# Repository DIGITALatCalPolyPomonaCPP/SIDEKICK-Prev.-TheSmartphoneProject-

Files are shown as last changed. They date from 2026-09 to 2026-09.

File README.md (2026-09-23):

# SIDEKICK — The Smartphone Project

**SIDEKICK, previously named TheSmartphoneProject, is DIGITAL @ Cal Poly Pomona's flagship systems-engineering project: a student-designed modular smartphone built around an FPGA-based computing platform.** It treats the phone as one integrated product spanning programmable logic, circuit design, embedded software, operating systems, sensing, user interaction, mechanical design, and thermal engineering.

<p align="center">
  <a href="https://photos.app.goo.gl/fKSVxjnxUvrLaF7E6">
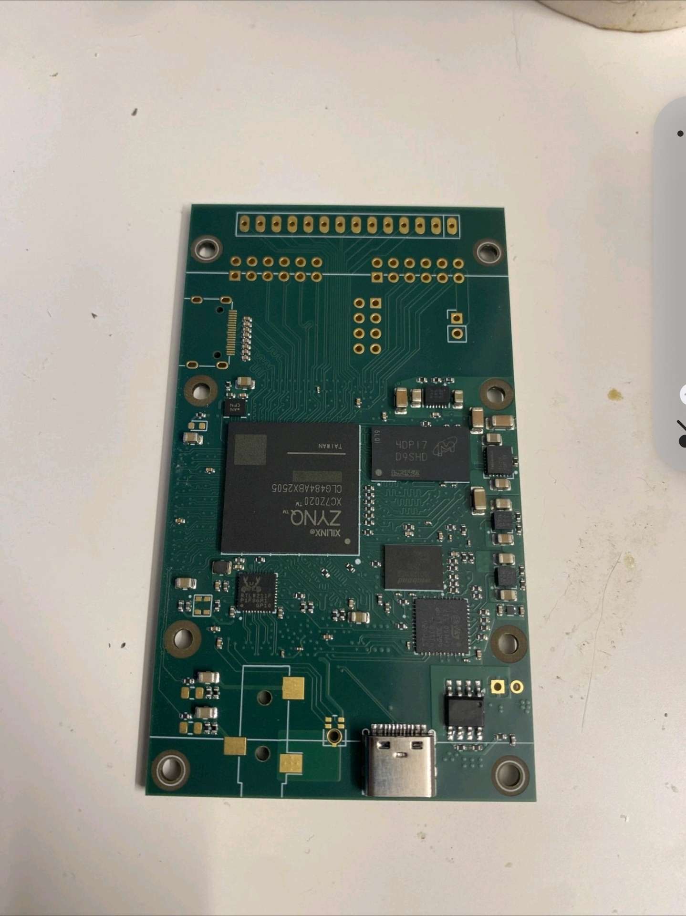
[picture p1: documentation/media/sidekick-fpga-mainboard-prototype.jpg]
SIDEKICK FPGA smartphone mainboard prototype
    
  </a>
</p>

<p align="center"><em>FPGA smartphone mainboard prototype. <a href="https://photos.app.goo.gl/fKSVxjnxUvrLaF7E6">View the project photo album.</a></em></p>

**Repository status:** This is an archival engineering snapshot. It consolidates original design files, subsystem iterations, planning documents, curricula, and project updates that were previously distributed across multiple repositories and contributor archives. It does not claim that every subsystem reached production readiness or that the files currently assemble into a finished phone.

## Executive summary

Technology has always evolved. What has changed is the pace at which innovation reshapes the world around us. Entire industries can now emerge, mature, and reinvent themselves within the span of a student's undergraduate education. Artificial intelligence is reshaping knowledge-based work, robotics is moving from laboratories into homes and industry, and manufacturing is becoming increasingly autonomous.

**The technologies that will define our students' careers have not all been invented yet.**

Industry has responded by becoming increasingly interdisciplinary. The products that define modern society are rarely conceived, developed, or delivered through engineering alone. They emerge from engineering, business, operations, manufacturing, research, and design working toward a common objective.

DIGITAL @ Cal Poly Pomona was created in response to this shift. It does not replace traditional engineering education or the student organizations that apply it through competitions, research, and hands-on work. DIGITAL bridges the space between them by organizing around the process through which ideas become projects. Members investigate unfamiliar problems, research existing solutions, define requirements, evaluate trade-offs, establish scope, build prototypes, test assumptions, document decisions, and communicate across disciplines.

Few products demonstrate the importance of this process more clearly than the smartphone. Its significance comes not simply from replacing the telephone, but from integrating computing, communications, embedded systems, software, industrial design, manufacturing, supply-chain logistics, product management, and business strategy at global scale. SIDEKICK turns that integration challenge into an educational platform: students can specialize in one subsystem while learning how their decisions affect the complete product.

The projects will change. The technologies will change. What remains constant is the framework through which students learn to transform ideas into reality. Ultimately, the true product of DIGITAL is not the prototype; it is the people who leave the organization prepared to help define what comes next.

## Project definition

The project aims to engineer a working, custom-built mobile-device prototype whose central processing and hardware-control functions are implemented with field-programmable logic. Inspired by modern mobile architecture and open-source hardware, the team uses tools including KiCad, SolidWorks, ANSYS, AMD Vivado, and OrCAD to expose parts of the system that are normally hidden inside closed silicon and proprietary product stacks.

The intended phone should be comfortable to hold, intuitive to navigate, responsive under real use, and efficient enough for sustained daily operation. Success is therefore broader than a booting circuit board: the project pairs user evaluation of ergonomics, navigation, and responsiveness with engineering measurements such as clock speed, bus bandwidth, screen-on time, battery discharge, component efficiency, data integrity, latency, and thermal behavior.

As an educational platform, the phone gives students a way to follow a complete system from physical circuits and programmable logic through hardware interfaces, drivers, the operating system, and the user experience. The objective is not only a device, but a reusable foundation for learning, experimentation, repairability, and later product iterations.

## Planned operational architecture

The system concept separates the FPGA motherboard from modular peripheral hardware. Custom logic moves device data through controller and buffering stages into an AXI-based system fabric, where software drivers expose it to the operating system and user interface.

```mermaid
flowchart LR
    A[Peripheral daughterboard<br/>sensors and actuators] --> B[Custom SPI and GPIO logic]
    B --> C[Hardware FIFO buffers]
    C --> D[AXI interconnect and<br/>memory-mapped registers]
    E[FPGA processing core<br/>and programmable logic] --> B
    E --> D
    D --> F[OS kernel and drivers]
    F --> G[Touch UI, telemetry,<br/>audio and haptic feedback]
```

Representative system flows include:

- **Boot and biometric unlock:** power-rail bring-up, FPGA bitstream loading, kernel and driver initialization, fingerprint transfer, authentication, haptic confirmation, and UI unlock.
- **Continuous sensor telemetry:** IMU, temperature, ambient-light, and microphone sampling; serial-to-parallel conversion; cross-clock FIFO buffering; AXI transfer; and UI updates.

The current systems plan treats a peripheral-to-memory latency below 15 ms, lossless sensor-packet handling at the target sampling load, and passive heat routing away from user touchpoints as design requirements. These are project targets documented in the planning workspace, not certifications of the archived hardware.

## Development approach

The project follows a systems-engineering cycle:

1. define the product, user experience, and measurable requirements;
2. decompose the phone into coordinated electrical, computing, software, mechanical, and thermal workstreams;
3. select components and tools, establish interfaces, and procure hardware;
4. design and prototype subsystems independently;
5. integrate through defined buses, connectors, drivers, and mechanical boundaries;
6. test electrical, performance, power, thermal, usability, and integration risks; and
7. evaluate readiness, document results, and carry lessons into the next iteration.

The public [TheSmartphoneProject workspace](https://successful-twill-84f.notion.site/TheSmartphoneProject-3e3169473d7780c18205ee25701566bf) contains the living planning record, including the product definition, requirements, work breakdown, use-case material, sequence diagrams, activity diagrams, team plans, and subsystem task tracking. Some linked workspace records may have separate access controls.

## System overview

| Subsystem | Scope | Contents |
| --- | --- | --- |
| [FPGA main board and peripheral board](subsystems/fpga-mainboard/) | Central Zynq/FPGA architecture, power, RF/transceiver, USB, connectors, display peripheral board | KiCad source, fabrication outputs, 3D renders, manufacturing notes |
| [Haptics](subsystems/haptics/) | Tactile-feedback motor-driver board | KiCad project archive |
| [Fingerprint sensor](subsystems/fingerprint-sensor/) | Fingerprint-sensor interface board | KiCad project archive |
| [Flashlight](subsystems/flashlight/) | LM3644-based flashlight/LED driver | KiCad revisions and symbol/footprint library |
| [Mechanical and thermal](subsystems/mechanical-thermal/) | Phone enclosure, frame, assembly, and thermal/mechanical exploration | STEP, STL, SolidWorks, PDF, and archived CAD models |
| [Ambient-light sensor](subsystems/ambient-light-sensor/) | VCNL4030X01-based sensing board and additional light-sensor iterations | KiCad project archives and STEP model |
| [IMU](subsystems/imu/) | ICM-20948 inertial-sensing board and supporting power/level shifting | Seven chronological KiCad project archives |
| [Real-time clock](subsystems/real-time-clock/) | RV-3028-C8-based RTC board | KiCad source, component library, renders, schematics, and prototype outputs |
| [STM32 controller](subsystems/stm32-controller/) | STM32G431-based control and support electronics | KiCad design, component models/libraries, and STM32CubeIDE firmware project |
| [Heat sensor](subsystems/heat-sensor/) | Temperature/heat-sensing circuit exploration | KiCad schematic project archive |

## Project documentation

The [`documentation/`](documentation/) directory preserves the project record alongside the subsystem engineering files. It includes Hatchery proposals and phase updates, DIGITAL curriculum and mini-project decks, the project budget and bill-of-materials workbook, and organizational records. These originals are grouped by purpose and accompanied by checksums and provenance notes.

## Repository organization

Each subsystem has:

- a short README explaining what is present;
- a `PROVENANCE.md` with the original repository, branch, imported commit, and contributors; and
- a `source/` directory containing an unchanged snapshot of the files tracked at that commit.

The snapshots intentionally retain original filenames, archive structure, and intermediate revisions. This avoids silently selecting a “final” design where the source repository did not designate one.

## Opening the design files

Most electronics work is stored as KiCad projects, either directly or inside ZIP archives. Mechanical work includes STEP, STL, SolidWorks (`.SLDPRT`), and PDF files. Some archives contain KiCad automatic backups in addition to the latest project files.

Treat all outputs as historical engineering artifacts. Review schematics, footprints, stackups, component availability, electrical rules, and manufacturing requirements before fabrication.

## Project history and attribution

The initial source material was maintained across seven repositories under individual contributors and the DIGITAL organization. Additional project archives supplied directly by the project maintainer are recorded separately, without inferring authorship or repository history. See [CONTRIBUTORS.md](CONTRIBUTORS.md) for the contributor index and each subsystem's `PROVENANCE.md` for source details.

No authorship is transferred by this consolidation. Original Git history remains available through the linked source repositories and the immutable commit identifiers recorded here.

## Licensing

Licensing is **per subsystem**, not repository-wide. The FPGA/main-board snapshot includes its original GNU GPL v3 license. No explicit license file was present in the other source repositories at the recorded commits. See [LICENSES.md](LICENSES.md) before reusing or redistributing any material.

## About DIGITAL @ Cal Poly Pomona

DIGITAL is intentionally broader than one device, competition, technology, or discipline. Each initiative follows a shared project lifecycle: assess purpose and feasibility; define scope, requirements, risks, roles, and resources; execute and integrate through clear interfaces; document decisions continuously; and conclude with reflection, knowledge transfer, and a deliberate decision about what follows.

Systems engineering is the organization's foundation. It connects the complete product architecture with the technical and operational teams needed to deliver it, while allowing members to develop depth in hardware, software, mechanical design, thermal engineering, product design, business, or operations. SIDEKICK is DIGITAL's flagship reference implementation—not its fixed endpoint—and provides a concrete system through which this model can be tested and improved.

DIGITAL measures success beyond commercial readiness. Clear design decisions, robust interfaces, useful documentation, transferable skills, and member growth are outcomes in their own right. Read the archived [DIGITAL project proposal for Maximizing Engineering Potential](documentation/organization/DIGITAL_CPP_Project_Proposal_MEP.docx) for the organization's mission, values, project lifecycle, and structure.

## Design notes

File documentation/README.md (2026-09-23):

# Project documentation

This directory preserves original planning, teaching, financial, and organizational records supplied by project maintainer Russell Chung. The files are stored unchanged; descriptions below are an index, not a revision of the source material.

| Collection | Contents |
| --- | --- |
| [Proposals](proposals/) | Phase I interview/application notes and the 13-page Learn Through Discovery Projects Hatchery proposal |
| [Project updates](project-updates/) | Phase II planning and budget presentation; Phase III hardware and thermals/enclosure updates |
| [Curriculum and mini-projects](curriculum/) | Operating-systems and SoC teaching decks; thermometer and fingerprint-sensor mini-projects |
| [Financials](financials/) | Budget planning, submitted/final proposals, purchase planning, and PCB/system BOM worksheets |
| [Organization](organization/) | DIGITAL project proposal for MEP and constitution/bylaws |
| [Media](media/) | Project photographs used in the repository overview and the external project album |

Each collection includes a `PROVENANCE.md` and `SHA256SUMS` file. The same Hatchery PDF supplied again on 2026-09-23 matched the existing archived copy byte-for-byte and was not duplicated. Two supplied MEP proposal files had identical document content and differed only in Office metadata; the canonical filename is retained once and both source filenames are recorded.

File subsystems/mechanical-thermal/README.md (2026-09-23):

# Mechanical and thermal design

This subsystem records enclosure, frame, assembly, and thermal/mechanical exploration. The snapshot includes:

- STEP phone assembly, front case, and back-cover models in the Izaiah Ortiz archive;
- a SolidWorks enclosure part and PDF design documentation attributed by filename to Logan;
- an STL phone-frame design attributed by filename to Russell; and
- the original repository README.

See [PROVENANCE.md](PROVENANCE.md) for repository-level contributors, origin, and licensing status.

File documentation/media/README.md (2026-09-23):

# Project media

## FPGA smartphone mainboard prototype

`sidekick-fpga-mainboard-prototype.jpg` shows the populated FPGA smartphone mainboard prototype, including the Xilinx Zynq device, memory, support components, mounting points, headers, and USB-C connector.

- Original filename: `Screenshot_20260318_143449_LinkedIn.jpg`
- Supplied by: Russell Chung
- Added to consolidation: 2026-09-23
- Stored unchanged from the supplied JPEG
- Explicit license statement: none supplied
- [Project photo album](https://photos.app.goo.gl/fKSVxjnxUvrLaF7E6)

The photo is used near the top of the repository README to connect the engineering archive to the physical prototype.

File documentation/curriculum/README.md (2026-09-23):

# Curriculum and mini-projects

This collection connects the Smartphone Project to DIGITAL's teaching program.

- **Operating Systems Curriculum** (147 slides): memory and virtualization, virtual machines, compiler construction, and operating-system services.
- **The SoC Curriculum — Meeting #1: Abstraction** (17 slides): abstraction, interfaces and implementations, Boolean logic/algebra, logic gates, HDL, and chips/modules.
- **Thermometer Mini-Project** (10 slides): requirements, interface choice, MCP9600 thermocouple interface, and daughterboard design. The title slide credits Russell Chung, Pyson, and Ethan Wong.
- **Fingerprint Sensor Mini-Project** (11 slides): sensor technology and component-selection matrices, FPC2532AP requirements, schematic/footprint work, and daughterboard integration. The title slide credits Anish, Russell, Logan, and Ethan.

The original PowerPoint files are preserved unchanged. See [PROVENANCE.md](PROVENANCE.md) and [SHA256SUMS](SHA256SUMS).

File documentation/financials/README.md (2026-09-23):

# Budget and financial records

`Budget and Financials .xlsx` is an eight-sheet working workbook that preserves:

- equipment and workshop purchase planning;
- submitted, final, and brainstorming Hatchery budgets;
- a PCB bill of materials;
- a combined project bill of materials;
- purchase tracking; and
- the main-board bill of materials.

The workbook includes formulas in its budget sheets and is retained unchanged as a historical planning record. It should not be treated as a current quote or purchasing authorization.

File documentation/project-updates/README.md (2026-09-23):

# Smartphone Project updates

These presentations document the transition from Phase II planning into Phase III subsystem development.

- **Phase II — SMART, Budget, Gantt and Plans for Phase III** (14 slides): goals, integrated schedule, three-milestone budget, team structure, and seven project milestones.
- **Phase III — Hardware Design Project Update 1** (14 slides): motherboard/System-on-Module, haptics, RTC, microphone, heat sensor, STM32 controller, fingerprint sensor, thermometer/barometer, and camera work.
- **Phase III — Thermals & Enclosure Project Update 1** (11 slides): thermal and enclosure constraints, copper-plate heat-spreading approach, three enclosure iterations, and future design plans.

The original PowerPoint files are preserved unchanged. See [PROVENANCE.md](PROVENANCE.md) and [SHA256SUMS](SHA256SUMS).

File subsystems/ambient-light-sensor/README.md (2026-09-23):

# Ambient-light sensor

The repository-derived source snapshot contains a KiCad design archive for a VCNL4030X01-based light-sensor board. The archive includes schematic and PCB files, a custom footprint, a STEP model, and chronological KiCad backups.

`source/additional-snapshots/` contains four separately supplied KiCad light-sensor snapshots dated in their filenames from January 22 through February 5, 2026. They are retained as distinct archives so no revision is overwritten or silently selected as final.

See [PROVENANCE.md](PROVENANCE.md) for origin and licensing status.

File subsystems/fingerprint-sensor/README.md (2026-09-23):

# Fingerprint sensor

The source snapshot contains a KiCad archive for the phone's fingerprint-sensor interface board, including schematic, PCB, project, and backup files.

See [PROVENANCE.md](PROVENANCE.md) for origin and licensing status.

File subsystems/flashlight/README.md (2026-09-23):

# Flashlight driver

The source snapshot contains two KiCad revisions of a flashlight/LED driver plus a KiCad symbol and footprint library for the LM3644 in the YFF package.

See [PROVENANCE.md](PROVENANCE.md) for origin and licensing status.

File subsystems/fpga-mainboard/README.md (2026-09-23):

# FPGA main board and peripheral board

This subsystem contains the central FPGA-based phone hardware from the original SIDEKICK repository.

- `source/hardware/` contains the Zynq/FPGA main-board KiCad design, including power management, processing-system and programmable-logic configuration, DDR, RF/transceiver, USB, and board-to-board connector sheets.
- `source/hardware/gerber/` contains fabrication outputs and manufacturing requirements.
- `source/Peripheral-Board-master/` contains the display/peripheral-board KiCad design, component models, libraries, and chronological backups.
- `source/repo_desc/` contains board renders, copper-layer images, and a schematic PDF.

The source snapshot retains its original [GNU GPL v3 license](source/LICENSE). See [PROVENANCE.md](PROVENANCE.md) for the exact origin.

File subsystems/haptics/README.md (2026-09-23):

# Haptics

The source snapshot contains a KiCad archive for a haptic motor-driver board. The archive includes schematic, PCB, project, and chronological backup files.

See [PROVENANCE.md](PROVENANCE.md) for origin and licensing status.

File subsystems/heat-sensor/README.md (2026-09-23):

# Heat sensor

This subsystem contains a supplied KiCad schematic-project archive for a heat-sensing circuit. The archive contains `.kicad_sch`, `.kicad_pro`, and `.kicad_prl` files; no PCB file is present in this snapshot.

The original archive filename is preserved exactly. Its numeric tokens are treated as source metadata and are not interpreted as validated dates or times.

See [PROVENANCE.md](PROVENANCE.md) for source and licensing status.

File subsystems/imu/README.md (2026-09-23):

# Inertial measurement unit (IMU)

The source snapshot contains seven chronological KiCad archives for an ICM-20948-based IMU board. Later revisions add dedicated power-supply and level-shifting schematic sheets alongside the main schematic and PCB.

All seven revisions are retained because the source repository presents them as design history and does not explicitly label a production-ready release.

See [PROVENANCE.md](PROVENANCE.md) for origin and licensing status.

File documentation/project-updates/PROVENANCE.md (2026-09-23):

# Project-update provenance

- Supplied by: Russell Chung
- Added to consolidation: 2026-09-23
- Original repository or publication URLs: not supplied
- Explicit license statements: none found

All three PowerPoint files are stored unchanged. Their slide packages were inspected and every slide rendered successfully for visual verification: 14 slides in the Phase II deck, 14 slides in the Phase III hardware deck, and 11 slides in the Phase III thermals/enclosure deck.

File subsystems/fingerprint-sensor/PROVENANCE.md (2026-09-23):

# Provenance

- Original repository: <https://github.com/anishc-AC/Fingerprint-Sensor-Digital-CPP>
- Branch: `main`
- Imported commit: [`4a961568353dbc8fffba0a523c04a494d1507fb6`](https://github.com/anishc-AC/Fingerprint-Sensor-Digital-CPP/commit/4a961568353dbc8fffba0a523c04a494d1507fb6)
- Snapshot date: 2026-09-23
- Commit contributor through this revision: [Anish Chinnakonda / anishc-AC](https://github.com/anishc-AC)
- License found in source: none

Files under `source/` are an unchanged snapshot of the files tracked at the commit above.

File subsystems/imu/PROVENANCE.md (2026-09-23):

# Provenance

- Original repository: <https://github.com/DIGITALatCalPolyPomonaCPP/IMU>
- Branch: `main`
- Imported commit: [`13fa9f7d65ca35fa4ca0e97b7501c86d454a1184`](https://github.com/DIGITALatCalPolyPomonaCPP/IMU/commit/13fa9f7d65ca35fa4ca0e97b7501c86d454a1184)
- Snapshot date: 2026-09-23
- Commit contributors through this revision: [masontran44](https://github.com/masontran44) and [DIGITAL at Cal Poly Pomona](https://github.com/DIGITALatCalPolyPomonaCPP)
- License found in source: none

Files under `source/` are an unchanged snapshot of the files tracked at the commit above.

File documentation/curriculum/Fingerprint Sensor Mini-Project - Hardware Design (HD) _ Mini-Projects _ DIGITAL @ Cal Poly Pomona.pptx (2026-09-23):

## Fingerprint Sensor Mini-Project

By Anish, Russell, Logan, Ethan

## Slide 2

FINGERPRINT SENSOR

Defining Requirements, Interface, Implementation, Board Design

## Project Definition & Project Motivation

Project Definition
- Consumer Need: Fast, secure, and user-friendly authentication → convenience and privacy
- Feature: Allow users to unlock the device and verify their identity with a single touch
- Purpose: Personal, Modern, and Secure

Project Motivation
- Project Purpose: Learn how to implement SPI and I²C communication protocols on a daughterboard
- Projected Takeaways: Learn Research Process, Project Definition, Project Requirements, Decision Matrix, Part Selection, Reading Datasheet, PCB Schematic Design, PCB Editor Design, and Documentation

## What Type of Fingerprint Sensor Should We Use?

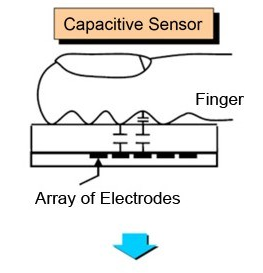
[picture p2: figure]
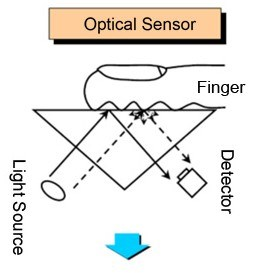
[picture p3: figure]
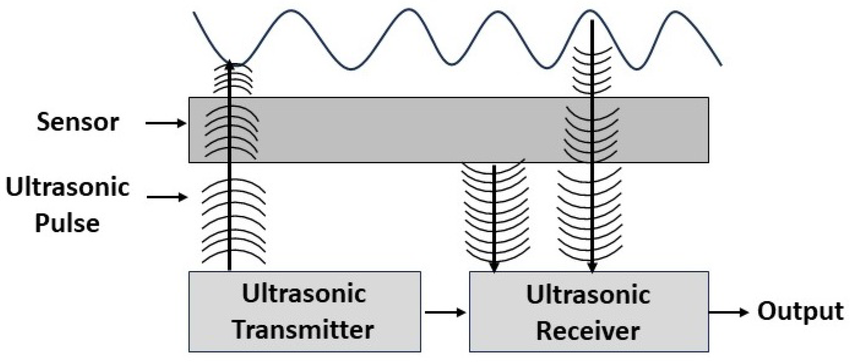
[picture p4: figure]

Capacitive

- Array of tiny capacitors
- Detects the valleys and ridges of the fingerprint
  - Measurement of difference in electrical charge.
- 2D data map of the fingerprint

Optical

- Camera system or photodiode array
- Captures an image of fingerprint
- Requires a light source
- Most physical space of the three

Ultrasonic

- Emits ultrasonic sound waves
- Penetrates the outer layer of fingerprint and bounces back
- Time component
  - Detailed 3D map of the fingerprint

## What Type of Fingerprint Sensor Should We Use?

Type | Capacitive | Optical | Ultrasonic
Pros | High Accuracy Quick Smallest form factor Cost effective Low Power Consumption | Simple and easy to implement Relatively Cost Effective | Secure due to 3D detail Resistance to dirt and liquids Suitable for under screen use
Cons | Finger must be clean and dry Not suitable for under screen use | Bulky Susceptible to spoofing/Low security High power consumption | Expensive Medium power consumption Challenging integration

Our Choice:

In the end we decided to use a capacitive fingerprint sensor because of their cost effectiveness, good accuracy, small form factor, and easy implementation relative to the other types.

## Fingerprint Sensor Type Selection Process

Type | Price (2) [1.3x] | Complexity (1) [1.5x] | Size (5) [1.0x] | Accuracy (3) [1.2x] | Effectiveness (4) [1.1x] | Power (6) [0.9x] | Total
Capacitive | 8 | 9 | 10 | 7 | 3 | 8 | 52.8
Optical | 5 | 7 | 3 | 4 | 5 | 6 | 35.7
Ultrasonic | 4 | 2 | 7 | 9 | 8 | 3 | 37.5

## Fingerprint Sensor Selection Process

Sensor | Protocol | Complexity | Accuracy | Power Consumption | Pixel Size | Sensor Area | Special Features | Total Score
FPC1030 | LVDS | 3 | 6 | 9 | 6 | 9 | Swipe, Ultra-low power, >15kV ESD | 42
FPC2532AP | I2C, SPI, UART, USB | 7 | 8 | 7 | 7 | 7 | IP67 water/dust, deep sleep/wake, onboard encryption | 51
FPC1020 | SPI | 8 | 9 | 8 | 9 | 6 | 508 dpi, durable coating, IP-rating, fast touch sensing | 49
FPC1020 CMOS | UART | 6 | 7 | 7 | 8 | 6 | Simple serial interface, good for embedded security use | 41

## Sensor Selection Process (FPC2532AP)

- Common Sensor Specifications
  - 3.0 - 3.6V operating voltage
  - 17 - 21 mA operating current
  - 100x96 pixels, 508 dpi
  - Ø 11 mm × 0.83 mm thickness
- FPC2530 Specifications
  - $25.30 (Digikey)
  - SPI up to 10 MHz
  - I²C up to 400kbit/s
  - Fast response: 150ms boot, 0.5 ms wake-from-sleep, 130ms capture time
  - 22µA sleep-mode current
  - IP67 dust and water resistant

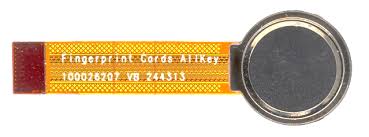
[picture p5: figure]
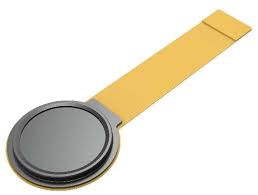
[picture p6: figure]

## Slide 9

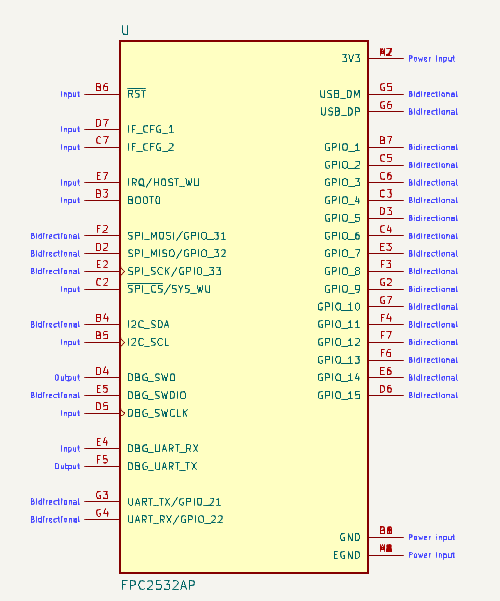
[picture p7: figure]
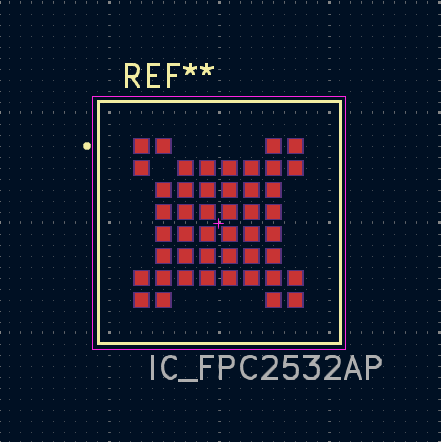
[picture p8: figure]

## Our Requirements

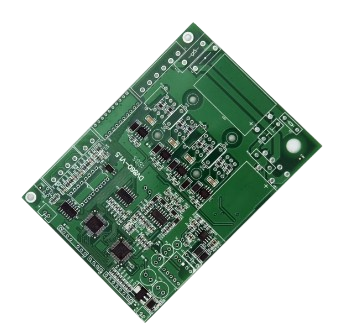
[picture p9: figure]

- Pressure Range
  - 1009.1438226666767 hPa - 1022.6893773333434 hPa (inside)
  - 300–1100 hPa to handle all GPS- and altitude-related application (outside)
- Accuracy: ± 1.0 hPa and ± 0.5°C
- Interface of Choice: I²C
  - Analog
    - Transmits continuous voltage signals that directly represent a physical quantity, such as temperature or light intensity. Analog sensors output a voltage proportional to the measured value, which the receiving system interprets through an analog-to-digital converter (ADC). This method uses one wire per sensor signal and requires careful calibration due to noise and voltage scaling.
  - SPI
    - Transfers data between a single master and one or more slave devices using four wires: serial clock (SCLK), master-out-slave-in (MOSI), master-in-slave-out (MISO), and chip select (CS). SPI is a high-speed, full-duplex protocol ideal for fast communication with peripherals like sensors, displays, or memory chips. Each slave device needs its own CS line.
  - I²C
    - Transfer data between a master (or multiple masters) and a single slave (or multiple slaves) device. It is a bidirectional two-wire serial bus that uses serial clock (SCL) and serial data (SDA) wires to send and manage data bit by bit between devices connected to the bus.
  - UART
    - Transfers data between two devices over two wires (TX for transmit, RX for receive) without needing a clock signal. UART uses start and stop bits to frame each data byte and requires both devices to agree on a communication speed (baud rate). It supports full-duplex communication but is limited to point-to-point connections (one-to-one).
- Power Supply: 3.3V
- Form Factor: Compact, aligns with daughterboard header

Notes: ✅ Why We Chose I²C for the Thermometer Module
1. 🧩 Multiple Sensors on One Bus
Your system includes more than one sensor (e.g., thermometer + barometer).

I²C supports multiple devices on the same two wires—each with a unique address.

This simplifies wiring and PCB routing, especially on a stacked daughterboard.

2. 🧠 Digital Accuracy and Stability
I²C transmits digital data, which means:

Higher precision and accuracy than analog voltage

No need for ADCs (analog-to-digital converters)

Less prone to signal noise or voltage drift

3. ⚡ Low Pin Count
Uses only 2 signal lines: SDA (data) and SCL (clock)

Saves pins on your MCU/FPGA and keeps the design compact

4. 🔌 Wide Sensor Ecosystem
Industry-standard for sensors like:

MCP9600 (thermocouple interface)

BMP581 (barometer)

TMP102, MCP9808, etc.

Readily supported in firmware libraries (Arduino, Python, Zephyr, Verilog wrappers)

5. 💻 Easier Firmware and Expansion
Works well with FPGA softcores or embedded MCUs

Easy to poll, scan, and expand with future sensors (e.g., accelerometer, humidity)

🚫 Why We Didn’t Use the Others:
Interface Reason Rejected
Analog Needs ADC, less accurate, more noise-sensitive
SPI More wires (4+), overkill for thermometer’s data rate
UART Point-to-point only, not scalable for multi-sensor bus

✅ TL;DR:
I²C was chosen because it’s simple, scalable, accurate, and already supported by the MCP9600. It also allows us to easily integrate other sensors (like the BMP581 barometer) on the same bus with minimal wiring and code complexity.

## Sources

Notion:
https://www.notion.so/Thermometer-21e169473d778007bf46e3cce8d5c230?source=copy_link
Datasheet:
https://s3.amazonaws.com/snapeda/datasheet/MCP9600-E/MX_Microchip.pdf
https://www.notion.so/Recorded-Meetings-23a169473d7780039354ecdf9b171754?source=copy_link

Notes: Absolutely! Here's a full explanation of each MCP9600 pin, written as speaker notes for use in your presentation—so you can explain them confidently without overwhelming the slide content.

🔌 3.1 Ground Pin (GND)
Speaker Notes:
These pins are the electrical ground reference for the entire chip. Pins 1, 3, 5, 13, and 17 are internally connected and sit at the same potential—any of them can be used as GND. However, pins 6, 7, 9, 10, and 18 must also be tied to ground externally for the MCP9600 to operate correctly. Think of this as ensuring stable and balanced grounding across the chip’s internal analog and digital subsystems.

🌡 3.2 Thermocouple Inputs (VIN+, VIN–)
Speaker Notes:
This is where the actual thermocouple wires connect. The positive wire goes to VIN+ and the negative to VIN–. The thermocouple generates a tiny voltage based on the temperature difference between its sensing end and the chip itself. The MCP9600 amplifies this signal, applies cold junction compensation (based on its own internal temperature sensor), and converts the result to °C digitally. This is the chip’s core sensing input.

⚡ 3.3 Power Pin (VDD)
Speaker Notes:
This is the main power supply pin for the chip. It typically operates at 3.3V (or up to 5V depending on your design). Make sure to supply clean, regulated voltage here—this powers everything, from the internal temperature compensation engine to the I²C communication interface. If this pin isn’t stable, you’ll likely get incorrect readings or communication failures.

🚨 3.4 Alert Outputs (Alert 1–4)
Speaker Notes:
These are optional programmable outputs that act like alarm pins. You can configure them via I²C to trigger if the temperature exceeds a certain threshold—or drops below it. They're “push-pull” style digital outputs, meaning they can drive high and low levels directly. You could connect them to an LED, a fan controller, or use them as interrupts to your MCU to take real-time action when overheating is detected.

🧠 3.5 I²C Address Pin (ADDR)
Speaker Notes:
This pin sets the chip’s I²C address so the host MCU or FPGA can uniquely identify and talk to it on the bus. You can tie it directly to GND, VDD, or connect it through a resistor divider to generate up to 8 distinct address levels. This is important when you’re using multiple MCP9600s on the same I²C bus—you’ll need each one to have a unique address.

⏱ 3.6 Serial Clock Line (SCL)
Speaker Notes:
This is the clock line used for I²C communication. It’s driven by the host controller (like an MCU or FPGA). All timing for sending and receiving data is based on this clock signal. The MCP9600 is an I²C slave—it listens to the host and responds only when it's addressed.

🔁 3.7 Serial Data Line (SDA)
Speaker Notes:
This is the bidirectional data line for I²C. Data is sent and received bit by bit along this line. The SDA and SCL lines must both have pull-up resistors (typically 4.7kΩ) for the I²C bus to function. The MCP9600 responds on SDA only when it’s addressed by the host and only during read/write cycles.

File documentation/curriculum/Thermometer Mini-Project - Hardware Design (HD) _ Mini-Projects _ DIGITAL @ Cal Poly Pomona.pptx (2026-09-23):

## Thermometer Mini-Project

By Russell Chung, Pyson, and Ethan Wong

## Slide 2

THERMOMETER

Defining Requirements, Interface, Implementation, Board Design

## Defining Our Requirements

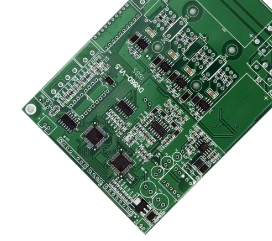
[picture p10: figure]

1. Assignment
  a. Designing a Thermometer Daughterboard That Can Be Implemented in the Phone
2. Defined Objective
  a. Designing a Thermometer Daughterboard to:
    i. Detect fevers
    ii. Sense outdoor ambient temperature
    iii. Measure steak surface temperature (idea is we could estimate the Internal Temperature)
3. System Context
  a. Part of a modular sensor daughterboard integrated with our FPGA-based SoC smartphone prototype
  b. Work within the same system as a Barometer

## Our Requirements


- Temperature Range: –25°C to 250°C
- Accuracy: ±0.2°C (for medical-grade Fever detection)
- Interface of Choice: I²C
  - Analog
    - Transmits continuous voltage signals that directly represent a physical quantity, such as temperature or light intensity. Analog sensors output a voltage proportional to the measured value, which the receiving system interprets through an analog-to-digital converter (ADC). This method uses one wire per sensor signal and requires careful calibration due to noise and voltage scaling.
  - SPI
    - Transfers data between a single master and one or more slave devices using four wires: serial clock (SCLK), master-out-slave-in (MOSI), master-in-slave-out (MISO), and chip select (CS). SPI is a high-speed, full-duplex protocol ideal for fast communication with peripherals like sensors, displays, or memory chips. Each slave device needs its own CS line.
  - I²C
    - Transfer data between a master (or multiple masters) and a single slave (or multiple slaves) device. It is a bidirectional two-wire serial bus that uses serial clock (SCL) and serial data (SDA) wires to send and manage data bit by bit between devices connected to the bus.
  - UART
    - Transfers data between two devices over two wires (TX for transmit, RX for receive) without needing a clock signal. UART uses start and stop bits to frame each data byte and requires both devices to agree on a communication speed (baud rate). It supports full-duplex communication but is limited to point-to-point connections (one-to-one).
- Power Supply: 3.3V
- Form Factor: Compact, aligns with daughterboard header

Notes: ✅ Why We Chose I²C for the Thermometer Module
1. 🧩 Multiple Sensors on One Bus
Your system includes more than one sensor (e.g., thermometer + barometer).

I²C supports multiple devices on the same two wires—each with a unique address.

This simplifies wiring and PCB routing, especially on a stacked daughterboard.

2. 🧠 Digital Accuracy and Stability
I²C transmits digital data, which means:

Higher precision and accuracy than analog voltage

No need for ADCs (analog-to-digital converters)

Less prone to signal noise or voltage drift

3. ⚡ Low Pin Count
Uses only 2 signal lines: SDA (data) and SCL (clock)

Saves pins on your MCU/FPGA and keeps the design compact

4. 🔌 Wide Sensor Ecosystem
Industry-standard for sensors like:

MCP9600 (thermocouple interface)

BMP581 (barometer)

TMP102, MCP9808, etc.

Readily supported in firmware libraries (Arduino, Python, Zephyr, Verilog wrappers)

5. 💻 Easier Firmware and Expansion
Works well with FPGA softcores or embedded MCUs

Easy to poll, scan, and expand with future sensors (e.g., accelerometer, humidity)

🚫 Why We Didn’t Use the Others:
Interface Reason Rejected
Analog Needs ADC, less accurate, more noise-sensitive
SPI More wires (4+), overkill for thermometer’s data rate
UART Point-to-point only, not scalable for multi-sensor bus

✅ TL;DR:
I²C was chosen because it’s simple, scalable, accurate, and already supported by the MCP9600. It also allows us to easily integrate other sensors (like the BMP581 barometer) on the same bus with minimal wiring and code complexity.

## Sensor Selection Process

- Understanding the Limitations of the Interface We Chose (I²C)
  - I²C has addresses, so when there are multiple sensors from the same manufacturer, a lot of times there is an overlap causing conflicting data because data from both sensors gets sent on the same bus to SoC at the same time
    - Our Solution For This was to Use a Thermocouple
- We probably should have made a decision matrix which is a big no-no (don;t do what we did)
  - However, the IC chip that we decided to use was the MCP9600T-E/MX
- What is an IC chip?
  - The MCP9600 is an interface IC that lets a microcontroller read temperature from a thermocouple by converting its tiny voltage into precise, digital temperature data—communicated via I²C.
    - Reads a Thermocouple
    - Does Math Conversion/Logic
    - Communicates with Microcontroller or FPGA

## Thermocouple IC Pinout

- MCP9600T-E/MX
  - Ground Pin (GND) - System Ground; required for operation
  - Voltage at the Drain (VDD) - VDD is the power pin. The operating voltage range, as specified in the DC Characteristics table, is applied on this pin.
  - Thermocouple Input (Vin + and Vin -) - Connect thermocouple; measures voltage
  - Alert Outputs (Alert 1–4): Temperature-triggered digital alerts
  - I²C Address Pin (ADDR) - Sets I²C address level
  - Serial Clock Line (SCL) - I²C Clock input from master
  - Serial Data Line (SDA) - I²C bidirectional data line

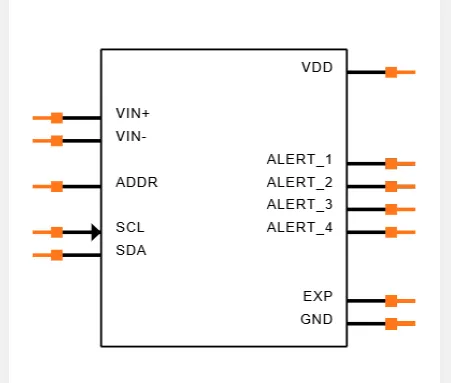
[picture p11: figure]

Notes: Absolutely! Here's a full explanation of each MCP9600 pin, written as speaker notes for use in your presentation—so you can explain them confidently without overwhelming the slide content.

🔌 3.1 Ground Pin (GND)
Speaker Notes:
These pins are the electrical ground reference for the entire chip. Pins 1, 3, 5, 13, and 17 are internally connected and sit at the same potential—any of them can be used as GND. However, pins 6, 7, 9, 10, and 18 must also be tied to ground externally for the MCP9600 to operate correctly. Think of this as ensuring stable and balanced grounding across the chip’s internal analog and digital subsystems.

🌡 3.2 Thermocouple Inputs (VIN+, VIN–)
Speaker Notes:
This is where the actual thermocouple wires connect. The positive wire goes to VIN+ and the negative to VIN–. The thermocouple generates a tiny voltage based on the temperature difference between its sensing end and the chip itself. The MCP9600 amplifies this signal, applies cold junction compensation (based on its own internal temperature sensor), and converts the result to °C digitally. This is the chip’s core sensing input.

⚡ 3.3 Power Pin (VDD)
Speaker Notes:
This is the main power supply pin for the chip. It typically operates at 3.3V (or up to 5V depending on your design). Make sure to supply clean, regulated voltage here—this powers everything, from the internal temperature compensation engine to the I²C communication interface. If this pin isn’t stable, you’ll likely get incorrect readings or communication failures.

🚨 3.4 Alert Outputs (Alert 1–4)
Speaker Notes:
These are optional programmable outputs that act like alarm pins. You can configure them via I²C to trigger if the temperature exceeds a certain threshold—or drops below it. They're “push-pull” style digital outputs, meaning they can drive high and low levels directly. You could connect them to an LED, a fan controller, or use them as interrupts to your MCU to take real-time action when overheating is detected.

🧠 3.5 I²C Address Pin (ADDR)
Speaker Notes:
This pin sets the chip’s I²C address so the host MCU or FPGA can uniquely identify and talk to it on the bus. You can tie it directly to GND, VDD, or connect it through a resistor divider to generate up to 8 distinct address levels. This is important when you’re using multiple MCP9600s on the same I²C bus—you’ll need each one to have a unique address.

⏱ 3.6 Serial Clock Line (SCL)
Speaker Notes:
This is the clock line used for I²C communication. It’s driven by the host controller (like an MCU or FPGA). All timing for sending and receiving data is based on this clock signal. The MCP9600 is an I²C slave—it listens to the host and responds only when it's addressed.

🔁 3.7 Serial Data Line (SDA)
Speaker Notes:
This is the bidirectional data line for I²C. Data is sent and received bit by bit along this line. The SDA and SCL lines must both have pull-up resistors (typically 4.7kΩ) for the I²C bus to function. The MCP9600 responds on SDA only when it’s addressed by the host and only during read/write cycles.

## Our Daughter Board Design

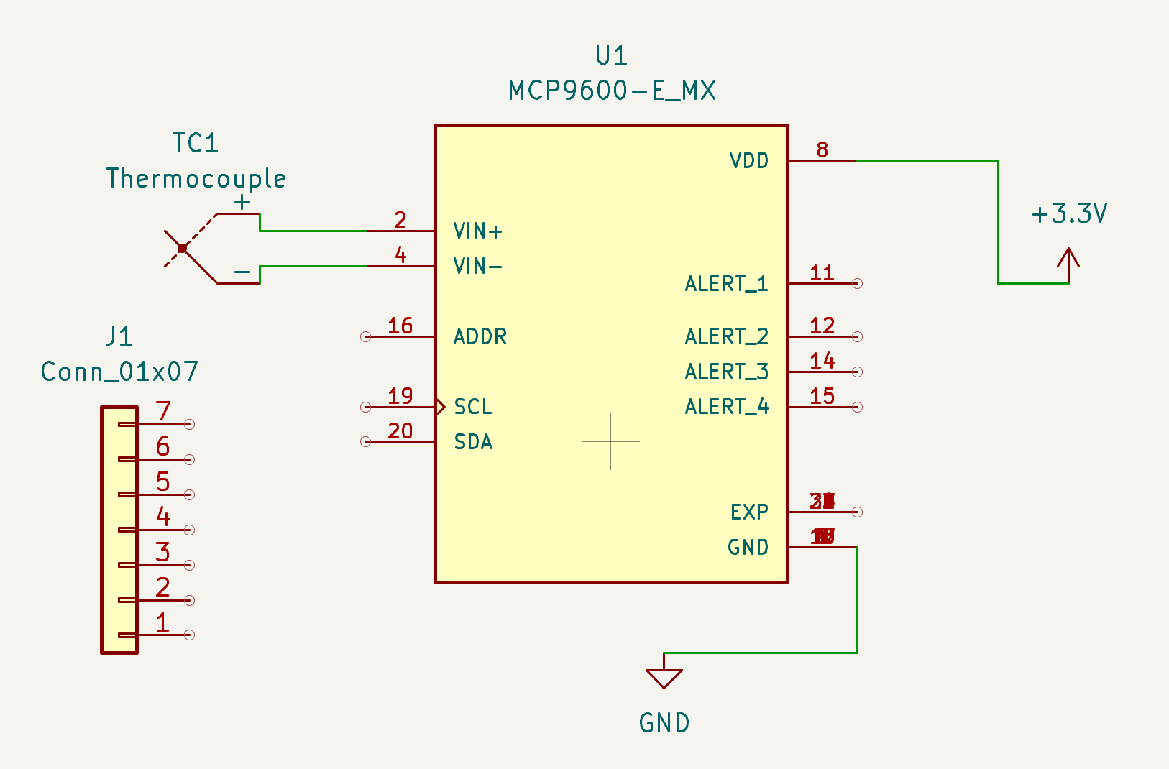
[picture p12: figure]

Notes: Absolutely! Here's a full explanation of each MCP9600 pin, written as speaker notes for use in your presentation—so you can explain them confidently without overwhelming the slide content.

🔌 3.1 Ground Pin (GND)
Speaker Notes:
These pins are the electrical ground reference for the entire chip. Pins 1, 3, 5, 13, and 17 are internally connected and sit at the same potential—any of them can be used as GND. However, pins 6, 7, 9, 10, and 18 must also be tied to ground externally for the MCP9600 to operate correctly. Think of this as ensuring stable and balanced grounding across the chip’s internal analog and digital subsystems.

🌡 3.2 Thermocouple Inputs (VIN+, VIN–)
Speaker Notes:
This is where the actual thermocouple wires connect. The positive wire goes to VIN+ and the negative to VIN–. The thermocouple generates a tiny voltage based on the temperature difference between its sensing end and the chip itself. The MCP9600 amplifies this signal, applies cold junction compensation (based on its own internal temperature sensor), and converts the result to °C digitally. This is the chip’s core sensing input.

⚡ 3.3 Power Pin (VDD)
Speaker Notes:
This is the main power supply pin for the chip. It typically operates at 3.3V (or up to 5V depending on your design). Make sure to supply clean, regulated voltage here—this powers everything, from the internal temperature compensation engine to the I²C communication interface. If this pin isn’t stable, you’ll likely get incorrect readings or communication failures.

🚨 3.4 Alert Outputs (Alert 1–4)
Speaker Notes:
These are optional programmable outputs that act like alarm pins. You can configure them via I²C to trigger if the temperature exceeds a certain threshold—or drops below it. They're “push-pull” style digital outputs, meaning they can drive high and low levels directly. You could connect them to an LED, a fan controller, or use them as interrupts to your MCU to take real-time action when overheating is detected.

🧠 3.5 I²C Address Pin (ADDR)
Speaker Notes:
This pin sets the chip’s I²C address so the host MCU or FPGA can uniquely identify and talk to it on the bus. You can tie it directly to GND, VDD, or connect it through a resistor divider to generate up to 8 distinct address levels. This is important when you’re using multiple MCP9600s on the same I²C bus—you’ll need each one to have a unique address.

⏱ 3.6 Serial Clock Line (SCL)
Speaker Notes:
This is the clock line used for I²C communication. It’s driven by the host controller (like an MCU or FPGA). All timing for sending and receiving data is based on this clock signal. The MCP9600 is an I²C slave—it listens to the host and responds only when it's addressed.

🔁 3.7 Serial Data Line (SDA)
Speaker Notes:
This is the bidirectional data line for I²C. Data is sent and received bit by bit along this line. The SDA and SCL lines must both have pull-up resistors (typically 4.7kΩ) for the I²C bus to function. The MCP9600 responds on SDA only when it’s addressed by the host and only during read/write cycles.

## How Our Thermometer Works

- Vin and Vout
  - Voltage In and Out in this IC circuit is not bidirectional, so what we can do here is take the difference in voltage
- V = IR and Rf = R₀(1 + αΔT)
  - Resistance is Directly Proportional to Voltage, so a Voltage Difference Can Be Used to Calculate Resistance
  - Temperature is Directly Proportional to Resistance, so a Resistance Difference Can Be Used to Calculate Temperature
- IC Chip Does The Calculations

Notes: Absolutely! Here's a full explanation of each MCP9600 pin, written as speaker notes for use in your presentation—so you can explain them confidently without overwhelming the slide content.

🔌 3.1 Ground Pin (GND)
Speaker Notes:
These pins are the electrical ground reference for the entire chip. Pins 1, 3, 5, 13, and 17 are internally connected and sit at the same potential—any of them can be used as GND. However, pins 6, 7, 9, 10, and 18 must also be tied to ground externally for the MCP9600 to operate correctly. Think of this as ensuring stable and balanced grounding across the chip’s internal analog and digital subsystems.

🌡 3.2 Thermocouple Inputs (VIN+, VIN–)
Speaker Notes:
This is where the actual thermocouple wires connect. The positive wire goes to VIN+ and the negative to VIN–. The thermocouple generates a tiny voltage based on the temperature difference between its sensing end and the chip itself. The MCP9600 amplifies this signal, applies cold junction compensation (based on its own internal temperature sensor), and converts the result to °C digitally. This is the chip’s core sensing input.

⚡ 3.3 Power Pin (VDD)
Speaker Notes:
This is the main power supply pin for the chip. It typically operates at 3.3V (or up to 5V depending on your design). Make sure to supply clean, regulated voltage here—this powers everything, from the internal temperature compensation engine to the I²C communication interface. If this pin isn’t stable, you’ll likely get incorrect readings or communication failures.

🚨 3.4 Alert Outputs (Alert 1–4)
Speaker Notes:
These are optional programmable outputs that act like alarm pins. You can configure them via I²C to trigger if the temperature exceeds a certain threshold—or drops below it. They're “push-pull” style digital outputs, meaning they can drive high and low levels directly. You could connect them to an LED, a fan controller, or use them as interrupts to your MCU to take real-time action when overheating is detected.

🧠 3.5 I²C Address Pin (ADDR)
Speaker Notes:
This pin sets the chip’s I²C address so the host MCU or FPGA can uniquely identify and talk to it on the bus. You can tie it directly to GND, VDD, or connect it through a resistor divider to generate up to 8 distinct address levels. This is important when you’re using multiple MCP9600s on the same I²C bus—you’ll need each one to have a unique address.

⏱ 3.6 Serial Clock Line (SCL)
Speaker Notes:
This is the clock line used for I²C communication. It’s driven by the host controller (like an MCU or FPGA). All timing for sending and receiving data is based on this clock signal. The MCP9600 is an I²C slave—it listens to the host and responds only when it's addressed.

🔁 3.7 Serial Data Line (SDA)
Speaker Notes:
This is the bidirectional data line for I²C. Data is sent and received bit by bit along this line. The SDA and SCL lines must both have pull-up resistors (typically 4.7kΩ) for the I²C bus to function. The MCP9600 responds on SDA only when it’s addressed by the host and only during read/write cycles.

## Our Daughter Board Design

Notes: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

## Sources

Notion:
https://www.notion.so/Thermometer-21e169473d778007bf46e3cce8d5c230?source=copy_link
Datasheet:
https://s3.amazonaws.com/snapeda/datasheet/MCP9600-E/MX_Microchip.pdf
https://www.notion.so/Recorded-Meetings-23a169473d7780039354ecdf9b171754?source=copy_link

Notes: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

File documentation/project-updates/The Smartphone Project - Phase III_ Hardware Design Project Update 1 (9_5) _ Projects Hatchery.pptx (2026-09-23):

## The Smartphone Project

Building a Smartphone From Scratch

## Short and Concise SMART Goals

- Build a fully functional smartphone
- Prove that learning to build a smartphone from scratch doesn’t have to be a mystery

M

A

R

T

S

## Disclaimer …Hardware Design Team

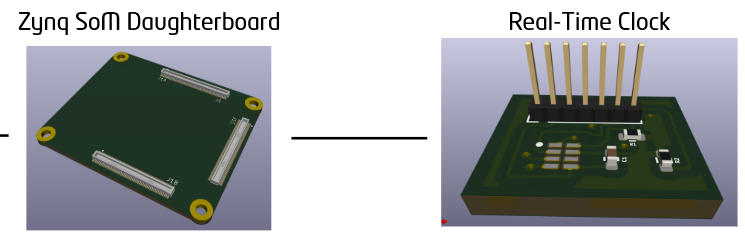
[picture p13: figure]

- We have multiple teams working on different aspects of the phone
  - For the sake of simplicity, we will keep this presentation for the…

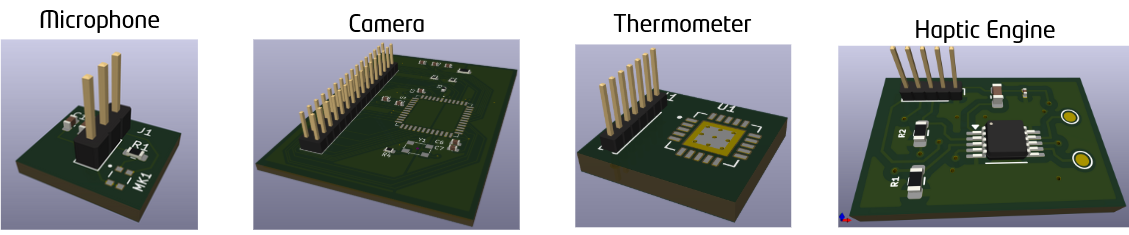
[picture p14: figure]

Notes: Programmable Hardware enables
Ability for the AVERAGE PERSON to easily repair of various elements in a PRODUCT WE OWN
Ability to easily assemble/disassemble ALLOWS you to upgrade your perfectly good phone by replacing only the components on the phone that YOU want improved on your phone
Ability to make a modular phone, which would allow
YOU to make your phone distinctly YOURS (not an identical slab to everyone else)
YOU to decide what are important features to you and

## Quick Look at the Hardware Projects

Haptic Motor Driver [PCB Layout]

Haptic Motor Driver

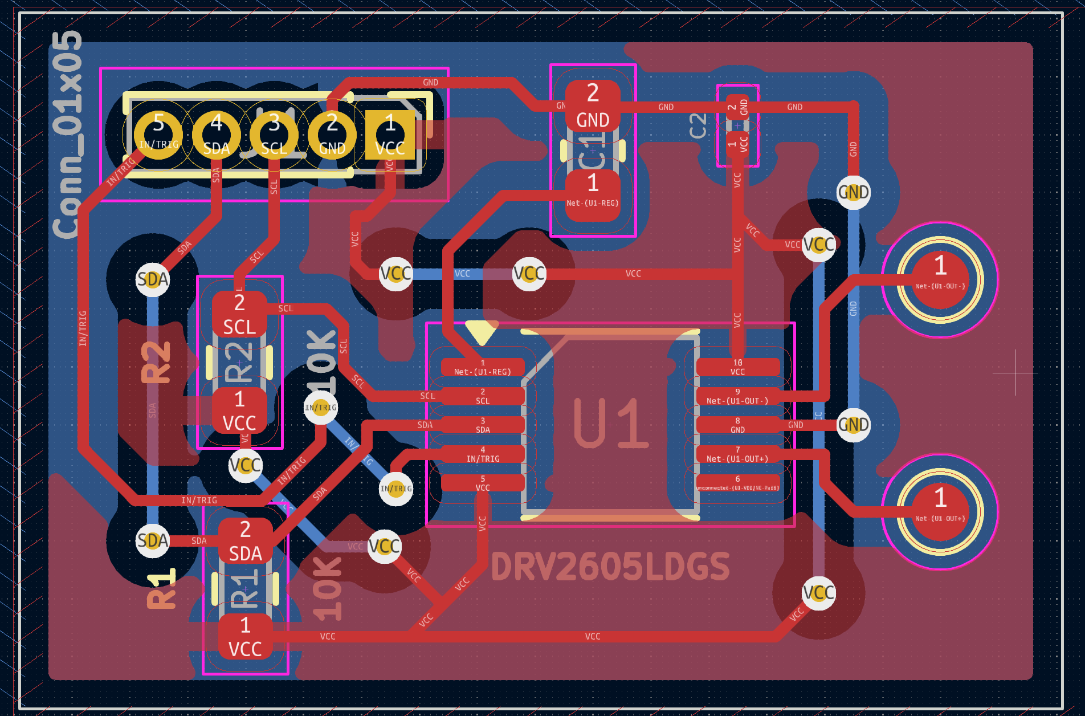
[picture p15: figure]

Haptic Motor Pads

Creates Controlled Vibrations

Real-Time Clock [3D Model]

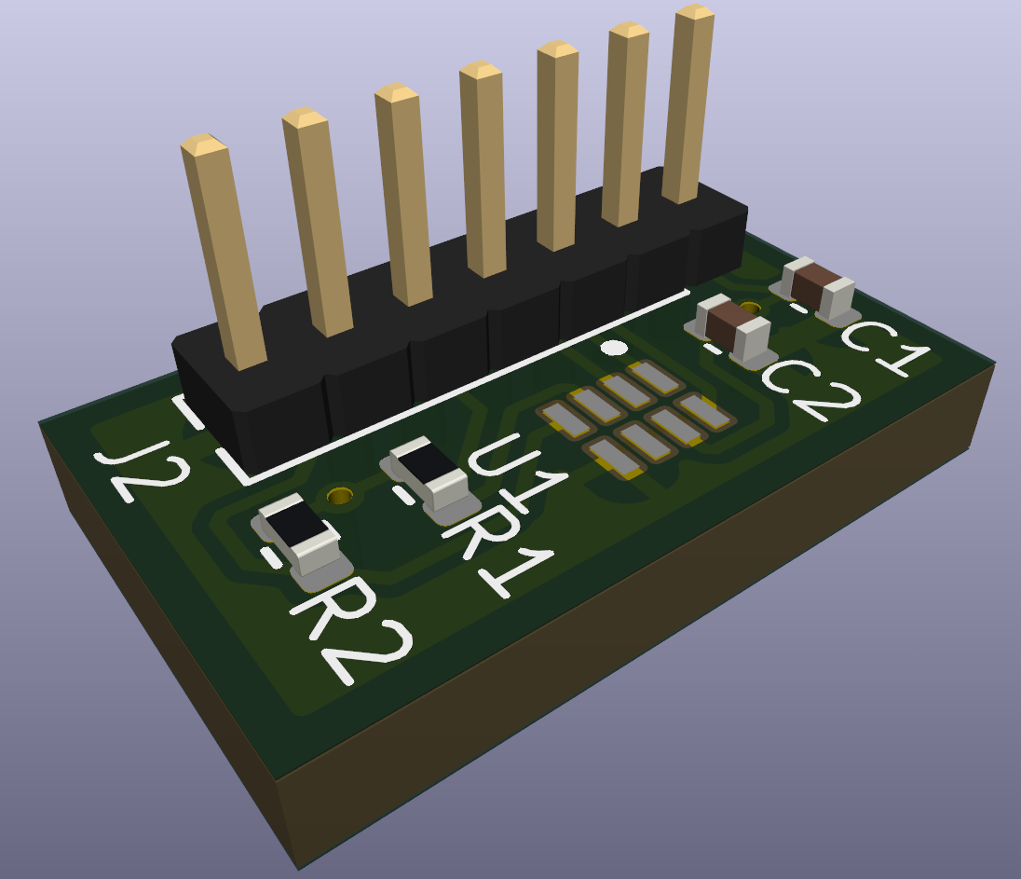
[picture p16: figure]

Real-Time Clock Pads

Keeps Track of Time

Microphone [3D Model]

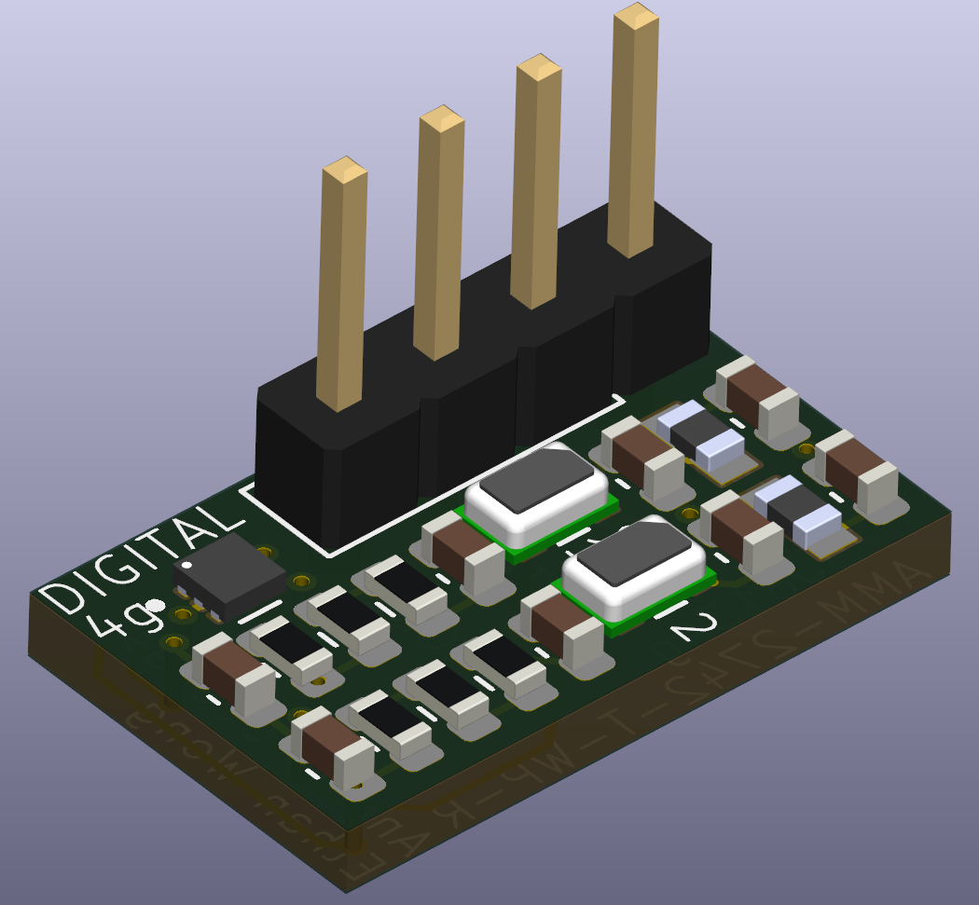
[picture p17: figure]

x2 Microphones

Captures Audio Input

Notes: Haptic Motor Driver
Haptic Motor Driver is necessary to control haptic motor vibration patterns
Haptic Motor works by converting electrical energy into mechanical vibrations
Communicates through I²C peripherals
Real-Time Clock
Real-Time Clock counts time by counting the pulses of a stable quartz crystal oscillator
Uses a battery backup to maintain power independently of main power system in case of power off
Communicates through I²C peripherals
Microphone
Microphone captures sound waves (analog) and converts them into electrical signals
Multiple microphones are used to overall reduce noise caused by individual noise
Communicates through I²C peripherals

## Quick Look at the Hardware Projects

Heat Sensor [3D Model]

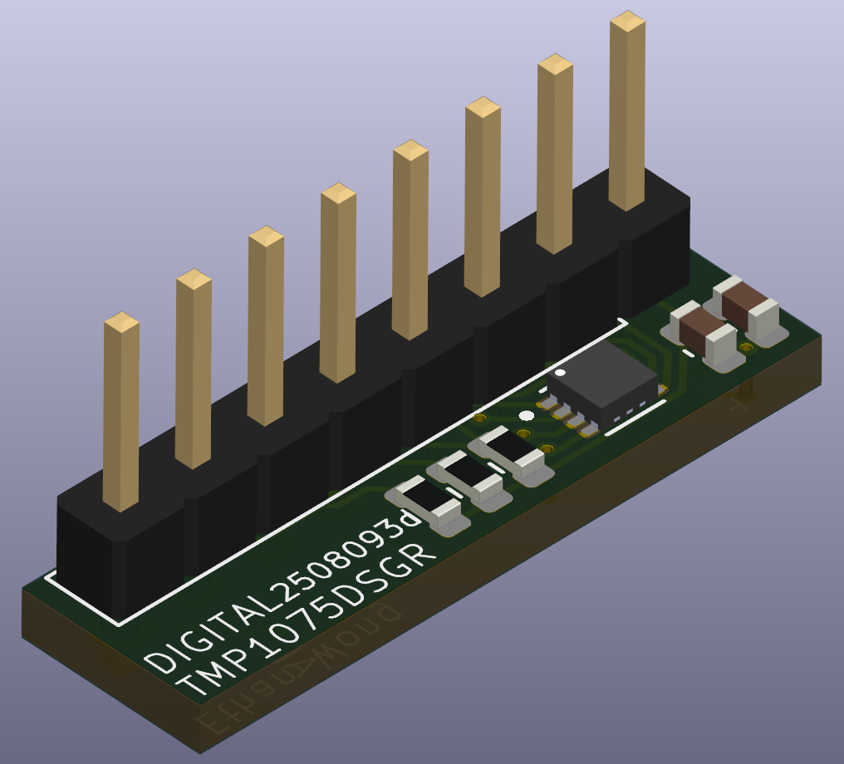
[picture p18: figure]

Heat Sensor

Monitors Internal Heat

System Controller [PCB Layout]

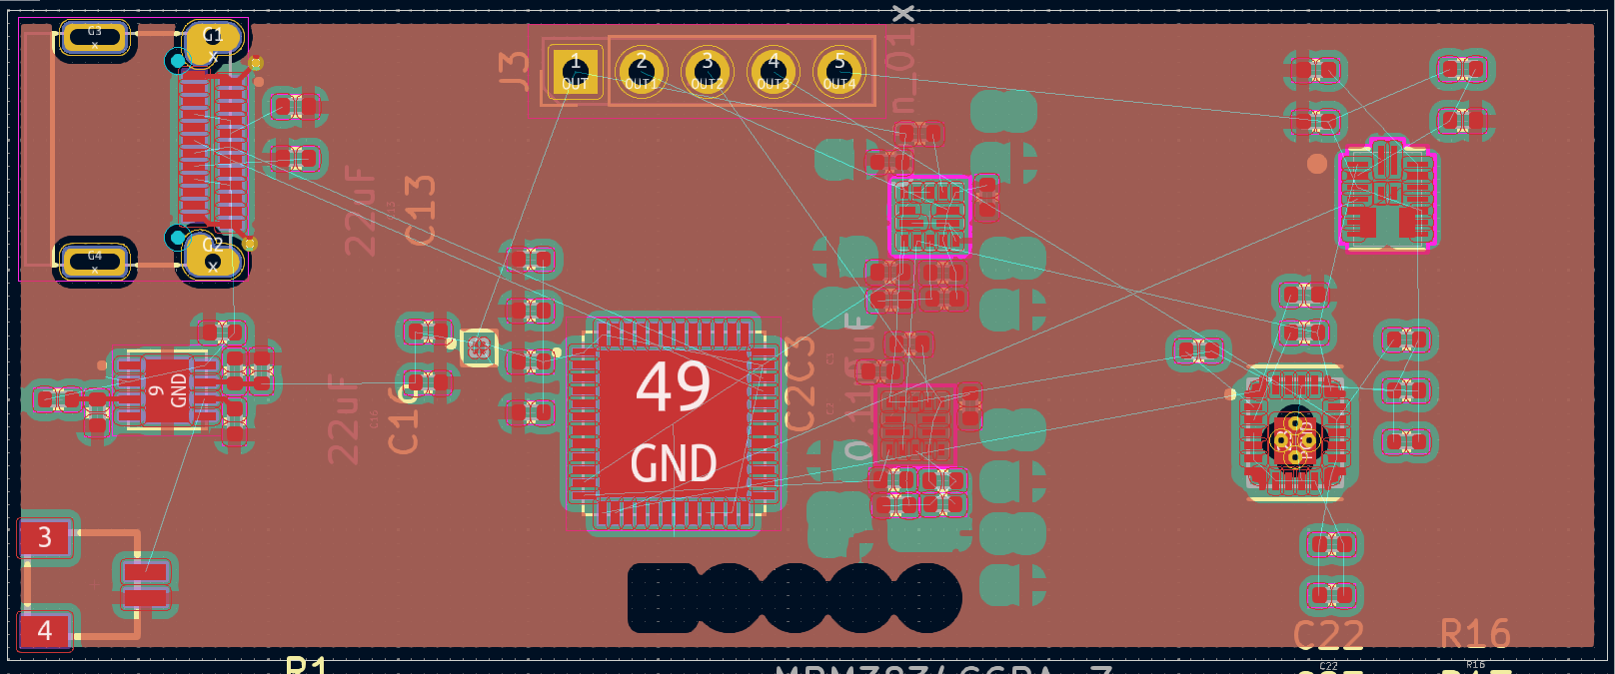
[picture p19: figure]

Controls Power Rails’ Functions

USB-C Receptacle

STM32 Microcontroller

x4 Voltage Regulator

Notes: Heat Sensor
Heat Sensor changes resistance (or another property) based on temperature
Communicates through I²C peripherals
System Controller
Utilizes microcontroller (STM32G431CBU6) to control enable pins of voltage regulators
FPGA requires its voltage regulators to turn on in a specific sequence (one cannot be turned on until the other is stable)
USB-C receptacle is used to program and communicate to the STM32 MCU

## Quick Look at the Hardware Projects

Fingerprint Sensor [Schematic]

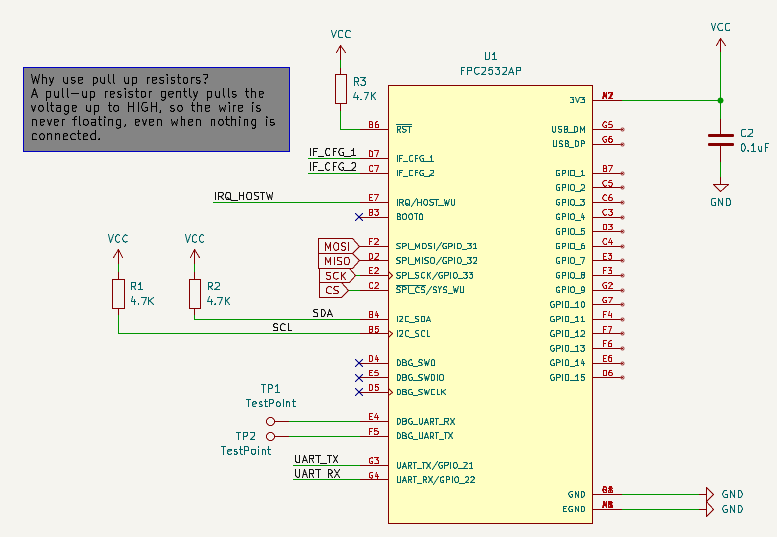
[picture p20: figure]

Quick and Secure Way For User To Protect Phone

System on Module [3D Model]

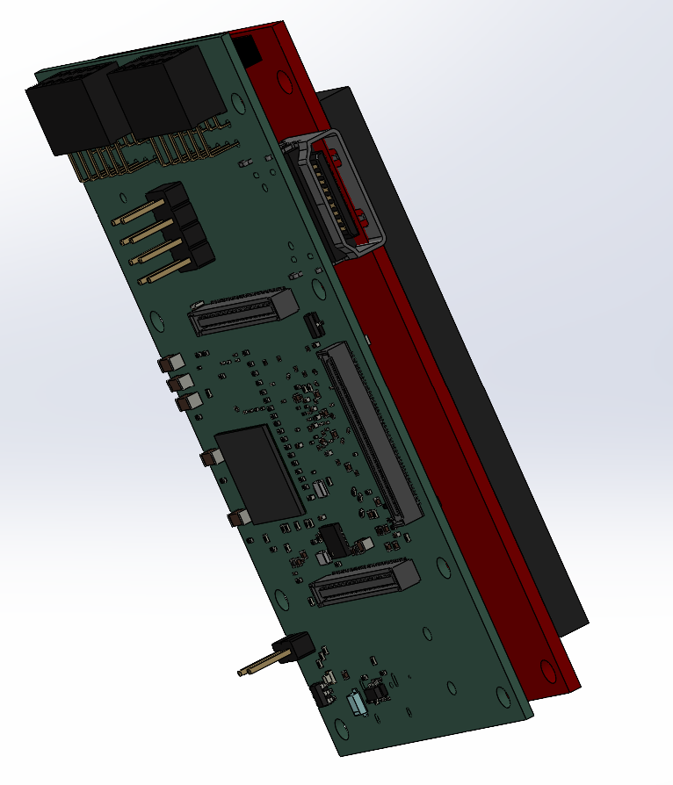
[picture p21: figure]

Motherboard

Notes: Programmable Hardware enables
Ability for the AVERAGE PERSON to easily repair of various elements in a PRODUCT WE OWN
Ability to easily assemble/disassemble ALLOWS you to upgrade your perfectly good phone by replacing only the components on the phone that YOU want improved on your phone
Ability to make a modular phone, which would allow
YOU to make your phone distinctly YOURS (not an identical slab to everyone else)
YOU to decide what are important features to you and

## Hardware Design: Motherboard (System on Module)

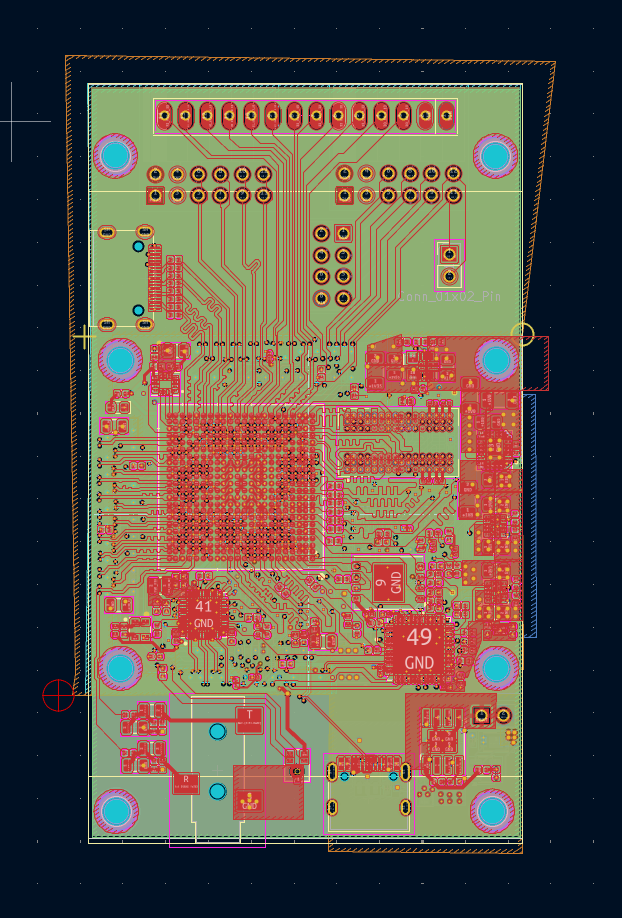
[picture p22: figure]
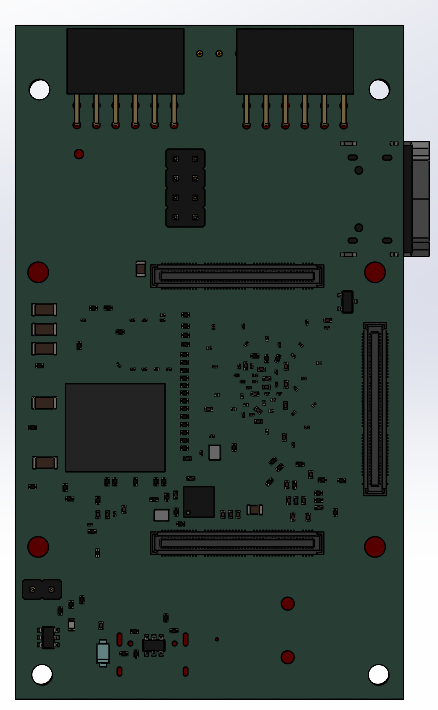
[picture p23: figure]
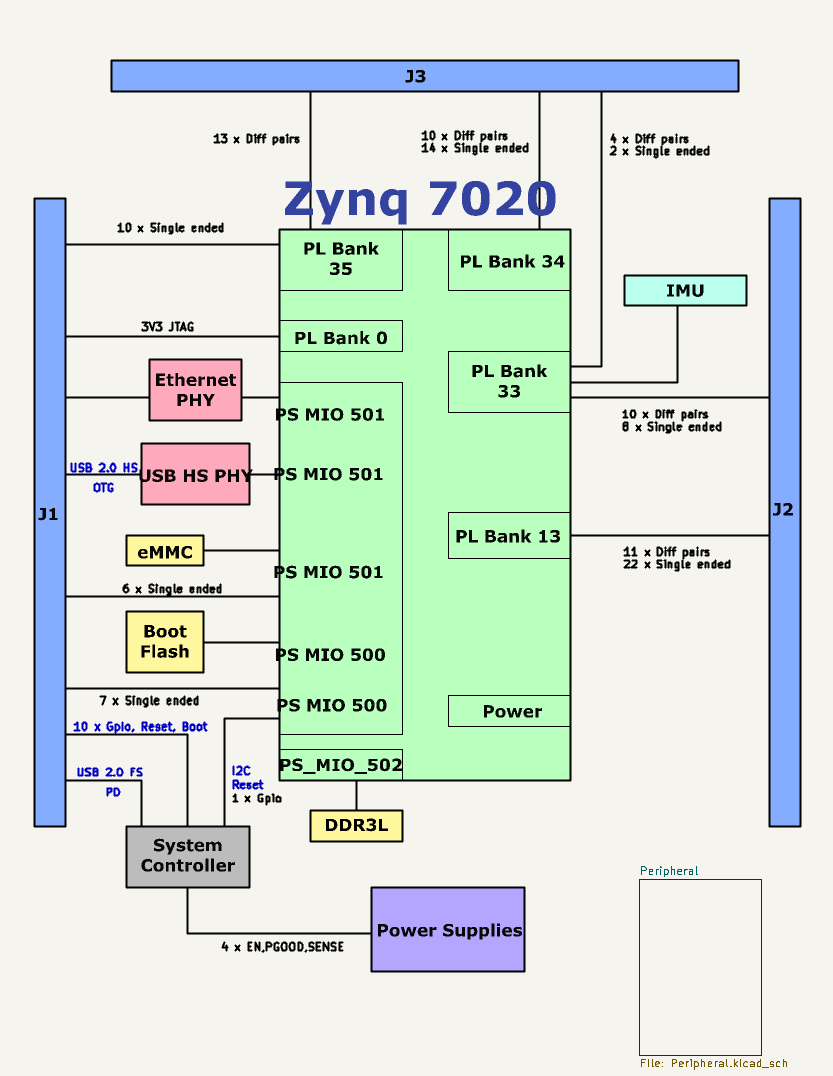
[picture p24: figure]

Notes: Haptic Motor Driver
Haptic Motor Driver is necessary to control haptic motor vibration patterns
Haptic Motor works by converting electrical energy into mechanical vibrations
Communicates through I²C peripherals
Real-Time Clock
Real-Time Clock counts time by counting the pulses of a stable quartz crystal oscillator
Uses a battery backup to maintain power independently of main power system in case of power off
Communicates through I²C peripherals
Microphone
Microphone captures sound waves (analog) and converts them into electrical signals
Multiple microphones are used to overall reduce noise caused by individual noise
Communicates through I²C peripherals

## Hardware Design: Thermometer and Barometer

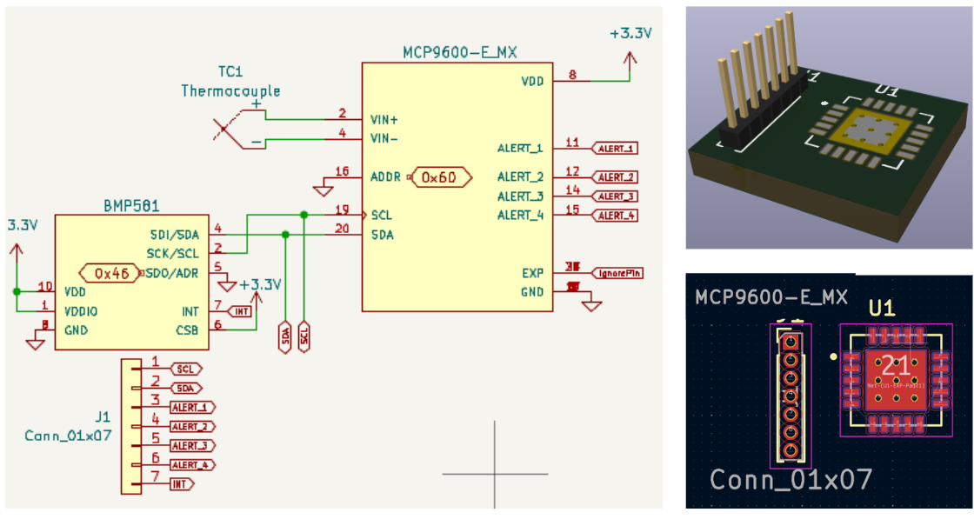
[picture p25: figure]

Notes: Project Definition
Consumer Need: Fast, secure, and user-friendly authentication → convenience and privacy
Feature: Allow users to unlock the device and verify their identity with a single touch
Purpose: Personal, Modern, and Secure
Determined the type of Fingerprint Sensor
Determined how the phone will communicate with these sensors
We then found the sensor, implemented the schematic, then converted that schematic to a 3D modeled version

## Hardware Design: Fingerprint Sensor


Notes: Project Definition
Consumer Need: Fast, secure, and user-friendly authentication → convenience and privacy
Feature: Allow users to unlock the device and verify their identity with a single touch
Purpose: Personal, Modern, and Secure
Determined the type of Fingerprint Sensor
Determined how the phone will communicate with these sensors
We then found the sensor, implemented the schematic, then converted that schematic to a 3D modeled version

## Hardware Design: STM32 Microcontroller

USB-C Receptacle

STM32 Microcontroller

x4 Voltage Regulator

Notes: Project Definition
Consumer Need: Fast, secure, and user-friendly authentication → convenience and privacy
Feature: Allow users to unlock the device and verify their identity with a single touch
Purpose: Personal, Modern, and Secure
Determined the type of Fingerprint Sensor
Determined how the phone will communicate with these sensors
We then found the sensor, implemented the schematic, then converted that schematic to a 3D modeled version

## Hardware Design: Camera


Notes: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

## Thank you

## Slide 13


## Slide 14


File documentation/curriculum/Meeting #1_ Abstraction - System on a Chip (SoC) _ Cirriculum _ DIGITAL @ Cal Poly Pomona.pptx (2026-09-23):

## The SoC Curriculum

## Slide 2

The Basics

Quick Recap: Abstraction, Implementation, Integration, Binary, Boolean Logic, Boolean Algebra, Logic Gates

## Abstraction The Levels At Which Engineering Principles Can Be Performed

App Software

Operating System

Architecture

Micro-Architecture

Logic

Digital Circuits

Analog Circuits

Devices

Physics

Programs

How The User Interactions With Predefined Operations

Device Drivers

How and When Predefined Operations Start To Execute More Complicated Operations

Instructions, Registers

How Operations Are Performed Via Hardware

Datapaths, Controllers

Adders, Memories

How Hardware Executes Commands On Instructions

How We Store Instructions For Programs To Execute By Itself

AND, NOT Gates

How We Program Components To Execute Commands When We Ask It To

Amplifiers, Filters

How We Connect Components Manipulate to Manipulate Devices to Be More Effective

Transistors, Diodes

How We Use Components to Manipulate Physics

Electrons

How It Works

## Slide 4

Interface & Implementation

Quick Recap: Digital Circuits, Binary, Boolean Logic, Boolean Algebra, Logic Gates, Hardware Design Language, and Chips

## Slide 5

_Interface and Implementation_

Interface


Implementation


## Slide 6

Interface

Binary


Want to simplify conditions into as few states as possible?

  - Yes/No
  - True/False

  - On/Off
  - 1/0

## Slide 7

What Happens When You Need Multiple Devices To Be IN a Certain State For Something To Occur?

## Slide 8

How do we create a system to compliment this simplicity and add some functionality back in to a stripped system like this?

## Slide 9

Implementation

Boolean Logic


A system of rules used to make “decisions” given multiple inputs
[How do you get an output?]

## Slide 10

Interface

Boolean Algebra


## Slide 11

Implementation

Logic Gates


LOGIC GATES ARE THE PHYSICAL OR SYMBOLIC REALIZATIONS OF THOSE RULES!!!


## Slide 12

INterface

Hardware Description Language (HDL)

- A description of the relationships (COnnections/Relative Positions) of Logic Gates
- Maps ot how logic operations are put tοgether to carry out "code” that describes the function of a circuit
- “Schematic", "Floor Plans", electrical equivalent to CAD
- Essentially, instead of doing Logic by hand and human brain, we tell a computer but that requires the computer to have an understanding of the layout we are looking for

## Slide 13

InterFace

Hardware Description Language (HDL)

- Ex: think of a simple physical circuit
  - 2 light bulbs
  - Battery
  - 2 Switches
- We want to layout the circuit so that battery the switches actually turn off it's L2 switch respective respective lightbulb-this requires a proper setup of logic"/ components" So we get our desired outcomes

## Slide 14

Implementation

Chips / Modules

- Ex: think of a simple physical circuit
  - 2 light bulbs
  - Battery
  - 2 Switches
- We want to layout the circuit so that battery the switches actually turn off it's L2 switch respective respective lightbulb-this requires a proper setup of logic"/ components" So we get our desired outcomes

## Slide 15

Implementation


Hardware Description Language (HDL)

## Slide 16

Implementation


Hardware Description Language (HDL)

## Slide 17


Implementation

Hardware Description Language (HDL)

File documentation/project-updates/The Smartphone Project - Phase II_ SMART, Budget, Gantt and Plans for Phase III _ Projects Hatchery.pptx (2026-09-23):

## The Smartphone Project

Building a Smartphone From Scratch

## Short and Concise SMART Goals

- Build a fully functional smartphone by the middle of August
- Prove that learning to build a smartphone from scratch doesn’t have to be a mystery

M

A

R

T

S

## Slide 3

Specific

- Comfortable to Hold
- Intuitive to Use
- Strong Performance
- Efficient for All-Day Use
- Snappy and Responsive
- Customizable, Repairable, and Upgradable

S

Attainable

- Capable of Doing It
- Hatchery Advisors
- CPP Staff
- Mentors
- Textbooks

M

A

Relevant

- Demystify Technical Knowledge for Smartphones
- Build Phone from Scratch
- Prove Students Can Do It

Measureable

- User-Defined in a Poll
- Performance Testing
- Real World Testing

- Define FPGA architecture
- Integrate custom FPGA board
- Complete hardware/PCB design
- Demonstrate FPGA reconfigurability
- Develop software environment

R

T

Time-Bound

- Optimize system performance [May-June]
- Test real-world use cases [May-June]
- Document process and challenges
- Disseminate results (publications, open-source)[]

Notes: User Defined in a Poll: “Comfortability to Hold”, “Intuitive to Use”, and “Speedy Enough to Feel Snappy and Responsive~~”~~
“Powerful enough to maintain strong performance” - Clock Speed, Voltage Regulation Test, Bandwidth, Power-Efficiency (Performance Per Watt),
“Efficient enough to endure a whole day of extensive use” - “Screen On Time”, “Real World Testing”, “Battery Capacity (mAh)”, “Battery Discharge Rate (mA)”, “Energy Efficiency Ratio (EER)”, “Component Power Draw”

## Integrated Master Schedule

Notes: Programmable Hardware enables
Ability for the AVERAGE PERSON to easily repair of various elements in a PRODUCT WE OWN
Ability to easily assemble/disassemble ALLOWS you to upgrade your perfectly good phone by replacing only the components on the phone that YOU want improved on your phone
Ability to make a modular phone, which would allow
YOU to make your phone distinctly YOURS (not an identical slab to everyone else)
YOU to decide what are important features to you and

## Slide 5


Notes: Programmable Hardware enables
Ability for the AVERAGE PERSON to easily repair of various elements in a PRODUCT WE OWN
Ability to easily assemble/disassemble ALLOWS you to upgrade your perfectly good phone by replacing only the components on the phone that YOU want improved on your phone
Ability to make a modular phone, which would allow
YOU to make your phone distinctly YOURS (not an identical slab to everyone else)
YOU to decide what are important features to you and

## Budget

Milestone 1
Type | | | Description | | | Qty | | | | | | | Budgeted
Supplies & Equipment | | | Liquid Crystal Display (LCD) Display Module | | | 2 | $30.00 | | | $36.00 | | | $51.00
Supplies & Equipment | | | Near Field Communication (NFC) Controller | | | 2 | $60.00 | | | $72.00 | | | $102.00
Supplies & Equipment | | | System on Chips (SoC) | | | 2 | $240.00 | | | $288.00 | | | $288.00
Supplies & Equipment | | | Memory Chip | | | 2 | $28.00 | | | $33.60 | | | $47.60
Supplies & Equipment | | | Radio Frequency (RF) Chip | | | 2 | $7.00 | | | $8.40 | | | $11.90
Supplies & Equipment | | | FPGA Development Board | | | 4 | $520.00 | | | $572.00 | | | $572.00
Supplies & Equipment | | | Battery | | | 2 | $30.00 | | | $36.00 | | | $51.00
Supplies & Equipment | | | Connectors (Audio Jacks, USB-C, Micro SD, HDMI) | | | 4 | $20.00 | | | $28.00 | | | $38.00
Supplies & Equipment | | | Microphone | | | 2 | $10.00 | | | $12.00 | | | $22.00
Supplies & Equipment | | | PCB Manufacturer | | | 1 | $700.00 | | | $800.00 | | | $800.00
Supplies & Equipment | | | Copper Heat Pipes and Spreader | | | 1 | $60.00 | | | $67.00 | | | $67.00
Supplies & Equipment | | | Thermal Pads and Paste | | | 1 | $40.00 | | | $44.00 | | | $50.00
Supplies & Equipment | | | Camera Module | | | 4 | $30.00 | | | $42.00 | | | $42.00
Supplies & Equipment | | | Miscellaneous Components (Capacitors, Resistors, etc.) | | | 1 | $200.00 | | | $240.00 | | | $210.00
Supplies & Equipment | | | ESP-32 Modules | | | 10 | $55.00 | | | $65.00 | | | $80.00
| | | | | | Total | | | | | | | $2,432.50

## Budget

Milestone 2
Type | | | Description | | | Qty | | | | | | | Budgeted
Stipends | | | PCB Manufacturer | | | 1 | $700.00 | | | $800.00 | | | $800.00
Supplies & Equipment | | | Heat Gun | | | 1 | $150.00 | | | $165.00 | | | $165.00
Suplies & Equipment | | | USB/Cable Tester (https://www.amazon.com/gp/product/B08JKN4PL5/ref=ox_sc_saved_title_4?smid=ANGHDKZZ80XV6&th=1) | | | 1 | $79.99 | | | $90.00 | | | $120.00
Suplies & Equipment | | | Multimeter and Clamp Meter Kit (https://www.amazon.com/gp/product/B00DTSLWRA/ref=ox_sc_saved_title_3?smid=ATVPDKIKX0DER&psc=1) | | | 1 | $384.93 | | | $400.00 | | | $420.00
Suplies & Equipment | | | Hot Plate | | | 1 | $60.00 | | | $70.00 | | | $90.00
Suplies & Equipment | | | Addiotonal Equipment/Components (Budget Room) | | | 1 | | | | | | | $750.00
Supplies & Equipment | | | Aluminum Phone Frame (Raw Aluminum, Finishing) | | | 1 | $475.00 | | | $522.50 | | | $600.00
| | | | | | Total | | | | | | | $2,945.00

## Budget

Milestone 3
Type | | | Description | | | Qty | Material Cost | | | Tax + Shipping | | | Budgeted
Stipends | | | Project Manager Stipend | | | | | | | | | | $1,872.50
Stipends | | | Team Members Stipend (Tentative) [Extra Room in Budget]
| | | | | | Total | | | | $3,345.50 | | | $1,872.50
TOTALS
How many student team members do you have? | | | | | | 10 | | | | | | | Milestone 1
Allotted Budget | | | | | | $8,000.00 | | | | | | | Total | | $2,432.50
| | | | | | | | | | | | | Milestone 2
| | | | | | | | | | | | | Total | | $2,945.00
| | | | | | | | | | | | | Milestone 3
| | | | | | | | | | | | | Total | | $1,872.50
| | | | | | | | | | | | | Entire Project

## Team Breakdown Structure

Project Manager
Sunny Nguyen

Business

Business Coordinator
Russell Chung

Hardware

System

System Egr Leads
Hoanh Lam

Software

Back-end Developer
Danny Tran

SoC Engineer
Andy Zhang

Hardware Egr
Max Gross

RF Comm
Angelo Duenas

Enclosure Engineer
Viren Kumar

System Egr
Nathan Alquicira

Front-end Developer
Izaiah Ortiz

## Meet The Teams: The Hardware Teams

Hardware

Hardware Design

- Designs PCBs.
- Designs Power Management Systems.
- Designs Schematics

Enclosure & Thermals

- Manages smartphone heat dissipation.
- Designs casing for cooling efficiency.
- Uses CAD and thermal analysis.

System on A Chip

- Designs CPU, GPU, and peripherals.
- Uses SystemVerilog for implementation.
- Tests and verifies live circuits.

RF Communications

- Defines RF subsystem architecture.
- Works on antennas and transceivers.
- Develops RF filters and drivers.
- Integrates RF with custom SoC.

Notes: Programmable Hardware enables
Ability for the AVERAGE PERSON to easily repair of various elements in a PRODUCT WE OWN
Ability to easily assemble/disassemble ALLOWS you to upgrade your perfectly good phone by replacing only the components on the phone that YOU want improved on your phone
Ability to make a modular phone, which would allow
YOU to make your phone distinctly YOURS (not an identical slab to everyone else)
YOU to decide what are important features to you and

## Meet The Teams: The Software, Systems, and Business Teams

Software

Operating System

- Develops a custom operating system.
- Builds and maintains smartphone apps.
- Optimizes performance, efficiency, security.

User Interface and Experience

- Designs intuitive smartphone interface.
- Ensures smooth and responsive experience.

Systems Engineering

- Aligns hardware and software teams.
- Ensures seamless system integration.
- Defines architecture, requirements, and constraints.

Business

- Manages Finances
- Works with Systems Engineering To Determine Whether Design Choices Fit in Budget

## Project Milestones

1. Define the complete FPGA-based smartphone architecture and its component specifications (FPGA, memory, peripherals).
2. Develop and integrate the custom FPGA board with core components (processing core, memory, I/O).
3. Complete hardware integration and PCB design. Demonstrate FPGA reconfigurability with basic applications.
4. Develop and integrate the software environment for user programming and hardware reconfiguration.

01

02

03

04

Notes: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

## Project Milestones

1. Optimize system performance (energy, speed, user interaction). Test real-world use cases
2. Document the entire process, challenges, solutions, and final performance evaluations.
3. Disseminate results through publications, open-source releases, and outreach activities.

05

06

07

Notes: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

## Thank you

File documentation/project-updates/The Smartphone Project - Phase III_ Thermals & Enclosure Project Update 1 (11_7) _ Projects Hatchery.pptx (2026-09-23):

## The Smartphone Project

Building a Smartphone From Scratch

## Short and Concise SMART Goals

- Build a fully functional smartphone
- Prove that learning to build a smartphone from scratch doesn’t have to be a mystery

M

A

R

T

S

## Disclaimer Thermals & Enclosure Teams


- We have multiple teams working on different aspects of the phone
  - For the sake of simplicity, we will keep this presentation for the…


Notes: Programmable Hardware enables
Ability for the AVERAGE PERSON to easily repair of various elements in a PRODUCT WE OWN
Ability to easily assemble/disassemble ALLOWS you to upgrade your perfectly good phone by replacing only the components on the phone that YOU want improved on your phone
Ability to make a modular phone, which would allow
YOU to make your phone distinctly YOURS (not an identical slab to everyone else)
YOU to decide what are important features to you and

## Design Constraints


Thermal Consideration

- Enough Heat Needs To Be Dissipated To Prevent Thermal Throttling
- Not Enough Space For Active Cooling
- Air Gaps Impede Heat Dissipation
- Not Burning Users Hands (40 - 45°C)

Enclosure Considerations

- Ergonomics & Gripability
- Must Protect Internal Electronics (& Battery(s))
- Phone Exterior Size Constraints
- Aspect Ratio of the Screen
- Internal Components Size Constraints
- Weight Distribution
- Protection from the Elements (Water & Dust)

## Approach To Addressing Design Constraints

Thermal Consideration

- Enough Heat Needs To Be Dissipated To Prevent Thermal Throttling
- Not Enough Space For Active Cooling
- Air Gaps Impede Heat Dissipation
- Not Burning Users Hands (40 - 45°C)

Thermal Approach

- Minimize Still Air, Maximize Thermal Conductivity
  - → Flatten PCB Topography
  - → Sandwich PCB Between Copper Plates
- Route the Heat To Top Of Phone Away From Hands


## Quick Look Through The Versions


Version 2


Version 3


Version 1

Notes: Haptic Motor Driver
Haptic Motor Driver is necessary to control haptic motor vibration patterns
Haptic Motor works by converting electrical energy into mechanical vibrations
Communicates through I²C peripherals
Real-Time Clock
Real-Time Clock counts time by counting the pulses of a stable quartz crystal oscillator
Uses a battery backup to maintain power independently of main power system in case of power off
Communicates through I²C peripherals
Microphone
Microphone captures sound waves (analog) and converts them into electrical signals
Multiple microphones are used to overall reduce noise caused by individual noise
Communicates through I²C peripherals

## Version 1


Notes: Programmable Hardware enables
Ability for the AVERAGE PERSON to easily repair of various elements in a PRODUCT WE OWN
Ability to easily assemble/disassemble ALLOWS you to upgrade your perfectly good phone by replacing only the components on the phone that YOU want improved on your phone
Ability to make a modular phone, which would allow
YOU to make your phone distinctly YOURS (not an identical slab to everyone else)
YOU to decide what are important features to you and

## Version 2


## Version 3



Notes: Project Definition
Consumer Need: Fast, secure, and user-friendly authentication → convenience and privacy
Feature: Allow users to unlock the device and verify their identity with a single touch
Purpose: Personal, Modern, and Secure
Determined the type of Fingerprint Sensor
Determined how the phone will communicate with these sensors
We then found the sensor, implemented the schematic, then converted that schematic to a 3D modeled version

## Future Design Plans

Thermal Consideration

- Enough Heat Needs To Be Dissipated To Prevent Thermal Throttling
- Not Enough Space For Active Cooling
- Air Gaps Impede Heat Dissipation
- Not Burning Users Hands (40 - 45°C)

Enclosure Considerations

- Ergonomics & Gripability
  - → Exploring A Sliding Mechanism Design
- Must Protect Internal Electronics (& Battery(s))
  - → Exploring An Infill With Trusses on Edges
  - → Drawing Fractures AWAY From Corner Critical Points

## Thank You

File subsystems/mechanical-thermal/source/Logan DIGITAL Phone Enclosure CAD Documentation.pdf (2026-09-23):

Phone Enclosure Design 1


Outside Dimensions:
164.09mmx75.68mmx24mm

I modeled the dimensions and aspect ratio of the phone to be loosely related to the S25 Ultra while also having enough room to fit our internal components and screen. I started from the width of the 4inch screen and added 10mm bezels on either side. The length was calculated from the width to have a ratio of about 19.5:9.

Bezels:
Meant to match align with the 4-inch screen plus large bezels for more components.

Fingerprint sensor and buttons:


I believe our fingerprint sensor is not the most compact and since it is capacitive it would struggle to work through the display so I decided a side fingerprint sensor could be a good idea. The volume and power buttons are based on the S25 layout but with bigger buttons and more clearance.

Temperature Sensor:


I made a small cutout at the top of the phone for a temperature sensor that would make it easy to take the temperature of a person or object. Could be moved to the back of the phone.

Ports and Speakers


Although our main board has HDMI and other connectors, for now I decided that a headphone jack and usb C would be good as a concept. I also included a microphone hole to the right and dual speakers although our prototype would probably only have one set of speaker holes.

Camera Bump


I based the camera bump around the size of the camera sensor in Notion which had a lens diameter of about 14mm. I also made rough holes for the flashlight and possibly another sensor like a time of flight sensor.

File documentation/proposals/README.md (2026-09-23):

# Project proposals

- [Smartphone Education: Building a Modular Student-Designed Smartphone](Smartphone%20Education_%20Building%20a%20Modular%20Student-Designed%20Smartphone%20-%20The%20Smartphone%20Project%20_%20CPP%20Projects%20Hatchery.pdf) is a 13-page Learn Through Discovery Projects Hatchery proposal covering the project's educational rationale, FPGA-centered modular platform, development phases, team, SMART goals, and $7,250 milestone budget.
- [Projects Hatchery Phase I Application](Projects%20Hatchery%20Phase%20I%20Application.docx) preserves interview preparation and application material about reducing barriers to hands-on electronics and smartphone engineering.

The PDF title page credits Sunny Nguyen, Russell Chung, Viren Kumar, Boi Hoanh Lam, Andy Zhang, Izaiah Ortiz, Nathan Alquicira, Angelo Duenas, and Chris Zambrana. It names Dr. Mohamed El Hadedy as faculty mentor.

See [PROVENANCE.md](PROVENANCE.md) and [SHA256SUMS](SHA256SUMS) for source and integrity records.

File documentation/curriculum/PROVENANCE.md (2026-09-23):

# Curriculum provenance

- Supplied by: Russell Chung
- Added to consolidation: 2026-09-23
- Original repository or publication URLs: not supplied
- Explicit license statements: none found

All four PowerPoint files are stored unchanged. Their slide packages were inspected and every slide rendered successfully for visual verification. Embedded presentation text was treated as source content, not as instructions for the consolidation.

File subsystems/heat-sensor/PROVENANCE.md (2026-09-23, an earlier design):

# Provenance

- Supplied archive: `Heat Sensor - 2025-08-15 197809.zip`
- Added to consolidation: 2026-09-23
- SHA-256: `30DDAB1F345217A2CEF256DC7377C1FA49B5B605D11B1B87316C5A627CE6C446`
- Original repository/commit: not supplied
- Contributor identity: not supplied; no authorship inferred from internal filenames
- Explicit license file found in archive: none

The archive is preserved unchanged under `source/`.

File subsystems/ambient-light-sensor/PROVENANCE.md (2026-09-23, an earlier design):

# Provenance

- Original repository: <https://github.com/llknip/DIGITAL-LLK-Light-Sensor>
- Branch: `main`
- Imported commit: [`5b3eab19ff16d49af1ef259c525b7fe299c8173c`](https://github.com/llknip/DIGITAL-LLK-Light-Sensor/commit/5b3eab19ff16d49af1ef259c525b7fe299c8173c)
- Snapshot date: 2026-09-23
- Commit contributor through this revision: [Logan Knip / llknip](https://github.com/llknip)
- License found in source: none

Files under `source/` are an unchanged snapshot of the files tracked at the commit above.

## Additional supplied snapshots

Four additional archives were supplied directly by the project maintainer on 2026-09-23. No original repository URL, commit history, contributor identity, or explicit license accompanied them, so none is inferred. Their original filenames are preserved under `source/additional-snapshots/`, and their SHA-256 hashes are recorded in `SHA256SUMS`.

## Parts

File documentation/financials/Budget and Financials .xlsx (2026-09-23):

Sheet: Sheet7
Part Name | Description | Discord Name | Link | Price (USD) | W Tax+Shipping | Comments/Reasoning | Column 1
Screw Extractor | Nuovoware Damaged Screw Extractor Set, 22 PCS Easy Out Stripped Screw Extractor Kit, All-purpose HSS Broken Screw Remover Set with Magnetic Extension Bit Holder & Socket Adapter | ravagedseaurchin | https://www.amazon.com/Nuovoware-Extractor-Stripped-All-purpose-Extension/dp/B08XXP1SD9 | $14.24 |  | Screws stripped/stuck need to remove this helps
Helping Hands | Kaisiking Helping Hands Soldering Station with Magnifying Glass, PCB Holder 4 Flexible Arms Magnifier and Third Hand Soldering Tool for Electronic Repair Soldering Jewelry Crafts | ravagedseaurchin | https://www.amazon.com/Kaisiking-Soldering-Magnifying-Magnifier-Electronic/dp/B0D8W2BSXJ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 | $19.99 |  | Instead of microscope more of these should do the job (cheaper)
Acetone | Supernail Pure Acetone Polish Remover, 8 oz (Pack of 6) | ravagedseaurchin | https://www.amazon.com/Super-Nail-Acetone-Polish-Remover/dp/B004CCUCAA?sp_csd=d2lkZ2V0TmFtZT1zcF9hdGY | $19.38 |  | REALLY GOOD DEAL ON BULK ACETONE
Thermal Pads | PTM7950 Thermal Pad Phase Change Heatsink 80x80x0.25mm 8.5W/mK Conductive for Heatsink PS5 Steam Deck CPU GPU SSD Silicone Grease Thermal Pad | ravagedseaurchin | https://www.amazon.com/PTM7950-Heatsink-80x80x0-2mm-Conductive-Silicone/dp/B0BX42N9SZ | $25.99 |  | Thermal Pads on the pricer side but worth it in applicability and ease of use (we can get better value for bulk if we can purchase outside amazon)
Glue | Upgrade T-7000 Black Adhesive Glue for Phone, Cridoz 110ml Waterproof Jewelry Glue Precision Craft Adhesive for Cell Phone Screen Repair Glass Wood Crafts Metal and Stones | ravagedseaurchin | https://www.amazon.com/Upgrade-Adhesive-Waterproof-Jewelry-Precision/dp/B09YRT2YJ4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 | $7.99 |  | Glue to put the devices back together after removing old glue to open it up
Brushes | The Army Painter Gamemaster Character Brush Set - Precise Detail Brush Set Include 1 Small Detail Brush, 1 Monstrous Brush, 1 Drybrush Fine Detail Paint Brush, Small Paint Brush for Miniature Painting | ravagedseaurchin | https://www.amazon.com/gp/product/B0BRL3DJ8Z/ref=ox_sc_act_title_22?smid=A12KX68C9776T9&psc=1 | $15.30 |  | We probably have brushes to apply grease/lube, if not this is the amazon link to some good ones (won't break down from the compounds)
Threadlocker | ESKONKE Thread Locker Blue 243 - Removable Threadlocker Metal Glue for Nuts, Bolts, Fasteners Medium Strength Screw Compound to Prevent Loosening & Corrosion 1.69 Oz/50 ml | ravagedseaurchin | https://www.amazon.com/gp/product/B0CHM5QS3N/ref=ox_sc_act_title_14?smid=AKFL6YKYZULXS&th=1 | $9.99 |  | Keeps bolts/parts from seizing (also kinda important)
Antisieze | Permatex 80078 Anti-Seize Lubricant With Brush Top Bottle Prevents Galling, Corrosion, Seizing, Refined Blend Aluminum, Copper, And Graphite Lubricants For Spark Plugs 8 oz | ravagedseaurchin | https://www.amazon.com/gp/product/B000FW7VGE/ref=ox_sc_act_title_21?smid=ATVPDKIKX0DER&th=1 | $8.99
Cleaning Rags (150) | SIMPLI-MAGIC Cotton Shop Towels 14"x12" (150 Pack) – Reusable Cleaning Shop Rags for Automobiles, Industries, Garage and Homes (White) | ravagedseaurchin | https://www.amazon.com/Simpli-Magic-79142-Shop-Towels-White/dp/B07J3BLQPM
Microsope 3rd person |  | ravagedseaurchin |  |  |  | Great Education/Training Tool, better than no microscope when needed (Convinced by Dr.Velden)
Solder Paste | Wonderway Sn42/Bi58 T4 Lead Free Solder Paste No Clean, 138℃ Melting Point (30gx4packs) | ravagedseaurchin | https://www.amazon.com/Wonderway-Solder-Paste-Melting-30gx4packs/dp/B0D14KSQ48?sp_csd=d2lkZ2V0TmFtZT1zcF9hdGY | $22.99 |  | We HAD A HOT PLATE THIS WHOLE TIME AND NOT THE TOOLS TO USE IT GHJASKLFSHLKFHAS:L
 |  |  |  | $144.86 | $0.00

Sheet: Submitted Budget
Milestone 1
Type | Description | Qty |  |  | Budgeted |  | Key
Supplies & Equipment | Liquid Crystal Display (LCD) Display Module | 2 | $30.00 | $36.00 | $51.00 |  | Type | What is the money being used for?
Supplies & Equipment | Near Field Communication (NFC) Controller | 2 | $60.00 | $72.00 | $102.00 |  |  | 4 categories:
Supplies & Equipment | System on Chips (SoC) | 2 | $240.00 | $288.00 | $288.00 |  |  | Stipend
Supplies & Equipment | Memory Chip | 2 | $28.00 | $33.60 | $47.60 |  |  | Supplies & Equipment
Supplies & Equipment | Radio Frequency (RF) Chip | 2 | $7.00 | $8.40 | $11.90 |  |  | Travel
Supplies & Equipment | FPGA Development Board | 1 | $195.00 | $225.00 | $225.00 |  |  | Other
Supplies & Equipment | Battery | 2 | $30.00 | $36.00 | $51.00 |  | Description | Who is receiving the stipend? What is the equipment you are purchasing? What is the travel expenditure?
Supplies & Equipment | Connectors (Audio Jacks, USB-C, Micro SD, HDMI) | 4 | $20.00 | $28.00 | $38.00
Supplies & Equipment | Microphone | 2 | $10.00 | $12.00 | $22.00
Supplies & Equipment | PCB Manufacturer | 1 | $700.00 | $800.00 | $800.00
Supplies & Equipment | Copper Heat Pipes and Spreader | 1 | $60.00 | $67.00 | $67.00
Supplies & Equipment | Thermal Pads and Paste | 1 | $40.00 | $44.00 | $50.00
Supplies & Equipment | Camera Module | 4 | $30.00 | $42.00 | $42.00 |  | Qty | Quantity
Supplies & Equipment | ESP-32 Modules | 10 | $55.00 | $65.00 | $80.00
 |  | Total |  |  | $1875.50
Milestone 2
Type | Description | Qty |  |  | Budgeted
Stipends | PCB Manufacturer | 1 | $700.00 | $800.00 | $800.00
Supplies & Equipment | Heat Gun | 1 | $150.00 | $165.00 | $165.00
Suplies & Equipment | USB/Cable Tester (https://www.amazon.com/gp/product/B08JKN4PL5/ref=ox_sc_saved_title_4?smid=ANGHDKZZ80XV6&th=1) | 1 | $79.99 | $90.00 | $120.00
Suplies & Equipment | Multimeter and Clamp Meter Kit (https://www.amazon.com/gp/product/B00DTSLWRA/ref=ox_sc_saved_title_3?smid=ATVPDKIKX0DER&psc=1) | 1 | $384.93 | $400.00 | $420.00
Suplies & Equipment | Hot Plate | 1 | $60.00 | $70.00 | $90.00
Supplies & Equipment | Miscellaneous Components (Capacitors, Resistors, etc.) | 1 | $200.00 | $240.00 | $210.00
 |  | Total |  |  | $1805.00
Milestone 3
Type | Description | Qty | Material Cost | Tax + Shipping | Budgeted
Supplies & Equipment | Aluminum Phone Frame (Raw Aluminum, Finishing) | 1 | $475.00 | $522.50 | $600.00
Suplies & Equipment | Addiotonal Equipment/Components (Budget Room) | 1 |  |  | $750.00
 |  | Total |  | $3345.50 | $1350.00
TOTALS
How many student team members do you have? |  | 10 |  |  | Milestone 1
Allotted Budget |  | $5000.00 |  |  | Total | $1875.50
 |  |  |  |  | Milestone 2
 |  |  |  |  | Total | $1805.00
 |  |  |  |  | Milestone 3
 |  |  |  |  | Total | $1350.00
 |  |  |  |  | Entire Project
 |  |  |  |  | Total | $5030.50

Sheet: Final Budget Proposal Hatchery
Milestone 1 |  |  |  |  |  |  |  |  | 328
Type | Description | Product Links |  | Qty | Item Price | Shipped + Tax | Budgeted |  |  | Key
Supplies & Equipment | Liquid Crystal Display (LCD) Display Module | Liquid Crystal Display (LCD) Display Module |  | 2 | $30.00 | $36.00 | $51.00 |  |  | Type | What is the money being used for?
Supplies & Equipment | Near Field Communication (NFC) Controller | Near Field Communication (NFC) Controller |  | 2 | $60.00 | $72.00 | $102.00 |  | Big Daughterboard: 110 |  | 4 categories:
Supplies & Equipment | System on Chips (SoC) | System on Chips (SoC) |  | 2 | $240.00 | $288.00 | $288.00 |  | Smaller Daughterboard: 50 |  | Stipend
Supplies & Equipment | Memory Chip | Memory Chip |  | 2 | $28.00 | $33.60 | $47.60 |  |  |  | Supplies & Equipment
Supplies & Equipment | Radio Frequency (RF) Chip | Radio Frequency (RF) Chip |  | 2 | $7.00 | $8.40 | $11.90 |  |  |  | Travel
 |  |  |  |  |  |  |  |  |  |  | Other
Supplies & Equipment | 3.7V 10000mAh Rechargeable Lithium Ion Polymer Battery | https://a.co/d/iwljzqt |  | 2 | $59.98 | $61.43 |  |  |  | Description | Who is receiving the stipend? What is the equipment you are purchasing? What is the travel expenditure?
Supplies & Equipment | HDMI | ?
Supplies & Equipment | MicroSD Slot | ?
Supplies & Equipment | Audio Jack | https://www.digikey.com/en/products/detail/same-sky-formerly-cui-devices/SJ-3523-SMT-TR/281297 |  | 2 | $1.84 | $2.21 | $2.50
Supplies & Equipment | Microphone | https://www.digikey.com/en/products/detail/pui-audio-inc/AMM-2742-T-WP-R/14289961 |  | 2 | $5.78 | $14.47
Supplies & Equipment | PCB Manufacturer | https://jlcpcb.com/ |  | 1 | $700.00 | $800.00 | $800.00
Supplies & Equipment | Round Copper Heat Pipes | https://www.aliexpress.us/item/3256805846099656.html?src=google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 |  | 1 | $4.05 | $10.46
Supplies & Equipment | Flat Copper Heat Pipes | https://www.aliexpress.us/item/3256807168791192.html?scm_id=1007.40196.439370.0&scm-url=1007.40196.439370.0 |  | 1 | $0.99 | $1.11
Supplies & Equipment | Copper Heat Spreader | ? |  | 1
Supplies & Equipment | Silicone Thermal Pads | https://www.amazon.com/Silicone-Including-Thickness-Conductive-Heatsink/dp/B0CN9GH7HG |  | 1 | $9.99 | $11.11
Supplies & Equipment | Thermal Paste | https://www.amazon.com/ARCTIC-MX-4-2019-Performance-Durability/dp/B07L9BDY3T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 |  | 1 | $5.48 | $5.86
Supplies & Equipment | Camera Module | https://www.digikey.com/en/products/detail/image-quality-labs-inc/IQL-OV5675-FF/22022863 |  | 1 | $63.00 | $70.00 |  |  |  | Qty | Quantity
Supplies & Equipment | Raspberry Pico Pi Development Board (2-Pack) | https://a.co/d/bnC5xsX |  | 1 | $9.99
Supplies & Equipment | STM32 Development Board (4-Pack) | https://www.amazon.com/dp/B0FDG3MKVK?csmig=1 |  | 1 | $55.00 | $65.00
 |  |  |  | Total |  |  | $1303.00
Milestone 2 |  |  |  |  |  |  |  |  | 795
Type | Description | Product Links |  | Qty |  |  | Budgeted |  | Updated Mother Board
Stipends | PCB Manufacturer | PCB Manufacturer |  | 1 | $700.00 | $800.00 | $800.00
Supplies & Equipment | Heat Gun | Heat Gun |  | 1 | $150.00 | $165.00 | $165.00
Suplies & Equipment | USB/Cable Tester (https://www.amazon.com/gp/product/B08JKN4PL5/ref=ox_sc_saved_title_4?smid=ANGHDKZZ80XV6&th=1) | USB/Cable Tester (https://www.amazon.com/gp/product/B08JKN4PL5/ref=ox_sc_saved_title_4?smid=ANGHDKZZ80XV6&th=1) |  | 1 | $79.99 | $90.00 | $120.00
 | Bulk Breakout Board | Bulk Breakout Boards
Supplies & Equipment | Multimeter and Clamp Meter Kit (https://www.amazon.com/gp/product/B00DTSLWRA/ref=ox_sc_saved_title_3?smid=ATVPDKIKX0DER&psc=1) | Multimeter and Clamp Meter Kit (https://www.amazon.com/gp/product/B00DTSLWRA/ref=ox_sc_saved_title_3?smid=ATVPDKIKX0DER&psc=1) |  | 1 | $384.93 | $400.00 | $420.00
Supplies & Equipment | Hot Plate | Hot Plate |  | 1 | $60.00 | $70.00 | $90.00
Supplies & Equipment | Electrically Inducting Tape | https://www.amazon.com/ELEGOO-Polyimide-Temperature-Resistant-Multi-Sized/dp/B072Z92QZ2 |  | 1 | $9.99 | $11.11
Supplies & Equipment | Sandpaper | https://www.amazon.com/Sandpaper-Waterproof-Furniture-Finishing-Automotive/dp/B07KV3VX97 |  | 1 | $6.99 | $7.67
Supplies & Equipment | Lapping Kits | https://www.amazon.com/3M-TM-Microfinishing-Sharpening-Aluminum/dp/B07TDMS1H8 |  | 1 | $16.48 | $17.68
Supplies & Equipment | Miscellaneous Components (Capacitors, Resistors, etc.) | Miscellaneous Components (Capacitors, Resistors, etc.) |  | 1 | $200.00 | $240.00 | $210.00
 |  |  |  | Total |  |  | $1805.00
Milestone 3
Type | Description | Product Links |  | Qty | Material Cost | Tax + Shipping | Budgeted |  | Side Note | Izaiah's Quote
Supplies & Equipment | Aluminum Phone Frame (Raw Aluminum, Finishing) | Aluminum Phone Frame (Raw Aluminum, Finishing) |  | 1 | $475.00 | $522.50 | $600.00 |  | $50-$80
Supplies & Equipment | Test Display (2.8'') | https://www.amazon.com/JESSINIE-Display-ILI9341-Monitor-240x320/dp/B0B7MJK826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 |  | 1 | $14.95 | $16.41
Supplies & Equipment | Display | ? |  | 1
Supplies & Equipment | Additional Equipment/Components (Budget Room) | Additional Equipment/Components (Budget Room) |  | 1 |  | $750.00
 |  |  |  | Total |  | $4068.38 | $600.00
TOTALS
How many student team members do you have? |  |  |  | 10 |  |  | Milestone 1 |  | Higher Grit Sandpaper
Allotted Budget |  |  |  | $5000.00 |  |  | Total | $1303.00
 |  |  |  |  |  |  | Milestone 2
 |  |  |  |  |  |  | Total | $1805.00
 |  |  | 328 |  |  |  | Milestone 3
 |  |  |  |  |  |  | Total | $600.00
 |  |  |  |  |  |  | Entire Project
 |  |  |  |  |  |  | Total | $3708.00

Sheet: BOM for PCB
Comment | JLCPCB Part # | Quantity | Price (ea) ($) | Total Quantity | Total Component Price
W25Q128JVS | C401662 |  | $1.7115 | 611 | 420.29
2.4K | C11889 |  | $0.0008
100k | C60491 |  | $0.0005 | Shipping | States Sales $ Use Tax
NMOS | C700968 |  | $0.2156 | 40.85 | 37.98
USB_C_Receptacle_USB2.0 | C165948 | 2 | $0.1697
600@100MHz | C337875 | 2 | $0.0046 | Import Tax
DF40C-100DS-0.4V_51 | C597931 | 6 | $0.8850 | 222.92
330 | C25104 | 2 | $0.0006
DW01x | C181096 | 2 | $0.0291 | Grand Total
44k2 | C25895 | 2 | $0.0005 | 707.04
10k | C25744 |  | $0.0005
BMI323 | C5368700 | 2 | $1.4655
100u | C15008 | 22 | $0.0615
100K | C25741 | 2 | $0.0005
DMP2104LP | C260933 | 2 | $0.2753
5k1 | C25905 | 6 | $0.0005
8k06 | C25923 | 2 | $0.0005
STM32G431CBUx | C529356 | 2 | $2.2305
470n | C85926 | 92 | $0.0025
47u | C16780 | 26 | $0.0278
LED_RED | C157741 | 2 | $0.0136
10K | C364373 | 4 | $0.0025
4k7 | C25900 | 24 | $0.0005
TPSM82864 | C5219321 | 2 | $4.4760
XC7Z020-CLG484 | C89055 | 2 | $19.0260
RTL8211F | C187932 | 2 | $1.1400
1k5 | C25867 | 6 | $0.0006
3u3 | C7184 | 2 | $0.0846
220 | C25092 | 66 | $0.0005
MPM3834 | C6675417 | 4 | $4.4190
160k | C25757 | 2 | $0.0005
1M | C26083 | 2 | $0.0006
DSK34 | C7502709 | 2 | $0.0320
MT41K256M16TW-107_P | C253882 | 2 | $2.1660
22u | C45783 | 6 | $0.0237
470 | C25117 | 2 | $0.0005
240R | C25094 | 2 | $0.0005
47n | C85925 | 68 | $0.0059
200k | C137903 | 6 | $0.0005
IS21ES08G | C499918 | 2 | $7.3530
2k49 | C25884 | 2 | $0.0005
12k | C845672 | 2 | $0.0035
1K | C11702 | 4 | $0.0005
USB3318 | C622618 | 2 | $2.5815
22nF | C1523 | 54 | $0.0011
TPS7A20 | C42901993 | 2 | $1.6575
100n | C1525 | 34 | $0.0011
SRV05-4 | C7420376 | 2 | $0.0809
120R | C275478 | 14 | $0.0126
MPM3822 | C2977812 | 2 | $5.7360
10u | C15525 | 4 | $0.0059
100R | C77623 | 6 | $0.0008
28k7 | C26972 | 2 | $0.0005
TP4056 | C725790 | 2 | $0.0645
PCB Assembly |  | 2 | $74.0800
PCB Board |  | 5 | $346.2100

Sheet: BOM of EVERYTHING
Milestone 1
Type |  | Team | Description | Product Links | Qty |  |  | Budgeted
Supplies & Equipment |  |  | FPGA Development Board | FPGA Development Board | 1 | $195.00 | $225.00 | $225.00
Supplies & Equipment | System on Module (SoM) [Motherboard] | Hardware Design | System on Module (SoM) [Motherboard]
Supplies & Equipment | System on Module (SoM) [Motherboard] | Hardware Design | 1 kΩ Resistor [JLCPCB Part C11702 (Basic)] |  | 4
Supplies & Equipment | System on Module (SoM) [Motherboard] | Hardware Design | 220 Ω Resistor [JLCPCB Part C25092 (Basic)]
Supplies & Equipment | System on Module (SoM) [Motherboard] | Hardware Design | 330 Ω Resistor [JLCPCB Part C25104 (Basic)]
Supplies & Equipment | System on Module (SoM) [Motherboard] | Hardware Design | 470 Ω Resistor [JLCPCB Part C25117 (Basic)]
Supplies & Equipment | System on Module (SoM) [Motherboard] | Hardware Design | 1.5 kΩ Resistor [JLCPCB Part C25867 (Basic)]
Supplies & Equipment | System on Module (SoM) [Motherboard] | Hardware Design | 4.7 kΩ Resistor [JLCPCB Part C25900 (Basic)]
Supplies & Equipment | System on Module (SoM) [Motherboard] | Hardware Design | 5.1 kΩ Resistor [JLCPCB Part C25905 (Basic)]
Supplies & Equipment | System on Module (SoM) [Motherboard] | Hardware Design | 10 kΩ Resistor [JLCPCB Part C25744 (Basic)] |  | 50
Supplies & Equipment | System on Module (SoM) [Motherboard] | Hardware Design | 1 MΩ Resistor [JLCPCB Part C26083 (Basic)]
Supplies & Equipment | System on Module (SoM) [Motherboard] | Hardware Design | 100 kΩ Resistor [JLCPCB Part C25741 (Basic)]
Supplies & Equipment | System on Module (SoM) [Motherboard] | Hardware Design | 10 kΩ Resistor [JLCPCB Part C364373 (Extended)]
Supplies & Equipment | System on Module (SoM) [Motherboard] | Hardware Design | 100 Ω Resistor [JLCPCB Part C77623 (Extended)]
Supplies & Equipment | System on Module (SoM) [Motherboard] | Hardware Design | 100 kΩ Resistor [JLCPCB Part C60491 (Extended)] |  | 34
Supplies & Equipment | System on Module (SoM) [Motherboard] | Hardware Design | 160 kΩ Resistor [JLCPCB Part C25867 (Extended)]
Supplies & Equipment | System on Module (SoM) [Motherboard] | Hardware Design | 200 kΩ Resistor [JLCPCB Part C137903 (Extended)]
Supplies & Equipment | System on Module (SoM) [Motherboard] | Hardware Design | 240 Ω Resistor [JLCPCB Part C25094 (Extended)]
Supplies & Equipment | System on Module (SoM) [Motherboard] | Hardware Design | 160 kΩ Resistor [JLCPCB Part C25757 (Extended)]
Supplies & Equipment | System on Module (SoM) [Motherboard] | Hardware Design | 2.49 kΩ Resistor [JLCPCB Part C25884 (Extended)]
Supplies & Equipment | System on Module (SoM) [Motherboard] | Hardware Design | 44.2 kΩ Resistor [JLCPCB Part C25895 (Extended)]
Supplies & Equipment | System on Module (SoM) [Motherboard] | Hardware Design | 8.06 kΩ Resistor [JLCPCB Part C25923 (Extended)]
Supplies & Equipment | System on Module (SoM) [Motherboard] | Hardware Design | 12 kΩ Resistor [JLCPCB Part C845672 (Extended)]
Supplies & Equipment | System on Module (SoM) [Motherboard] | Hardware Design | 28.7 kΩ Resistor [JLCPCB Part C26972 (Extended)]
Supplies & Equipment | System on Module (SoM) [Motherboard] | Hardware Design | 2.4 kΩ Resistor [JLCPCB Part C11889 (Extended)] |  | 2
Supplies & Equipment | System on Module (SoM) [Motherboard] | Hardware Design | 120Ω@100MHz Ferrite Bead [JLCPCB Part C275478 (Extended)]
Supplies & Equipment | System on Module (SoM) [Motherboard] | Hardware Design | 600Ω@100MHz Ferrite Bead [JLCPCB Part C337875 (Extended)]
Supplies & Equipment | System on Module (SoM) [Motherboard] | Hardware Design | 100μF Capacitors [JLCPCB Part C15008 (Basic)]
Supplies & Equipment | System on Module (SoM) [Motherboard] | Hardware Design | 47 μF Capacitors [JLCPCB Part C16780 (Basic)]
Supplies & Equipment | System on Module (SoM) [Motherboard] | Hardware Design | 10 μF Capacitors [JLCPCB Part C15525 (Basic)]
Supplies & Equipment | System on Module (SoM) [Motherboard] | Hardware Design | 22 μF Capacitors [JLCPCB Part C45783 (Basic)]
Supplies & Equipment | System on Module (SoM) [Motherboard] | Hardware Design | 22 nF Capacitors [JLCPCB Part C1523 (Extended)]
Supplies & Equipment | System on Module (SoM) [Motherboard] | Hardware Design | 100 nF Capacitors [JLCPCB Part C1525 (Extended)]
Supplies & Equipment | System on Module (SoM) [Motherboard] | Hardware Design | 47 nF Capacitors [JLCPCB Part C85925 (Extended)]
Supplies & Equipment | System on Module (SoM) [Motherboard] | Hardware Design | 470 nF Capacitors [JLCPCB Part C85926 (Extended)]
Supplies & Equipment | System on Module (SoM) [Motherboard] | Hardware Design | 3.3 μF Capacitors [JLCPCB Part C7184 (Extended)]
Supplies & Equipment | System on Module (SoM) [Motherboard] | Hardware Design | 5A Female Type-C [JLCPCB Part C165948 (Extended)]
Supplies & Equipment | System on Module (SoM) [Motherboard] | Hardware Design | Battery Protection IC [JLCPCB Part C181096 (Extended)]
Supplies & Equipment | System on Module (SoM) [Motherboard] | Hardware Design | Ethernet Transceivers [JLCPCB Part C187932 (Extended)]
Supplies & Equipment | System on Module (SoM) [Motherboard] | Hardware Design | DDR SDRAM [JLCPCB Part C253882 (Extended)]
Supplies & Equipment | System on Module (SoM) [Motherboard] | Hardware Design | 1.5A P-Channel MOSFET [JLCPCB Part C260933 (Extended)]
Supplies & Equipment | System on Module (SoM) [Motherboard] | Hardware Design | 128Mbit SPI Flash Memory [JLCPCB Part C401662 (Extended)] |  | 2
Supplies & Equipment | System on Module (SoM) [Motherboard] | Hardware Design | CPU (STM32G431CBU6) [JLCPCB Part C529356 (Extended)]
Supplies & Equipment | System on Module (SoM) [Motherboard] | Hardware Design | Red LED Indicator [JLCPCB Part C157741 (Extended)]
Supplies & Equipment | System on Module (SoM) [Motherboard] | Hardware Design | DC-DC Buck Converter Module [JLCPCB Part C2977812 (Extended)]
Supplies & Equipment | System on Module (SoM) [Motherboard] | Hardware Design | Accelerometer Gyroscope [JLCPCB Part C5368700 (Extended)]
Supplies & Equipment | System on Module (SoM) [Motherboard] | Hardware Design | 8 GB eMMC chip [Non-Removable SD] [JLCPCB Part C499918 (Extended)]
Supplies & Equipment | System on Module (SoM) [Motherboard] | Hardware Design | Voltage Regulators [JLCPCB Part C42901993 (Extended)]
Supplies & Equipment | System on Module (SoM) [Motherboard] | Hardware Design | DC-DC Step-Down Converter [JLCPCB Part C5219321 (Extended)]
Supplies & Equipment | System on Module (SoM) [Motherboard] | Hardware Design | Female 100-Pin Board-to-Board Connector [JLCPCB Part C597931 (Extended)]
Supplies & Equipment | System on Module (SoM) [Motherboard] | Hardware Design | USB PHY (Physical Layer Transceiver) [JLCPCB Part C622618 (Extended)]
Supplies & Equipment | System on Module (SoM) [Motherboard] | Hardware Design | DC-DC Step-Down Power Supply Module [JLCPCB Part C6675417 (Extended)]
Supplies & Equipment | System on Module (SoM) [Motherboard] | Hardware Design | Dual N-Channel Power MOSFET [JLCPCB Part C700968 (Extended)] |  | 4
Supplies & Equipment | System on Module (SoM) [Motherboard] | Hardware Design | Li-ion Battery Charger IC [JLCPCB Part C725790 (Extended)]
Supplies & Equipment | System on Module (SoM) [Motherboard] | Hardware Design | ESD Surge Protection Chip [JLCPCB Part C7420376 (Extended)]
Supplies & Equipment | System on Module (SoM) [Motherboard] | Hardware Design | 3 A, 40 V Schottky Diode [JLCPCB Part C7502709 (Extended)]
Supplies & Equipment | System on Module (SoM) [Motherboard] | Hardware Design | XILINX Zynq-7000 System-on-Chip (SoC) [JLCPCB Part C89055 (Extended)]

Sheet: Brainstorming for Actual Budget
Milestone 1
Type | Description | Qty |  |  | Budgeted |  | Key
Supplies & Equipment | Liquid Crystal Display (LCD) Display Module | 2 | $30.00 | $36.00 | $51.00 |  | Type | What is the money being used for?
Supplies & Equipment | Near Field Communication (NFC) Controller | 2 | $60.00 | $72.00 | $102.00 |  |  | 4 categories:
Supplies & Equipment | System on Chips (SoC) | 2 | $240.00 | $288.00 | $288.00 |  |  | Stipend
Supplies & Equipment | Memory Chip | 2 | $28.00 | $33.60 | $47.60 |  |  | Supplies & Equipment
Supplies & Equipment | Radio Frequency (RF) Chip | 2 | $7.00 | $8.40 | $11.90 |  |  | Travel
Supplies & Equipment | FPGA Development Board | 4 | $520.00 | $572.00 | $572.00 |  |  | Other
Supplies & Equipment | Battery | 2 | $30.00 | $36.00 | $51.00 |  | Description | Who is receiving the stipend? What is the equipment you are purchasing? What is the travel expenditure?
Supplies & Equipment | Connectors (Audio Jacks, USB-C, Micro SD, HDMI) | 4 | $20.00 | $28.00 | $38.00
Supplies & Equipment | Microphone | 2 | $10.00 | $12.00 | $22.00
Supplies & Equipment | PCB Manufacturer | 1 | $700.00 | $800.00 | $800.00
Supplies & Equipment | Copper Heat Pipes and Spreader | 1 | $60.00 | $67.00 | $67.00
Supplies & Equipment | Thermal Pads and Paste | 1 | $40.00 | $44.00 | $50.00
Supplies & Equipment | Camera Module | 4 | $30.00 | $42.00 | $42.00 |  | Qty | Quantity
Supplies & Equipment | Miscellaneous Components (Capacitors, Resistors, etc.) | 1 | $200.00 | $240.00 | $210.00 |  | Budgeted | Amount you are budgeting for
Supplies & Equipment | ESP-32 Modules | 10 | $55.00 | $65.00 | $80.00
 |  | Total |  |  | $2432.50 |  | IF YOU DON"T PUT LINKS I WILL MURK YOU
Milestone 2
Type | Description | Qty |  |  | Budgeted
Stipends | PCB Manufacturer | 1 | $700.00 | $800.00 | $800.00
Supplies & Equipment | Heat Gun | 1 | $150.00 | $165.00 | $165.00
Suplies & Equipment | USB/Cable Tester (https://www.amazon.com/gp/product/B08JKN4PL5/ref=ox_sc_saved_title_4?smid=ANGHDKZZ80XV6&th=1) | 1 | $79.99 | $90.00 | $120.00
Suplies & Equipment | Multimeter and Clamp Meter Kit (https://www.amazon.com/gp/product/B00DTSLWRA/ref=ox_sc_saved_title_3?smid=ATVPDKIKX0DER&psc=1) | 1 | $384.93 | $400.00 | $420.00
Suplies & Equipment | Hot Plate | 1 | $60.00 | $70.00 | $90.00
Suplies & Equipment | Addiotonal Equipment/Components (Budget Room) | 1 |  |  | $750.00
Supplies & Equipment | Aluminum Phone Frame (Raw Aluminum, Finishing) | 1 | $475.00 | $522.50 | $600.00
 |  | Total |  |  | $2945.00
Milestone 3
Type | Description | Qty | Material Cost | Tax + Shipping | Budgeted
Stipends | Project Manager Stipend |  |  |  | $1872.50
Stipends | Team Members Stipend (Tentative) [Extra Room in Budget]
 |  |  |  |  |  |  |  | $750.00
 |  | Total |  | $3345.50 | $1872.50
TOTALS
How many student team members do you have? |  | 10 |  |  | Milestone 1
Allotted Budget |  | $8000.00 |  |  | Total | $2432.50
 |  |  |  |  | Milestone 2
 |  |  |  |  | Total | $2945.00
 |  |  |  |  | Milestone 3
 |  |  |  |  | Total | $1872.50
 |  |  |  |  | Entire Project
 |  |  |  |  | Total | $7250.00
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

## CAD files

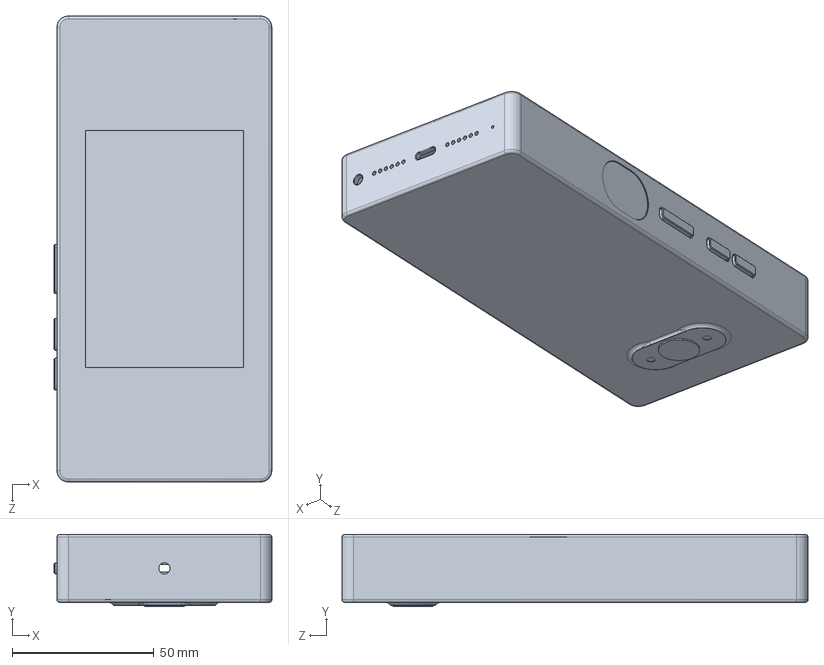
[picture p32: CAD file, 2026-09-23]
subsystems/mechanical-thermal/source/Logan Smartphone Enclosure Design 1.SLDPRT
76.7 x 25.5 x 164.1 mm

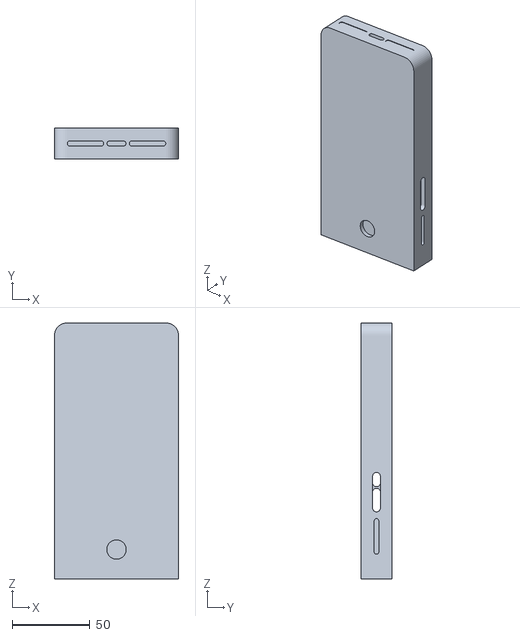
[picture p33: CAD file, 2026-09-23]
subsystems/mechanical-thermal/source/Russell's Phone Frame Design 1.STL
80.0 x 20.0 x 165.1

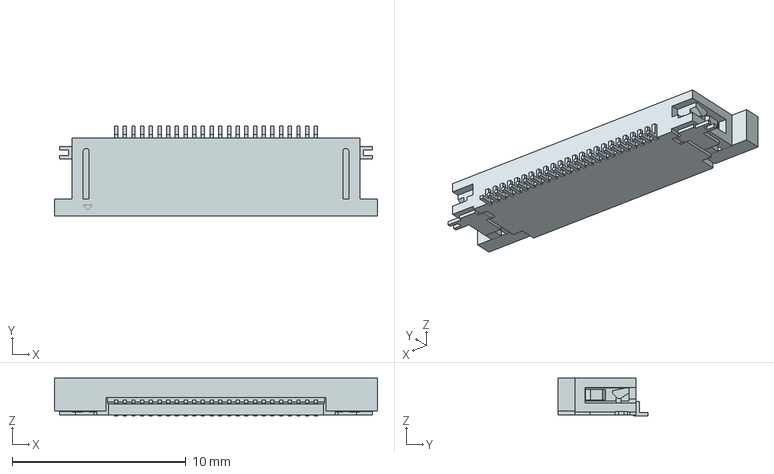
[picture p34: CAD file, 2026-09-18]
subsystems/fpga-mainboard/source/Peripheral-Board-master/Imports/524372472/524372472.stp
18.6 x 5.20 x 2.16 mm

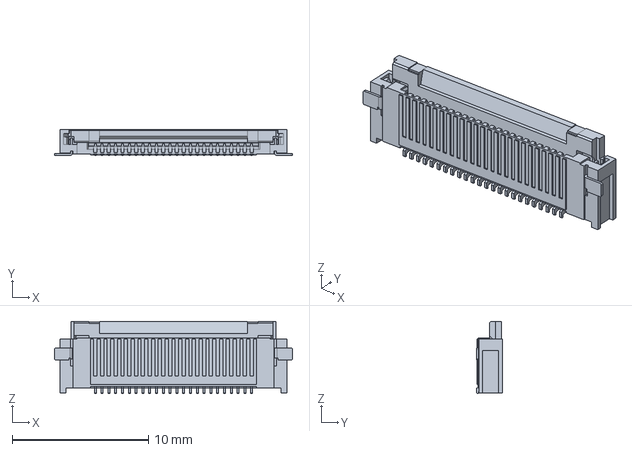
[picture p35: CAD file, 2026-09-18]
subsystems/fpga-mainboard/source/Peripheral-Board-master/STP/5051102491.stp
17.5 x 1.90 x 5.30 mm

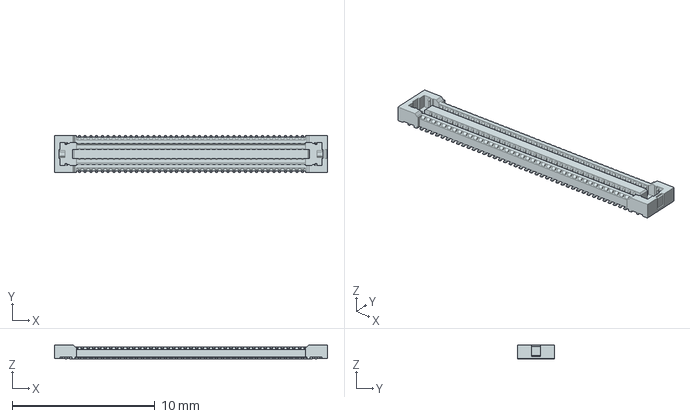
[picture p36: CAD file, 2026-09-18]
subsystems/fpga-mainboard/source/Peripheral-Board-master/STP/5024268012.stp
19.1 x 2.60 x 1.00 mm

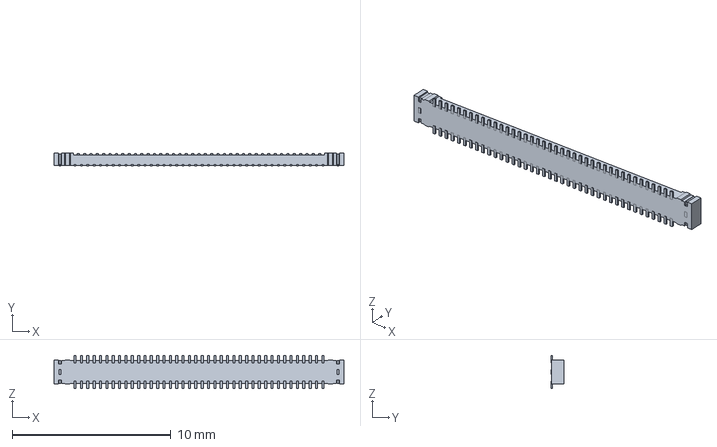
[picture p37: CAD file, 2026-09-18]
subsystems/fpga-mainboard/source/Peripheral-Board-master/STP/5024308012.stp
18.3 x 0.8 x 2.08 mm

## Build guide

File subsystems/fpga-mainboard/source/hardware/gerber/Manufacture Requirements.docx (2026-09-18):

# PCB工艺要求

层数：6

制作数量(拼板后)：20 pcs

最小线距 4mil；最小线宽 4mil

最小钻孔 0.2mm/0.4mm

钻孔类型：通孔

钻空孔处理方式：树脂塞孔表面镀平

孔壁铜厚：满足IPC 2级标准(min 18um; typ 20um)

表面处理：沉金

阻焊颜色：黑色亚光

丝印颜色：默认(白色)

阻焊桥处理：厂家根据实际加工能力可以不做小于工艺能力的阻焊桥，需要在工程确认时对光绘文件改动进行确认。

PCB尺寸（拼板后）：75.3mm×94.2mm

测试

四线过孔测试，飞针测试，通断测试等常规测试

提供出货报告

公差

板厚公差：±10%

板外形公差：±0.1mm

翘曲度（整版，以对角线参考）：≤1%

设计文件格式：Gerber文件

Gerber文件板层顺序和层压结构：

Gerber文件名 | 层功能描述/板材 | 厚度
xxx_Edge_Cuts.gbr | 工艺层:PCB外框
xxx_F_Silkscreen.gbr | 工艺层:顶层丝印 | | 3，4
xxx_F_Mask.gbr | 工艺层:顶层阻焊层掩膜 | 约1mil
xxx_F_Cu.gbr | 顶层铜层 | 1Oz | 完成铜厚>35um
Prepreg | 介质层/FR4 | 0.1mm | 1, 2
xxx_In1_Cu.gbr | 内部铜层 | 1Oz
Core | 介质层/FR4 | 0.2mm | 1, 2
xxx_In2_Cu.gbr | 内部铜层 | 1Oz
Prepreg | 介质层/FR4 | 0.127 | 1, 2
xxx_In3_Cu.gbr | 内部铜层 | 1Oz
Core | 介质层/FR4 | 0.2mm | 1, 2
xxx_In4_Cu.gbr | 内部铜层 | 1Oz
Prepreg | 介质层/FR4 | 0.1mm | 1, 2
xxx_B_Cu.gbr | 底层铜层 | 1Oz | 完成铜厚>35um
xxx_B_Mask.gbr | 工艺层:底层阻焊层掩膜 | 约1mil
xxx_B_Silkscreen.gbr | 工艺层:底层丝印 | | 3，4
总厚度 | | 1mm

1. 实际层压可以根据工艺微调，并在工程确认中反馈
2. 需要在工程确认中确认实际使用板材种类
3. 请勿在丝印层上添加厂家丝印，客编等源Gerber中没有的图形
4. 如果有丝印层和阻焊层开窗冲突的，去除冲突部分丝印层图案

钻孔文件：

xxx_NPTH.drl – NPTH钻孔

xxx_PTH.drl – PTH钻孔

xxx_NPTH_map.ps – NPTH钻孔描述

xxx_PTH_map.ps – PTH钻孔描述

钢网使用无边框钢片，将拼板后正反面（B_Paste层，F_Paste层）拼在同一张钢网上

钢网文件：

xxx_B_Paste - 底层钢网

xxx_F_Paste - 顶层钢网

拼板：

Gerber文件需要按板框标识层进行拼板，每4个单元板构成一个拼板。

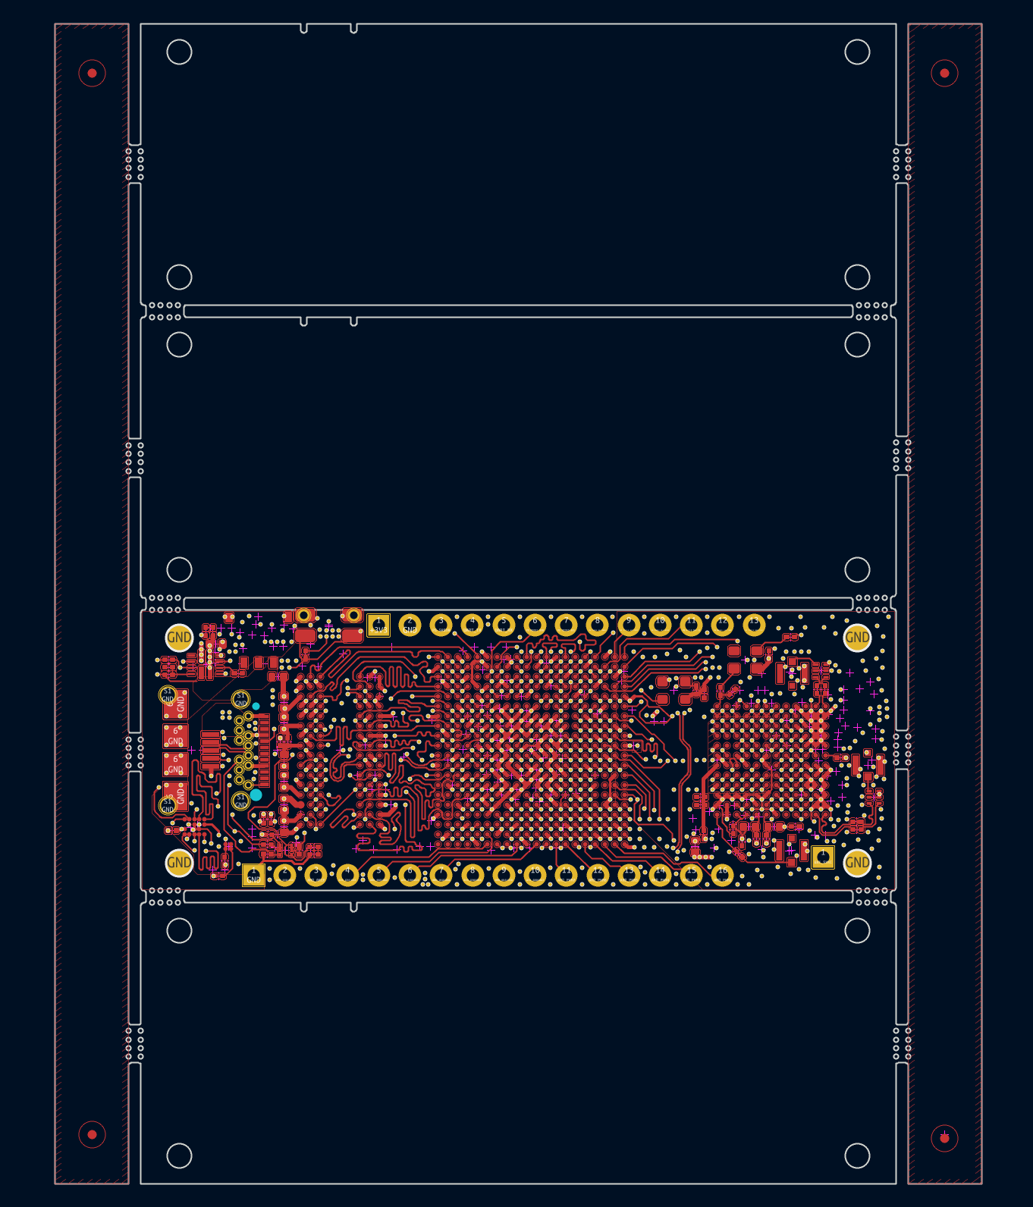
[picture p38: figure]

备注：

接受拼板打叉板，但需要按子板单元总数满足数量要求

需要工程/光绘确认完毕后再开料生产

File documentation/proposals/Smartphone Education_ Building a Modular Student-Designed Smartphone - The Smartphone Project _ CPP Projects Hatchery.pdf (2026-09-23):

# Smartphone Education: Building a Modular Student-Designed Smartphone

Sunny Nguyen, Russell Chung, Viren Kumar, Boi Hoanh Lam, Andy Zhang, Izaiah Ortiz, Nathan Alquicira, Angelo Duenas, and Chris Zambrana

A Project Proposal for the Learn Through Discovery Projects Hatchery at California State Polytechnic University Pomona

Faculty Mentor: Dr. Mohamed El Hadedy, Department of Electrical & Computer Engineering

### Project Summary

The Smartphone Project reimagines mobile technology by addressing key issues in user control, sustainability, and accessibility. In a world dominated by proprietary systems and closed ecosystems, our initiative introduces a fully modular, repairable smartphone platform designed from scratch by students. Our target audience includes students, open-source advocates, and tech enthusiasts who seek greater ownership over their devices and want to challenge the norms of mainstream design.

At its core, this project is an educational tool — a means of lowering the barrier to entry for students interested in hardware-software integration, systems design, and mobile technology. Using field-programmable gate arrays (FPGAs), open-source tools like KiCad, and modular component architecture (e.g., RAM, SD, RF modules), students will engage directly in the engineering of a fully functioning smartphone. From processor development and thermal management to PCB layout and Linux-based OS integration, this hands-on experience provides exposure to real-world engineering challenges that are often inaccessible in traditional classroom settings.

The Smartphone Project fills a significant gap in current engineering education. While automotive programs like FSAE provide pipelines for student-led development in the automotive industry, no comparable structure exists for the computer sector — despite its prevalence in everyday life and industry. Our project aims to build that pipeline, offering students a unique opportunity to gain interdisciplinary experience in one of the world’s most influential technologies.

Unlike existing open-source phone initiatives that often compromise on usability or accessibility, our focus is on creating a product that is both functional and open — a balance that allows us to educate and inspire a broader, more diverse student community. This approach promotes sustainability through upgradability and repairability, reduces e-waste, and fosters a culture of ethical, transparent design.

Ultimately, this project is more than a device. It’s a platform for student-driven innovation — one that empowers students to rethink what technology can be and who gets to build it.

### Project Background and Solution

Despite the smartphone’s ubiquity in daily life and its central role in today’s tech industry, hands-on smartphone development is virtually absent in engineering education nationwide. While many universities offer project-based programs in automotive, aerospace, and robotics engineering — such as Formula SAE and CubeSat teams — few, if any, student-led groups or academic programs tackle embedded mobile systems at the hardware level. This is a striking absence, considering how essential smartphones have become in global markets, innovation, and daily life.

Organizations like IEEE provide value through networking and smaller technical workshops, but their focus often leans toward communications and signal processing, rather than immersive, system-level design challenges like smartphone architecture or PCB integration (IEEE, 2024). Their projects also tend to be beginner-friendly and less interdisciplinary, lacking the depth required to meaningfully prepare students for real-world systems engineering.

This gap is part of a broader issue in engineering education: the lack of large-scale, real-world interdisciplinary learning opportunities. As Kang and Liang (2024) note in their analysis of electrical and electronic engineering instruction, “There is a pressing need to incorporate real-world industry cases and hands-on project experience to help students better apply knowledge” (p. 1). Without such frameworks, students rarely have the opportunity to engage in multi-subsystem design, collaborative development, or systems integration — the skills that drive innovation in today’s most advanced technologies.

Even at Cal Poly Pomona, a campus known for its "learn by doing" philosophy, the gap is visible. While clubs like BroncoSpace, UMBRA, and Liquid Rocket Lab offer exceptional experiences in aerospace and mechanical engineering, students in Computer Engineering (CE), Electronic Systems Engineering Technology (ESET), Electromechanical Systems Engineering Technology (EMSET), and Electrical Engineering (EE) have few avenues for applied electronics and hardware-software co-design. Together, these majors account for over one-third of the entire engineering student population (CPP Institutional Research, 2023).

The Smartphone Project directly addresses this gap by offering a replicable model for interdisciplinary learning, centered on one of the most influential consumer technologies of the 21st century. Through this Hatchery-supported initiative, students build an FPGA-based smartphone from scratch — including its SoC logic, power systems, thermal management, RF communication, and Linux-based OS integration. More than just an engineering challenge, the project serves as an educational platform where students across subfields collaborate, experiment, and learn from failure.

Beyond education, the project responds to a broader critique of modern smartphone design — namely, that closed ecosystems, soldered components, and anti-repair policies have made devices less transparent, less upgradable, and harder to understand. For instance, iFixit’s analysis of the iPhone 15 Pro Max highlights how even small repairability gains are undercut by restrictive part-pairing software, earning the device a provisional score of 4/10 for repairability (iFixit, 2023). This philosophy encourages waste and prevents users — and students — from learning how these systems actually work.

Our project stands in contrast not only because it will be designed as a response to industry shortcomings, but also as a proof-of-concept for a new kind of engineering education. Unlike the proprietary chipsets produced by Apple, Qualcomm, or Samsung, FPGAs offer a blank, reprogrammable canvas — capable of acting as a processor, accelerator, or custom logic unit, depending on how it is configured. This reconfigurability opens the door to truly modular hardware, where components can be upgraded, replaced, or redefined in software without scrapping the entire device.

By tackling both the educational gap and the design limitations of modern smartphones, the Smartphone Project aims to offer a replicable, scalable model for interdisciplinary engineering and offer a blueprint for other campuses. One that is inclusive, forward-thinking, and capable of reshaping how students engage with one of the most important technologies of the 21st century.

### Objectives, Timeline, and Goals

The primary goal of the Smartphone Project is to design and prototype a fully modular, reconfigurable smartphone built by students, using field-programmable gate arrays (FPGAs), open-source tools, and custom-built subsystems. This initiative serves as both an educational platform and a demonstration of engineering capability. Through interdisciplinary collaboration, our goal is not only to develop a functioning device, but to create a sustainable foundation for future students to continue work on advanced mobile systems.

Our progress will be structured around six core technical phases, with defined deliverables at each step. These are aligned with funding milestones to ensure accountability and progress visibility:

Project Phases

Phase 1: Initial Planning and Documentation

In this phase, all teams define the specifications of their subsystems. The SoC team outlines the logic for CPU, GPU, and memory hierarchy. Hardware develops component selections and PCB interface definitions. RF outlines DSP and wireless system goals. The Enclosure team begins early CAD layouts. The Systems team ensures that documentation (use cases, requirements, and diagrams) align across subsystems.

Deliverables: Consolidated technical specification documents and architecture diagrams.

Phase 2: Subsystem Design and Simulation

Each team produces detailed subsystem designs. The SoC team models their logic blocks using Verilog and runs testbenches. Hardware simulates PCB behavior for signal integrity and power management. RF simulates frequency behavior and DSP logic. Enclosure finalizes thermals and spatial constraints.

Deliverables: Simulated subsystem models, refined schematics, and updated documentation.

Phase 3: Collaboration and Prototyping

This is our first major funding milestone and includes early prototyping and cross-team integration. SoC logic is implemented on FPGA dev boards. Hardware fabricates test PCBs. Enclosure produces 3D-printed prototypes. RF integrates antennas with FPGA logic. Teams validate interconnects and begin integration testing.

Deliverables: First-generation hardware prototypes, component alignment confirmation, and integration planning document.

Phase 4: Driver and Software Development

With hardware prototypes in hand, this phase begins full firmware and software development. SoC teams write drivers for memory and GPU modules. RF and Enclosure teams work on runtime monitoring (signal and thermal). The Systems team builds interface logic and startup sequences.

Deliverables: Driver suite and diagnostic tools capable of validating each subsystem independently.

Phase 5: System Integration and Final Testing

This is our second funding milestone, where we combine all systems into a working prototype. SoC and Hardware teams validate end-to-end processing. RF tests full communications functionality. Enclosure is tested under thermal load. The Systems team runs full-stack performance, thermal, and RF tests.

Deliverables: Fully integrated prototype that performs at least one real-world task, such as basic imaging or ML inference.

Phase 6: Final Review, Documentation, and Handof

This is our final funding milestone. All teams will finalize documentation, generate onboarding material, and ensure reproducibility of the work. The SoC team wraps HDL, Hardware finalizes PCBs, RF documents DSP, and the Systems team assembles technical reports and test logs.

Deliverables: A full documentation package, final presentation, and knowledge transfer materials for new members.

Throughout this project, we will use our general meetings, demos, and Git-based repositories to showcase progress and disseminate our work to the broader tech community. Our goal is to release open-source documentation and design files via GitHub, along with blog-style updates through our website and social media.

A project timeline in the form of a Gantt chart is attached below and outlines all major milestones, and overall timeline up through the project’s final review in August while trying not to clutter with too much information because each team has up to 30 subtasks each.

### SMART Goals

Specific

Our team wants to build a smartphone from scratch that is comfortable to hold, intuitive to use, powerful enough to maintain strong performance, efficient enough to endure a whole day of extensive use, speedy enough to feel snappy and responsive, and versatile enough to serve as a foundation for future innovations while maintaining a clear focus on delivering exceptional core functionality in our first release.

Measurements for Success

User Defined in a Poll: “Comfortability to Hold”, “Intuitive to Use”, and “Speedy Enough to Feel Snappy and Responsive”

“Powerful enough to maintain strong performance” - Clock Speed, Voltage Regulation Test, Bandwidth, Power-Efficiency (Performance Per Watt)

“Efficient enough to endure a whole day of extensive use” - “Screen On Time”, “Real World Testing”, “Battery Capacity (mAh)”, “Battery Discharge Rate (mA)”, “Energy Efficiency Ratio (EER)”, “Component Power Draw”

Attainability

We have the fundamental knowledge necessary to build a smartphone from scratch with the qualities we listed in our goals. With that said, we may run into more sophisticated and technical road bumps in our project. In such cases, we have multiple avenues to address the situation including using Hatchery advisors/mentors and CPP Faculty, Textbooks, and Github.

Relevant

Yes. The overarching goals of our organization is to make learning the process of building a smartphone more frictionless. That starts with us being able to build a smartphone from scratch and proving that we can do it ourselves.

Time-Bound

Concept & Planning (Nov - Jan): Define project scope, secure funding, and conduct requirements analysis for all subteams.

Design & Procurement (Jan - March): Perform trade studies, finalize material selection, and develop initial design concepts. Begin purchasing components.

Development & Prototyping (March - May): Each subteam develops and integrates their respective systems, followed by system-wide testing.

Testing & Refinement (May - June): Perform electrical, RF, software, and thermal testing. Address risks and finalize design.

Finalization & Review (June - July): Conduct product readiness review and final design verification (CDR).

### Personnel / Team Members

Sunny Nguyen
Role: Chief Technical Officer (CTO)

Responsibilities: Oversees the entire project, ensuring milestones and deadlines are met. Coordinates teams, manages resources, and communicates with stakeholders. Offers technical support and leads meetings, progress tracking, and quality assurance.

Qualifications: Designed the Celesti-Call Phone. Led engineering teams in rocket projects and CubeSats. Experienced in KiCad PCB design.

Chris Zambrana
Role: Project Manager

Responsibilities: Oversees the entire project, ensuring milestones and deadlines are met. Coordinates teams, manages resources, and communicates with stakeholders. Offers technical support and leads meetings, progress tracking, and quality assurance.

Qualifications: Designed a SoC on a FPGA with a Memory Mapped Input-Output Subsystem and Video subsystem. Knowledge in Computer Architecture and Operating Systems and Experienced in Digital Design Using HDL

Russell Chung
Role: Business Coordinator and Engineering Manager

Responsibilities: Leads proposal writing, funding applications, and sponsorship outreach. Manages project planning, including Gantt chart creation, timeline tracking, and deliverable coordination. Oversees budgeting, resource allocation, and milestone progress. Supervises engineering activities across subteams (Hardware, SoC, RF, Enclosure, etc.) and works with Systems Engineers to ensure cross-team interface compatibility. Organizes and leads weekly lead meetings while maintaining alignment across disciplines. Supports all teams by developing and running curriculum programs to boost team knowledge and repackage technical material for practical use. Manages external communication, student onboarding, and internal accountability to keep the team focused and on track.

Qualifications: Lead Successful Project Teams (Robotics, Outreach Organization Activities, Baseball). Experienced in technical writing, budget management, team management, and scalable curriculum development for hardware-software systems.

Max Gross
Role: Hardware Designer

Responsibilities: Designs and develops physical components, schematics, component selection, and PCB layout. Ensures integration with other subsystems and meets performance specs.

Qualifications: Designed radiation-testing PCB used at Lawrence Berkeley National Lab. Developed microcontroller ethernet at Astranis Space Corp. Led SUAS obstacle avoidance system.

Hoanh Lam
Role: System Engineer Lead

Responsibilities: Oversees hardware/software integration. Coordinates architecture definition, system testing, and optimization across subsystems.

Qualifications: Led CubeSat team in BLADE program. Northrop Grumman system engineering collaborator.

Nathan Alquicira
Role: System Engineer

Responsibilities: Supports integration and architecture. Shadows team members and assists in debugging and cross-functional collaboration.

Qualifications: Mentored robotics team. Experience with Metrolink PTC hardware/software issue management.

Viren Kumar
Role: Enclosure Engineer

Responsibilities: Designs the phone casing for structure and thermal performance. Collaborates with hardware team for spatial integration.

Qualifications: Experience in CAD and thermal considerations.

Danny Tran
Role: Back-end Developer

Responsibilities: Develops server-side software, APIs, and backend infrastructure. Supports embedded integration and system-level software optimization.

Qualifications: Developed Gemini API chatbot. IT technician with hardware/software debugging experience.

Izaiah Ortiz
Role: Front-end Developer

Responsibilities: Designs UI/UX for the OS and applications. Ensures responsiveness, aesthetics, and functionality across devices.

Qualifications: Experience in user interface development and cross-team collaboration.

Andy Zhang
Role: System-on-a-Chip Lead

Responsibilities: Leads SoC team. Develops FPGA-based drivers and HDL IPs. Coordinates with RF and hardware teams for integration and testing.

Qualifications: 8 years programming. Experience in HDL, drivers, reverse engineering, TCP/IP, and digital logic

### Budget and Justification

Milestone 1: Design & Component Acquisition — Total: $2,432.50
- This milestone funds the foundational components required to initiate design and early prototyping across all subsystems. This includes the procurement of FPGA development boards (for SoC logic testing), SoC and memory chips, early RF modules, camera modules, and power system components. Passive components and connectors are essential to create functional subsystems, while tools like microphones and LCDs are necessary for developing the phone’s interactive features.

A portion of this milestone also supports our first round of PCB manufacturing, which enables the Hardware and SoC teams to move beyond simulation and validate physical designs. Thermal materials (pads, spreaders) are included to prepare for future integration and allow for realistic testing conditions even in early stages. These purchases ensure that all teams can begin work concurrently and avoid bottlenecks from shared hardware.
- Liquid Crystal Display (LCD) Display Module (Qty: 2) — $51.00

→ Explanation: Used to prototype and test the graphical interface, allowing for development and debugging of the user interface system.

- Near Field Communication (NFC) Controller (Qty: 2) — $102.00

→ Explanation: Enables wireless communication capabilities such as tap-to-pay and data transfer, showing our modular extensibility.

- System-on-Chips (SoC) (Qty: 2) — $288.00

→ Explanation: Core processing element for running basic logic, including CPU and GPU operations — critical to SoC development and integration.

- Memory Chips (Qty: 2) — $47.60

→ Explanation: Provides volatile and non-volatile memory support for software execution and application data storage.

- Radio Frequency (RF) Chip (Qty: 2) — $11.90

→ Explanation: Supports wireless communication simulation and prototyping, essential for long-range data transmission.

- FPGA Development Board (Qty: 4) — $572.00

→ Explanation: Serves as the backbone for logic development, including SoC prototyping and GPU compute core design.

- Battery (Qty: 2) — $51.00

→ Explanation: Provides power delivery testing for the phone during prototyping, enabling full-device integration validation.

- Connectors (Audio Jacks, USB-C, Micro SD, HDMI) (Qty: 4) — $38.00

→ Explanation: Interfaces external peripherals with internal logic, testing expandability and port access.

- Microphone (Qty: 2) — $22.00

→ Explanation: Enables sound input testing and interface for voice and multimedia applications.

- PCB Manufacturer (Qty: 1) — $800.00

→ Explanation: Used for creating custom printed circuit boards, necessary to verify real-world circuit integration and connections.

- Copper Heat Pipes and Spreader (Qty: 1) — $67.00

→ Explanation: Enables thermal dissipation validation for critical power-intensive components, ensuring system stability.

- Thermal Pads and Paste (Qty: 1) — $50.00

→ Explanation: Facilitates heat transfer between components and cooling systems for realistic stress tests.

- Camera Module (Qty: 4) — $42.00

→ Explanation: Tests multimedia functionality and interface with image signal processing on the SoC.

- Miscellaneous Components (Qty: 1) — $210.00

→ Explanation: Includes resistors, capacitors, and supporting elements necessary for various hardware subsystems.

- ESP-32 Modules (Qty: 10) — $80.00

→ Explanation: Used for auxiliary processing, wireless comms, and prototyping of control interfaces.

Milestone 2: Tooling and Frame Construction — Total: $2,945.00
- This milestone supports system-wide development by funding essential fabrication and diagnostic equipment, enabling us to assemble, modify, and test components as designs evolve. Tools like heat guns, hot plates, cable testers, and clamp meters are critical to soldering and verifying high-density interconnects in our boards.

This phase also includes materials for the phone’s first physical enclosure, machined from aluminum, which allows us to test thermals, fit, and user ergonomics. A second PCB manufacturing stipend is allocated for revised boards based on feedback from

Milestone 1. Additionally, we’ve included a buffer for unexpected equipment or component needs to prevent timeline disruptions during rapid prototyping and testing.
- PCB Manufacturer (Stipend) — $800.00
- Heat Gun (Qty: 1) — $165.00

→ Explanation: Essential for safely reworking and assembling surface-mount components during board fabrication.

- USB/Cable Tester (Qty: 1) — $120.00

→ Explanation: Tests integrity and throughput of USB and data ports, validating connectivity across modules.

- Multimeter and Clamp Meter Kit (Qty: 1) — $420.00

→ Explanation: Provides voltage, resistance, and current measurement across subsystems for power and signal diagnostics.

- Hot Plate (Qty: 1) — $90.00

→ Explanation: Used for thermal soldering tasks and batch surface-mount work, critical during rapid iteration.

- Additional Equipment/Components — $750.00

→ Explanation: Buffer for unplanned purchases, revisions, or expansion modules across all teams.

- Aluminum Phone Frame (Raw Aluminum + Finishing) (Qty: 1) — $600.00

→ Explanation: Physical housing to test form factor, thermal behavior, and user ergonomics for prototype deployment.

Milestone 3: Final Integration + Team Compensation — Total: $1,872.50
- The final phase supports the full system integration and team coordination needed to deliver a working prototype. A stipend is allocated for the Project Manager who has led project coordination, risk mitigation, documentation, and cross-team synchronization throughout the project. An additional flexible stipend is budgeted for key contributors who go above and beyond during integration, validation, and final handoff.
- Project Manager Stipend — $1,872.50

→ Explanation: Funds the coordination and integration
responsibilities of the PM, who ensures progress across all deliverables.

- Team Member Stipend (Tentative) — TBD

→ Explanation: Reserved for contributors going beyond baseline effort, especially in critical integration phases.

- Total Project Budget: $7,250.00

### References

CPP Institutional Research. (2023). Fall 2023 Enrollment Data via Tableau. California State Polytechnic University, Pomona. Retrieved from https://www.cpp.edu/data/dashboards/fall-term-characteristics.shtml

iFixit. (2023). iPhone 15 Pro Max Teardown and Repairability Score. Retrieved from https://www.ifixit.com/News/82867/iphone-15-teardown-reveals-software-lockdown

IEEE. (2024). IEEE Membership Benefits and Opportunities. Retrieved from https://www.ieee.org/membership/benefits/index.html

Kang, Y., & Liang, M. (2024). The Challenges in Electrical and Electronic Technology Courses in Vocational Colleges. Journal of Contemporary Educational Research, 8(5), 1–9. https://doi.org/10.26689/jcer.v8i5.7005

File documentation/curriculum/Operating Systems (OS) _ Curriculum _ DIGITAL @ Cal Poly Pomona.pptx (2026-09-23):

## The Operating Systems Curriculum

[Loading...]

20xx

</

} /> [

/>

By DIGITAL

## Commentary

Dear Future OS Members,
Most, if not all, of the code shown in this curriculum is pseudocode or Jack language meant to simplify the explanation of how operating systems work. Your operating systems are more complex and require the relevant libraries, function calls, subroutines, and recognized commands in their respective language. Conduct research on the intricacies of your chosen language when writing your code.
Sincerely,
- The OS Team

## Directory

Concept of Memory | Slide 3
Segmentation
Memory Virtualization
Optimization
Virtual Machine | Slide 30
Quick Compiler Intro
Stack Machine
VM Emulator
Branching Commands
Function Commands
Compiler | Slide 60
Writing a Compiler
Syntax Analyzer
Lexical Analysis
Grammars

Parsing
Code Generator
Procedural Code
Handling Objects
Handling Arrays
Standard Virtual Machine Mapping
Operating System | Slide 103
Efficiency
Memory Access
Heap Management
Graphics
Textual Output
Input
String Processing
Array Representation
The Sys Class

## Concept 01

Pitch Deck

20xx

</>

} /> [

## Concept of Memory

Pitch Deck

20xx

Stored Data

</

} /> [

/>

## What is Memory?

The part of a computer that provides temporary storage for data and instructions that the CPU needs to access quickly.
Memory is necessary for computers to load the operating system, perform all functions, and run computer processes.

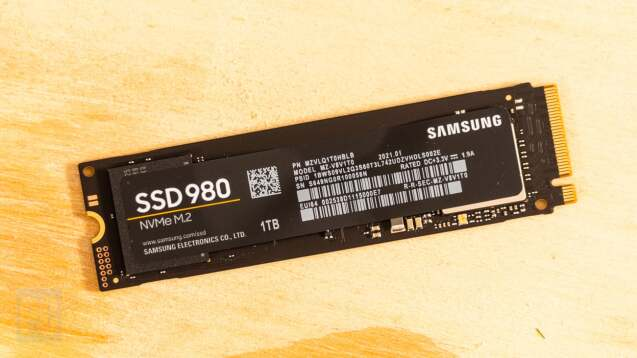
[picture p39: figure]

## How is Memory Stored?

Bit Registers
Small, very fast storage location inside a CPU. It is made of flip-flops, each of which can hold 1 bit of information (a 0 or a 1)
Clock inputs determine the state of the register, such as when it is time to store data or send/release data.
Multi-Bit Registers
Combined, these registers can store binary code, which allows devices to send more intricate signals during communication.

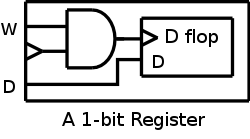
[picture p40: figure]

## Types of Memory Storage

Primary - faster memory recall, but much lower in capacity
- Random Access Memory (RAM)
  - Temporarily holds data and instructions that the CPU is currently using
  - Volatile memory (loses data when power is off)
- Read-Only Memory (ROM)
  - Stores permanent instructions needed to start the computer
  - Non-volatile memory (does not lose data when power is off)
Secondary - slower than primary, but much larger in capacity
- Hard Drive (HDD)
- Solid-State Drive (SSD)
- Universal Serial Bus (USB) Flash Drive
- Compact Disc (CD)
Two other types of memory we will cover: Cache & Virtual

## Segmentation

Pitch Deck

20xx

Memory Management Schemes

</

} /> [

/>

## What is Segmentation?

A memory management scheme where a process’s memory is divided into variable-sized segments.
Each segment is defined by a base address (beginning of segment) and a size (limit of segment).
Virtual Address = A segment number (id of segment you want to access) + offset (where in the segment we want to access)

## Types of Segmentation

Code - Executable instructions of a program
Data - Global and static variables
Heap - Used for dynamically allocated memory (grows upward)
Stack - Used for function call management such as local variables, return addresses, and function parameters (grows downward)

## How Does Segmentation Work?

Segments are separated in a segment table. The segment table maps virtual segment to their corresponding physical segment.
Steps:
1. MMU uses segment table to look up base address and size of physical segment desired
2. MMU checks whether offset is within the segment’s limit
If Valid:
Physical Address = Base Address + Offset
If Not Valid:
Segmentation Fault Occurs
MMU* - Memory Management Unit
- Links virtual VM addresses to physical RAM addresses
- More to be said later on!

Segment Table

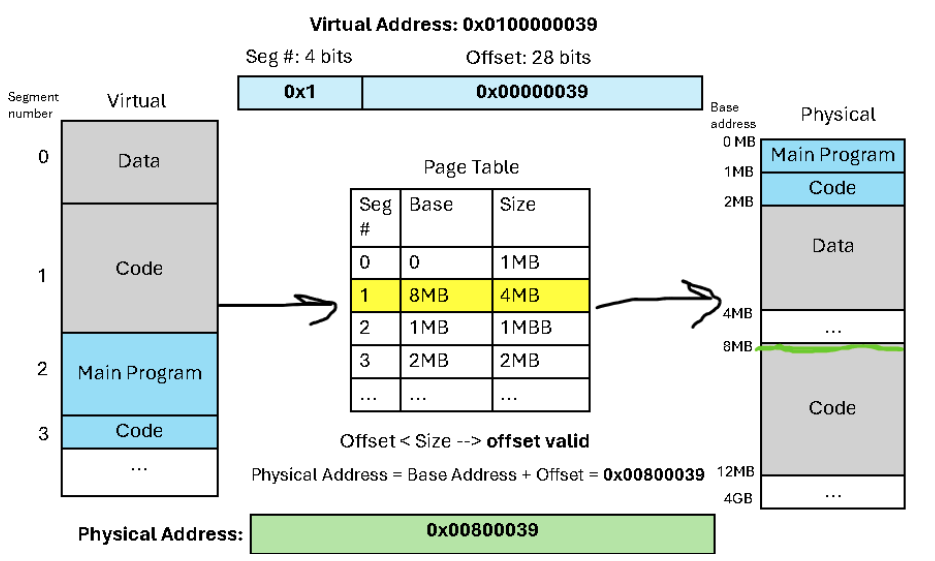
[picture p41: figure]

## Problems with Segmentation

External Fragmentation
When free memory space is broken into small, non-contiguous blocks, there is not enough space for a large, contiguous block.
Complex Allocation
More complex logic is required because the OS has to search for contiguous blocks that are large enough to allocate in RAM, or the OS may even have to reorganize the entire RAM in order to create contiguous blocks of free space.
Limited Growth Flexibility
Even though segments can grow through the stack or heap, it won’t even matter if there isn’t enough space for the segment to expand.
Disk Limitations
Less suitable for utilizing disk storage since this too would be organized in segments and would end up having the same issues as the RAM.

## Memory Problem #1

Insufficient RAM Space
- Users always want more processes + Processes demand more resources from RAM = Never enough RAM

## Memory Problem #2

Memory Fragmentation
- Internal Fragmentation: Allocated memory exceed needed memory; unused space
- External Fragmentation: Free memory is not continuous, but scattered across different bits; Large allocations cannot fit in small space or divide among scattered bits

## Memory Problem #3

Process Security
- Different processes access the same address register, corrupting one another’s data

## Solution

Virtual Memory
- A system that allows processes to behave as if they have a large, continuous block of memory, even if the actual physical memory is small or fragmented.
Memory Protection
- Protection against corrupting and overwriting data
- Efficient Resource Sharing
- Removal of scattered bits and optimizing of space
All of these techniques are handled by the Memory Management Unit (MMU). The operating system (OS) relies on the MMU to perform these actions so that the OS can translate virtual addresses into physical addresses for the computer’s hardware.

## Memory Virtualization

Pitch Deck

20xx

The Concept

</

} /> [

/>

## What is a Memory Management Unit (MMU)?

A crucial component of the CPU that automatically translates virtual memory addresses into physical memory addresses used in the RAM.
- The bridge between software memory and hardware memory
Also controls:
Cache - small, fast memory that stores copies of frequently accessed data
Translation Lookaside Buffer (TLB) - a collection of memory caches that stores the recent translations of virtual memory addresses to physical memory addresses
Page Faults - exceptions which occur when a program tries to access a memory page not present in the RAM

## What is an Operating System (OS)?

A software system that manages computer hardware and software resources.
Main Task:
Allocate Resources
- Memory
- CPU Usage
- Input/Output Devices
- File Storage
- User Accounts

## What does MMU and OS do together?

1. Process Isolation
An OS feature that protects processes from interfering with each other by providing each with its own dedicated memory and execution environment
1. Efficient Memory Use
Minimize wasted computer memory (RAM) to improve overall system performance, resource utilization, and stability
1. Allows Programs to Run Even Without Enough Physical RAM
By using virtual memory, data can be saved on pages and swapped in and out the RAM depending on how often the page is used.

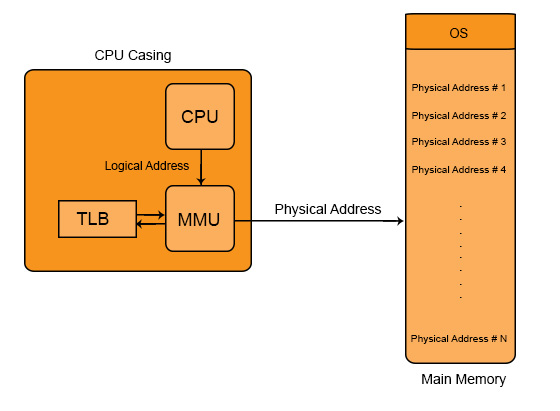
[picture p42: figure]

## Solution

Paging - a memory management scheme that eliminates the need for contiguous memory allocation required with segmentation
Divides both physical and virtual memory into fixed-sized blocks called pages
Effect:
1. Virtual and physical pages are the same size
2. Pages occupy a whole process, multiple processes, or parts of a process depending on size of process

## Page Table

A data structure that holds all the pages and marks each page as their own page table entry (PTE).
The page table is stored physically. The MMU breaks down virtual addresses and uses the page table for address translation.
Flags prevent overwriting data.
Flag Types:
Valid - entry is usable
Dirty - page has been written into

## Combined Implementation of Segmentation & Paging

The virtual address contains these two elements:
Virtual Page Number (VPN) - the page in virtual memory we want to access
Different from the more commonly-known VPN (Virtual Private Network)
Offset - the specific byte we want to access
The physical address contains two elements:
Physical Page Number - indicates page in physical memory we want to access
Offset - the specific byte we want to access (offset remains the same because virtual and physical page size is the same
Process:
1. The MMU gets the PPN by using the VPN to index into the page table, which stores virtual-to-physical page mappings
2. The offset is directly copied from the virtual address to the physical address.

## Optimization

Pitch Deck

20xx

Multi-Level Madness

</

} /> [

/>

## The Drawbacks of Single-Level Paging

1. Extremely large size, which requires a significant amount of physical memory
2. Internal Fragmentation
3. Slower than accessing RAM

## What Does Cache Do?

Problem:
Accessing the page table from RAM after every memory access is both time-consuming and costly.
Solution:
Systems use cache to store recent table page lookups for faster translation

## How Does Multi-Level Paging Help?

1. Allocation Speed
Systems only need to allocate page tables that are actually needed rather than the entire page table
1. Memory Footprint
Systems can move page tables out of the RAM and into the disk to save space if the page table is not actively used

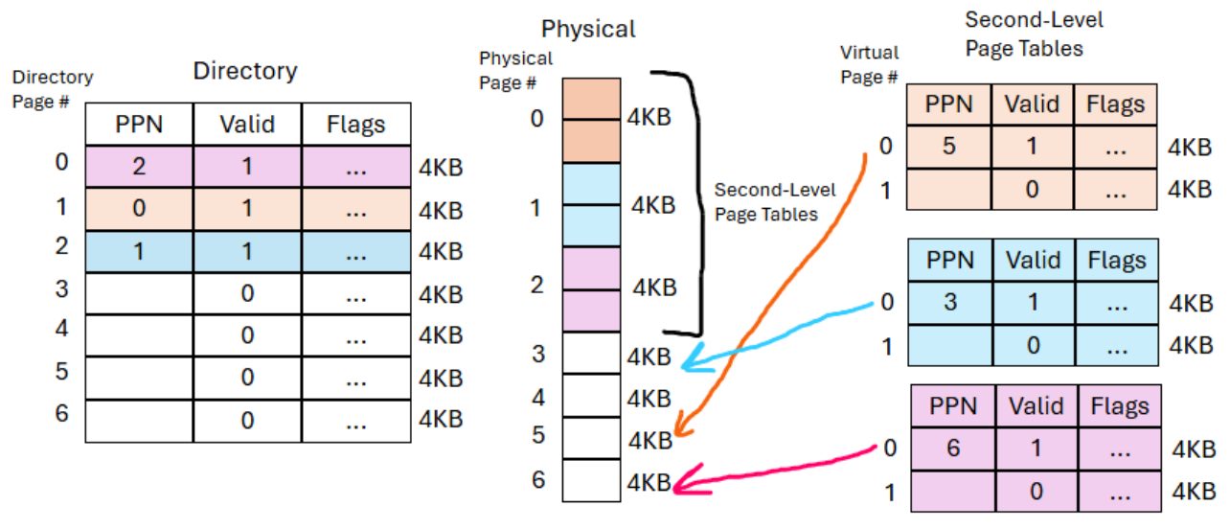
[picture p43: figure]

## End of Meeting #1

[Loading...]

20xx

} /> [

</

Do you have any questions?

/>

Thanks for attending!
- OS Team

## The Operating Systems Curriculum

[Loading...]

20xx

</

} /> [

/>

Pt. 2 | Virtual Machines

## Visualization

Operating System → Compiler → Virtual Machine

## Quick Compiler Intro

Pitch Deck

20xx

Communication Between Human and Computer

</

} /> [

/>

## Compilers

Compilers high-level programming to low-level code
High-Level Programming: Designed specifically to be user-friendly for humans to interpret and understand what is going on
Low-Level Code: Programming languages that are closer to the computer's hardware and provide direct control over its resources

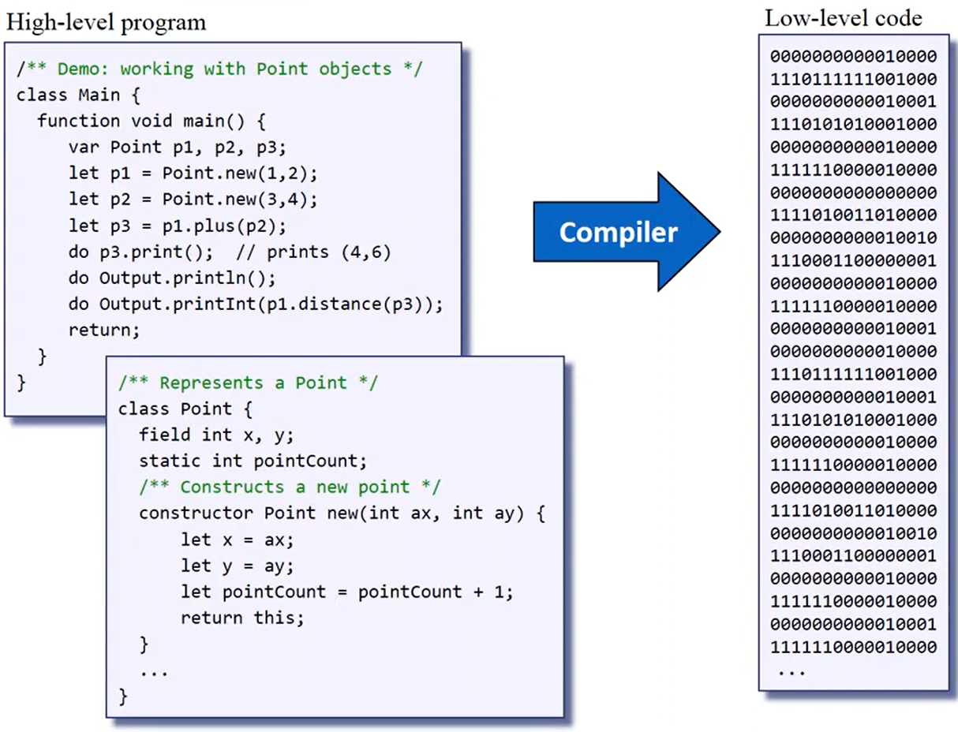
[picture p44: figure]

## Two Implementations

1. Cache
Small, fast memory that stores copies of frequently accessed data to speed up future access
1. Multi-Level Paging
A memory management technique that replaces a single, large page table with a hierarchy of smaller page tables

## Problems with Compilers

Many devices use different processes and machine languages
You are forced to write MULTIPLE compilers for each processor
You are forced to translate your program across many platforms and maintain multiple version of your code

## Solution: Two-Tier Compilation

Do not compile program down to machine language
Instead, program is translated into VM Code through
Two-Tier Compilation
Allows you to Write ONCE, Run ANYWHERE
Tier I: Virtual Machine
VM Code is a set of instructions for the VM that is understood by any VMI (universal)
Tier II: Virtual Machine Implementation
Equips target device with a translation to convert VM code into machine language for a specific device

## Virtual Machines

Pitch Deck

20xx

The Bridge to Universal Language

</

} /> [

/>

## What is a Virtual Machine?

A Virtual Machine is software that emulates a real computer system. It uses virtual representations of the host’s physical resources, managed by the hypervisor, rather than accessing the physical hardware directly.
Consists of:
Host: a physical computer
Guest: the operating system running in the VM
Hypervisor: the software that manages VM by mapping virtual resources to real resources

## What is a Virtual Machine Equipped With?

VM Code
Think of it as “intermediate” code.
This code acts as a middle-ground the source code and the assembly code.
VM Translator
Receives a stream of VM commands to convert VM code into assembly code that contains assembly commands
Translates VM code into machine language
Each VM command generate several assembly commands

## Stack Machines

Pitch Deck

20xx

Optimizing VM Translation

</

} /> [

/>

## Problem

VM Code Objectives:
Simplify VM Compiler: VM Code needs to be closer to high-level so resources needed for translation to get from high-level program to VM code is minimized
Simplify VM Implementation: VM Code needs to be closer to low-level so resources needed for translation to get from VM code to low-level program is minimized
These two objectives contrast one another. How can we get around this?

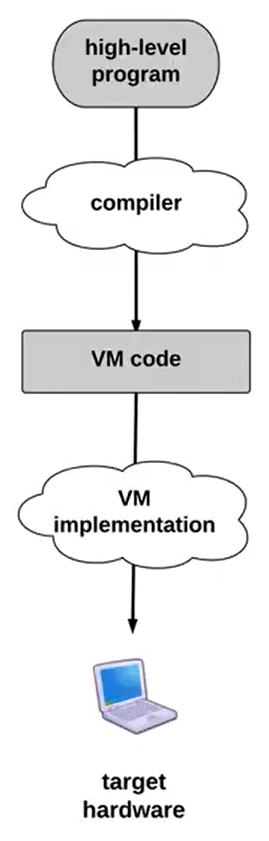
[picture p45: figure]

## Solution

Stack Machine – a computer architecture that balances the two objectives very well
Two Fundamental Operations:
- Push: add a layer to the top of the stack
- Pop: remove the top stack layer and store in memory
You can ONLY access the stack’s data from the top layer
Why does this help?
- Makes VM code compact and easy to interpret
- No need to fetch operands from memory or registers
- Helps prevent memory corruption

## Reading a Stack

Stack Pointer
- Points in the register on the top of the stack, usually at an empty register unless the stack is full
(SP)
Base Addresses
- Ids that identify which number of the stack corresponds to which layer of data
(0, 1, 2, …)
Integer Data
- Data stored within the stack
(7, -91, 3, …)

SP

## Stack Arithmetic

With just Push & Pop, you can do many logical/arithmetic commands, such as
Using just these commands, we can express ANY arithmetic or logical expression.

## Problem

How do you differentiate between different variable types, such as argument, local, and static?
Push & Pop will treat these variables as the same type, so how do we solve this?

## Solution: Memory Segments

Use segments that differentiate the variables.
s1 → static 0
y → argument 1
c → local 2

## Implementing Memory Segment Pointers

Using the same stack, segment pointers can use the integer data in its pointed stack as an address register, which points to another register’s data point.
Typical Segments Include:

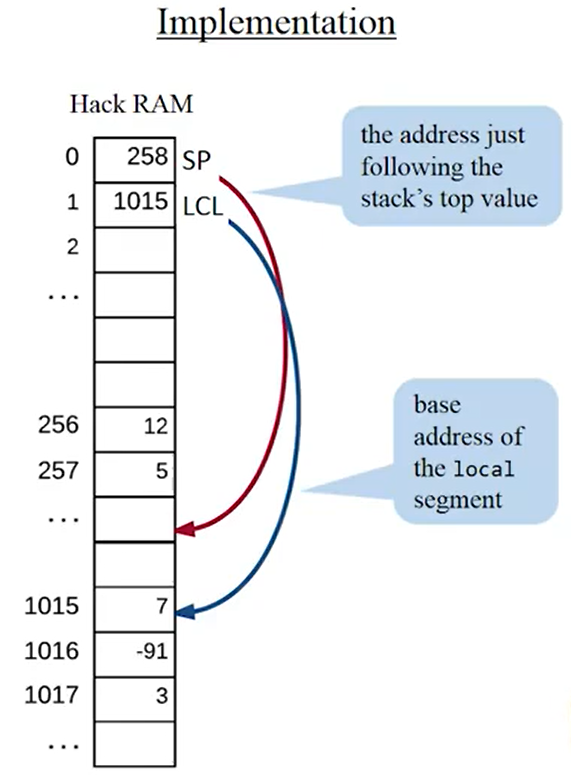
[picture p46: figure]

## Problem: How Should We Handle Static Variables?

Static Variables (aka Global Variables):
Static Variables are unique in the sense that they exist/are used by all methods in a program.
(why can’t we store static variables the same way we do other variables?)

## Solution: Static Space

Static space is a universal assignment to each program a certain amount of addresses allocated specifically to static variables to ensure that all programs have space for static variables.

## VM Emulator

Pitch Deck

20xx

Shortcut to Testing VM Code

</

} /> [

/>

## Two Ways to Use VM Code

Original Route:
High-Level Program → Compiler → VM Code → VM Translator → Machine Language
Shortcut:
High-Level Program → Compiler → VM Code → VM Emulator
- Allows you to run VM Code as-is (compiled)
- Mainly used as an environment to test programs

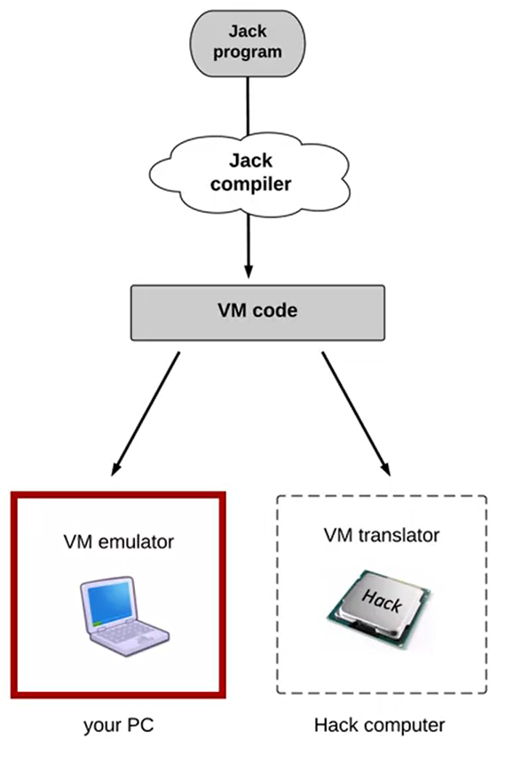
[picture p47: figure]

## Branching Commands

Pitch Deck

20xx

Placeholder

</

} /> [

/>

## Problem: Linear Programming

Commands are executed after one another.
Takes up more space if commands need to repeat (which modern programs must to do run continuously)

## Solution: Non-Linear Program (Branching)

Commands are given conditions that allow them to skip ahead or go backwards, accessing commands quicker or reusing commands. Also allows looping
Conditional Branching (if)
- Must meet a certain condition
Unconditional Branching (goto)
- A command executed upon being read

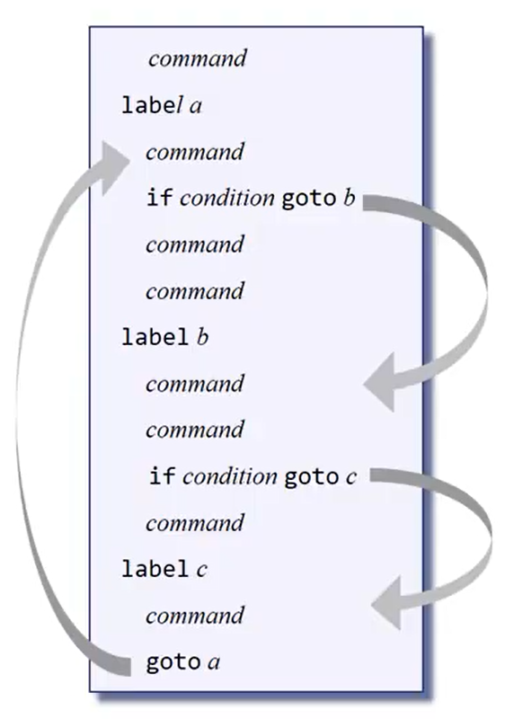
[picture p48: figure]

## Function Commands

Pitch Deck

20xx

Placeholder

</

} /> [

/>

## Function Commands

A way of grouping a series of commands into a single, executable unit.
Three Basic Function Commands:
function functionName nVars
call functionName nArgs
return

## Problem

The calling chain is not always between just two functions.
One function can call another function, which can call another function, which can call another function,
which can call another function, which can call another function, which can call another function, which can call another function, which can call another function, which can call another function, which can call another function…
How do we maintain the state of all of these functions in the calling chain?

## Solution: LIFO

Calling Pattern: Last In, First Out
The only function that can return is the function which is currently running (end of calling chain).
Last Function Returns → 2nd to Last Function Returns —> … → First Function Returns
Hey wait, doesn’t that sound similar to a stack?

## STACKING

Function’s arguments are replaced by the function’s value

## End of Meeting #2

[Loading...]

20xx

} /> [

</

Do you have any questions?

/>

Thanks for attending!
- OS Team

## Compilers 03

Pitch Deck

20xx

</>

} /> [

## Writing a Compiler

Pitch Deck

20xx

High-Level Programming to VM Code

</

} /> [

/>

## What Will We Learn

Syntax Analysis
Lexical Analysis
Grammars
Parse Trees
Parse Logic

High-level program

Compiler

Testing

## Syntax Analyzer

Pitch Deck

20xx

Placeholder

</

} /> [

/>

## Syntax Analyzer

A component of a compiler that checks if the input code (a sequence of tokens) follows the grammatical rules of the programming language
Consists of
Tokenizer – Utilizes Lexical Analysis
Parser – Utilizes Syntax Analysis

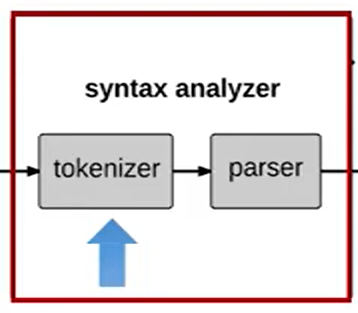
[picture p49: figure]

## Lexical Analysis

Pitch Deck

20xx

Writing the Tokenizer

</

} /> [

/>

## What is This For?

The process of converting a sequence of characters into a sequence of tokens.
Writing the Tokenizer

## Tokenizer

Turns a stream of characters (compiler’s input) into tokens with an executable role or value
Token: a string of characters that has a meaning
Programming languages will include a list of allowed tokens

## Tokens

Tokens are separated into types of tokens so that the repeat of a token type contains meaning (e.g. integer 1 followed by integer 0 results in integer 10).
Keywords (‘class’, ‘function’, ‘field’, ‘static’, ‘var’, ‘int’, ‘true’, ‘false’, ‘if’, ‘else’, ‘while’, ‘return’, etc.)
Symbols (‘ { ‘, ‘ } ’, ‘ / ’, ‘ ! ’, ‘ \ ’, ‘ : ’, ‘ ; ’, ‘ = ’, etc.)
Integers (‘0’, ‘1’, ‘2’, ‘3’, ‘4’, ‘5’, etc.)
Strings (“potato”, “RGB”, “Sunny”, “Fire”, “skull”, “emoji”, etc)
Identifiers (calculate_area, x, firstName, hello_there, Digital123)
- A sequence of letters, digits, and underscore not starting with a digit

## Grammars

Pitch Deck

20xx

What Gives Sequence of Tokens Meaning

</

} /> [

/>

## Grammar?

A set of rules that describes how token patterns should create valid logical instructions.
Rules consist of a template name (left-hand side) and a template composition (right-hand side).
Ex:
Input: let x = 100;
let → letStatement
x → term (varName)
= → operation symbol
100 → constant
; → expression

## Parsing

Pitch Deck

20xx

What Gives Sequence of Tokens Meaning

</

} /> [

/>

## Parsing

Determining if a given input conforms to a grammar
In the process, constructs the grammatical structure of the given input.

## Parse Trees

A graphical layout detailing how a compiler’s input is systematically organized and broken down according to grammar rules.

## Parse Logic

Following the parsing, the output will look something like this.
This resembles what the syntax analyzer will output to the code generator.

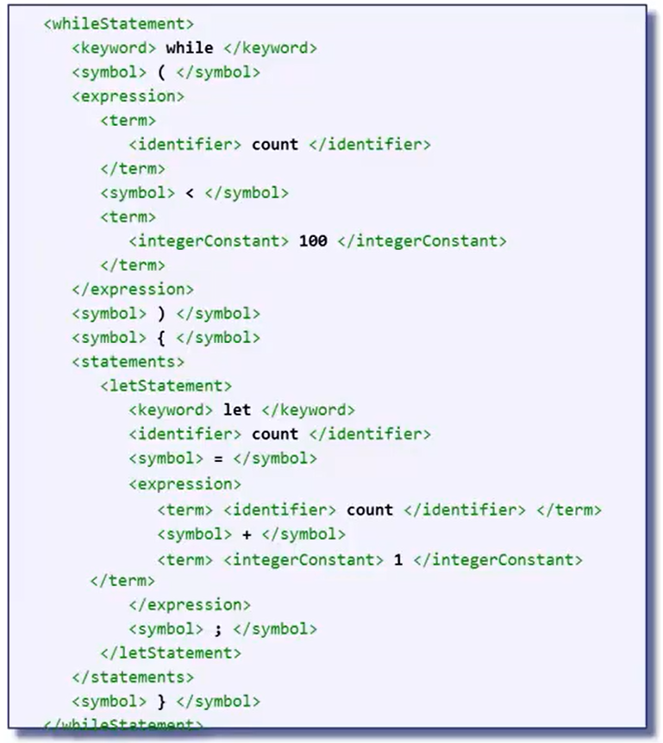
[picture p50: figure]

## Code Generator

Pitch Deck

20xx

Where the Magic Happens

</

} /> [

/>

## What is a Code Generator?

Code generators translate parsed code into VM code.

High-Level Program

## Class Separation

More complicated compilers can compile programs with multi-class code. In this compiler, the class is broken down into separate subroutines and compiled one at a time.
Subroutines:
- A block of reusable code designed to perform a specific, common task, also known as a procedure, function, or method

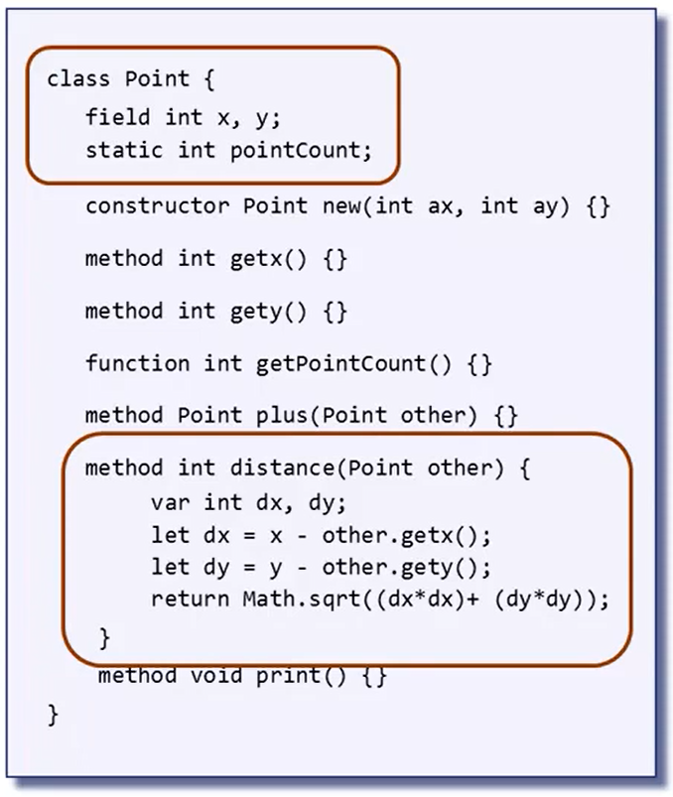
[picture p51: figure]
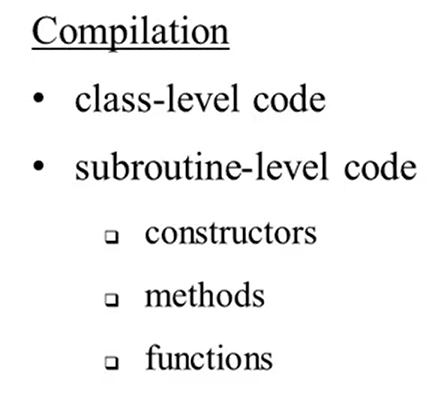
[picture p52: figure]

## Compiling Subroutines

You are handling
Procedural Code
- Variables
- Expressions
- Flow of Control
Objects
Arrays
which are to be expressed in VM code

## Procedural Code

Pitch Deck

20xx

Placeholder

</

} /> [

/>

## Handling Variables

VM Language does not have symbolic variables. In order to turn high-level language into VM code, you need to map the symbolic variables into the virtual memory segments.
sum, x, rate
Which segments do each of these belong to?
Challenges
1. Differentiate variables (are they field, static, local, or argument?)
2. Differentiate whether a variable is the first, second, third, … of its kind

## Variable Properties

To classify each variable, break each of them down by their properties.
- Name
- Type (int, char, boolean, etc.)
- Kind (field, static, local, argument, etc.)
- Scope (class level, subroutine level)
Variable properties can be maintained using a symbol table.

Class-Level Symbol Table

Can reset after compiling a new class

Subroutine-Level Symbol Table

Can reset after compiling a new subroutine

## Handling Expressions

How can we systematically translate these expressions into VM code?
Notations:
Prefix
- Operand goes before variables
- Functional
Infix
- Operand is in the middle of variables
- Human-Oriented
Postfix
- Operand goes after variables
- Stack-Oriented

Parse Trees

## Parse Tree to VM Code

Algorithm: Depth-First Tree Traversal
- A two-stage approach
Starts at root (+) and pushes variables from left to right.
Problem: Parse Trees can be gigantic, making this algorithm quite slow for large expressions

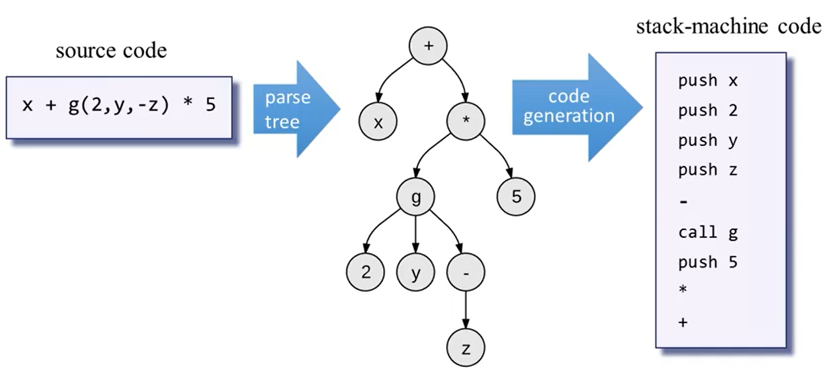
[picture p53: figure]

## Generating VM Code For Expressions (Faster)

Generates VM code without needing to create the entire parse tree in the process
Algorithm: Code Write
- A one-stage approach
A series of conditions that directly convert the expressions into VM code

## Problem: Flow of Control

Problem: How do you translate high-level language like this into VM code using just...?
- goto
- if-goto
- label

## Compiling If Statements

Using this sequence, it becomes possible that, given any if statement, the compiler will output exactly the same if statement.

## Compiling While Statements

While statements are compiled as such.

## Minor Complication

Problem: Complicated high-level programs will contain multiple if and while statements. How do we account for this?
Solution: Ensure that the compiler generates unique labels.
Problem: If and while statements are often nested
Solution: Compiler must use a highly recursive (repetitive) compilation strategy

## Problem

High-Level object-oriented programs create and manipulate objects and arrays
Mid-Level VM program operate on virtual memory segments
Low-level machine programs operate directly on the RAM
How do you make compilers that write the necessary mid and low level automatically?

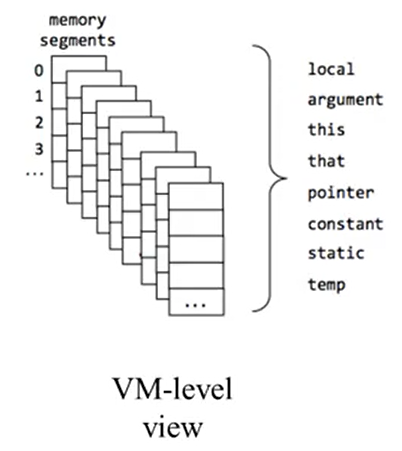
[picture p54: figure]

## Handling Objects

Pitch Deck

20xx

Placeholder

</

} /> [

/>

## Low-Level Aspects

There is a reserved space in the RAM called the “heap”. The heap exclusively stores the data of objects and arrays.
The base addresses “this” and “that” represent object and array data respectively.
Before we use the segments, we have to anchor them using pointers.
pointer 0 (this)
pointer 1 (that)

## Object Construction

Compilers need to have end code that handles object construction. There are two classes needed to complete this: client and point.
Client: seeks to create a point object (caller)
Point: services the client’s request to create a point object (callee)
- Includes a subroutine known as “constructor”
The compiler sees these two as separate compilation units.

## Constructor Call

Variables of the high-level code are stored in the stack. A pointer is assigned to that stack, which contains a base address of where the objects are stored in the heap.
1. Upon variable declaration, the compiler updates the subroutine symbol table. (no code is generated)
2. Push arguments and call Point.new
3. Pop the base address of object being constructed
Compile-Time: Compiler maps p1 on local 0, p2 on local 1, and d on local 2.
Run-Time: Constructor’s code creates objects and allocates them to the heap.
The client assumes that the RAM will have space.

## Compiling Constructors (Callee)

To complete the tasks previously mentioned, the constructor will need to have access to the constructor’s fields.
Fields are accessed in the “this” segment. To access the this segment, we have to anchor the segment with the right address in the RAM using the pointer segment.
Code needs to be created here
1. Constructor Declaration (creates subroutine symbol table)
2. Compiler uses the operating system to create space in the RAM reserved for calling an argument called Memory.alloc
3. Runs push and pop operations to use the new space in the RAM

## Handling Arrays

Pitch Deck

20xx

Placeholder

</

} /> [

/>

## Array Construction

Arrays exist as a subroutine class. The compiler will allocate additional space that represents the array in the heap.
The base address of the stack is stored in local 0.
Like how the “this” pointer is used for objects, the “that” pointer is used for arrays. Arrays also use pointer 1 instead of pointer 0.
Both “this” and “that” are “portable” virtual memory segments, meaning they can be aligned with different RAM addresses in the heap.

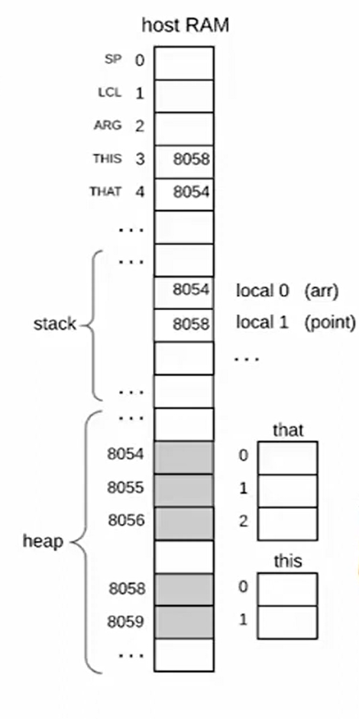
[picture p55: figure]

## Array Access

Problem: A solution like this will overwrite the address written in pointer 1.

Incorrect

## Array Access

Solution: This method correctly assigns pointers and avoid overwriting segments.

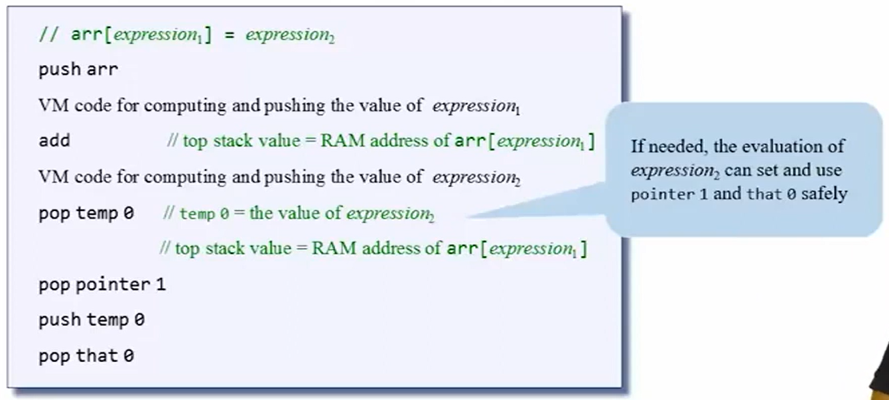
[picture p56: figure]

General Solution to Generate Code to Access Array

## Standard Virtual Machine Mapping

Pitch Deck

20xx

Placeholder

</

} /> [

/>

## Special OS Mapping

These are OS functions.
Multiplication: Math.multiply()
Division: Math.divide()
String Constants: String.new(length)
String Assignments: String.appendChar(c)
Object Construction: Memory.alloc(size)
Object Recycling: Memory.dealloc(object)

## End of Meeting #3

[Loading...]

20xx

} /> [

</

Do you have any questions?

/>

Thanks for attending!
- OS Team

## Operating Systems 04

Pitch Deck

20xx

</>

} /> [

## What is an Operating System?

WIP

## OS Services

This high-level program has calls to methods highlighted in blue which exist in classes that belong to standard libraries that accompanies a programming language.

## OS Typical Services

Operating systems typically benefit high-level programmers. They can expect access to:
- Mathematical Calculations
- Data Structures
- Input Device Interaction
- Write on the Screen
Low-level services include:
- Manage and Host Memory
- File Storage Management
- Device Drivers Mitigation
- User-Computer Communication
- Multiple Processes
- Communication Software
- Security

## Efficiency

Pitch Deck

20xx

Math Done Quicker

</

} /> [

/>

## Multiplication

Run-Time: How long an algorithm takes to perform its task
N represents the largest number that way be asked to multiply with
Multiplication: Run-time is proportional to N
Multiply with w-bit number (w being the number of bits required to represent N)
w = log2N

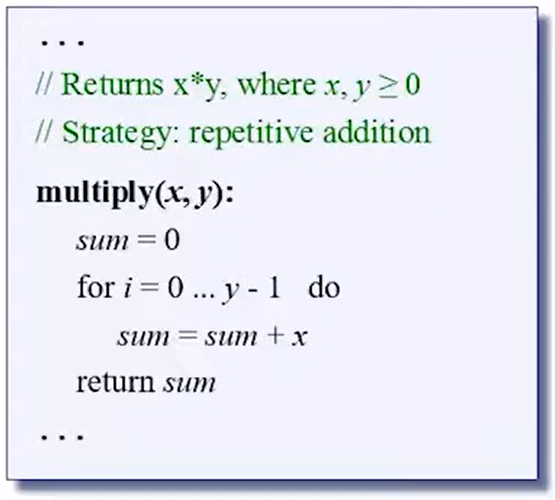
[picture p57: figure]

Inefficient

Efficient
Note: Only uses addition

## Division

Division by Repetitive Subtraction: Run-time depends on input’s size
Another algorithm is based on long division
- Run-time depends on number of digits
A better algorithm’s run-time is proportional to log2N
- N represents the largest number that way be asked to multiply with

Inefficient

Efficient
- Long Division

Even More Efficient
- Involves only addition operations

## Square Root

1. Its inverse function (x²) is easily computable
2. It is a monotonically increasing function
Use a method called “binary search”
The run-time of binary search is logarithmic

Highly-Efficient

## Memory Access

Pitch Deck

20xx

Placeholder

</

} /> [

/>

## The Memory Class

Classical Operations:
- Peek
  - function int peek(int address)
- Poke
  - function void pook(int address, int value)
- Alloc
  - function array alloc(int size)
- Dealloc
  - function void deAlloc(Array o)

## The Need

Application Programs
Programs can’t access RAM on their own. OS allows the programs to:
- Access the RAM via abstractions: variables, objects, arrays, …
- Access I/O Devices via abstractions: readInt(), printInt(x), …
Implementation:
OS provides low-level services that facilitate direct RAM access
Based on these low-level services, the OS features higher-level memory and I/O management services

## Heap Management

Pitch Deck

20xx

Placeholder

</

} /> [

/>

## The Challenge

During run-time, programs typically create many objects and arrays. Objects/arrays are implemented using reference variables and pointers to data blocks in the heap.
Problem:
How do you…
1. Allocate memory for new objects/arrays
2. Recycle memory of disposed objects/arrays

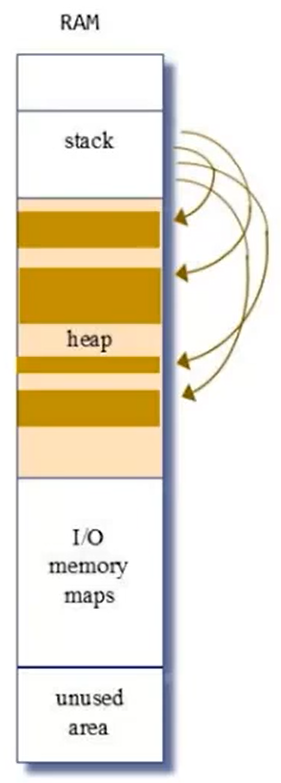
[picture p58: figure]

## Object Construction

Operation:
1. High-level program creates an object variable
2. High-level program calls the constructor to build an object and associate point with p variable
Whenever a new object is needed, the constructor sends a request to the operating system to allocate space for the new object.

## Object Destruction

When an object is no longer necessary, the disposer will recycle the memory block associated to the unnecessary object. This will free the space of data.
(In languages like Java and C#, they have a garbage collector, meaning deallocation of objects is handled automatically.)

## Linked List (freeList)

Helps keep track of available heap segments
- Keeps two overhead words that includes the size and a pointer to the next segment in the freeList
Allocation:
1. Search through the freeList until you find a block with enough size, then remove the segment from the freeList and hand its pointer to the caller
Deallocation:
1. Add the object segment to the end of the freeList

## Graphics

Pitch Deck

20xx

Placeholder

</

} /> [

/>

## The Screen Class

Handles all graphical operations of our programs
Library includes:
- clearScreen()
- setColor(boolean b)
- drawPixel(int x, int y)
- drawLine(int x1, int y2, int x2, int y2)
- drawRectangle(int x1, int y2, int x2, int y2)
- drawCircle(int x, int y, int r)

## Techniques

Two Common Techniques are the “Vector Graphics” and the “Bitmap Graphics”

## Bitmap Graphics

Records information about the image
Separate the graphics files by row. In each row, for every white pixel, output a 0. For every black pixel, output a 1.

## Vector Graphics

Records instructions on how to produce image using coordinates.
Look at image in terms of row and column. Draw lines and rectangles using the least amount of instructions.
Basic Instructions:
drawLine(int x1, int y2, int x2, int y2)
drawRectangle(int x1, int y2, int x2, int y2)
drawCircle(int x, int y, int r)

## Differences in Scaling

Vector graphics allow for perfect scaling when enlarging images. Because vectors use instructions, all that is needed is to proportionally increase its instructions.
Bitmap graphics look dull when scaled because no new information is added to the image. Retaining a fixed resolution means to scale the image, software needs to use algorithm like interpolation or average-color summing, which leads to a less detailed appearance.

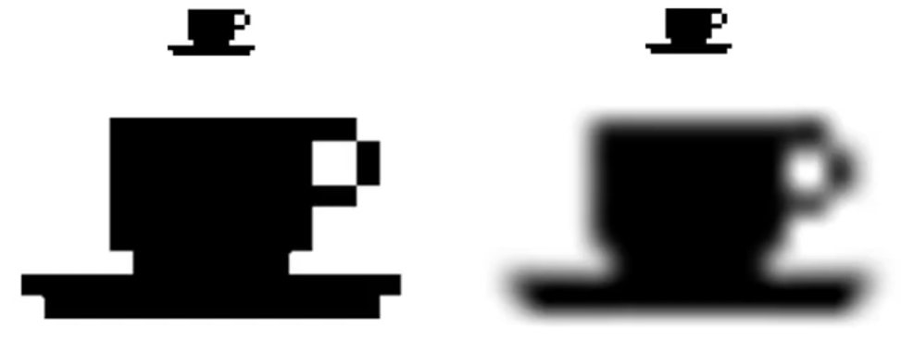
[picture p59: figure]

## Differences in Storing

Vector graphics contain relatively little information because they are instructions rather than information on each pixel. That also makes vector graphics easier to transmit.
Vector graphics can also be turned into bitmap graphics.

## Textual Outputs

Pitch Deck

20xx

Placeholder

</

} /> [

/>

## Character Set

Managed by the OS Class Output
Printable Characters
Contains a bitmap image representing characters that is displayed to the user
Non-Printable Characters
Contains information/instructions but no visual display
Displayed on a 256 by 512 pixels grid

## Font

Words are displayed on a bitmap, specifically a 11 by 8 pixel grid
Each frame has 2 columns and 1 row of empty pixels for spacing.

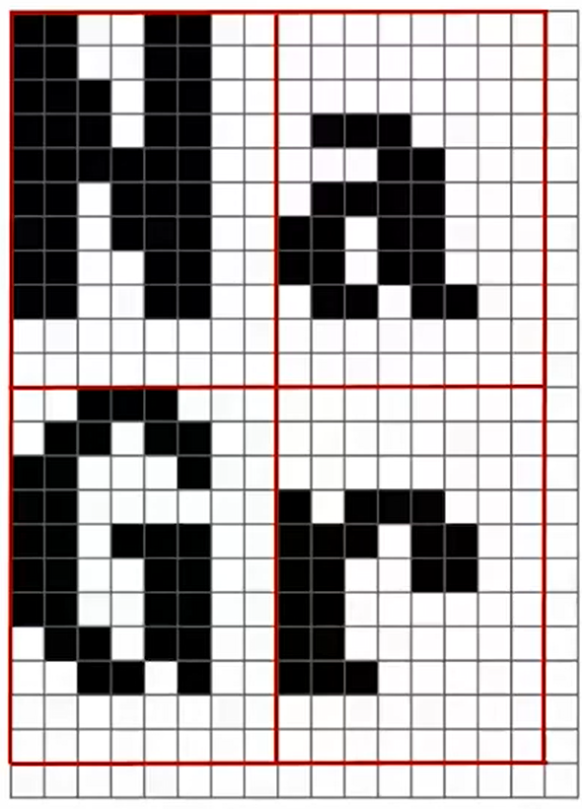
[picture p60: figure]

## Input

Pitch Deck

20xx

Placeholder

</

} /> [

/>

## Keyboard Inputs

Part of the Keyboard class
The RAM includes a single 16-bit register for the keyboard map
Unique inputs are stored as separate base addresses in the RAM
Hardware Interaction:
When a key is pressed, the keyboard register outputs the scan code
When no key is pressed, the keyboard register resets the scan code to 0

## String Processing

Pitch Deck

20xx

Placeholder

</

} /> [

/>

## String API - Calls

Runs in the String class
Utilizes…
1. The constructor to create new strings with a defined max length
2. The disposer to deallocate the string and free memory space
3. An accessor that returns the length of the current string
API*: Application Programmable Interface
- Used as IDs to pass along information

## String API - Method Call

Methods
charAt: returns the character in a given string index
SetCharAt: ets a desired character of a string to a different character
appendChar: takes a character and appends it to end of string
eraseLastChar: erases last character from string
intValue: returns integer value of string (assuming it is an integer)
setInt: sets string to representation of given integer

## String API - Function Call

Functions:
Function
newLine
backSpace
doubleQuote
These functions return the ASCII values of the new line

## Integer to String Algorithms

While integers are more easily converted to strings, strings can only be converted to integers if the string consists of a numerical value.

## Array Representation

Pitch Deck

20xx

Placeholder

</

} /> [

/>

## The Array Class

Consists of 2 subroutines
new(int size): creates a new array of a given size
dispose(): disposes the selected array
“Array Processing” is handled by the compiler, not the operating system. The operating system is in charge of creating and disposing of arrays.

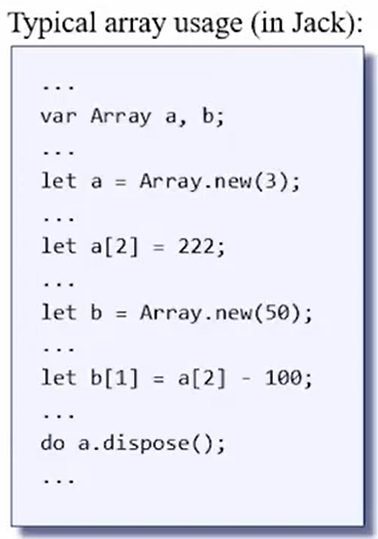
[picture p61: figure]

## The Sys Class

Pitch Deck

20xx

Placeholder

</

} /> [

/>

## The Sys Class

Consists of four methods (one is something users don’t get to see)
halt(): Halts execution
- Not for users, but for the OS
error(int errorCode): Prints given error and halts
wait(int duration): Waits approximately duration in milliseconds and returns
init(): used strictly for OS services; performs all initializations required by the OS

## Bootstrapping/Booting

The process of loading the basic software into the memory of a computer after power-on/reset. The operating system is included in the software loaded, which is then tasked with loading the other software as needed.

## End of Meeting #4

[Loading...]

20xx

} /> [

</

Do you have any questions?

/>

Thanks for attending!
- OS Team

## The Operating Systems Curriculum Pt. 2: Linux

[Loading...]

20xx

</

} /> [

/>

By DIGITAL

## What is Linux?

Linux is an open-source operating system built around the Linux kernel, a core component that manages hardware and system resources.
Advantages:
- Open Source Software
  - Being able to see how a software works allows you to research the source code and make improvements much easier
- Command-Line Interface
  - Allows the user to run all administrative tasks from the CLI, enabling easier automation, deployment, provisioning, and local/remote system administration
- Modular Operating System
  - System components can be upgraded and updated when needed

## Linux Terminology

Linux Kernel:
Linux Distribution: an installable operating system that is constructed from a Linux kernel and that supports user programs and libraries

## Linux Terminology

Linux Kernel:
Linux Distribution: an installable operating system that is constructed from a Linux kernel and that supports user programs and libraries

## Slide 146

The adjustments are of higher concern, but optionally, these slides can also be improved by standardizing the structured “formats”. Standardization between similar types of info, or different topics of info, might enhance the slides, once all the important info is down

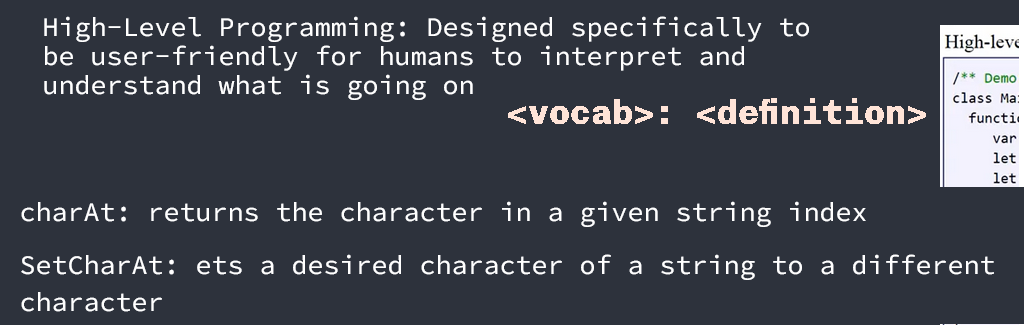
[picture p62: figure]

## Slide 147

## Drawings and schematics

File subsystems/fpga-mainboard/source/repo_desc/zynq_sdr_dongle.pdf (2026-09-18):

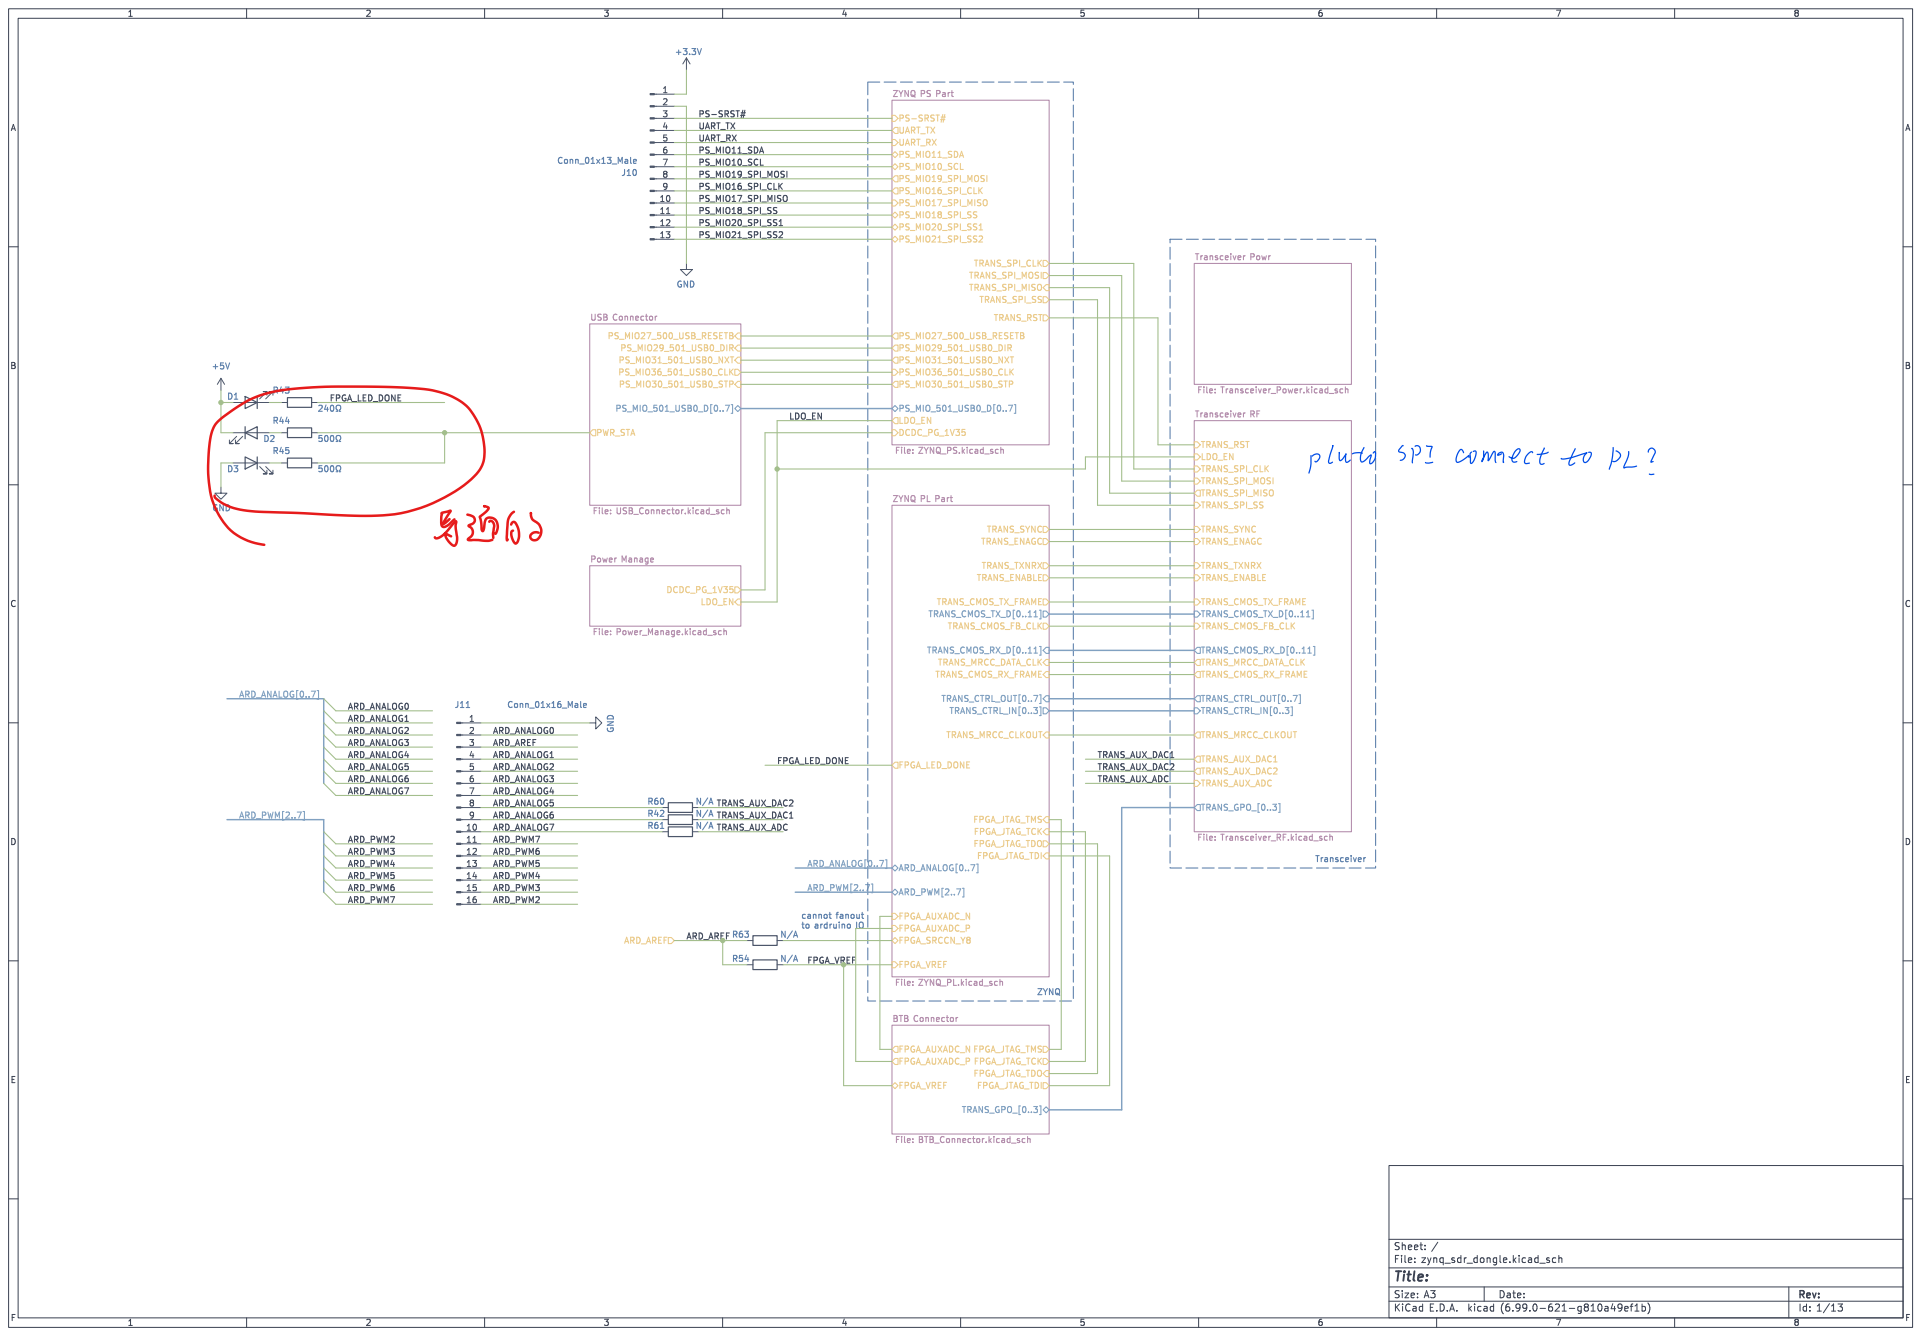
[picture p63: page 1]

PS_MIO27_500_USB_RESETB
ZYNQ PL Part File: ZYNQ_PL.kicad_sch FPGA_VREF

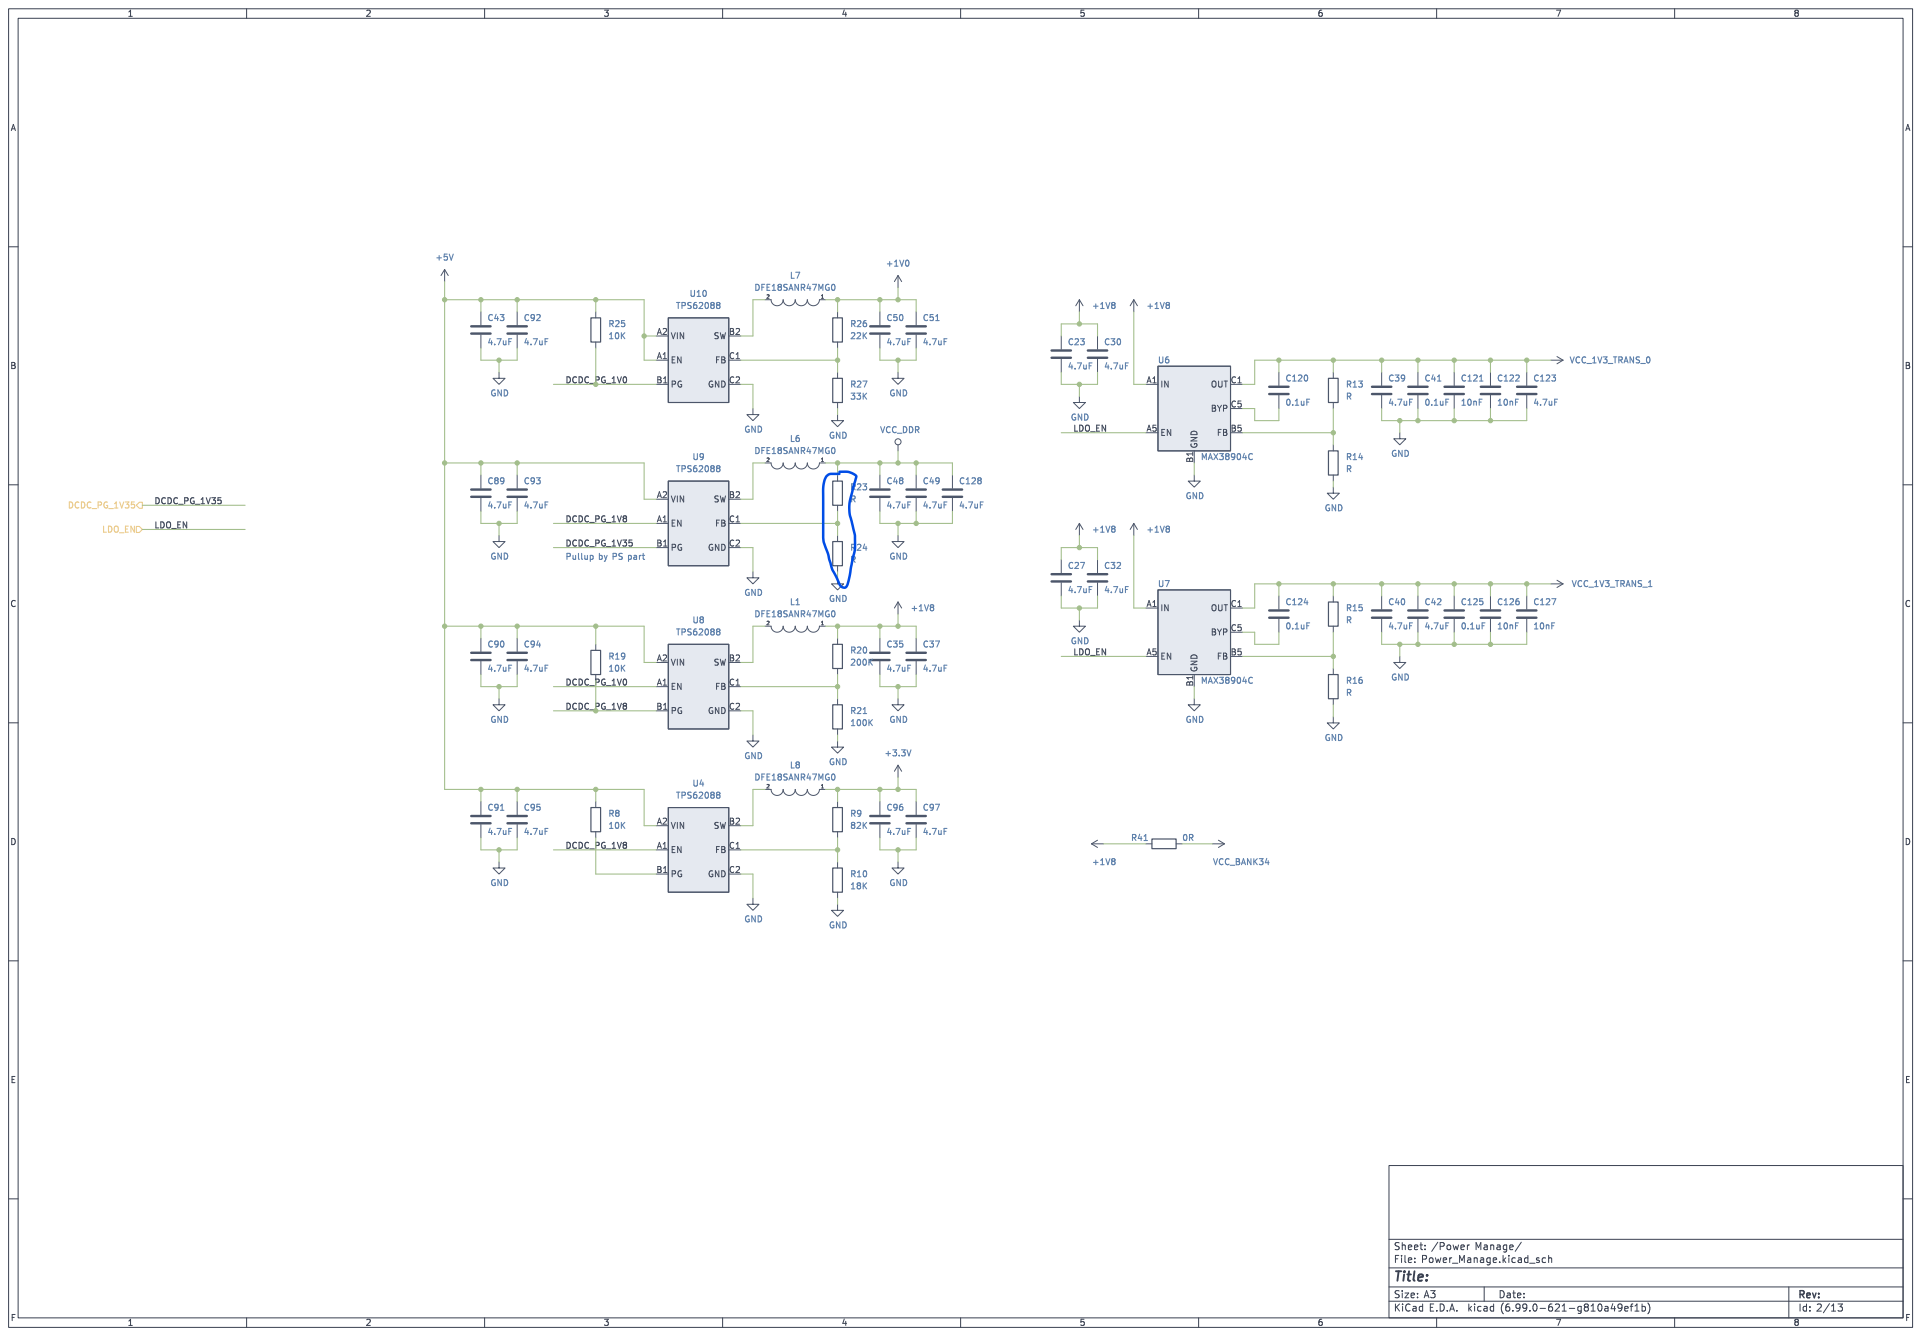
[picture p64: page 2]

Pullup by PS part

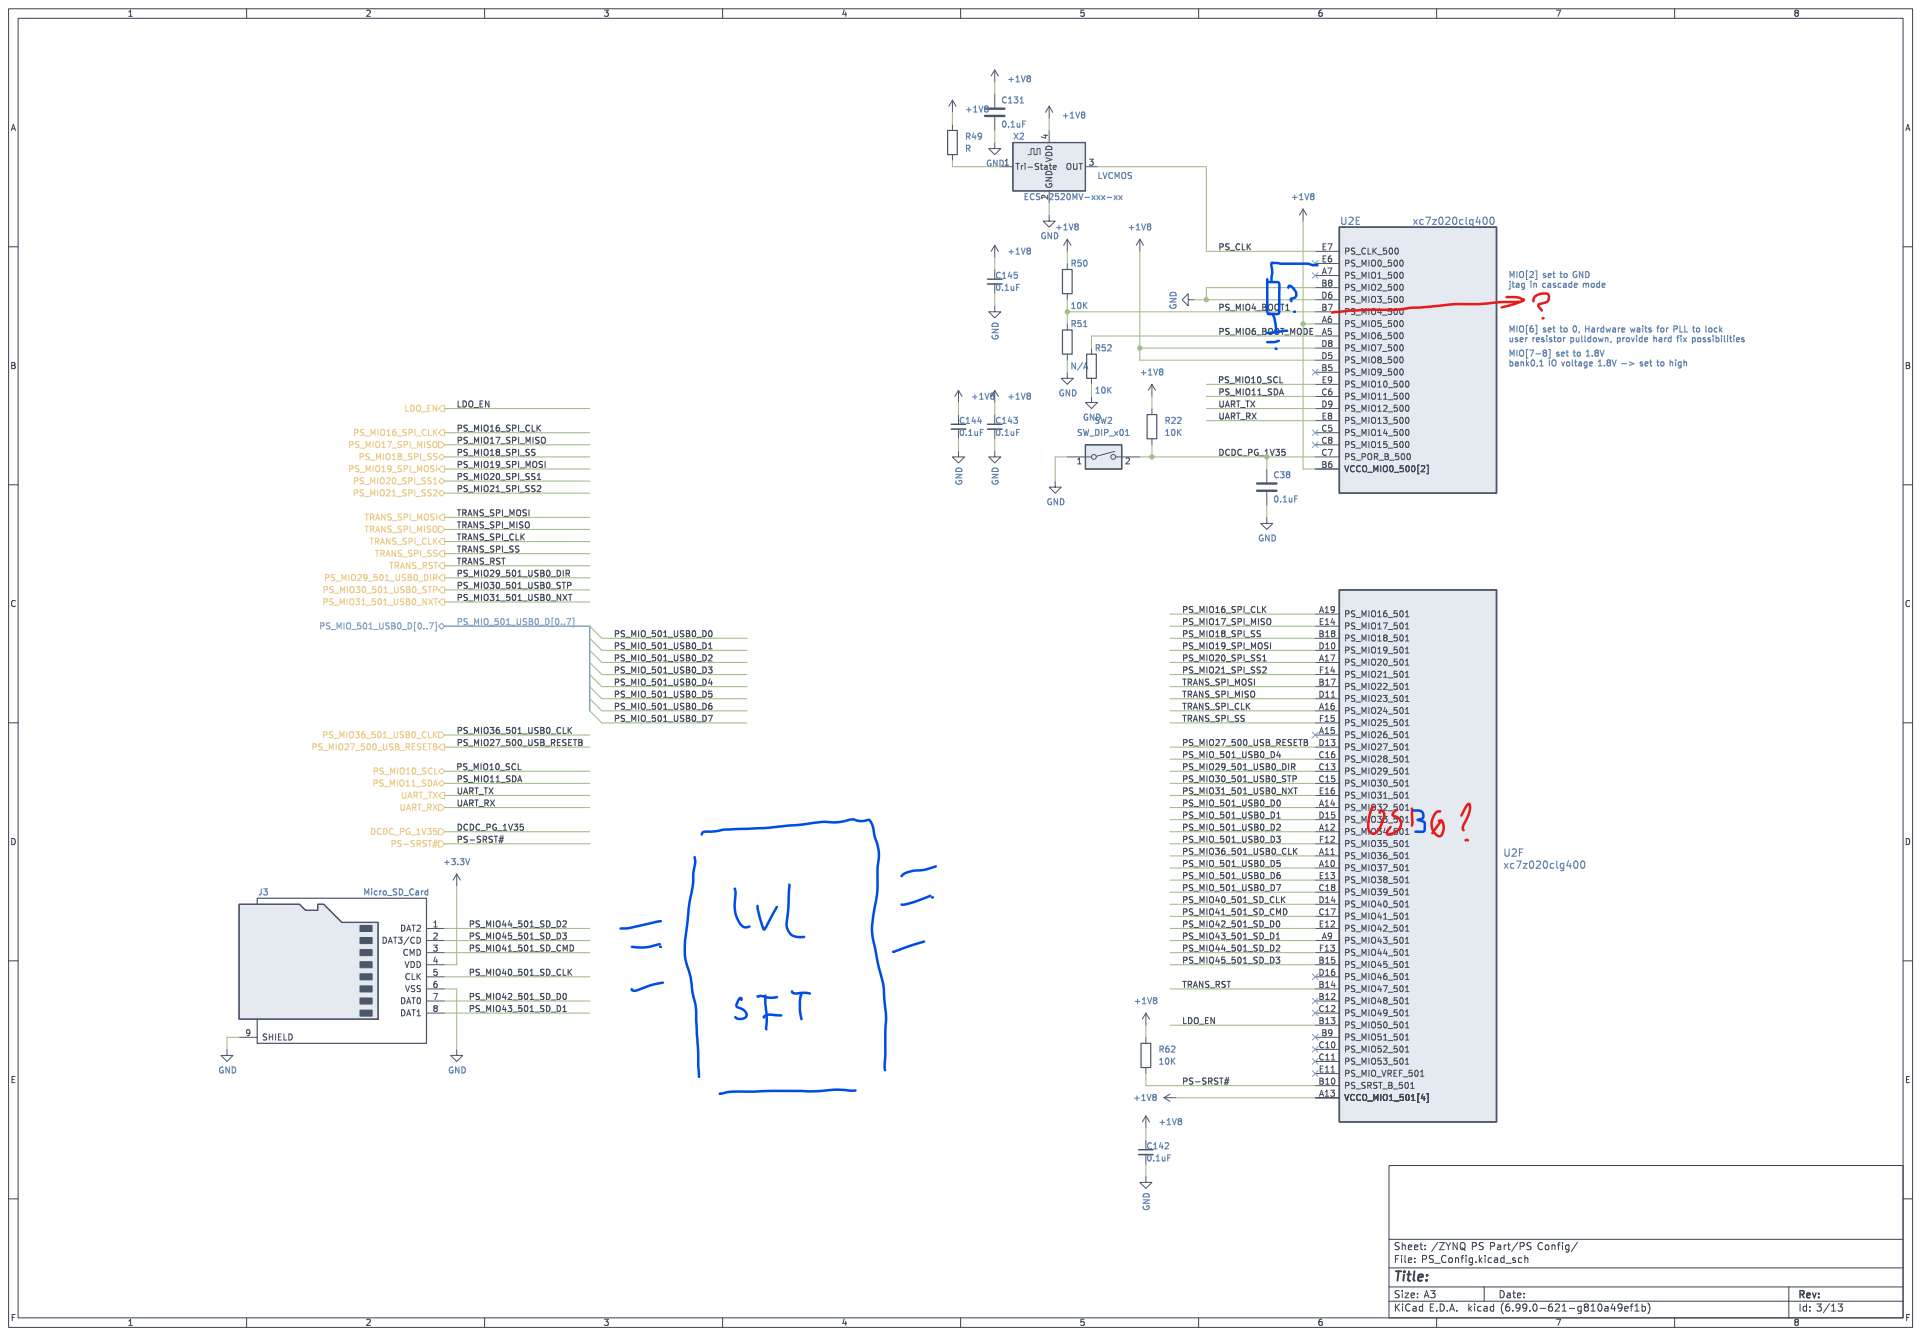
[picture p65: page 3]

MIO[2] set to GND
jtag in cascade mode

user resistor pulldown, provide hard fix possibilities
MIO[7-8] set to 1.8V
bank0,1 IO voltage 1.8V -> set to high

Sheet: /ZYNQ PS Part/PS Config/
File: PS_Config.kicad_sch
Id: 3/13 Title:

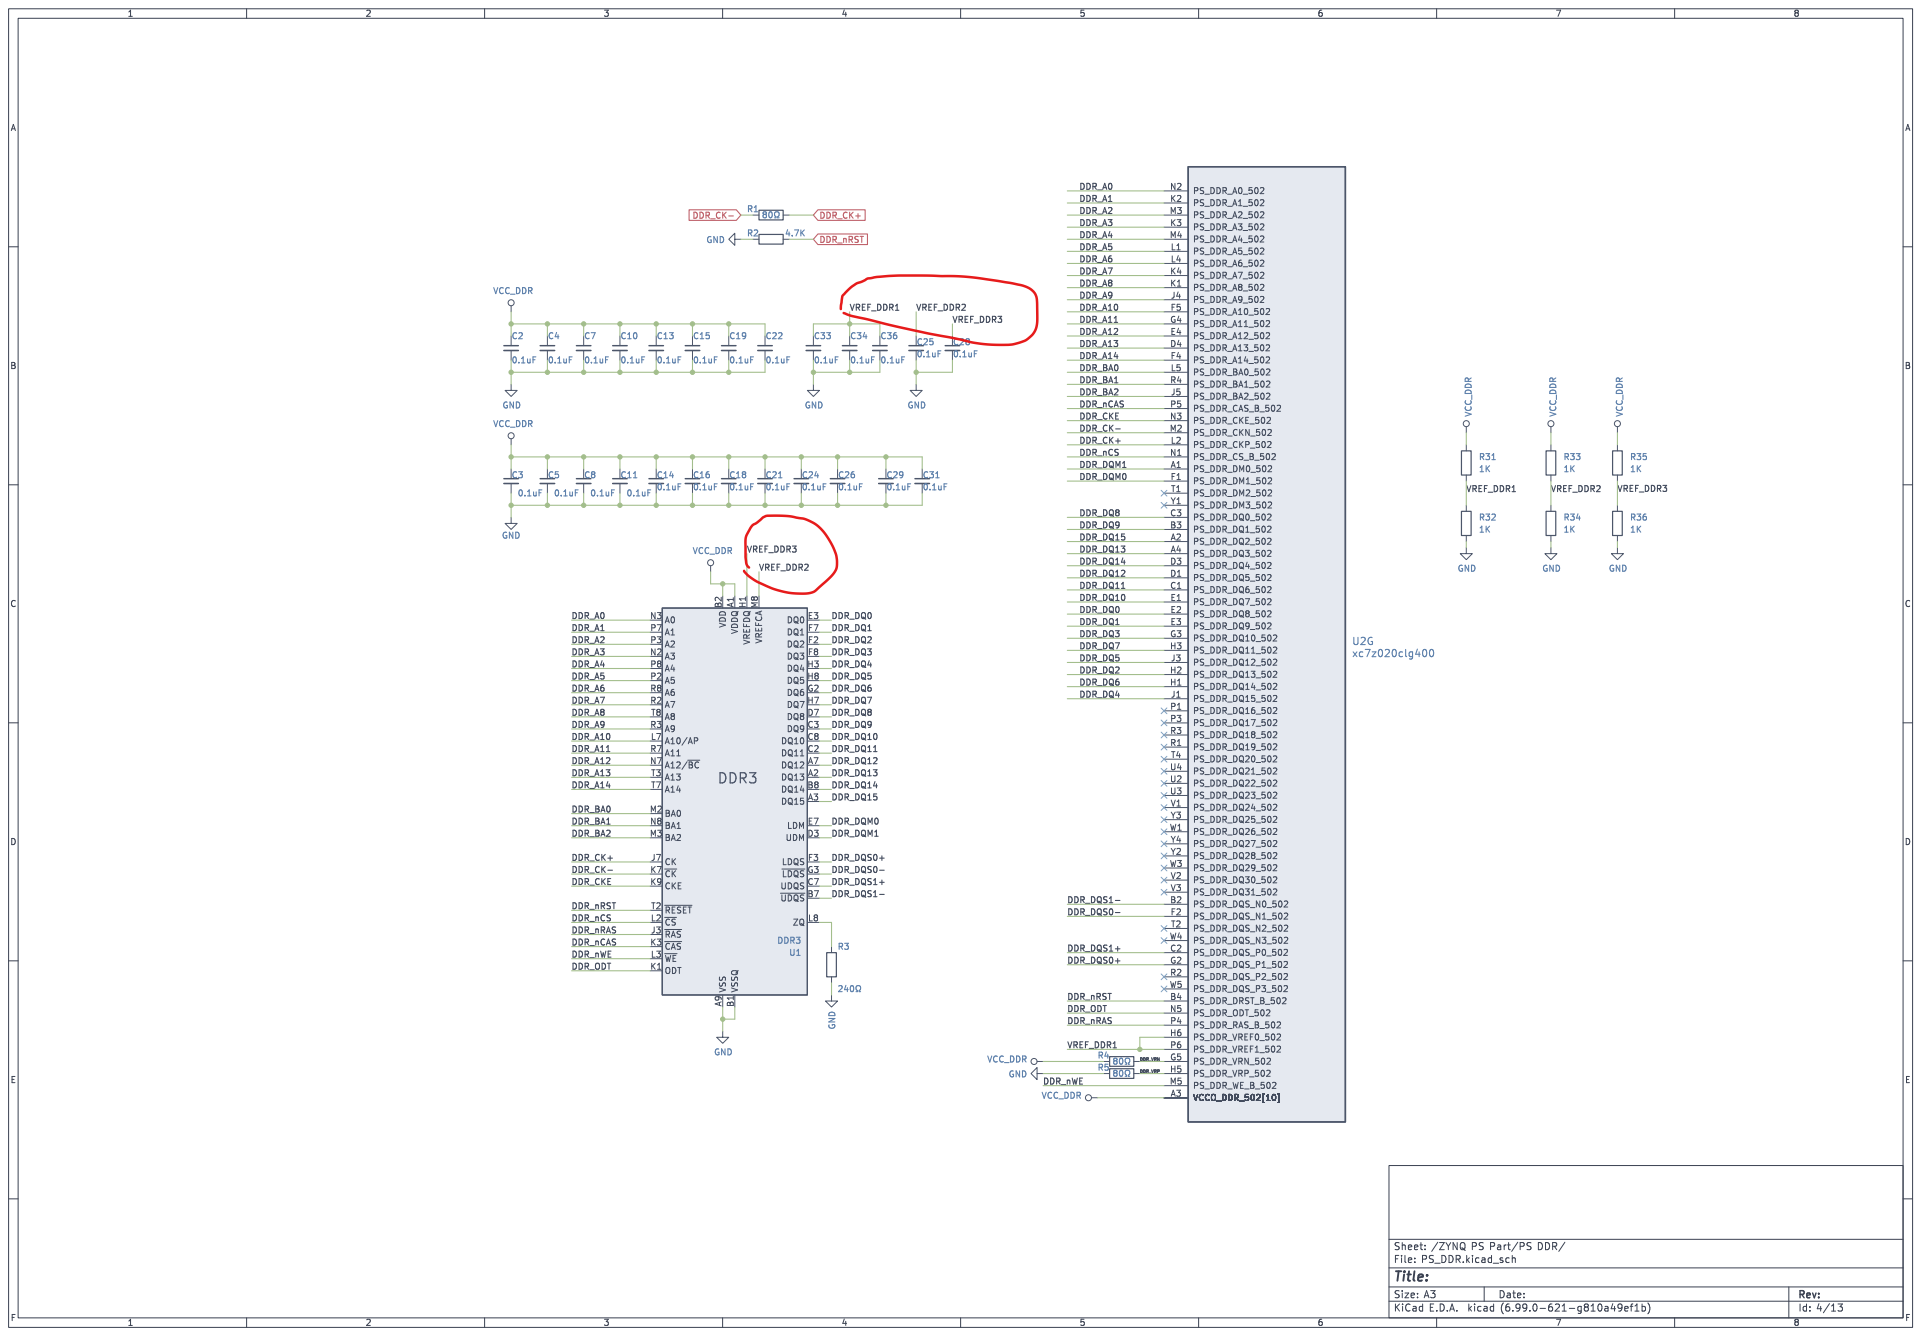
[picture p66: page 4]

Sheet: /ZYNQ PS Part/PS DDR/
File: PS_DDR.kicad_sch
Id: 4/13 Title:

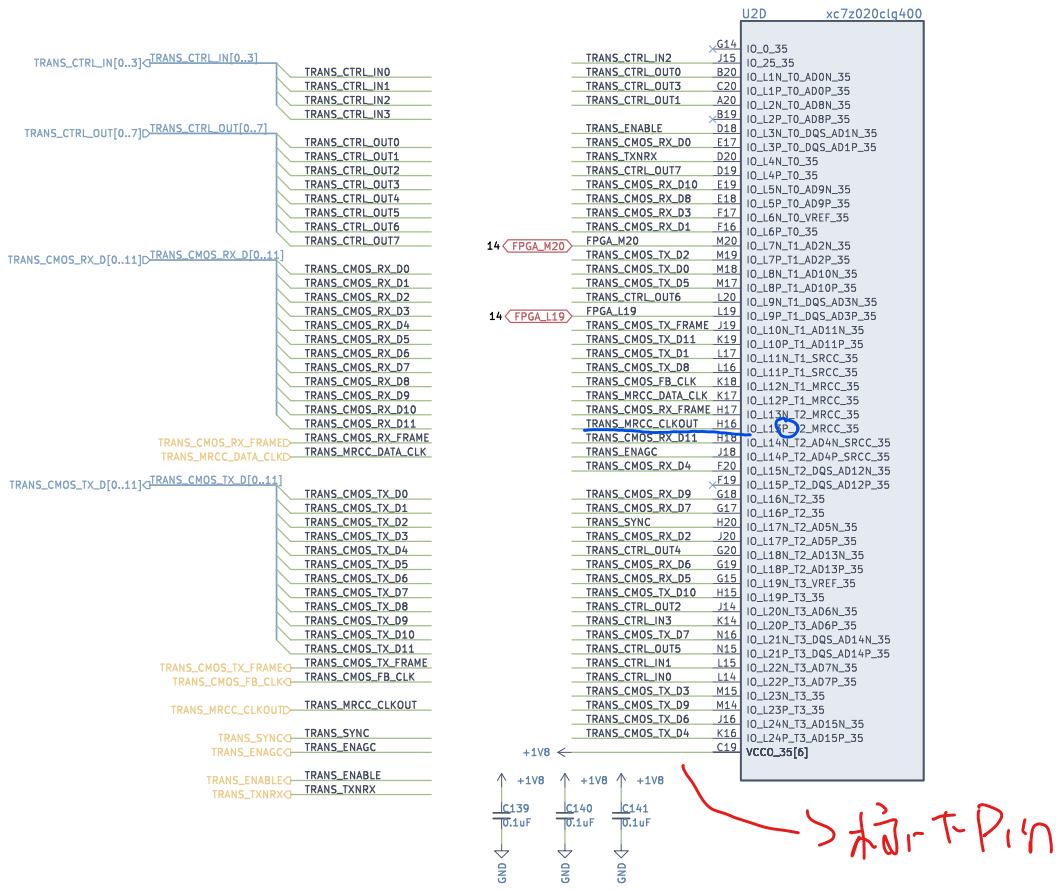
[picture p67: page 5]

Sheet: /ZYNQ PL Part/PL Transceiver/ GND

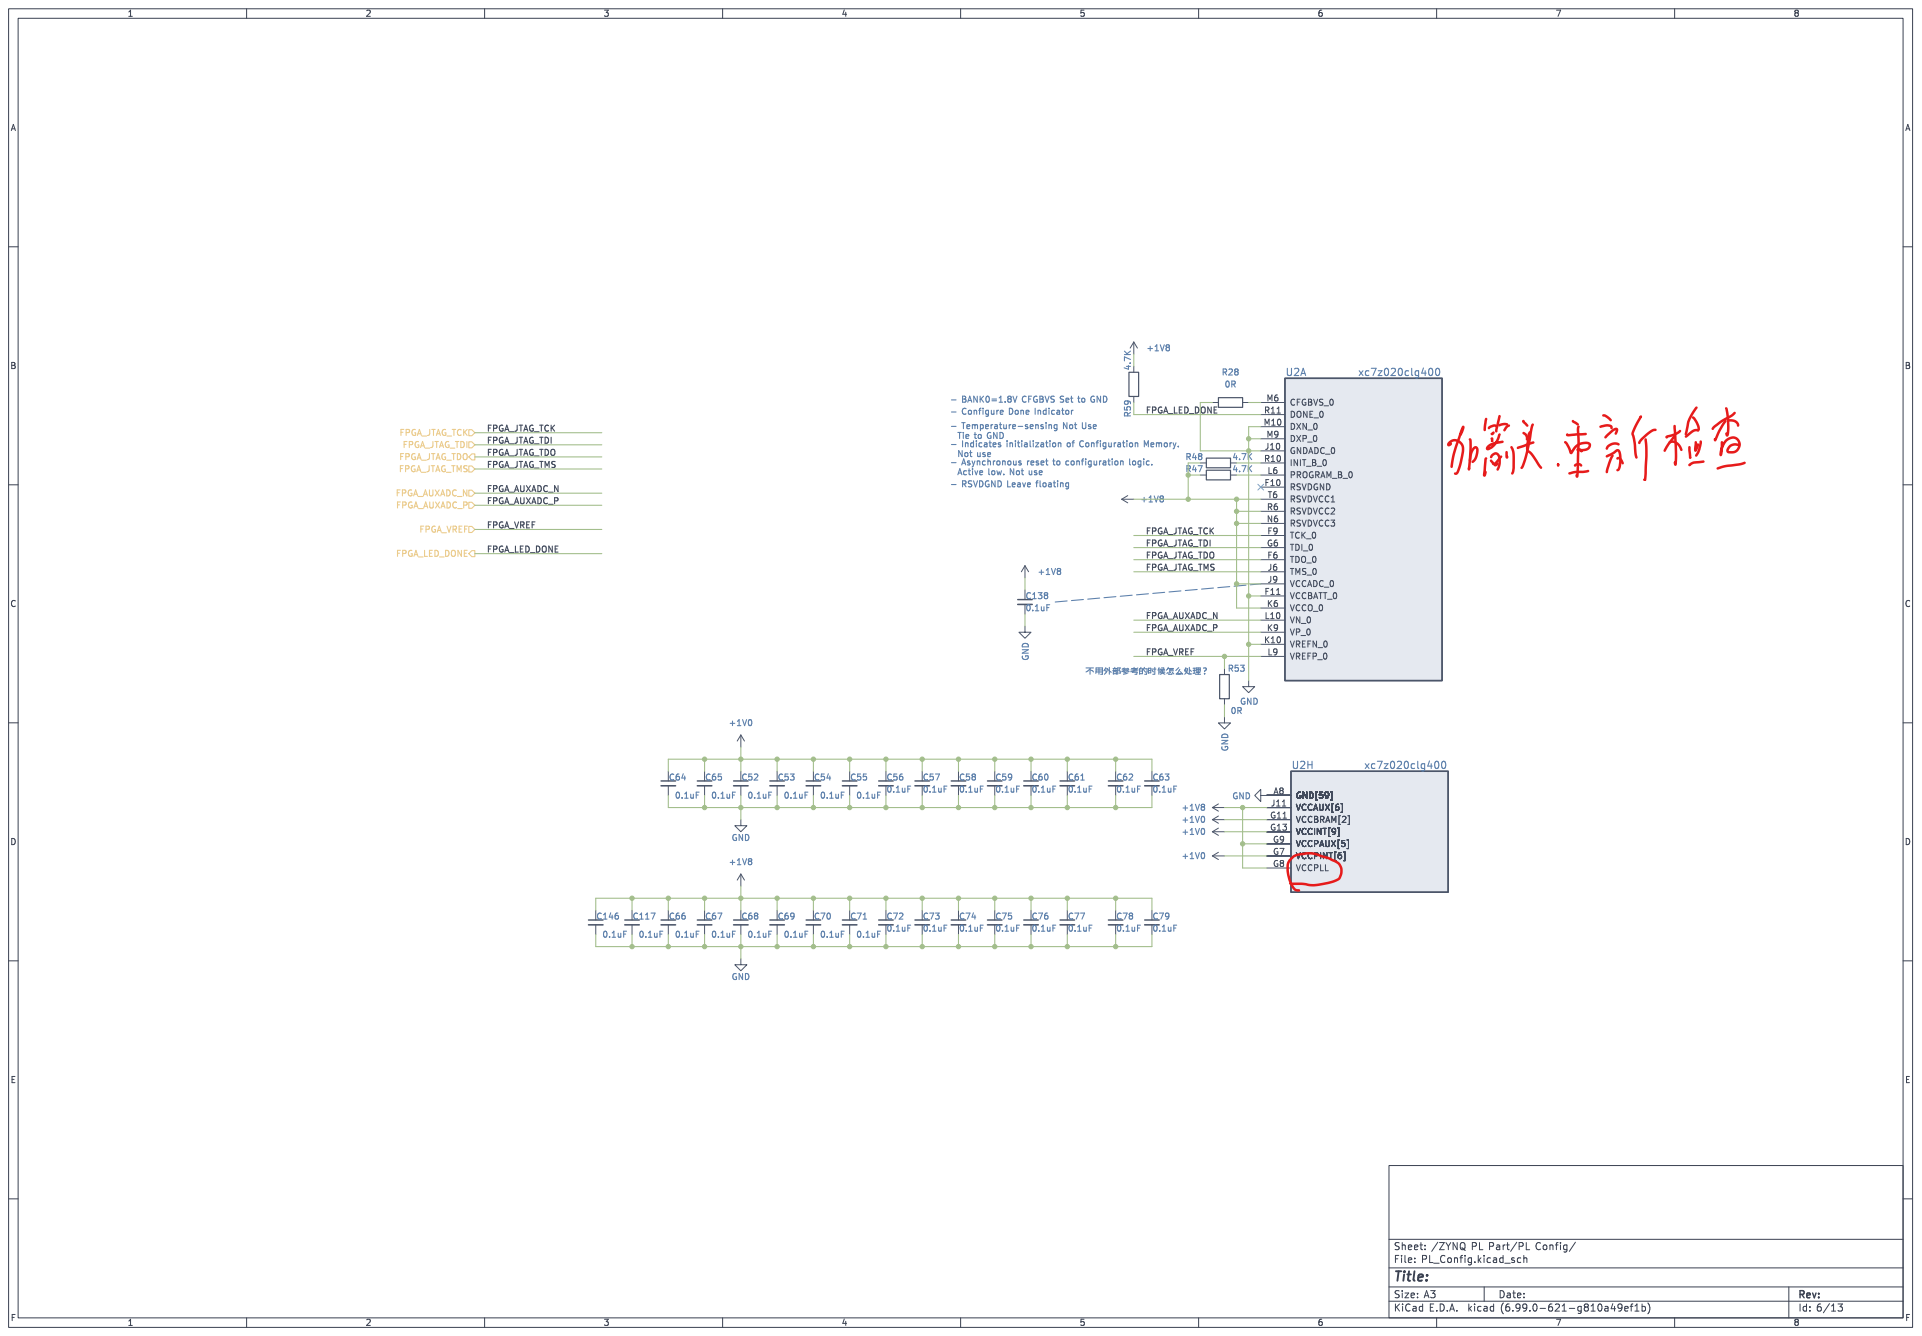
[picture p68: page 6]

- BANK0=1.8V CFGBVS Set to GND
- Configure Done Indicator
- Temperature-sensing Not Use
Tie to GND
- Indicates initialization of Configuration Memory.
Not use
- Asynchronous reset to configuration logic.
Active low. Not use
- RSVDGND Leave floating

Sheet: /ZYNQ PL Part/PL Config/
File: PL_Config.kicad_sch
Id: 6/13 Title:

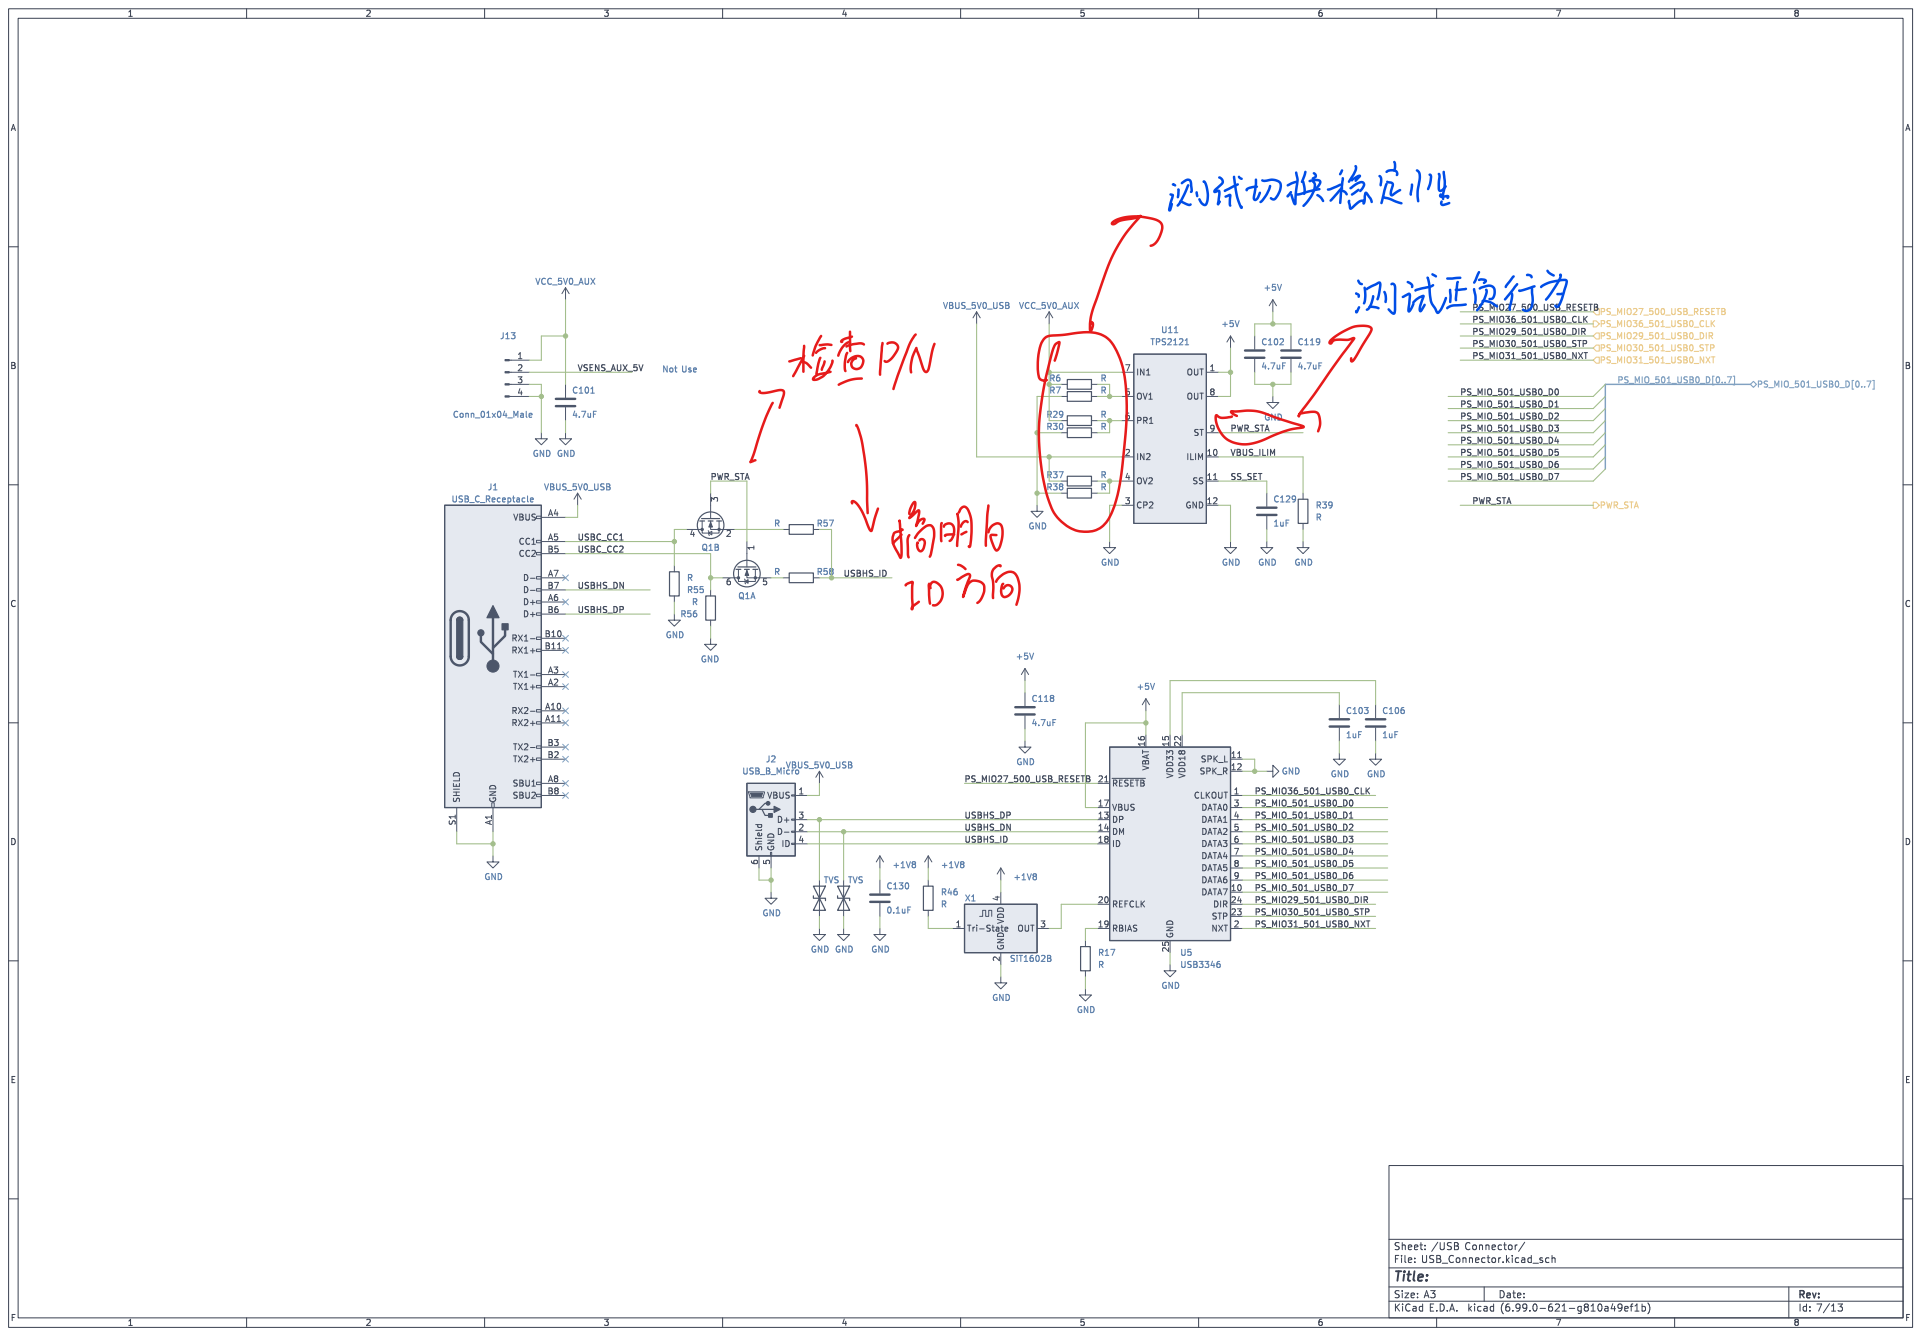
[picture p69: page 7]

2 OUT VDD 3 X1 4 SiT1602B GND GND GND GND

File: USB_Connector.kicad_sch Sheet: /USB Connector/

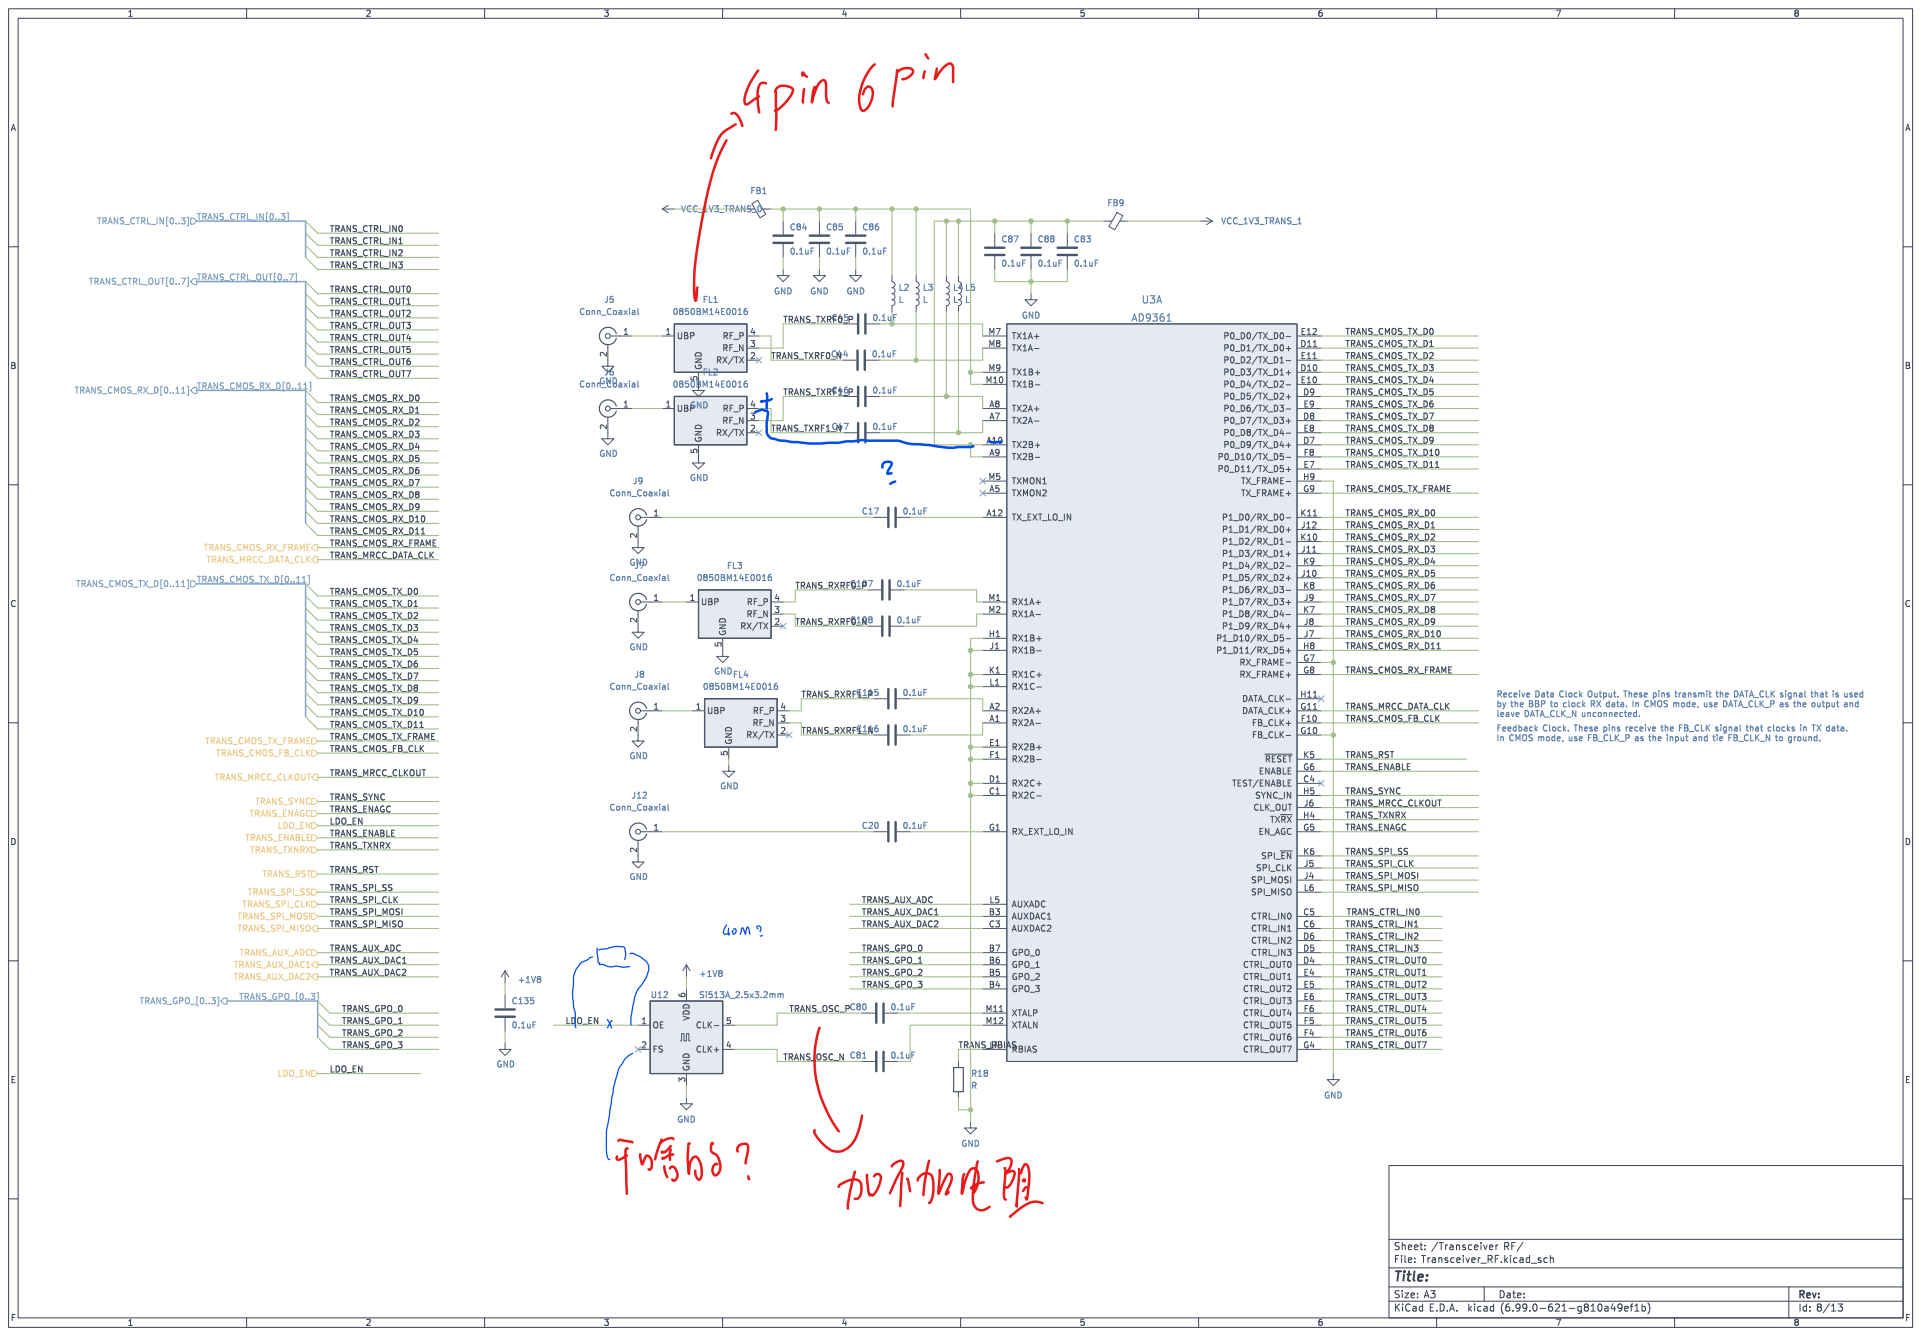
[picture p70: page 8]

2 J7 Conn_Coaxial UBP 1 RX/TX 2 RF_N 3 RF_P 4 GND

Receive Data Clock Output. These pins transmit the DATA_CLK signal that is used
by the BBP to clock RX data. In CMOS mode, use DATA_CLK_P as the output and
leave DATA_CLK_N unconnected.
TRANS_CTRL_OUT1 TRANS_SYNC
TRANS_MRCC_CLKOUT
TRANS_TXNRX
TRANS_SPI_MOSI TRANS_ENAGC

In CMOS mode, use FB_CLK_P as the input and tie FB_CLK_N to ground.

File: Transceiver_RF.kicad_sch Sheet: /Transceiver RF/

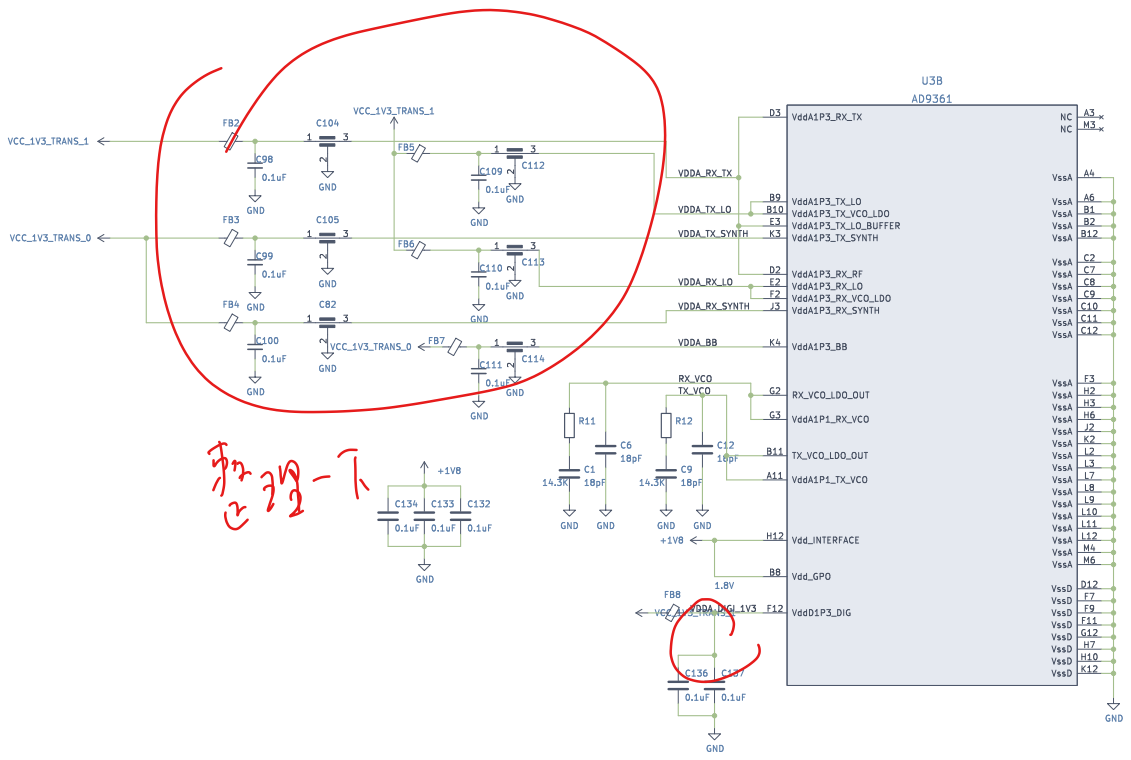
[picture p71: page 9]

File: Transceiver_Power.kicad_sch Sheet: /Transceiver Powr/

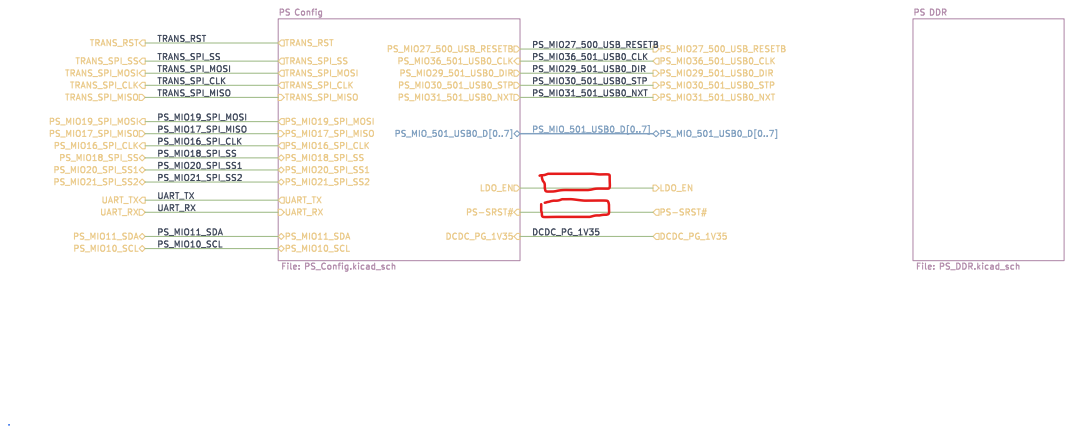
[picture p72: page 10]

Sheet: /ZYNQ PS Part/
File: ZYNQ_PS.kicad_sch
Id: 11/13 Title:

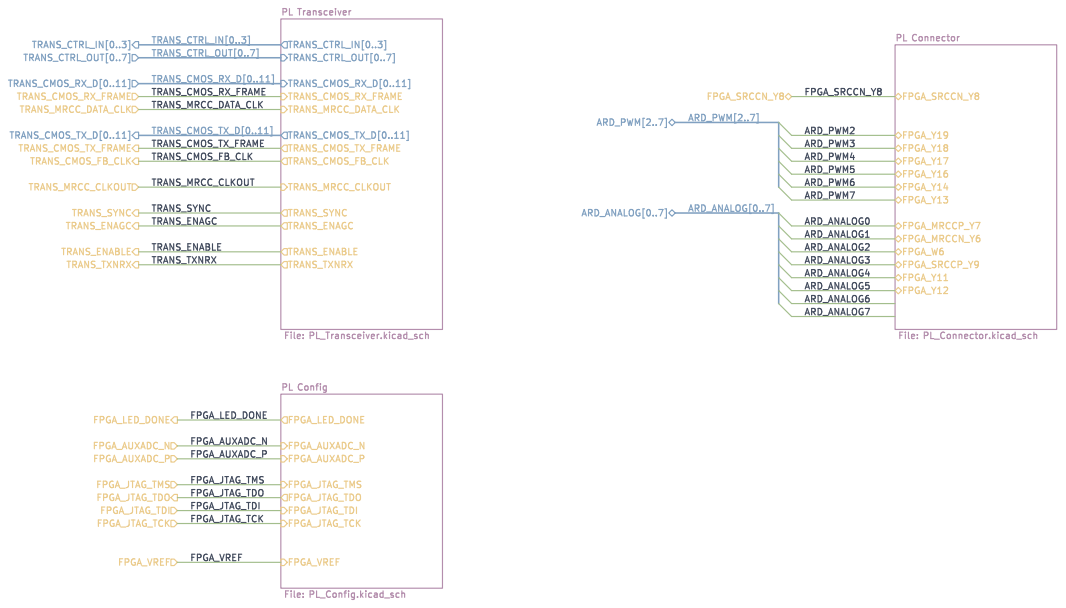
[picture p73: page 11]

Sheet: /ZYNQ PL Part/
File: ZYNQ_PL.kicad_sch
Id: 12/13 Title:

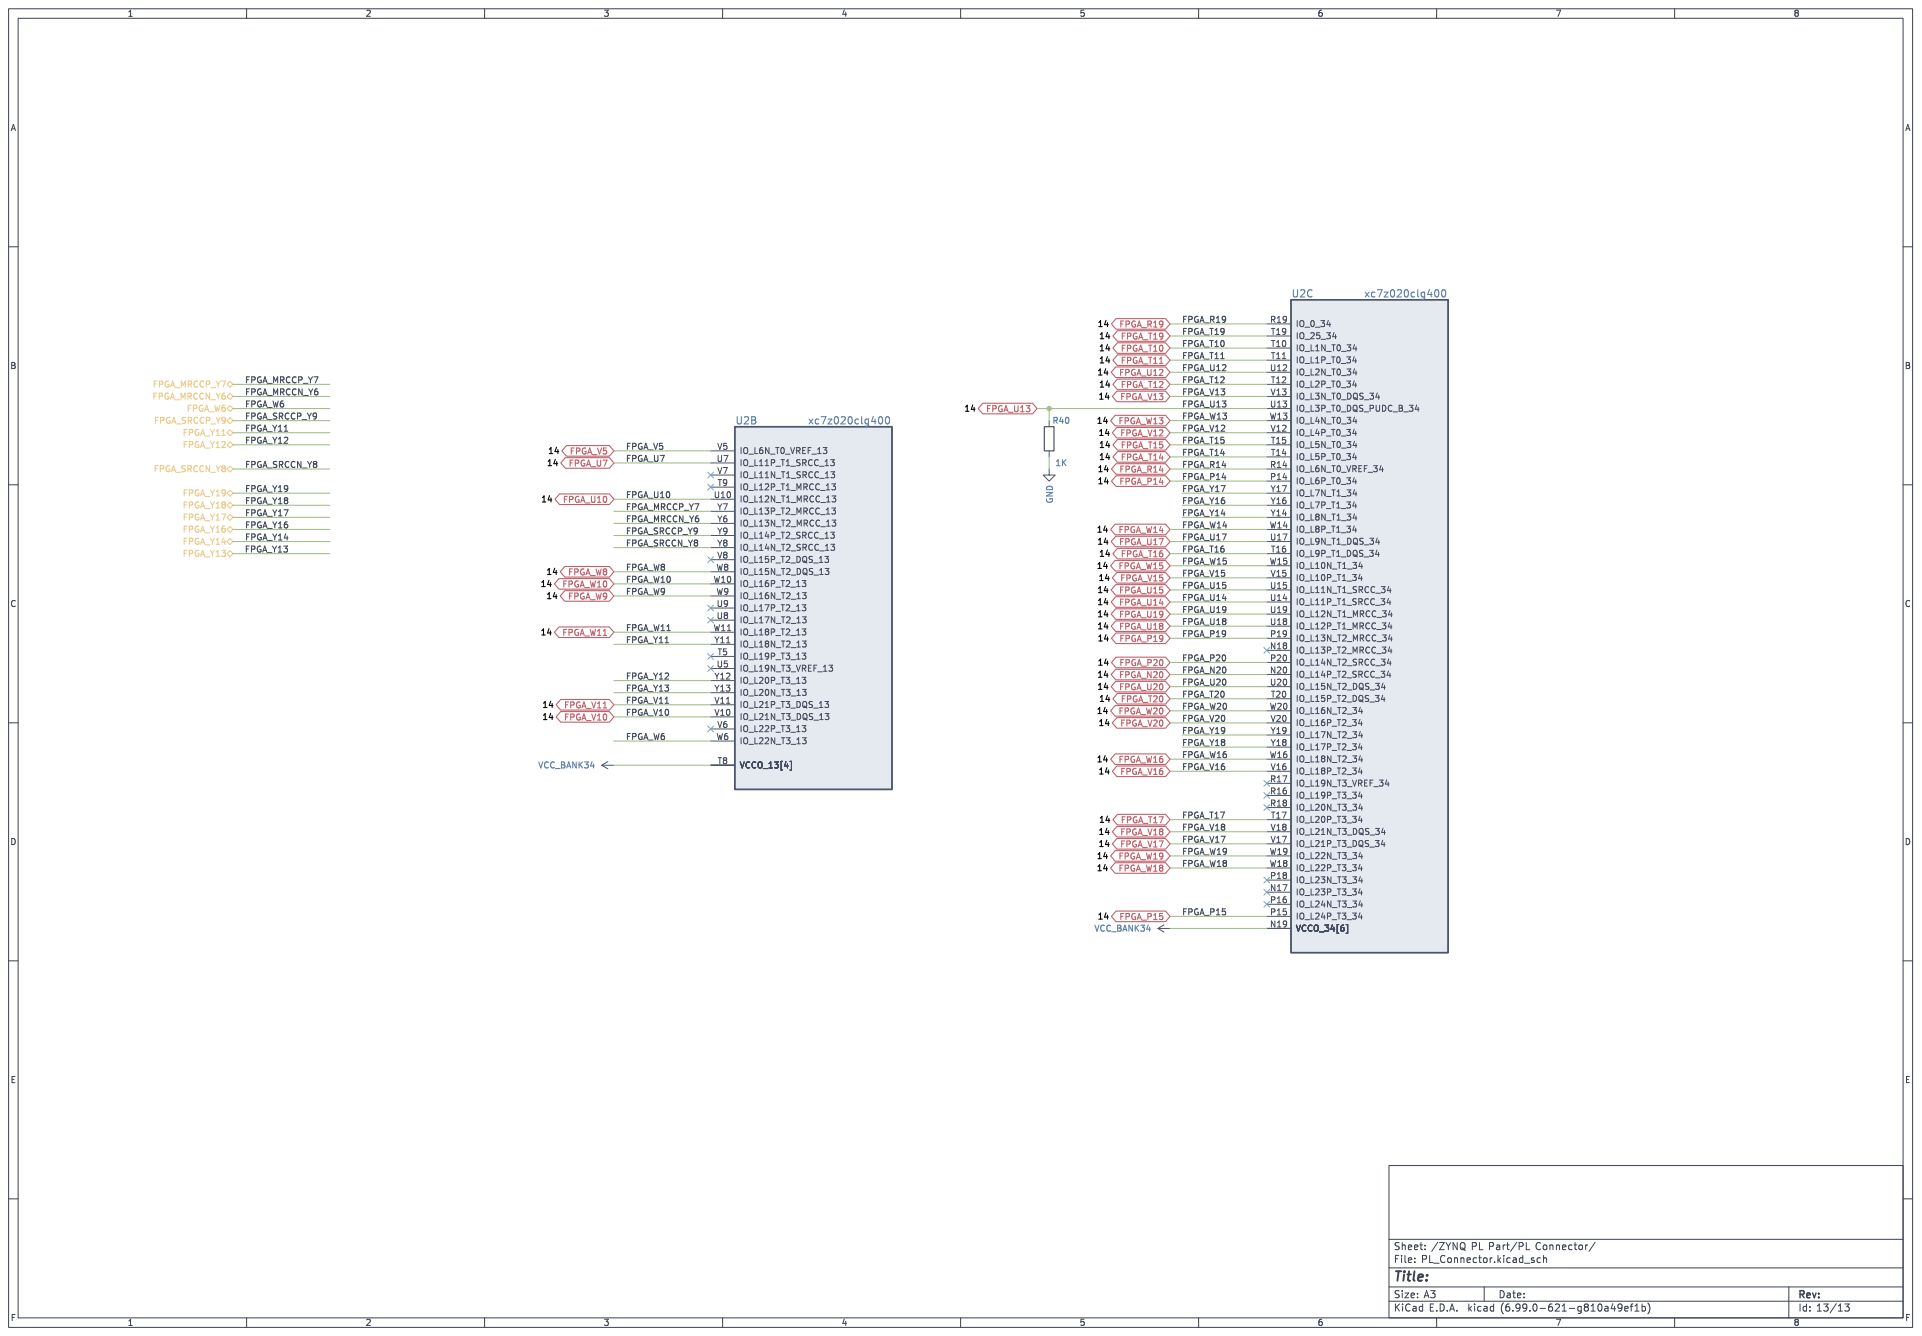
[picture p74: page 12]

Sheet: /ZYNQ PL Part/PL Connector/
File: PL_Connector.kicad_sch
Id: 13/13 Title:


File: BTB_Connector.kicad_sch Sheet: /BTB Connector/ GND

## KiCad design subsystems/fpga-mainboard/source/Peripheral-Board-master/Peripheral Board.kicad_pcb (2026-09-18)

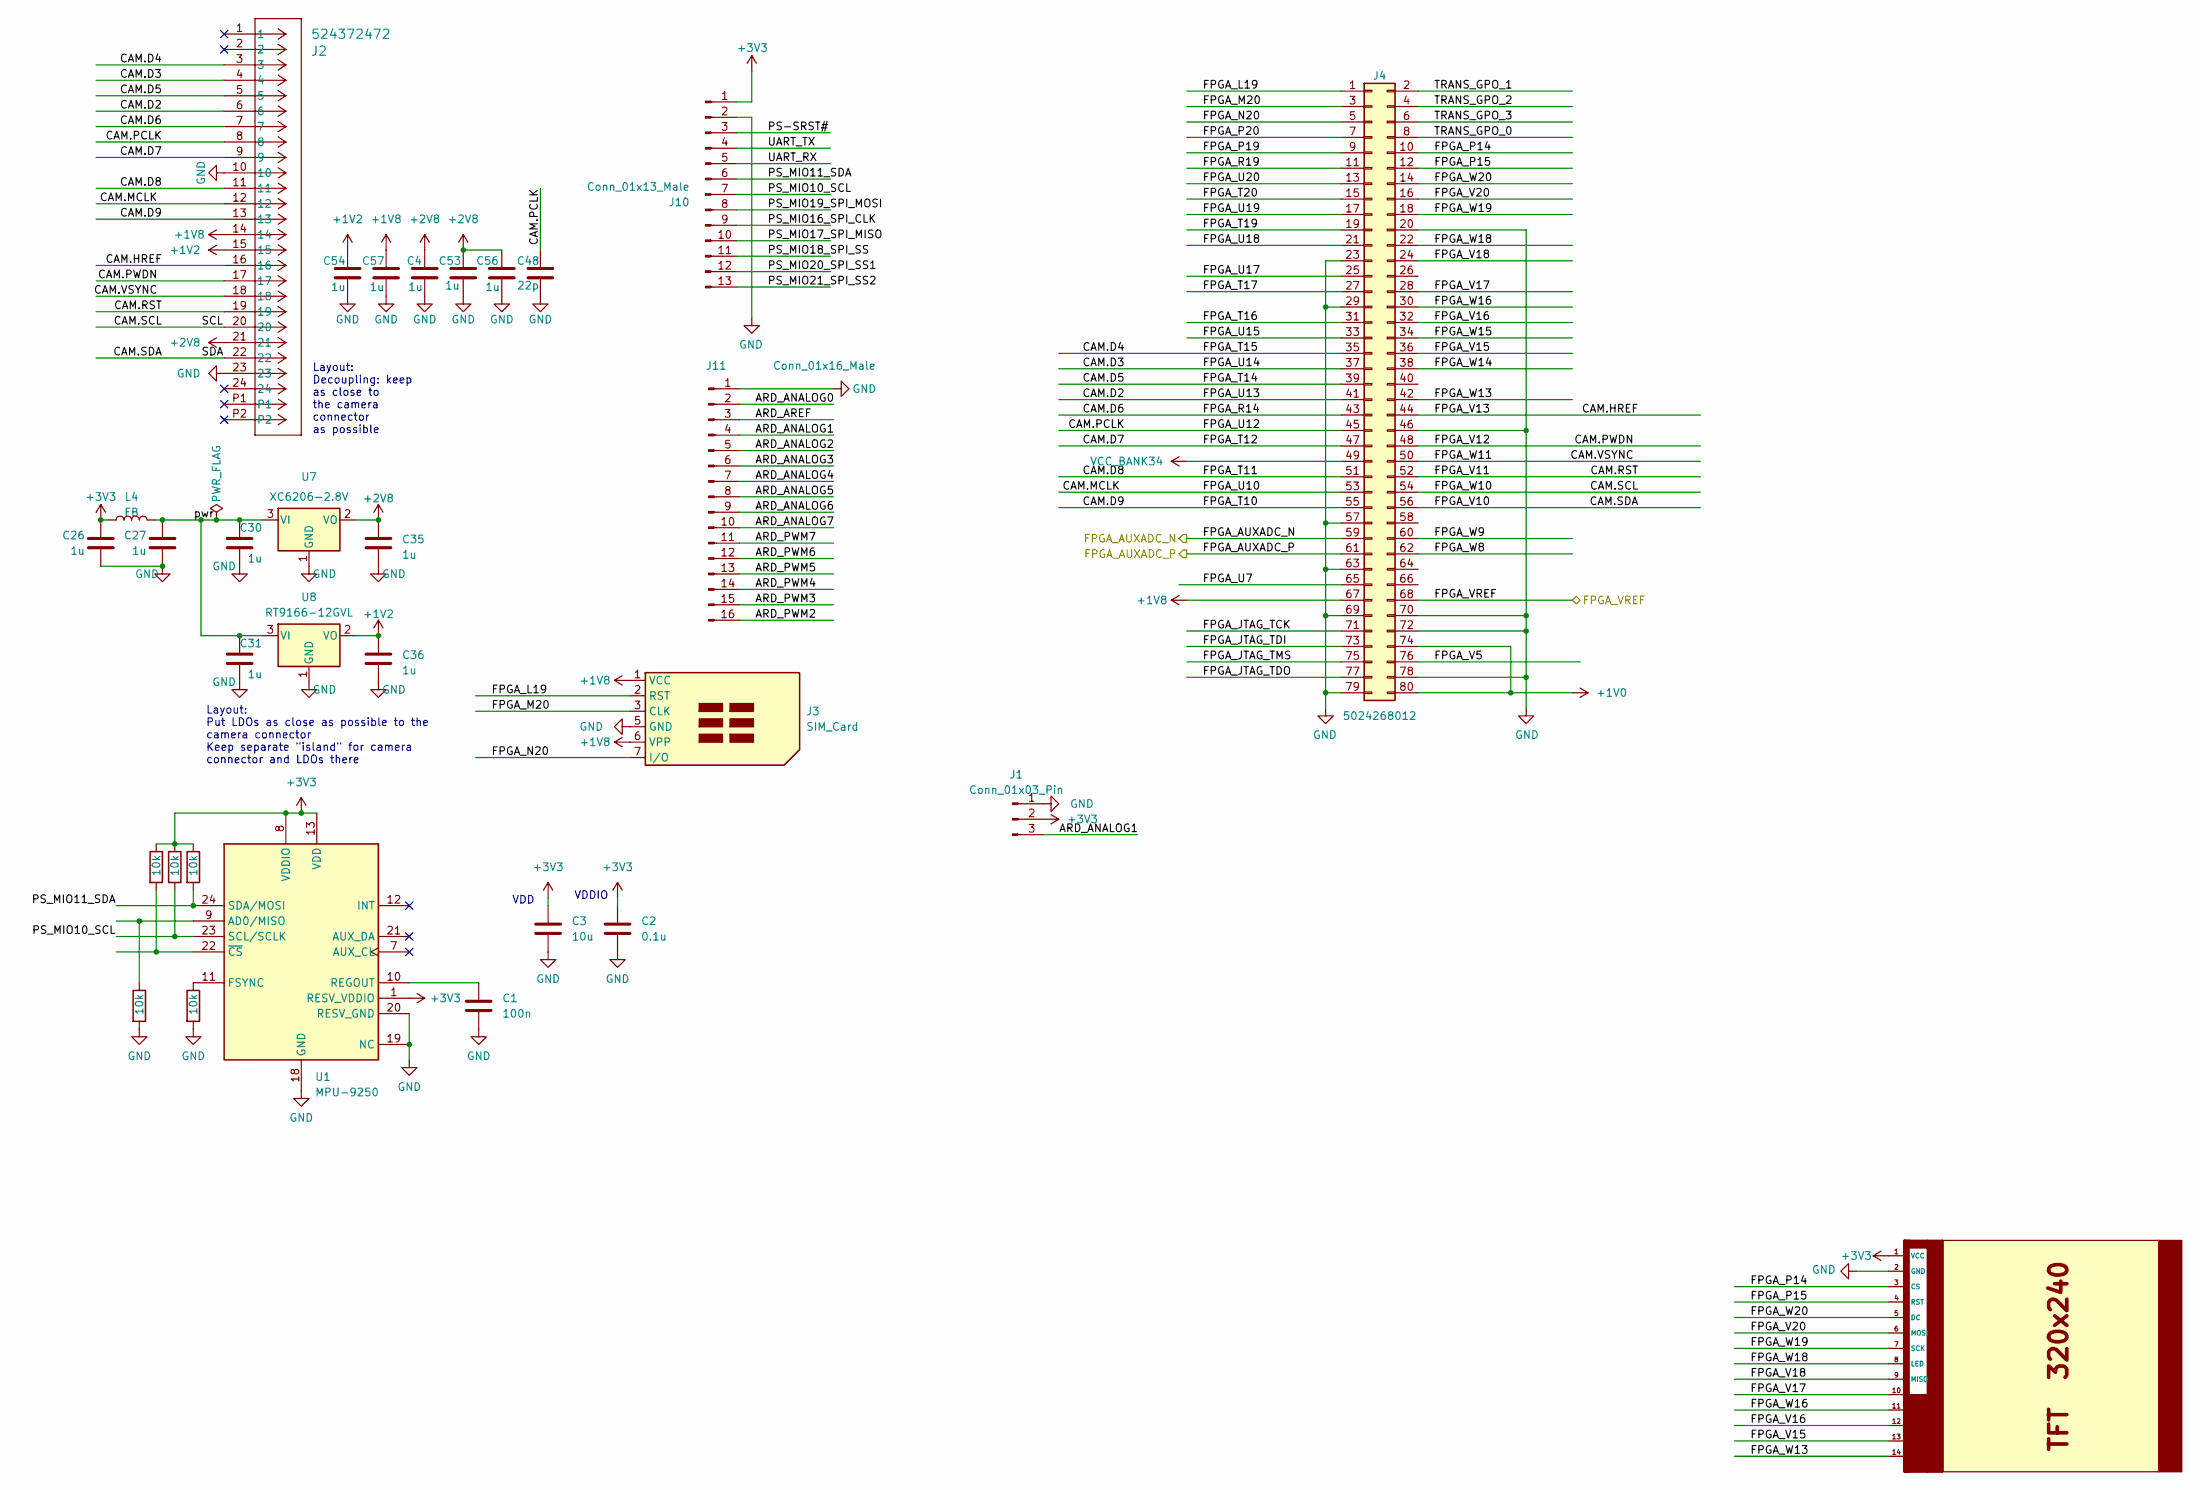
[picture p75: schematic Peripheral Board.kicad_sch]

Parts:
C1: 100n; C_0402_1005Metric_Pad0.74x0.62mm_HandSolder; LCSC C77020
C2, C3, C26, C27, C30, C31, C35, C36, C53: 10u_0402_CL05A105KA5NQNC; C_0402_1005Metric; Rating 25V; Tolerance 10%; MPN CL05A105KA5NQNC
C4, C54, C56, C57: 10u_0402_CL05A105KA5NQNC; C_0402_1005Metric; Tolerance 10%; Rating 25V; MPN CL05A105KA5NQNC
C48: 22p_0402_0402CG220J500NT; C_0402_1005Metric; Rating 50V; Tolerance 5%; MPN 0402CG220J500NT
J1: Conn_01x03_Pin; PinHeader_1x03_P2.54mm_Vertical
J2: 524372472; CON_524372472_MOL
J3: SIM_Card; nanoSIM_GCT_SIM8060-6-0-14-00
J4: 5024268012; Molex_SlimStack_502430-8010_2x40_P0.40mm_Vertical
J10: Conn_01x13_Male; PinHeader_1x13_P2.54mm_Vertical
J11: Conn_01x16_Male; PinHeader_1x16_P2.54mm_Vertical
L4: FB_2A_0805_220R@100MHz_BLM21PG221SN1D; L_0805_2012Metric_Pad1.15x1.40mm_HandSolder; Rating 2A; MPN BLM21PG221SN1D
R10, R11, R15, R16, R17: 10k; R_0402_1005Metric; LCSC C25543
U1: MPU-9250; InvenSense_QFN-24_3x3mm_P0.4mm
U5: TFT_320x240; TFT-320x240
U7: XC6206-2.8V; SOT-23; MPN XC6206-2.8V
U8: RT9166-12GVL; SOT-23; MPN RT9166-12GVL

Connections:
+1V0: J4.74, J4.80
+1V2: C36.1, C54.2, J2.15, U8.2 (VO)
+1V8: C57.2, J2.14, J3.1 (VCC), J3.6 (VPP), J4.67
+2V8: C4.2, C35.1, C53.1, C56.2, J2.21, U7.2 (VO)
+3V3: C2.1, C3.1, C26.1, J1.2, J10.1, L4.1, R10.1, R11.1, R15.1, U1.1 (RESV_VDDIO), U1.8 (VDDIO), U1.13 (VDD), U5.1 (VCC)
/ARD_ANALOG0: J11.2
/ARD_ANALOG1: J1.3, J11.4
/ARD_ANALOG2: J11.5
/ARD_ANALOG3: J11.6
/ARD_ANALOG4: J11.7
/ARD_ANALOG5: J11.8
/ARD_ANALOG6: J11.9
/ARD_ANALOG7: J11.10
/ARD_AREF: J11.3
/ARD_PWM2: J11.16
/ARD_PWM3: J11.15
/ARD_PWM4: J11.14
/ARD_PWM5: J11.13
/ARD_PWM6: J11.12
/ARD_PWM7: J11.11
/CAM.D2: J2.6, J4.41
/CAM.D3: J2.4, J4.37
/CAM.D4: J2.3, J4.35
/CAM.D5: J2.5, J4.39
/CAM.D6: J2.7, J4.43
/CAM.D7: J2.9, J4.47
/CAM.D8: J2.11, J4.51
/CAM.D9: J2.13, J4.55
/CAM.HREF: J2.16, J4.44
/CAM.MCLK: J2.12, J4.53
/CAM.PCLK: C48.1, J2.8, J4.45
/CAM.PWDN: J2.17, J4.48
/CAM.RST: J2.19, J4.52
/CAM.SCL: J2.20, J4.54
/CAM.SDA: J2.22, J4.56
/CAM.VSYNC: J2.18, J4.50
/FPGA_AUXADC_N: J4.59
/FPGA_AUXADC_P: J4.61
/FPGA_JTAG_TCK: J4.71
/FPGA_JTAG_TDI: J4.73
/FPGA_JTAG_TDO: J4.77
/FPGA_JTAG_TMS: J4.75
/FPGA_L19: J3.2 (RST), J4.1
/FPGA_M20: J3.3 (CLK), J4.3
/FPGA_N20: J3.7 (I/O), J4.5
/FPGA_P14: J4.10, U5.3 (CS)
/FPGA_P15: J4.12, U5.4 (RST)
/FPGA_P19: J4.9
/FPGA_P20: J4.7
/FPGA_R19: J4.11
/FPGA_T16: J4.31
/FPGA_T17: J4.27
/FPGA_T19: J4.19
/FPGA_T20: J4.15
/FPGA_U7: J4.65
/FPGA_U15: J4.33
/FPGA_U17: J4.25
/FPGA_U18: J4.21
/FPGA_U19: J4.17
/FPGA_U20: J4.13
/FPGA_V5: J4.76
/FPGA_V15: J4.36, U5.13
/FPGA_V16: J4.32, U5.12
/FPGA_V17: J4.28, U5.10
/FPGA_V18: J4.24, U5.9 (MISO)
/FPGA_V20: J4.16, U5.6 (MOSI)
/FPGA_VREF: J4.68
/FPGA_W8: J4.62
/FPGA_W9: J4.60
/FPGA_W13: J4.42, U5.14
/FPGA_W14: J4.38
/FPGA_W15: J4.34
/FPGA_W16: J4.30, U5.11
/FPGA_W18: J4.22, U5.8 (LED)
/FPGA_W19: J4.18, U5.7 (SCK)
/FPGA_W20: J4.14, U5.5 (DC)
/PS-SRST#: J10.3
/PS_MIO10_SCL: J10.7, R11.2, U1.23 (SCL/SCLK)
/PS_MIO11_SDA: J10.6, R10.2, U1.24 (SDA/MOSI)
/PS_MIO16_SPI_CLK: J10.9
/PS_MIO17_SPI_MISO: J10.10
/PS_MIO18_SPI_SS: J10.11
/PS_MIO19_SPI_MOSI: J10.8
/PS_MIO20_SPI_SS1: J10.12
/PS_MIO21_SPI_SS2: J10.13
/TRANS_GPO_0: J4.8
/TRANS_GPO_1: J4.2
/TRANS_GPO_2: J4.4
/TRANS_GPO_3: J4.6
/UART_RX: J10.5
/UART_TX: J10.4
/pwr: C27.1, C30.1, C31.1, L4.2, U7.3 (VI), U8.3 (VI)
GND: C1.2, C2.2, C3.2, C4.1, C26.2, C27.2, C30.2, C31.2, C35.2, C36.2, C48.2, C53.2, C54.1, C56.1, C57.1, J1.1, J2.10, J2.23, J3.5 (GND), J4.20, J4.23, J4.29, J4.46, J4.57, J4.63, J4.69, J4.70, J4.72, J4.78, J4.79, J10.2, J11.1, R16.2, R17.2, U1.18 (GND), U1.19 (NC), U1.20 (RESV_GND), U5.2 (GND), U7.1 (GND), U8.1 (GND)
unnamed: R17.1, U1.9 (AD0/MISO)
unnamed: R16.1, U1.11 (FSYNC)
unnamed: C1.1, U1.10 (REGOUT)
unnamed: R15.2, U1.22 (~CS)
VCC_BANK34: J4.49

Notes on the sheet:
VDD
Layout: Decoupling: keep as close to the camera connector as possible
Layout: Put LDOs as close as possible to the camera connector Keep separate "island" for camera connector and LDOs there
VDDIO

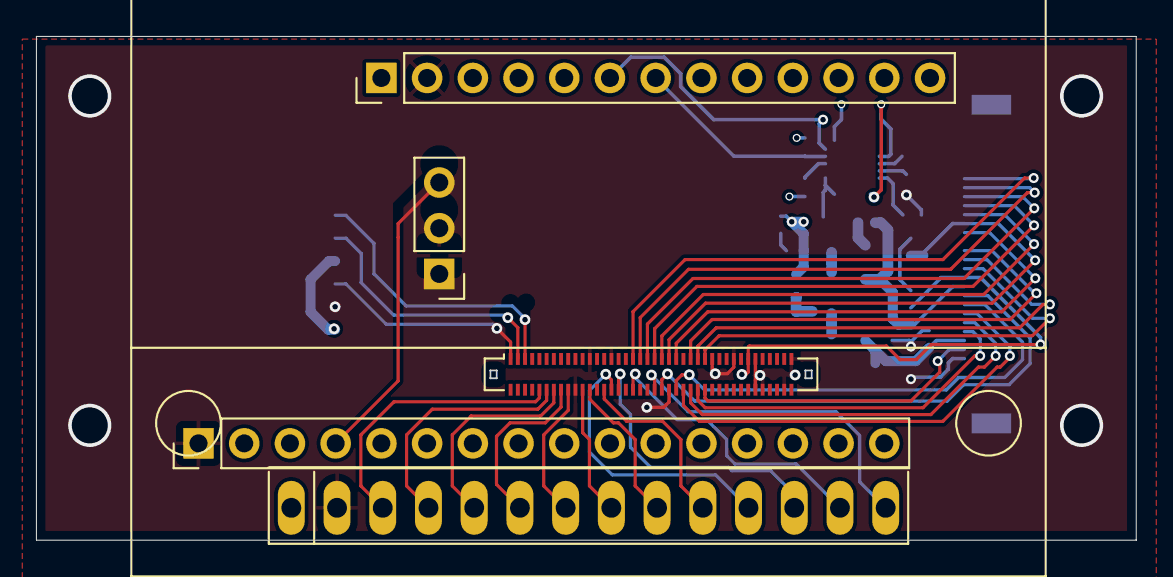
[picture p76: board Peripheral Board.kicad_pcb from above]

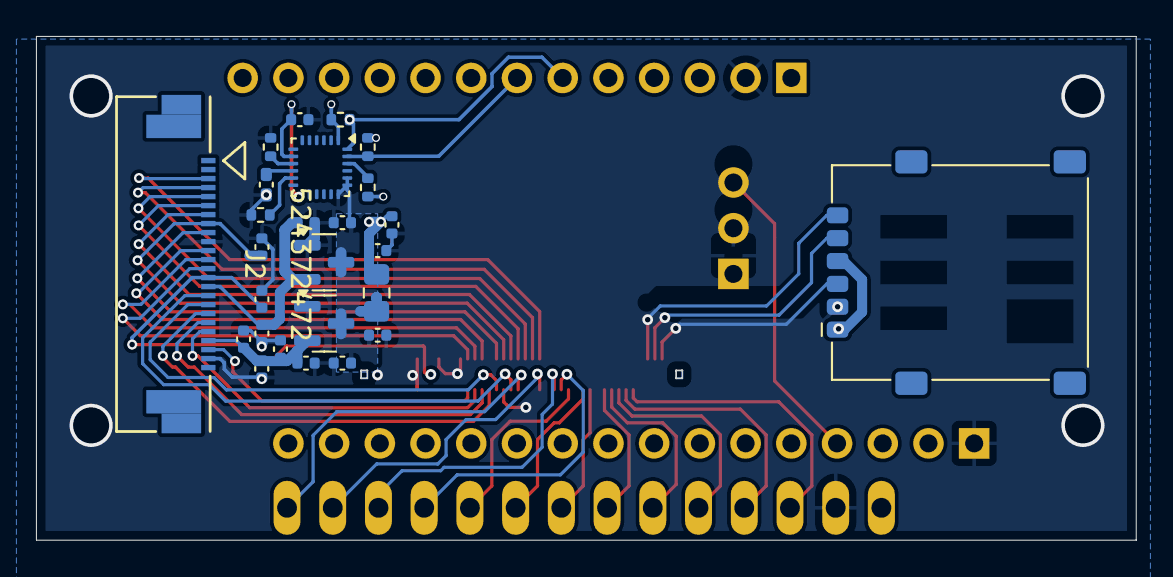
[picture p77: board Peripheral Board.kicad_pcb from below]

Board: 4 copper layers, 61.1 x 28.0 mm, 31 parts (26 on the bottom side), 45 nets.

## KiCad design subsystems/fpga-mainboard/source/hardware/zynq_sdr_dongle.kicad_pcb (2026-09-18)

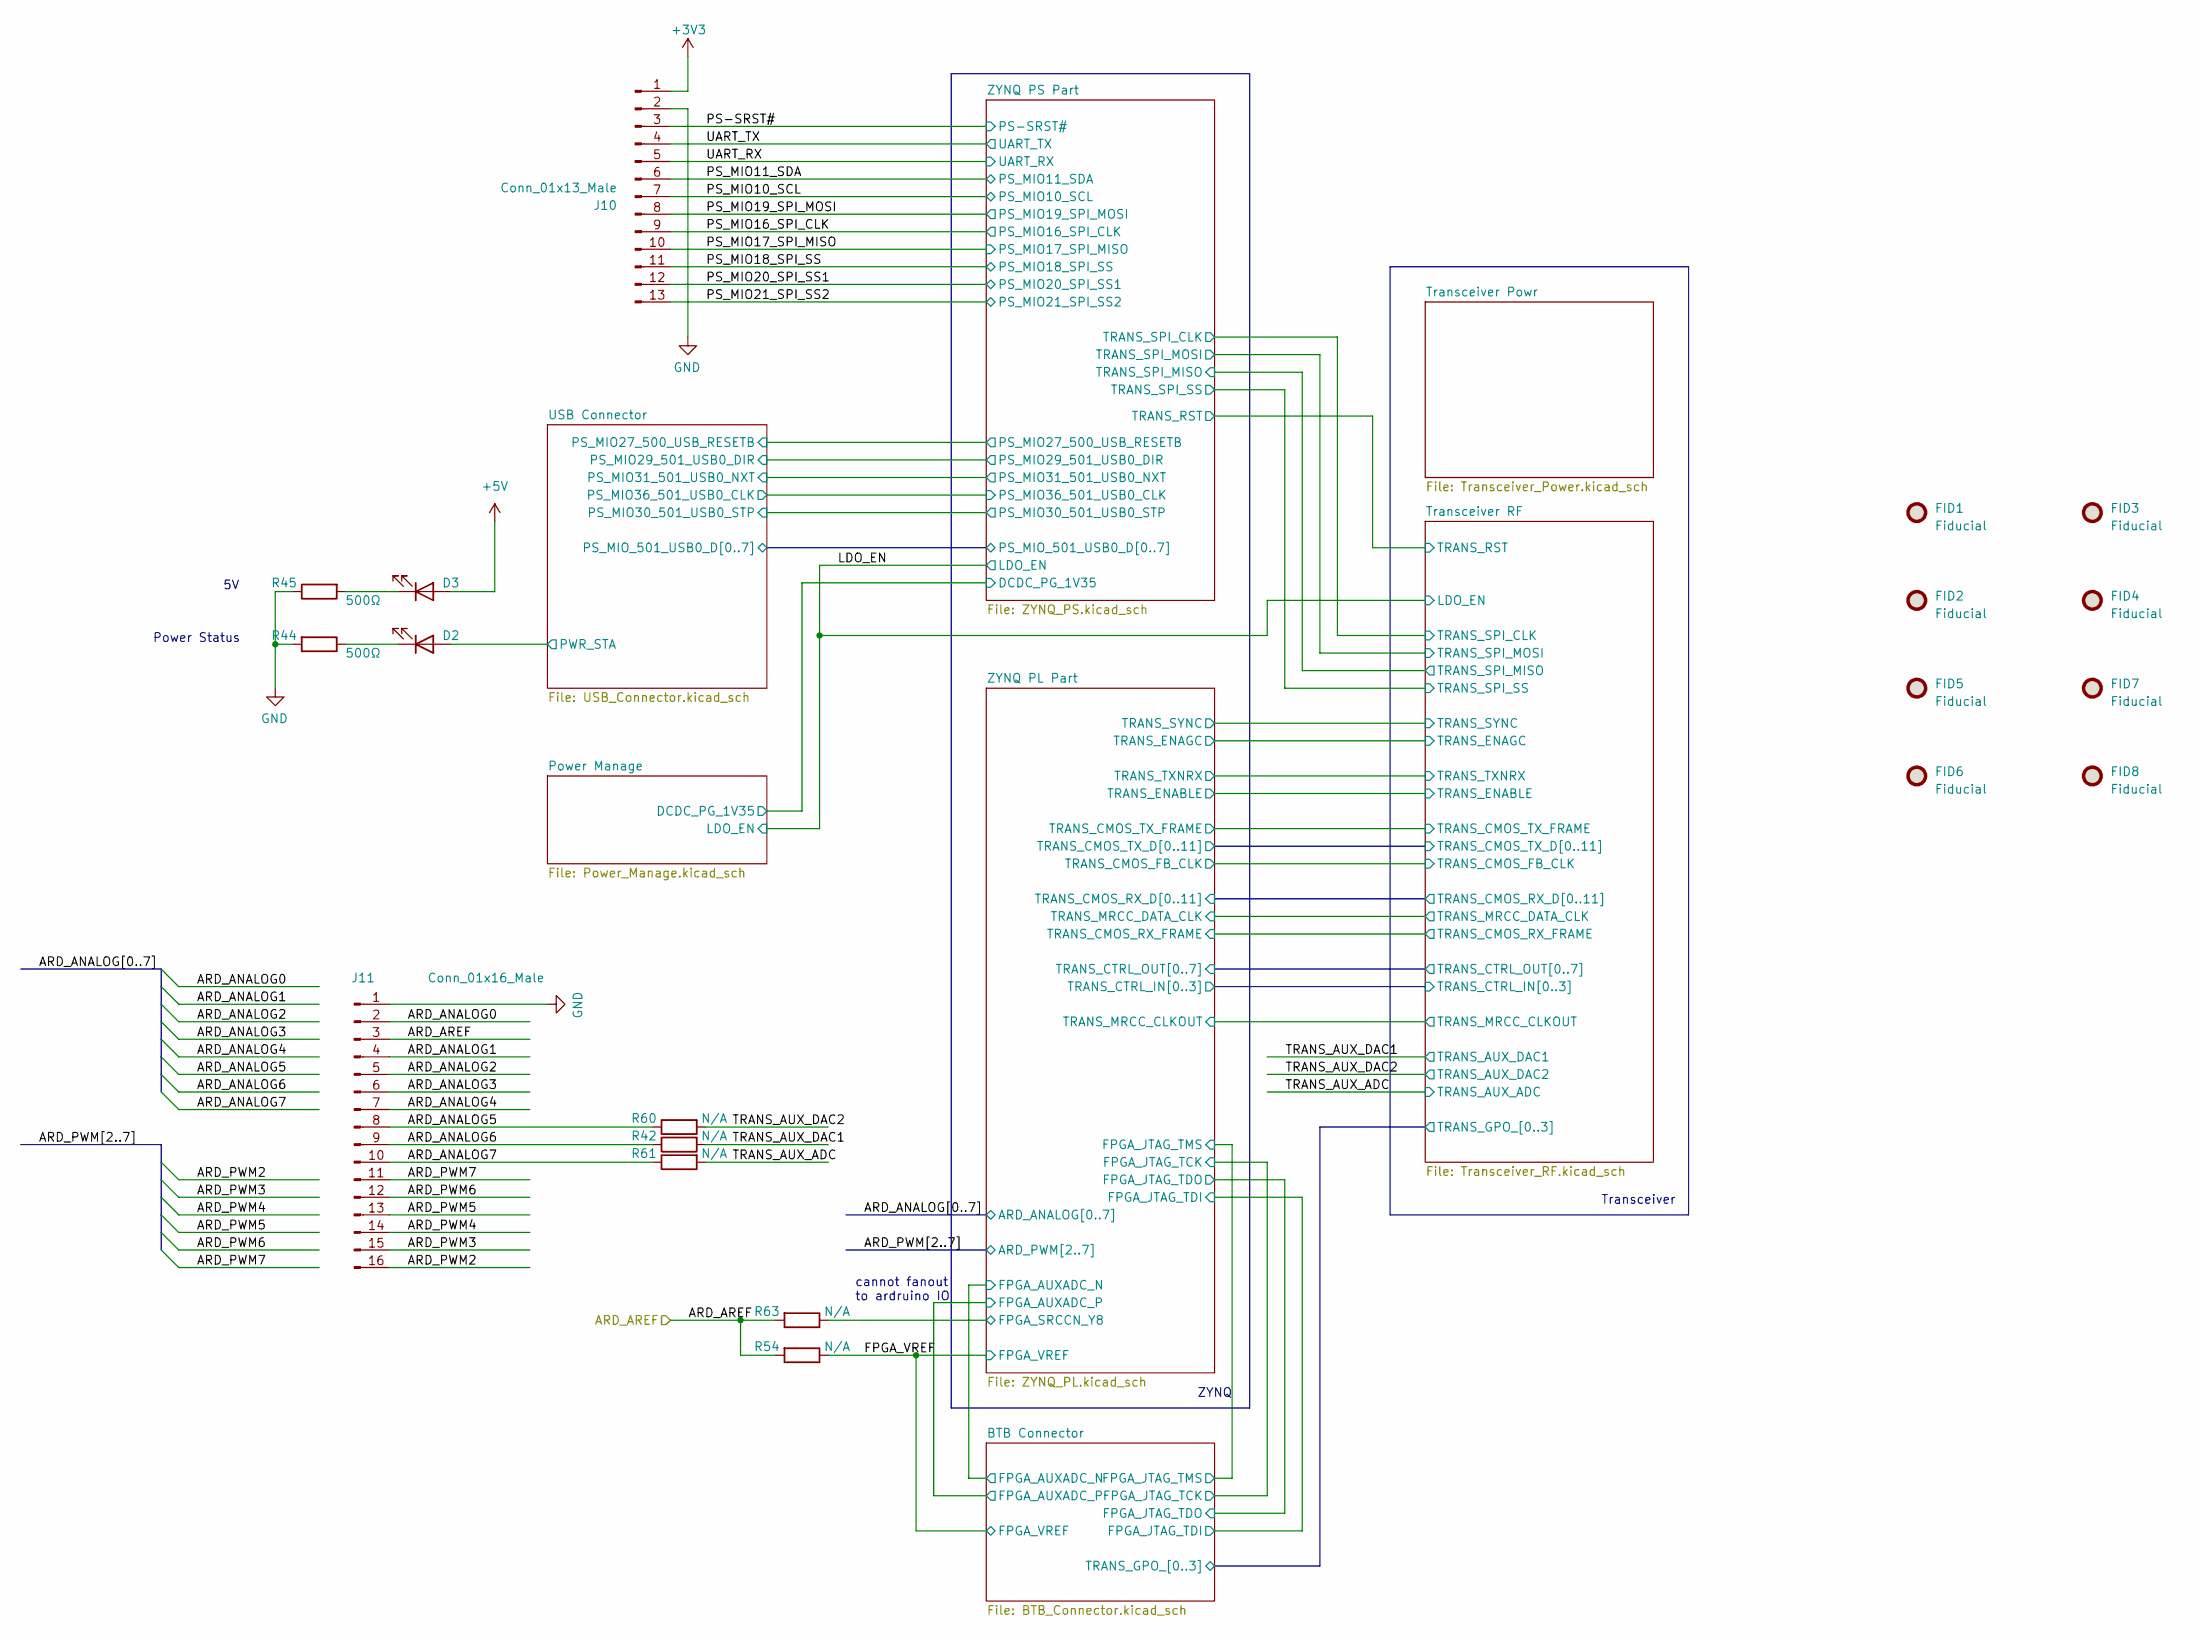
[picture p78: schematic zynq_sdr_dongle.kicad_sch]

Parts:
D2, D3: LED; LED_0201_0603Metric
FID1, FID2, FID3, FID4, FID5, FID6, FID7, FID8: Fiducial; Fiducial_0.75mm_Mask2.25mm
J10: Conn_01x13_Male; PinHeader_1x13_P2.54mm_Vertical
J11: Conn_01x16_Male; PinHeader_1x16_P2.54mm_Vertical
R42, R54, R60, R61, R63: N/A; R_0201_0603Metric
R44, R45: 500Ω; R_0201_0603Metric

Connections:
+3V3: J10.1; also elsewhere on the board
+5V: D3.2 (A); also elsewhere on the board
/ARD_ANALOG0: J11.2; also elsewhere on the board
/ARD_ANALOG1: J11.4; also elsewhere on the board
/ARD_ANALOG2: J11.5; also elsewhere on the board
/ARD_ANALOG3: J11.6; also elsewhere on the board
/ARD_ANALOG4: J11.7; also elsewhere on the board
/ARD_ANALOG5: J11.8, R60.1; also elsewhere on the board
/ARD_ANALOG6: J11.9, R42.1
/ARD_ANALOG7: J11.10, R61.1
/ARD_AREF: J11.3, R54.2, R63.2
/ARD_PWM2: J11.16; also elsewhere on the board
/ARD_PWM3: J11.15; also elsewhere on the board
/ARD_PWM4: J11.14; also elsewhere on the board
/ARD_PWM5: J11.13; also elsewhere on the board
/ARD_PWM6: J11.12; also elsewhere on the board
/ARD_PWM7: J11.11; also elsewhere on the board
/FPGA_VREF: R54.1; also elsewhere on the board
/PS-SRST#: J10.3; also elsewhere on the board
/PS_MIO10_SCL: J10.7; also elsewhere on the board
/PS_MIO11_SDA: J10.6; also elsewhere on the board
/PS_MIO16_SPI_CLK: J10.9; also elsewhere on the board
/PS_MIO17_SPI_MISO: J10.10; also elsewhere on the board
/PS_MIO18_SPI_SS: J10.11; also elsewhere on the board
/PS_MIO19_SPI_MOSI: J10.8; also elsewhere on the board
/PS_MIO20_SPI_SS1: J10.12; also elsewhere on the board
/PS_MIO21_SPI_SS2: J10.13; also elsewhere on the board
/TRANS_AUX_ADC: R61.2; also elsewhere on the board
/TRANS_AUX_DAC1: R42.2; also elsewhere on the board
/TRANS_AUX_DAC2: R60.2; also elsewhere on the board
/UART_RX: J10.5; also elsewhere on the board
/UART_TX: J10.4; also elsewhere on the board
/USB Connector/PWR_STA: D2.2 (A); also elsewhere on the board
/ZYNQ PL Part/FPGA_SRCCN_Y8: R63.1; also elsewhere on the board
GND: J10.2, J11.1, R44.2, R45.1; also elsewhere on the board
unnamed: D2.1 (K), R44.1
unnamed: D3.1 (K), R45.2

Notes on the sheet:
Transceiver
ZYNQ
cannot fanout to ardruino IO
Power Status

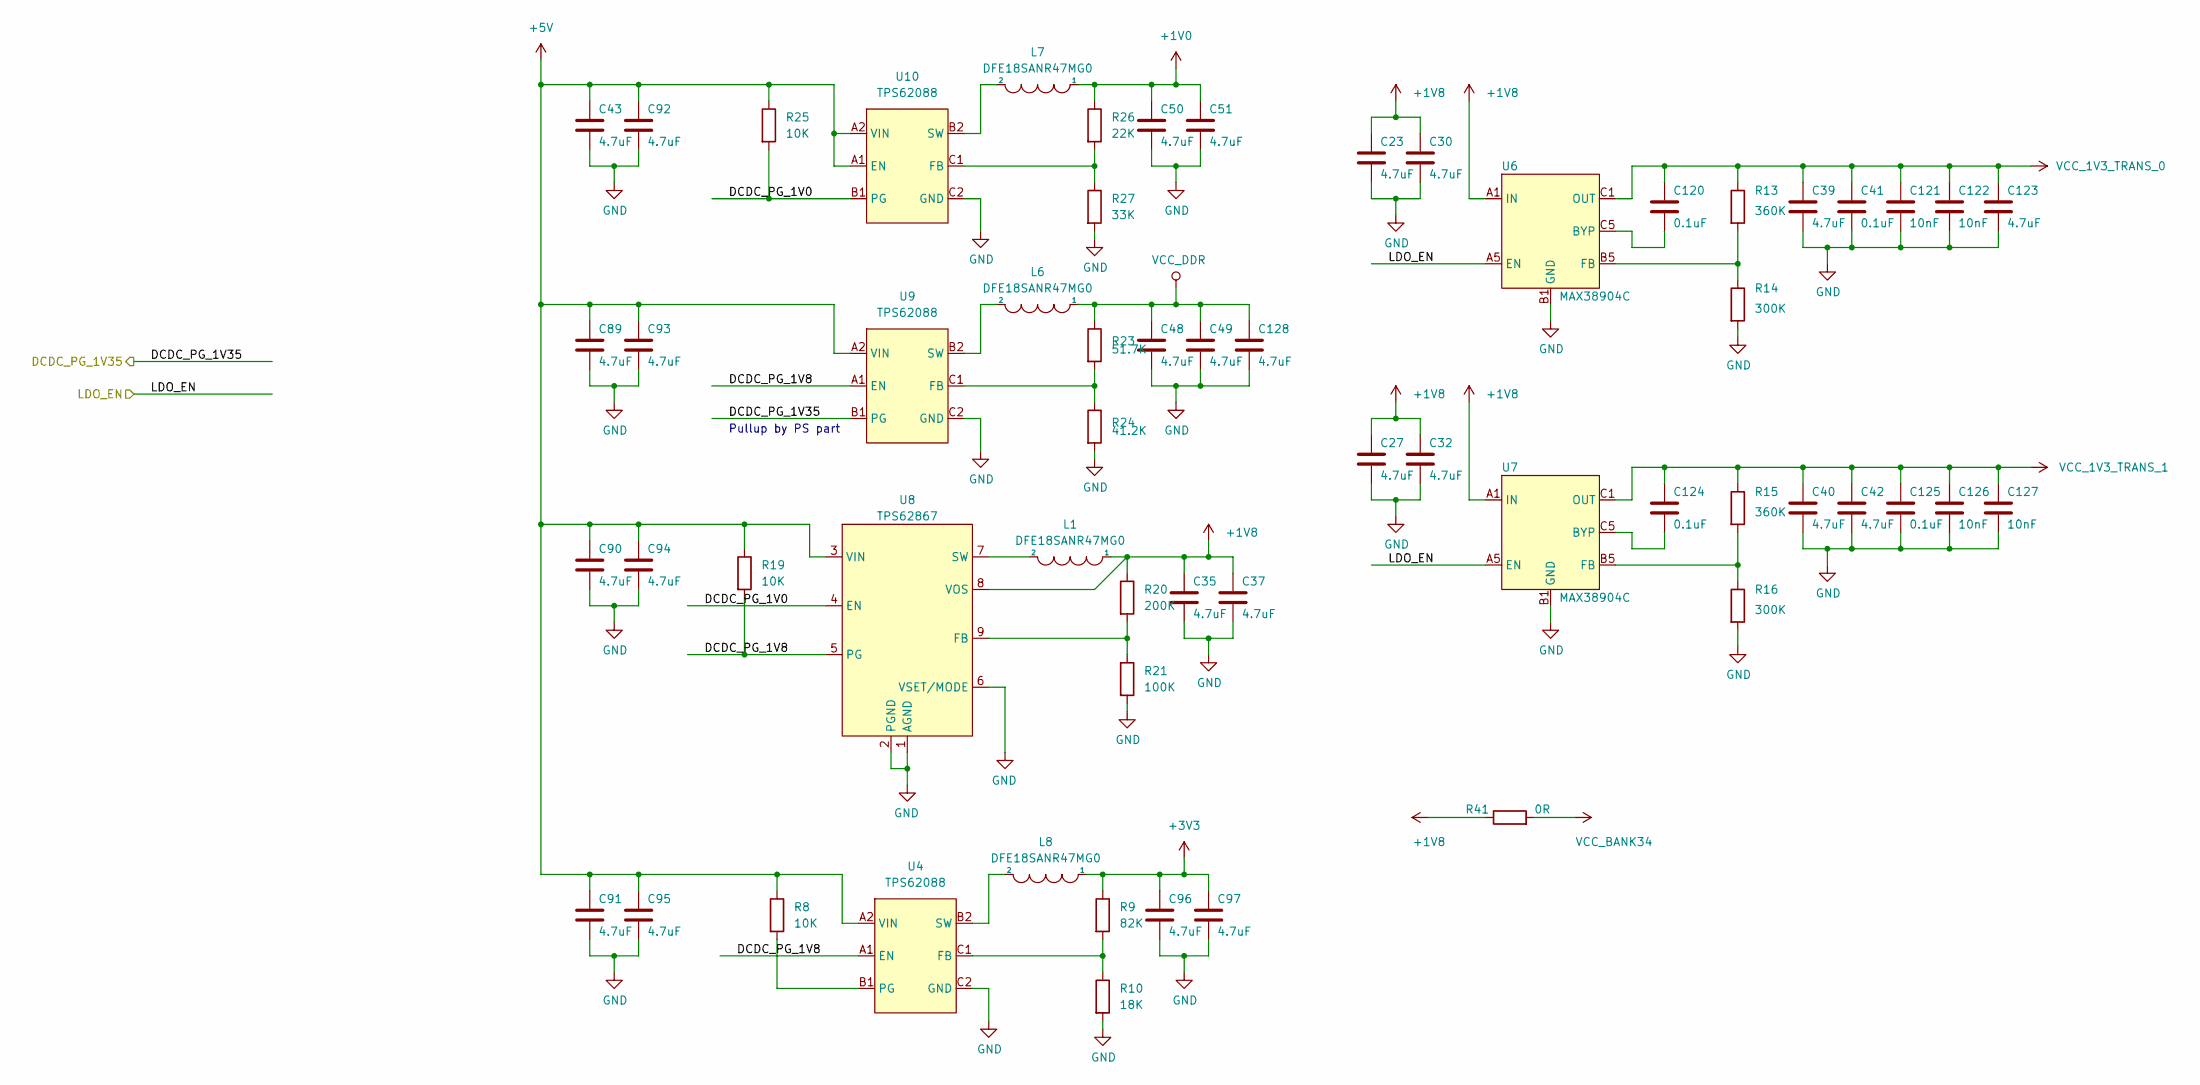
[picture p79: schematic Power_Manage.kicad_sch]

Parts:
C23, C27, C30, C32, C35, C37, C39, C40, C42, C43, C48, C49, C50, C51, C89, C90, C91, C92, C93, C94, C95, C96, C97, C123, C128: 4.7uF; C_0402_1005Metric
C41, C120, C124, C125: 0.1uF; C_0402_1005Metric
C121, C122, C126, C127: 10nF; C_0402_1005Metric
L1, L6, L7, L8: DFE18SANR47MG0; L_Murata_LQH2MCNxxxx02_2.0x1.6mm
R8, R19, R25: 10K; R_0201_0603Metric
R9: 82K; R_0201_0603Metric
R10: 18K; R_0201_0603Metric
R13, R15: 360K; R_0201_0603Metric
R14, R16: 300K; R_0201_0603Metric
R20: 200K; R_0201_0603Metric
R21: 100K; R_0201_0603Metric
R23: 51.7K; R_0201_0603Metric
R24: 41.2K; R_0201_0603Metric
R26: 22K; R_0201_0603Metric
R27: 33K; R_0201_0603Metric
R41: 0R; R_0402_1005Metric
U4, U9, U10: TPS62088; PowerWCSP-6
U6, U7: MAX38904C; wlp-15_2p168_1p338_0p5_0p4
U8: TPS62867; VQFN-HR

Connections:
+1V0: C50.1, C51.1, L7.1, R26.1; also elsewhere on the board
+1V8: C23.1, C27.1, C30.1, C32.1, C35.1, C37.1, L1.1, R20.1, R41.1, U6.A1 (IN), U6.A2 (IN), U6.A3 (IN), U6.A4 (IN), U7.A1 (IN), U7.A2 (IN), U7.A3 (IN), U7.A4 (IN), U8.8 (VOS); also elsewhere on the board
+3V3: C96.1, C97.1, L8.1, R9.1; also elsewhere on the board
+5V: C43.1, C89.1, C90.1, C91.1, C92.1, C93.1, C94.1, C95.1, R8.1, R19.1, R25.1, U4.A2 (VIN), U8.3 (VIN), U9.A2 (VIN), U10.A1 (EN), U10.A2 (VIN); also elsewhere on the board
/LDO_EN: U6.A5 (EN), U7.A5 (EN); also elsewhere on the board
/Power Manage/DCDC_PG_1V0: R25.2, U8.4 (EN), U10.B1 (PG)
/Power Manage/DCDC_PG_1V8: R19.2, U4.A1 (EN), U8.5 (PG), U9.A1 (EN)
/Power Manage/DCDC_PG_1V35: U9.B1 (PG); also elsewhere on the board
GND: C23.2, C27.2, C30.2, C32.2, C35.2, C37.2, C39.2, C40.2, C41.2, C42.2, C43.2, C48.2, C49.2, C50.2, C51.2, C89.2, C90.2, C91.2, C92.2, C93.2, C94.2, C95.2, C96.2, C97.2, C121.2, C122.2, C123.2, C125.2, C126.2, C127.2, C128.2, R10.2, R14.2, R16.2, R21.2, R24.2, R27.2, U4.C2 (GND), U6.B1 (GND), U6.B2 (GND), U6.B3 (GND), U6.B4 (GND), U7.B1 (GND), U7.B2 (GND), U7.B3 (GND), U7.B4 (GND), U8.1 (AGND), U8.2 (PGND), U8.6 (VSET/MODE), U9.C2 (GND), U10.C2 (GND); also elsewhere on the board
unnamed: R9.2, R10.1, U4.C1 (FB)
unnamed: R8.2, U4.B1 (PG)
unnamed: L8.2, U4.B2 (SW)
unnamed: C120.2, U6.C5 (BYP)
unnamed: R13.2, R14.1, U6.B5 (FB)
unnamed: C124.2, U7.C5 (BYP)
unnamed: R15.2, R16.1, U7.B5 (FB)
unnamed: R20.2, R21.1, U8.9 (FB)
unnamed: L1.2, U8.7 (SW)
unnamed: R23.2, R24.1, U9.C1 (FB)
unnamed: L6.2, U9.B2 (SW)
unnamed: R26.2, R27.1, U10.C1 (FB)
unnamed: L7.2, U10.B2 (SW)
VCC_1V3_TRANS_0: C39.1, C41.1, C120.1, C121.1, C122.1, C123.1, R13.1, U6.C1 (OUT), U6.C2 (OUT), U6.C3 (OUT), U6.C4 (OUT); also elsewhere on the board
VCC_1V3_TRANS_1: C40.1, C42.1, C124.1, C125.1, C126.1, C127.1, R15.1, U7.C1 (OUT), U7.C2 (OUT), U7.C3 (OUT), U7.C4 (OUT); also elsewhere on the board
VCC_BANK34: R41.2; also elsewhere on the board
VCC_DDR: C48.1, C49.1, C128.1, L6.1, R23.1; also elsewhere on the board

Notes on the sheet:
Pullup by PS part

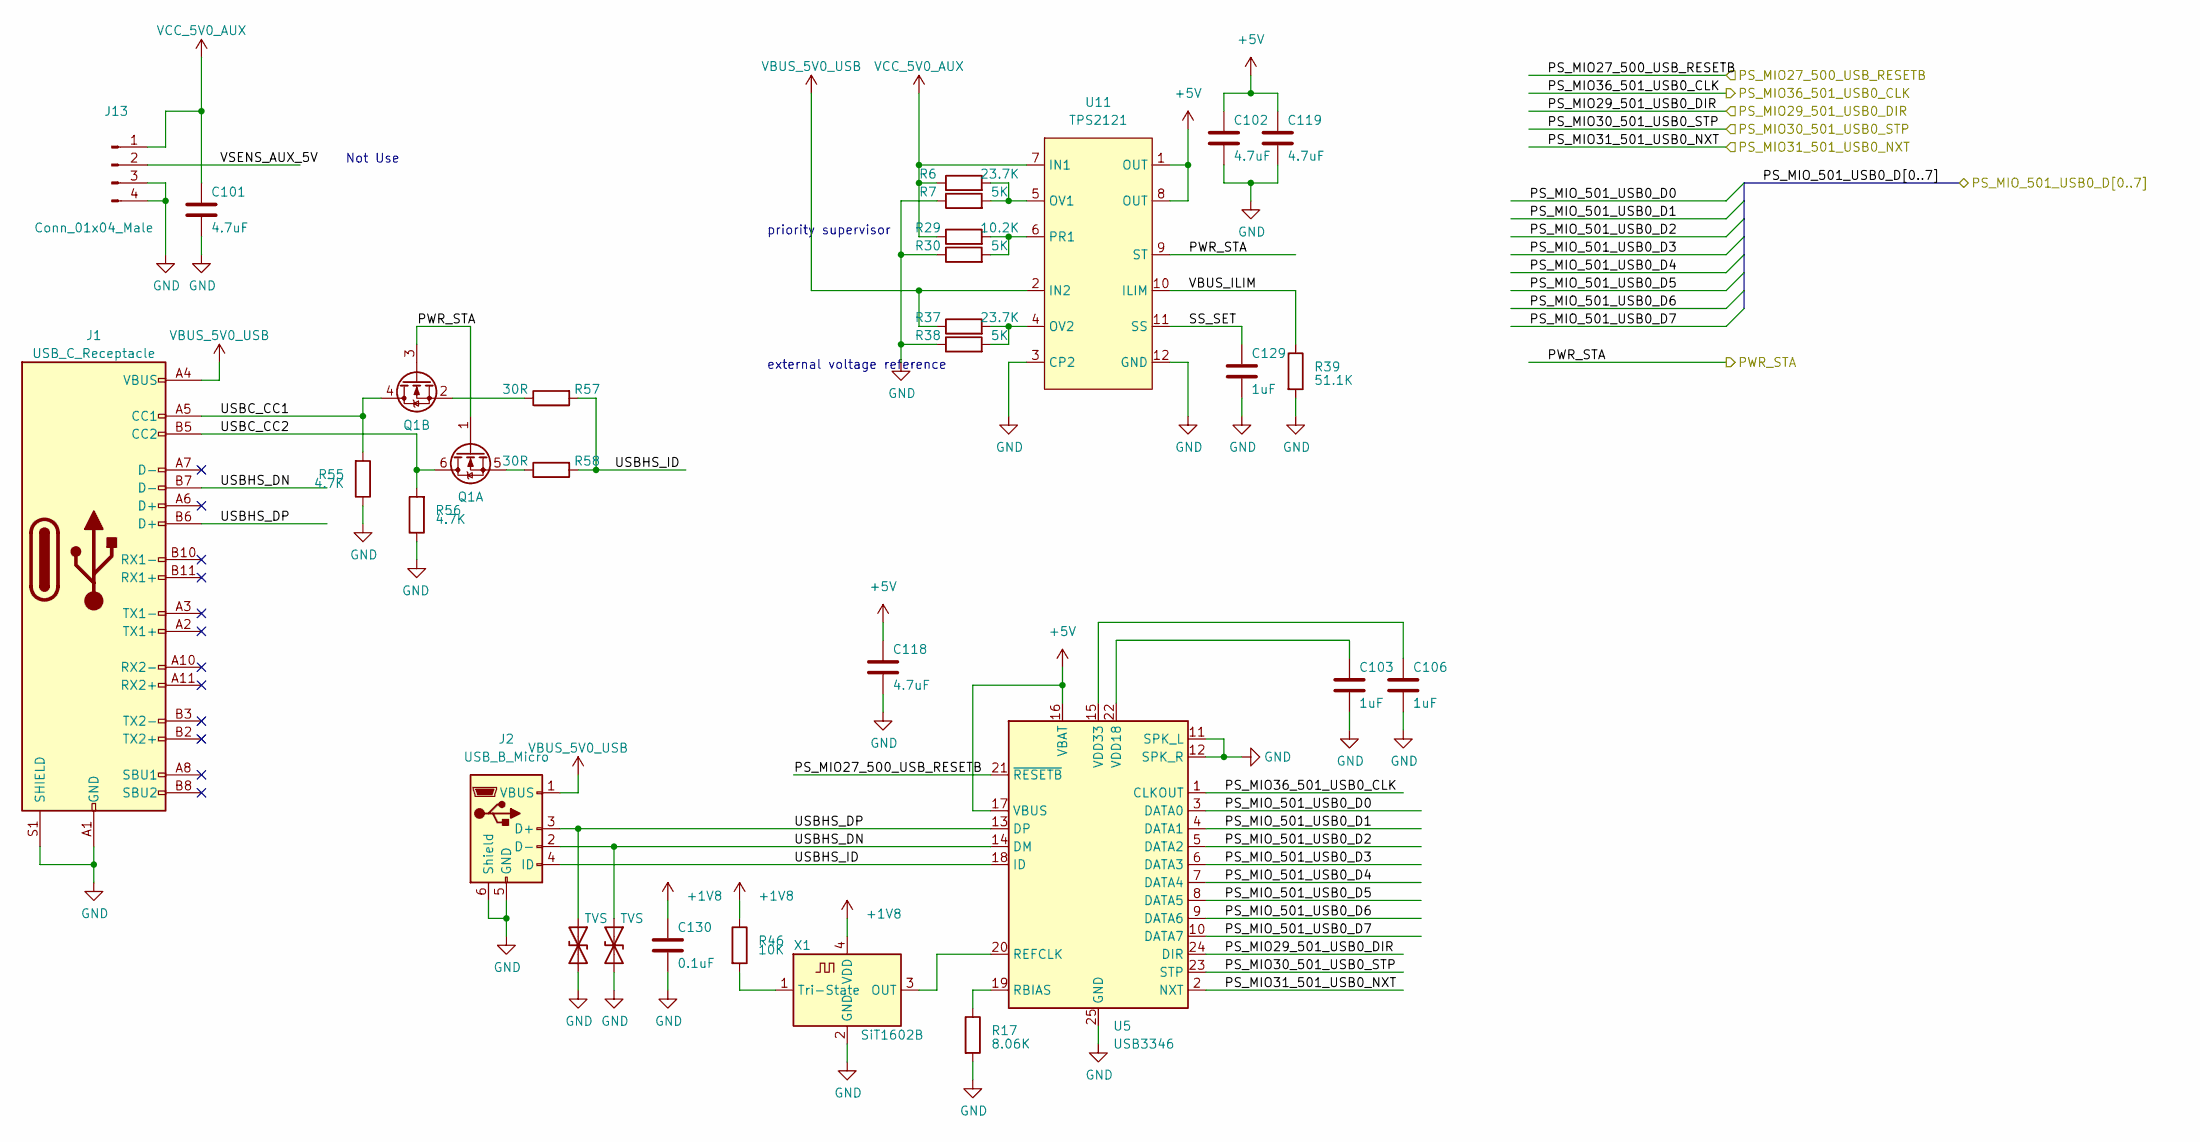
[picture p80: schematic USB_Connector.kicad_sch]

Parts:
C101, C102, C118, C119: 4.7uF; C_0402_1005Metric
C103, C106, C129: 1uF; C_0402_1005Metric
C130: 0.1uF; C_0201_0603Metric
D4, D5: TVS; R_0201_0603Metric
J1: USB_C_Receptacle; USB_C_Receptacle_Amphenol_12401548E4-2A_CircularHoles
J2: USB_B_Micro; USB_Micro-B_Amphenol_10104110_Horizontal
J13: Conn_01x04_Male; BM03B-ACHSS-GAN-TF
Q1: Q_Dual_NMOS_PMDXB600UNE; DFN-6-1EP_1.2x1.2mm_P0.4mm_EP0.3x0.94mm_PullBack
R6, R37: 23.7K; R_0201_0603Metric
R7, R30, R38: 5K; R_0201_0603Metric
R17: 8.06K; R_0201_0603Metric
R29: 10.2K; R_0201_0603Metric
R39: 51.1K; R_0201_0603Metric
R46: 10K; R_0201_0603Metric
R55, R56: 4.7K; R_0201_0603Metric
R57, R58: 30R; R_0201_0603Metric
U5: USB3346; QFN-24-1EP_4x4mm_P0.5mm_EP2.6x2.6mm
U11: TPS2121; VQFN-12_2p0_2p5_0p5
X1: SiT1602B; Oscillator_SMD_ECS_2520MV-xxx-xx-4Pin_2.5x2.0mm

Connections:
+1V8: C130.1, R46.1, X1.4 (VDD); also elsewhere on the board
+5V: C102.1, C118.1, C119.1, U5.16 (VBAT), U5.17 (VBUS), U11.1 (OUT), U11.8 (OUT); also elsewhere on the board
/USB Connector/PS_MIO27_500_USB_RESETB: U5.21 (~RESETB); also elsewhere on the board
/USB Connector/PS_MIO29_501_USB0_DIR: U5.24 (DIR); also elsewhere on the board
/USB Connector/PS_MIO30_501_USB0_STP: U5.23 (STP); also elsewhere on the board
/USB Connector/PS_MIO31_501_USB0_NXT: U5.2 (NXT); also elsewhere on the board
/USB Connector/PS_MIO36_501_USB0_CLK: U5.1 (CLKOUT); also elsewhere on the board
/USB Connector/PS_MIO_501_USB0_D0: U5.3 (DATA0); also elsewhere on the board
/USB Connector/PS_MIO_501_USB0_D1: U5.4 (DATA1); also elsewhere on the board
/USB Connector/PS_MIO_501_USB0_D2: U5.5 (DATA2); also elsewhere on the board
/USB Connector/PS_MIO_501_USB0_D3: U5.6 (DATA3); also elsewhere on the board
/USB Connector/PS_MIO_501_USB0_D4: U5.7 (DATA4); also elsewhere on the board
/USB Connector/PS_MIO_501_USB0_D5: U5.8 (DATA5); also elsewhere on the board
/USB Connector/PS_MIO_501_USB0_D6: U5.9 (DATA6); also elsewhere on the board
/USB Connector/PS_MIO_501_USB0_D7: U5.10 (DATA7); also elsewhere on the board
/USB Connector/PWR_STA: Q1.1 (G), Q1.3 (G), U11.9 (ST); also elsewhere on the board
/USB Connector/SS_SET: C129.1, U11.11 (SS)
/USB Connector/USBC_CC1: J1.A5 (CC1), Q1.4 (D), R55.2
/USB Connector/USBC_CC2: J1.B5 (CC2), Q1.6 (D), R56.2
/USB Connector/USBHS_DN: D5.1 (A1), J1.B7 (D-), J2.2 (D-), U5.14 (DM)
/USB Connector/USBHS_DP: D4.1 (A1), J1.B6 (D+), J2.3 (D+), U5.13 (DP)
/USB Connector/USBHS_ID: J2.4 (ID), R57.2, R58.2, U5.18 (ID)
/USB Connector/VBUS_ILIM: R39.1, U11.10 (ILIM)
/USB Connector/VSENS_AUX_5V: J13.2
GND: C101.2, C102.2, C103.2, C106.2, C118.2, C119.2, C129.2, C130.2, D4.2 (A2), D5.2 (A2), J1.A1 (GND), J1.A12 (GND), J1.B1 (GND), J1.B12 (GND), J1.S1 (SHIELD), J2.5 (GND), J2.6 (Shield), J13.3, J13.4, R7.1, R17.2, R30.1, R38.1, R39.2, R55.1, R56.1, U5.11 (SPK_L), U5.12 (SPK_R), U5.25 (GND), U11.3 (CP2), U11.12 (GND), X1.2 (GND); also elsewhere on the board
unnamed: Q1.5 (S), R58.1
unnamed: Q1.2 (S), R57.1
unnamed: R17.1, U5.19 (RBIAS)
unnamed: U5.20 (REFCLK), X1.3 (OUT)
unnamed: C103.1, U5.22 (VDD18)
unnamed: C106.1, U5.15 (VDD33)
unnamed: R6.2, R7.2, U11.5 (OV1)
unnamed: R37.2, R38.2, U11.4 (OV2)
unnamed: R29.2, R30.2, U11.6 (PR1)
unnamed: R46.2, X1.1 (Tri-State)
VBUS_5V0_USB: J1.A4 (VBUS), J1.A9 (VBUS), J1.B4 (VBUS), J1.B9 (VBUS), J2.1 (VBUS), R37.1, U11.2 (IN2)
VCC_5V0_AUX: C101.1, J13.1, R6.1, R29.1, U11.7 (IN1)

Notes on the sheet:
external voltage reference
Not Use
priority supervisor

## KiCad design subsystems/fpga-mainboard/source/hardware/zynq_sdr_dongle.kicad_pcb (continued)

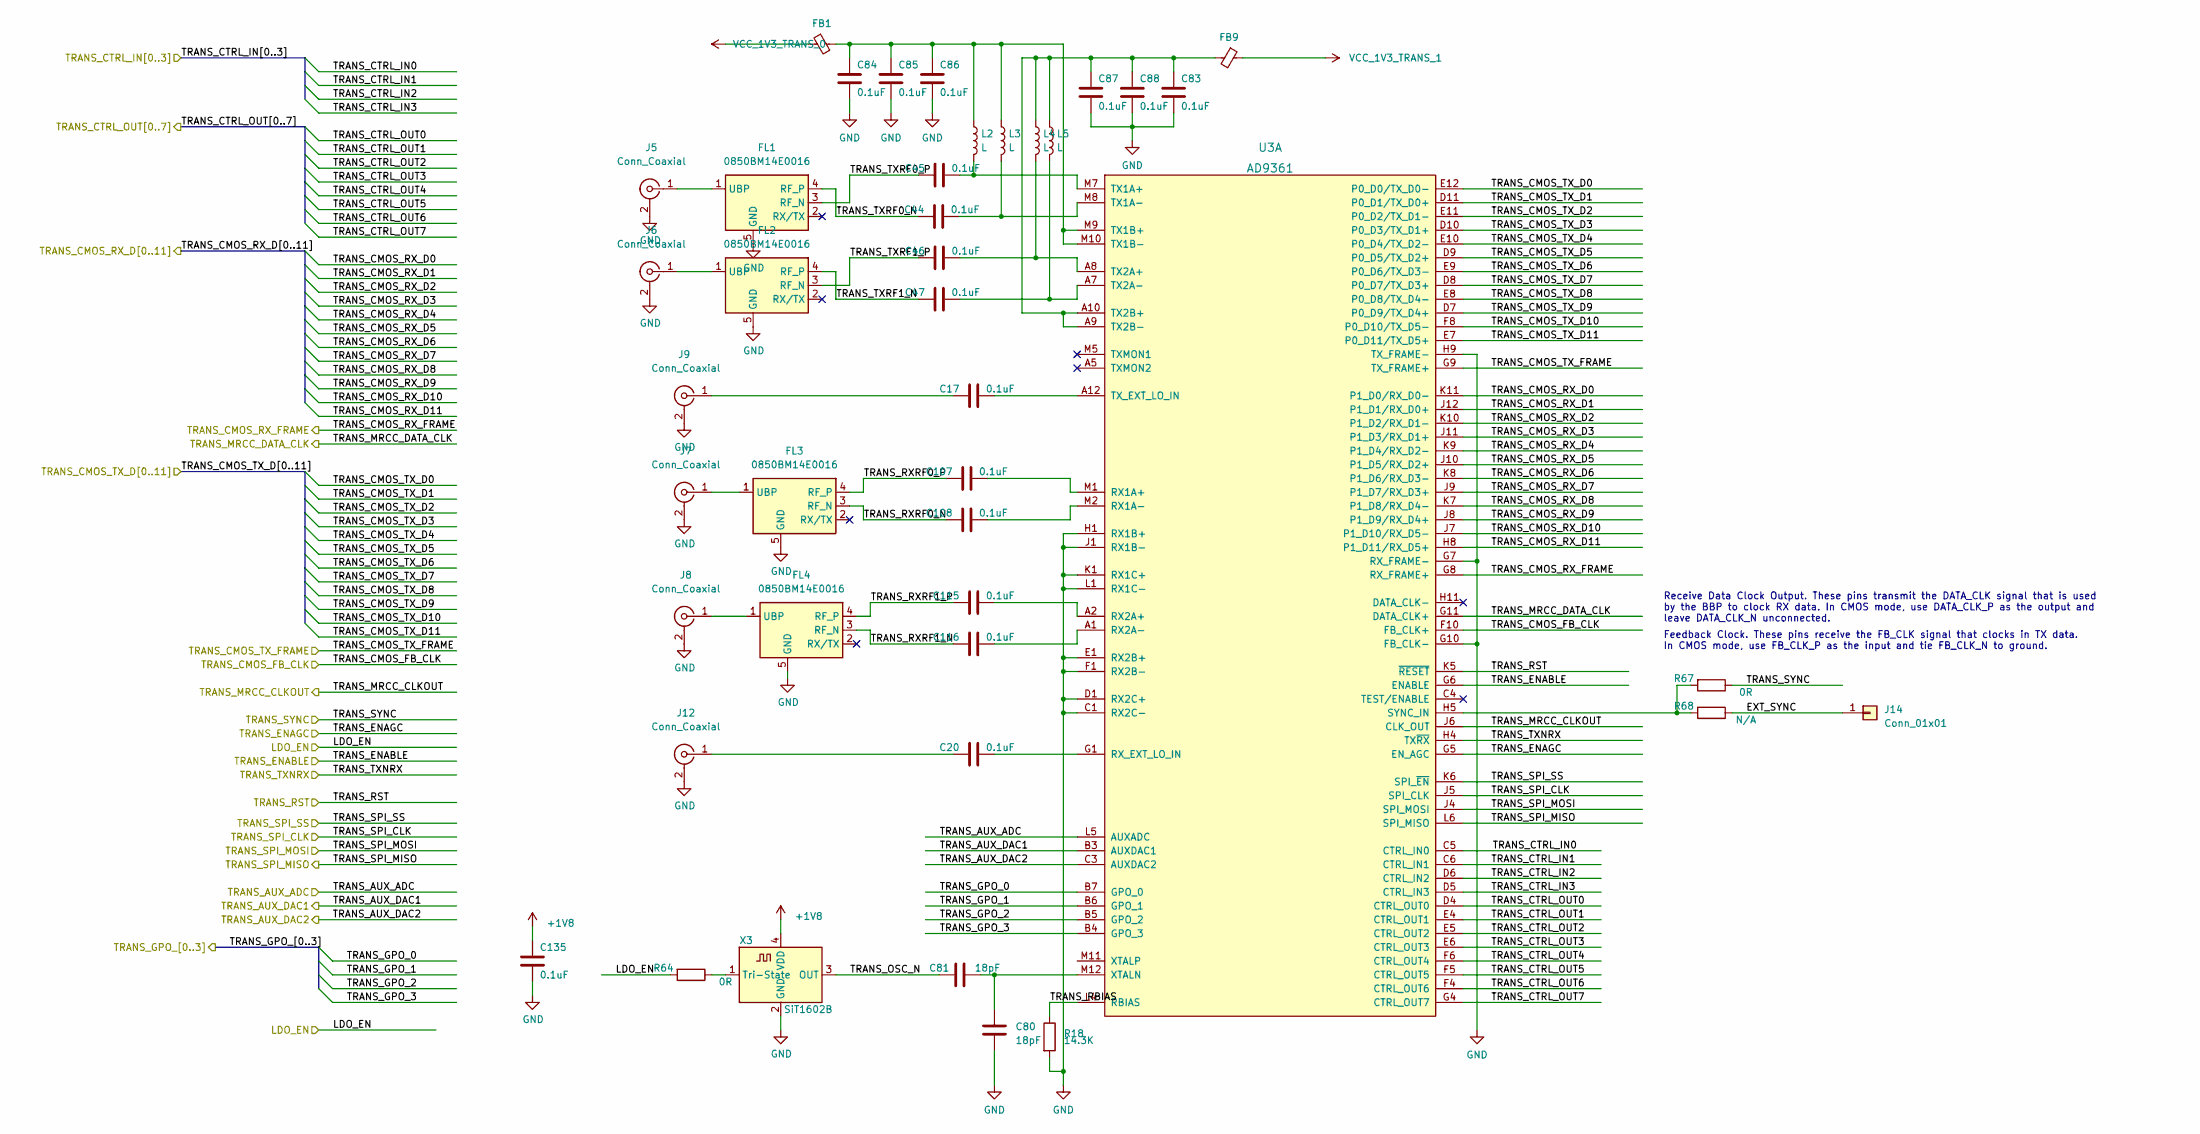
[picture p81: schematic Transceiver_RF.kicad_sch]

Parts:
C17, C20, C44, C45, C46, C47, C83, C84, C85, C86, C87, C88, C107, C108, C115, C116, C135: 0.1uF; C_0201_0603Metric
C80, C81: 18pF; C_0201_0603Metric
FB1, FB9: FerriteBead_Small; C_0402_1005Metric
FL1, FL2, FL3, FL4: 0850BM14E0016; Balun_Johanson_1.6x0.8mm
J5, J6, J7, J8, J9, J12: Conn_Coaxial; U.FL_Molex_MCRF_73412-0110_Vertical
J14: Conn_01x01; PinHeader_1x01_P2.54mm_Vertical
L2, L3, L4, L5: L; L_0402_1005Metric
R18: 14.3K; R_0201_0603Metric
R64, R67: 0R; R_0201_0603Metric
R68: N/A; R_0201_0603Metric
U3: AD9361; bga-100_10_10_1p32_0p8
X3: SiT1602B; Oscillator_SMD_ECS_2520MV-xxx-xx-4Pin_2.5x2.0mm

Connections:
+1V8: C135.1, X3.4 (VDD); also elsewhere on the board
/BTB Connector/TRANS_GPO_0: U3.B7 (GPO_0); also elsewhere on the board
/BTB Connector/TRANS_GPO_1: U3.B6 (GPO_1); also elsewhere on the board
/BTB Connector/TRANS_GPO_2: U3.B5 (GPO_2); also elsewhere on the board
/BTB Connector/TRANS_GPO_3: U3.B4 (GPO_3); also elsewhere on the board
/LDO_EN: R64.2; also elsewhere on the board
/TRANS_AUX_ADC: U3.L5 (AUXADC); also elsewhere on the board
/TRANS_AUX_DAC1: U3.B3 (AUXDAC1); also elsewhere on the board
/TRANS_AUX_DAC2: U3.C3 (AUXDAC2); also elsewhere on the board
/Transceiver RF/EXT_SYNC: J14.1, R68.1
/Transceiver RF/TRANS_CMOS_FB_CLK: U3.F10 (FB_CLK+); also elsewhere on the board
/Transceiver RF/TRANS_CMOS_RX_D0: U3.K11 (P1_D0/RX_D0-); also elsewhere on the board
/Transceiver RF/TRANS_CMOS_RX_D1: U3.J12 (P1_D1/RX_D0+); also elsewhere on the board
/Transceiver RF/TRANS_CMOS_RX_D2: U3.K10 (P1_D2/RX_D1-); also elsewhere on the board
/Transceiver RF/TRANS_CMOS_RX_D3: U3.J11 (P1_D3/RX_D1+); also elsewhere on the board
/Transceiver RF/TRANS_CMOS_RX_D4: U3.K9 (P1_D4/RX_D2-); also elsewhere on the board
/Transceiver RF/TRANS_CMOS_RX_D5: U3.J10 (P1_D5/RX_D2+); also elsewhere on the board
/Transceiver RF/TRANS_CMOS_RX_D6: U3.K8 (P1_D6/RX_D3-); also elsewhere on the board
/Transceiver RF/TRANS_CMOS_RX_D7: U3.J9 (P1_D7/RX_D3+); also elsewhere on the board
/Transceiver RF/TRANS_CMOS_RX_D8: U3.K7 (P1_D8/RX_D4-); also elsewhere on the board
/Transceiver RF/TRANS_CMOS_RX_D9: U3.J8 (P1_D9/RX_D4+); also elsewhere on the board
/Transceiver RF/TRANS_CMOS_RX_D10: U3.J7 (P1_D10/RX_D5-); also elsewhere on the board
/Transceiver RF/TRANS_CMOS_RX_D11: U3.H8 (P1_D11/RX_D5+); also elsewhere on the board
/Transceiver RF/TRANS_CMOS_RX_FRAME: U3.G8 (RX_FRAME+); also elsewhere on the board
/Transceiver RF/TRANS_CMOS_TX_D0: U3.E12 (P0_D0/TX_D0-); also elsewhere on the board
/Transceiver RF/TRANS_CMOS_TX_D1: U3.D11 (P0_D1/TX_D0+); also elsewhere on the board
/Transceiver RF/TRANS_CMOS_TX_D2: U3.E11 (P0_D2/TX_D1-); also elsewhere on the board
/Transceiver RF/TRANS_CMOS_TX_D3: U3.D10 (P0_D3/TX_D1+); also elsewhere on the board
/Transceiver RF/TRANS_CMOS_TX_D4: U3.E10 (P0_D4/TX_D2-); also elsewhere on the board
/Transceiver RF/TRANS_CMOS_TX_D5: U3.D9 (P0_D5/TX_D2+); also elsewhere on the board
/Transceiver RF/TRANS_CMOS_TX_D6: U3.E9 (P0_D6/TX_D3-); also elsewhere on the board
/Transceiver RF/TRANS_CMOS_TX_D7: U3.D8 (P0_D7/TX_D3+); also elsewhere on the board
/Transceiver RF/TRANS_CMOS_TX_D8: U3.E8 (P0_D8/TX_D4-); also elsewhere on the board
/Transceiver RF/TRANS_CMOS_TX_D9: U3.D7 (P0_D9/TX_D4+); also elsewhere on the board
/Transceiver RF/TRANS_CMOS_TX_D10: U3.F8 (P0_D10/TX_D5-); also elsewhere on the board
/Transceiver RF/TRANS_CMOS_TX_D11: U3.E7 (P0_D11/TX_D5+); also elsewhere on the board
/Transceiver RF/TRANS_CMOS_TX_FRAME: U3.G9 (TX_FRAME+); also elsewhere on the board
/Transceiver RF/TRANS_CTRL_IN0: U3.C5 (CTRL_IN0); also elsewhere on the board
/Transceiver RF/TRANS_CTRL_IN1: U3.C6 (CTRL_IN1); also elsewhere on the board
/Transceiver RF/TRANS_CTRL_IN2: U3.D6 (CTRL_IN2); also elsewhere on the board
/Transceiver RF/TRANS_CTRL_IN3: U3.D5 (CTRL_IN3); also elsewhere on the board
/Transceiver RF/TRANS_CTRL_OUT0: U3.D4 (CTRL_OUT0); also elsewhere on the board
/Transceiver RF/TRANS_CTRL_OUT1: U3.E4 (CTRL_OUT1); also elsewhere on the board
/Transceiver RF/TRANS_CTRL_OUT2: U3.E5 (CTRL_OUT2); also elsewhere on the board
/Transceiver RF/TRANS_CTRL_OUT3: U3.E6 (CTRL_OUT3); also elsewhere on the board
/Transceiver RF/TRANS_CTRL_OUT4: U3.F6 (CTRL_OUT4); also elsewhere on the board
/Transceiver RF/TRANS_CTRL_OUT5: U3.F5 (CTRL_OUT5); also elsewhere on the board
/Transceiver RF/TRANS_CTRL_OUT6: U3.F4 (CTRL_OUT6); also elsewhere on the board
/Transceiver RF/TRANS_CTRL_OUT7: U3.G4 (CTRL_OUT7); also elsewhere on the board
/Transceiver RF/TRANS_ENABLE: U3.G6 (ENABLE); also elsewhere on the board
/Transceiver RF/TRANS_ENAGC: U3.G5 (EN_AGC); also elsewhere on the board
/Transceiver RF/TRANS_MRCC_CLKOUT: U3.J6 (CLK_OUT); also elsewhere on the board
/Transceiver RF/TRANS_MRCC_DATA_CLK: U3.G11 (DATA_CLK+); also elsewhere on the board
/Transceiver RF/TRANS_OSC_N: C81.1, X3.3 (OUT)
/Transceiver RF/TRANS_RBIAS: R18.1, U3.L4 (RBIAS)
/Transceiver RF/TRANS_RST: U3.K5 (~RESET); also elsewhere on the board
/Transceiver RF/TRANS_RXRF0_N: C108.1, FL3.3 (RF_N)
/Transceiver RF/TRANS_RXRF0_P: C107.1, FL3.4 (RF_P)
/Transceiver RF/TRANS_RXRF1_N: C116.1, FL4.3 (RF_N)
/Transceiver RF/TRANS_RXRF1_P: C115.1, FL4.4 (RF_P)
/Transceiver RF/TRANS_SPI_CLK: U3.J5 (SPI_CLK); also elsewhere on the board
/Transceiver RF/TRANS_SPI_MISO: U3.L6 (SPI_MISO); also elsewhere on the board
/Transceiver RF/TRANS_SPI_MOSI: U3.J4 (SPI_MOSI); also elsewhere on the board
/Transceiver RF/TRANS_SPI_SS: U3.K6 (SPI_~EN); also elsewhere on the board
/Transceiver RF/TRANS_SYNC: R67.1; also elsewhere on the board
/Transceiver RF/TRANS_TXNRX: U3.H4 (TX~RX); also elsewhere on the board
/Transceiver RF/TRANS_TXRF0_N: C44.1, FL1.4 (RF_P)
/Transceiver RF/TRANS_TXRF0_P: C45.1, FL1.3 (RF_N)
/Transceiver RF/TRANS_TXRF1_N: C47.1, FL2.4 (RF_P)
/Transceiver RF/TRANS_TXRF1_P: C46.1, FL2.3 (RF_N)
GND: C80.1, C83.1, C84.1, C85.1, C86.1, C87.1, C88.1, C135.2, FL1.5 (GND), FL1.6 (GND), FL2.5 (GND), FL2.6 (GND), FL3.5 (GND), FL3.6 (GND), FL4.5 (GND), FL4.6 (GND), J5.2 (Ext), J6.2 (Ext), J7.2 (Ext), J8.2 (Ext), J9.2 (Ext), J12.2 (Ext), R18.2, U3.C1 (RX2C-), U3.D1 (RX2C+), U3.E1 (RX2B+), U3.F1 (RX2B-), U3.G7 (RX_FRAME-), U3.G10 (FB_CLK-), U3.H1 (RX1B+), U3.H9 (TX_FRAME-), U3.J1 (RX1B-), U3.K1 (RX1C+), U3.L1 (RX1C-), X3.2 (GND); also elsewhere on the board
unnamed: FL1.1 (UBP), J5.1 (In)
unnamed: FL2.1 (UBP), J6.1 (In)
unnamed: FL3.1 (UBP), J7.1 (In)
unnamed: FL4.1 (UBP), J8.1 (In)
unnamed: C17.1, J9.1 (In)
unnamed: C20.1, J12.1 (In)
unnamed: C107.2, U3.M1 (RX1A+)
unnamed: C108.2, U3.M2 (RX1A-)
unnamed: C115.2, U3.A2 (RX2A+)
unnamed: C116.2, U3.A1 (RX2A-)
unnamed: C20.2, U3.G1 (RX_EXT_LO_IN)
unnamed: R67.2, R68.2, U3.H5 (SYNC_IN)
unnamed: C45.2, L2.2, U3.M7 (TX1A+)
unnamed: C44.2, L3.2, U3.M8 (TX1A-)
unnamed: C84.2, C85.2, C86.2, FB1.2, L2.1, L3.1, U3.M9 (TX1B+), U3.M10 (TX1B-)
unnamed: C46.2, L4.2, U3.A8 (TX2A+)
unnamed: C47.2, L5.2, U3.A7 (TX2A-)
unnamed: C83.2, C87.2, C88.2, FB9.2, L4.1, L5.1, U3.A9 (TX2B-), U3.A10 (TX2B+)
unnamed: C17.2, U3.A12 (TX_EXT_LO_IN)
unnamed: C80.2, C81.2, U3.M12 (XTALN)
unnamed: R64.1, X3.1 (Tri-State)
VCC_1V3_TRANS_0: FB1.1; also elsewhere on the board
VCC_1V3_TRANS_1: FB9.1; also elsewhere on the board

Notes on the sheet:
Feedback Clock. These pins receive the FB_CLK signal that clocks in TX data. In CMOS mode, use FB_CLK_P as the input and tie FB_CLK_N to ground.
Receive Data Clock Output. These pins transmit the DATA_CLK signal that is used by the BBP to clock RX data. In CMOS mode, use DATA_CLK_P as the output and leave DATA_CLK_N unconnected.

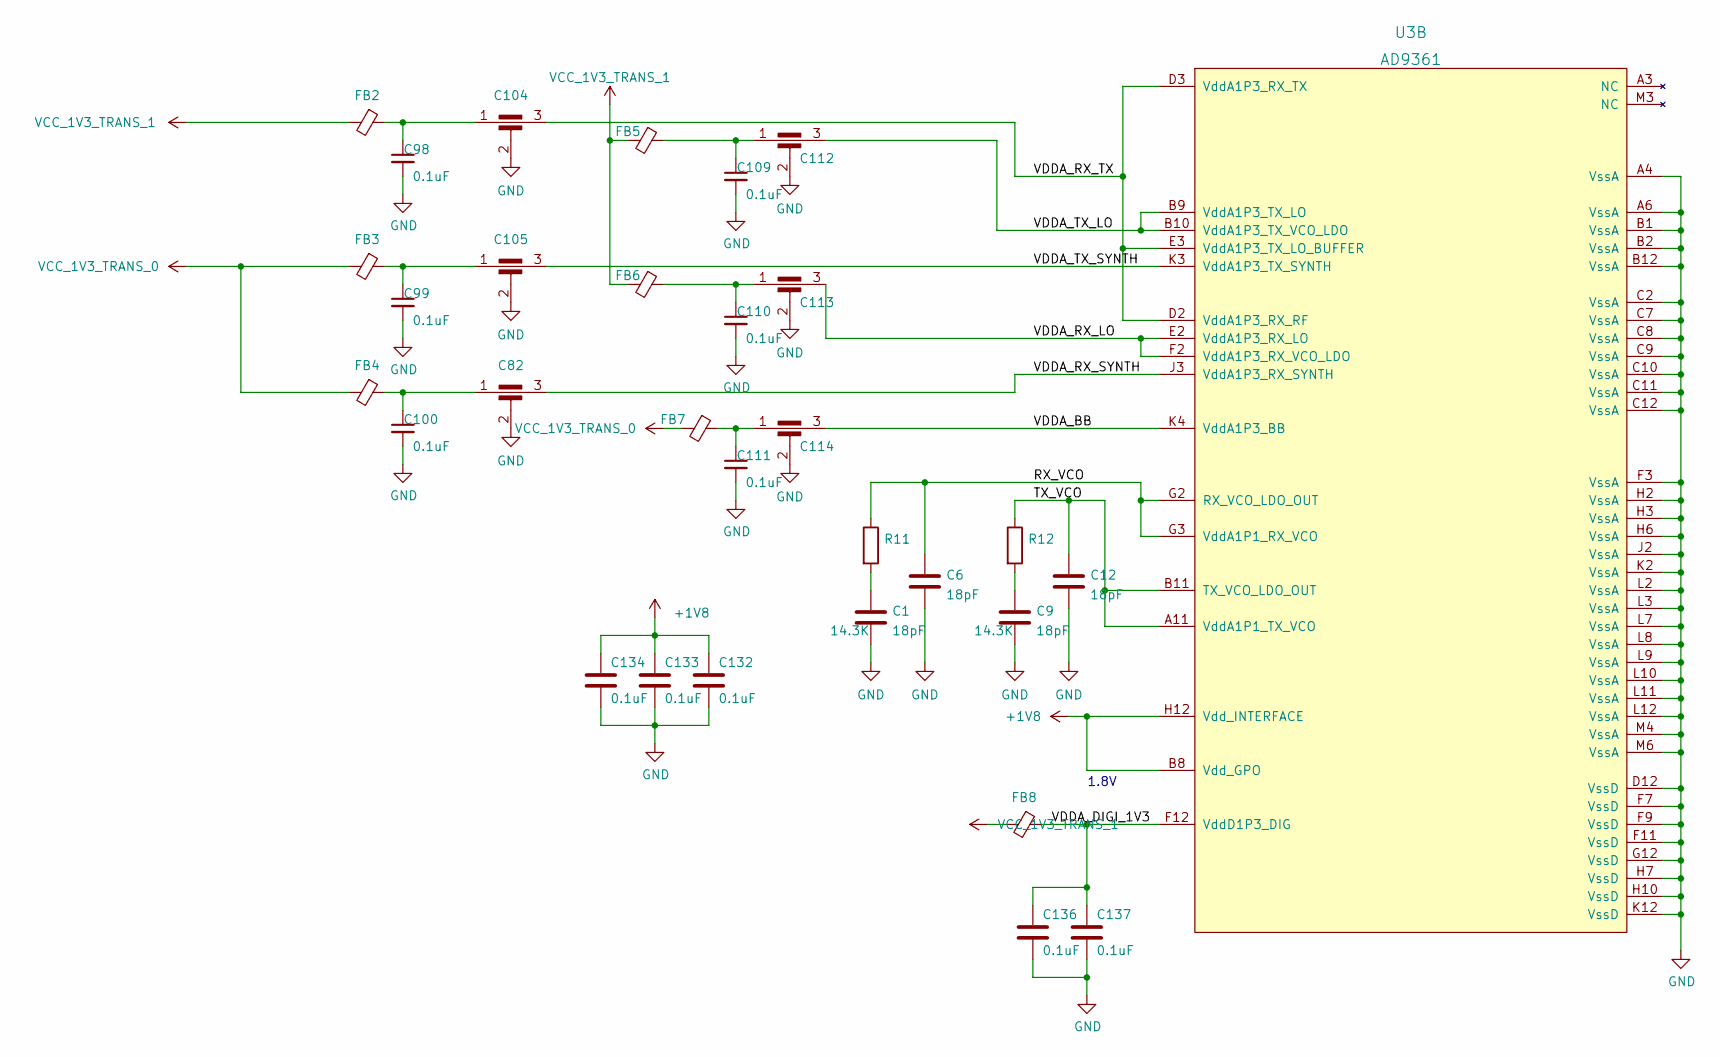
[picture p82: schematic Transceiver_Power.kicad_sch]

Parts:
C1, C6, C9, C12: 18pF; C_0201_0603Metric
C82, C104, C105, C112, C113, C114: NFM15PC146R0G3D; C_0402_1005Metric
C98, C99, C100, C109, C110, C111, C132, C133, C134, C136, C137: 0.1uF; C_0201_0603Metric
FB2, FB3, FB4, FB5, FB6, FB7, FB8: FerriteBead_Small; C_0201_0603Metric
R11, R12: 14.3K; R_0201_0603Metric
U3: AD9361; bga-100_10_10_1p32_0p8

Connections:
+1V8: C132.1, C133.1, C134.1, U3.B8 (Vdd_GPO), U3.H12 (Vdd_INTERFACE); also elsewhere on the board
/Transceiver Powr/RX_VCO: C6.1, R11.1, U3.G2 (RX_VCO_LDO_OUT), U3.G3 (VddA1P1_RX_VCO)
/Transceiver Powr/TX_VCO: C12.1, R12.1, U3.A11 (VddA1P1_TX_VCO), U3.B11 (TX_VCO_LDO_OUT)
/Transceiver Powr/VDDA_BB: C114.3, U3.K4 (VddA1P3_BB)
/Transceiver Powr/VDDA_DIGI_1V3: C136.1, C137.1, FB8.1, U3.F12 (VddD1P3_DIG)
/Transceiver Powr/VDDA_RX_LO: C113.3, U3.E2 (VddA1P3_RX_LO), U3.F2 (VddA1P3_RX_VCO_LDO)
/Transceiver Powr/VDDA_RX_SYNTH: C82.3, U3.J3 (VddA1P3_RX_SYNTH)
/Transceiver Powr/VDDA_RX_TX: C104.3, U3.D2 (VddA1P3_RX_RF), U3.D3 (VddA1P3_RX_TX), U3.E3 (VddA1P3_TX_LO_BUFFER)
/Transceiver Powr/VDDA_TX_LO: C112.3, U3.B9 (VddA1P3_TX_LO), U3.B10 (VddA1P3_TX_VCO_LDO)
/Transceiver Powr/VDDA_TX_SYNTH: C105.3, U3.K3 (VddA1P3_TX_SYNTH)
GND: C1.2, C6.2, C9.2, C12.2, C82.2, C98.2, C99.2, C100.2, C104.2, C105.2, C109.2, C110.2, C111.2, C112.2, C113.2, C114.2, C132.2, C133.2, C134.2, C136.2, C137.2, U3.A4 (VssA), U3.A6 (VssA), U3.B1 (VssA), U3.B2 (VssA), U3.B12 (VssA), U3.C2 (VssA), U3.C7 (VssA), U3.C8 (VssA), U3.C9 (VssA), U3.C10 (VssA), U3.C11 (VssA), U3.C12 (VssA), U3.D12 (VssD), U3.F3 (VssA), U3.F7 (VssD), U3.F9 (VssD), U3.F11 (VssD), U3.G12 (VssD), U3.H2 (VssA), U3.H3 (VssA), U3.H6 (VssA), U3.H7 (VssD), U3.H10 (VssD), U3.J2 (VssA), U3.K2 (VssA), U3.K12 (VssD), U3.L2 (VssA), U3.L3 (VssA), U3.L7 (VssA), U3.L8 (VssA), U3.L9 (VssA), U3.L10 (VssA), U3.L11 (VssA), U3.L12 (VssA), U3.M4 (VssA), U3.M6 (VssA); also elsewhere on the board
unnamed: C1.1, R11.2
unnamed: C9.1, R12.2
unnamed: C82.1, C100.1, FB4.1
unnamed: C98.1, C104.1, FB2.1
unnamed: C99.1, C105.1, FB3.1
unnamed: C109.1, C112.1, FB5.1
unnamed: C110.1, C113.1, FB6.1
unnamed: C111.1, C114.1, FB7.1
VCC_1V3_TRANS_0: FB3.2, FB4.2, FB7.2; also elsewhere on the board
VCC_1V3_TRANS_1: FB2.2, FB5.2, FB6.2, FB8.2; also elsewhere on the board

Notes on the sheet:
1.8V

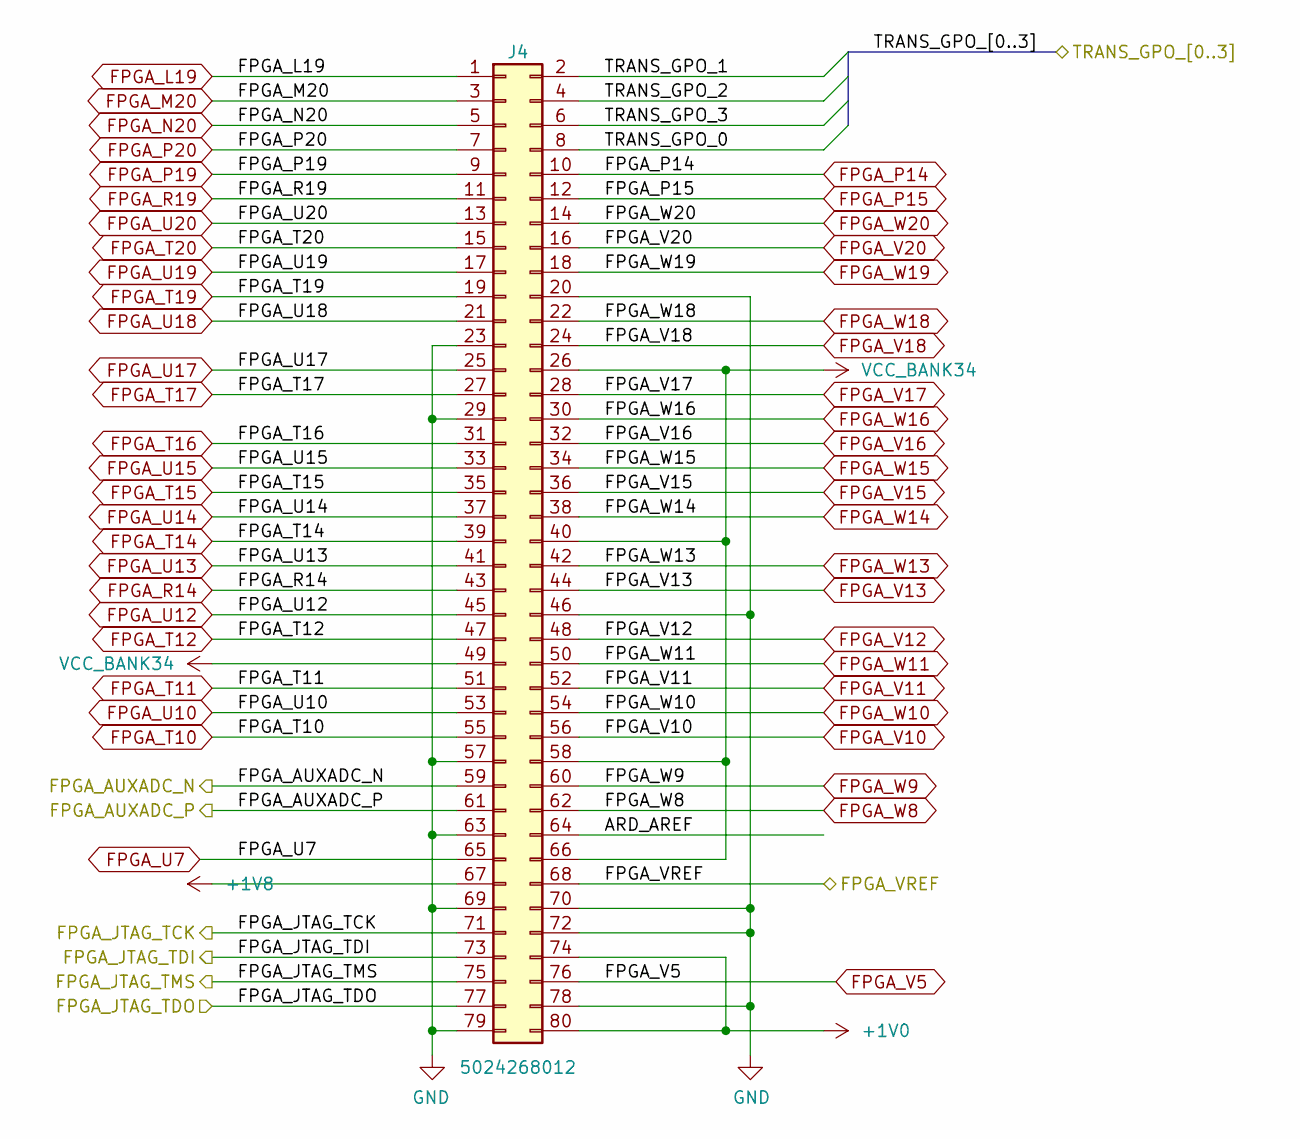
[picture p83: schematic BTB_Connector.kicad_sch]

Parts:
J4: 5024268012; Molex_SlimStack_502430-8010_2x40_P0.40mm_Vertical

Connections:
+1V0: J4.74, J4.80; also elsewhere on the board
+1V8: J4.67; also elsewhere on the board
/BTB Connector/ARD_AREF: J4.64
/BTB Connector/FPGA_AUXADC_N: J4.59; also elsewhere on the board
/BTB Connector/FPGA_AUXADC_P: J4.61; also elsewhere on the board
/BTB Connector/FPGA_JTAG_TCK: J4.71; also elsewhere on the board
/BTB Connector/FPGA_JTAG_TDI: J4.73; also elsewhere on the board
/BTB Connector/FPGA_JTAG_TDO: J4.77; also elsewhere on the board
/BTB Connector/FPGA_JTAG_TMS: J4.75; also elsewhere on the board
/BTB Connector/TRANS_GPO_0: J4.8; also elsewhere on the board
/BTB Connector/TRANS_GPO_1: J4.2; also elsewhere on the board
/BTB Connector/TRANS_GPO_2: J4.4; also elsewhere on the board
/BTB Connector/TRANS_GPO_3: J4.6; also elsewhere on the board
/FPGA_VREF: J4.68; also elsewhere on the board
FPGA_L19: J4.1; also elsewhere on the board
FPGA_M20: J4.3; also elsewhere on the board
FPGA_N20: J4.5; also elsewhere on the board
FPGA_P14: J4.10; also elsewhere on the board
FPGA_P15: J4.12; also elsewhere on the board
FPGA_P19: J4.9; also elsewhere on the board
FPGA_P20: J4.7; also elsewhere on the board
FPGA_R14: J4.43; also elsewhere on the board
FPGA_R19: J4.11; also elsewhere on the board
FPGA_T10: J4.55; also elsewhere on the board
FPGA_T11: J4.51; also elsewhere on the board
FPGA_T12: J4.47; also elsewhere on the board
FPGA_T14: J4.39; also elsewhere on the board
FPGA_T15: J4.35; also elsewhere on the board
FPGA_T16: J4.31; also elsewhere on the board
FPGA_T17: J4.27; also elsewhere on the board
FPGA_T19: J4.19; also elsewhere on the board
FPGA_T20: J4.15; also elsewhere on the board
FPGA_U7: J4.65; also elsewhere on the board
FPGA_U10: J4.53; also elsewhere on the board
FPGA_U12: J4.45; also elsewhere on the board
FPGA_U13: J4.41; also elsewhere on the board
FPGA_U14: J4.37; also elsewhere on the board
FPGA_U15: J4.33; also elsewhere on the board
FPGA_U17: J4.25; also elsewhere on the board
FPGA_U18: J4.21; also elsewhere on the board
FPGA_U19: J4.17; also elsewhere on the board
FPGA_U20: J4.13; also elsewhere on the board
FPGA_V5: J4.76; also elsewhere on the board
FPGA_V10: J4.56; also elsewhere on the board
FPGA_V11: J4.52; also elsewhere on the board
FPGA_V12: J4.48; also elsewhere on the board
FPGA_V13: J4.44; also elsewhere on the board
FPGA_V15: J4.36; also elsewhere on the board
FPGA_V16: J4.32; also elsewhere on the board
FPGA_V17: J4.28; also elsewhere on the board
FPGA_V18: J4.24; also elsewhere on the board
FPGA_V20: J4.16; also elsewhere on the board
FPGA_W8: J4.62; also elsewhere on the board
FPGA_W9: J4.60; also elsewhere on the board
FPGA_W10: J4.54; also elsewhere on the board
FPGA_W11: J4.50; also elsewhere on the board
FPGA_W13: J4.42; also elsewhere on the board
FPGA_W14: J4.38; also elsewhere on the board
FPGA_W15: J4.34; also elsewhere on the board
FPGA_W16: J4.30; also elsewhere on the board
FPGA_W18: J4.22; also elsewhere on the board
FPGA_W19: J4.18; also elsewhere on the board
FPGA_W20: J4.14; also elsewhere on the board
GND: J4.20, J4.23, J4.29, J4.46, J4.57, J4.63, J4.69, J4.70, J4.72, J4.78, J4.79; also elsewhere on the board
VCC_BANK34: J4.26, J4.40, J4.49, J4.58, J4.66; also elsewhere on the board

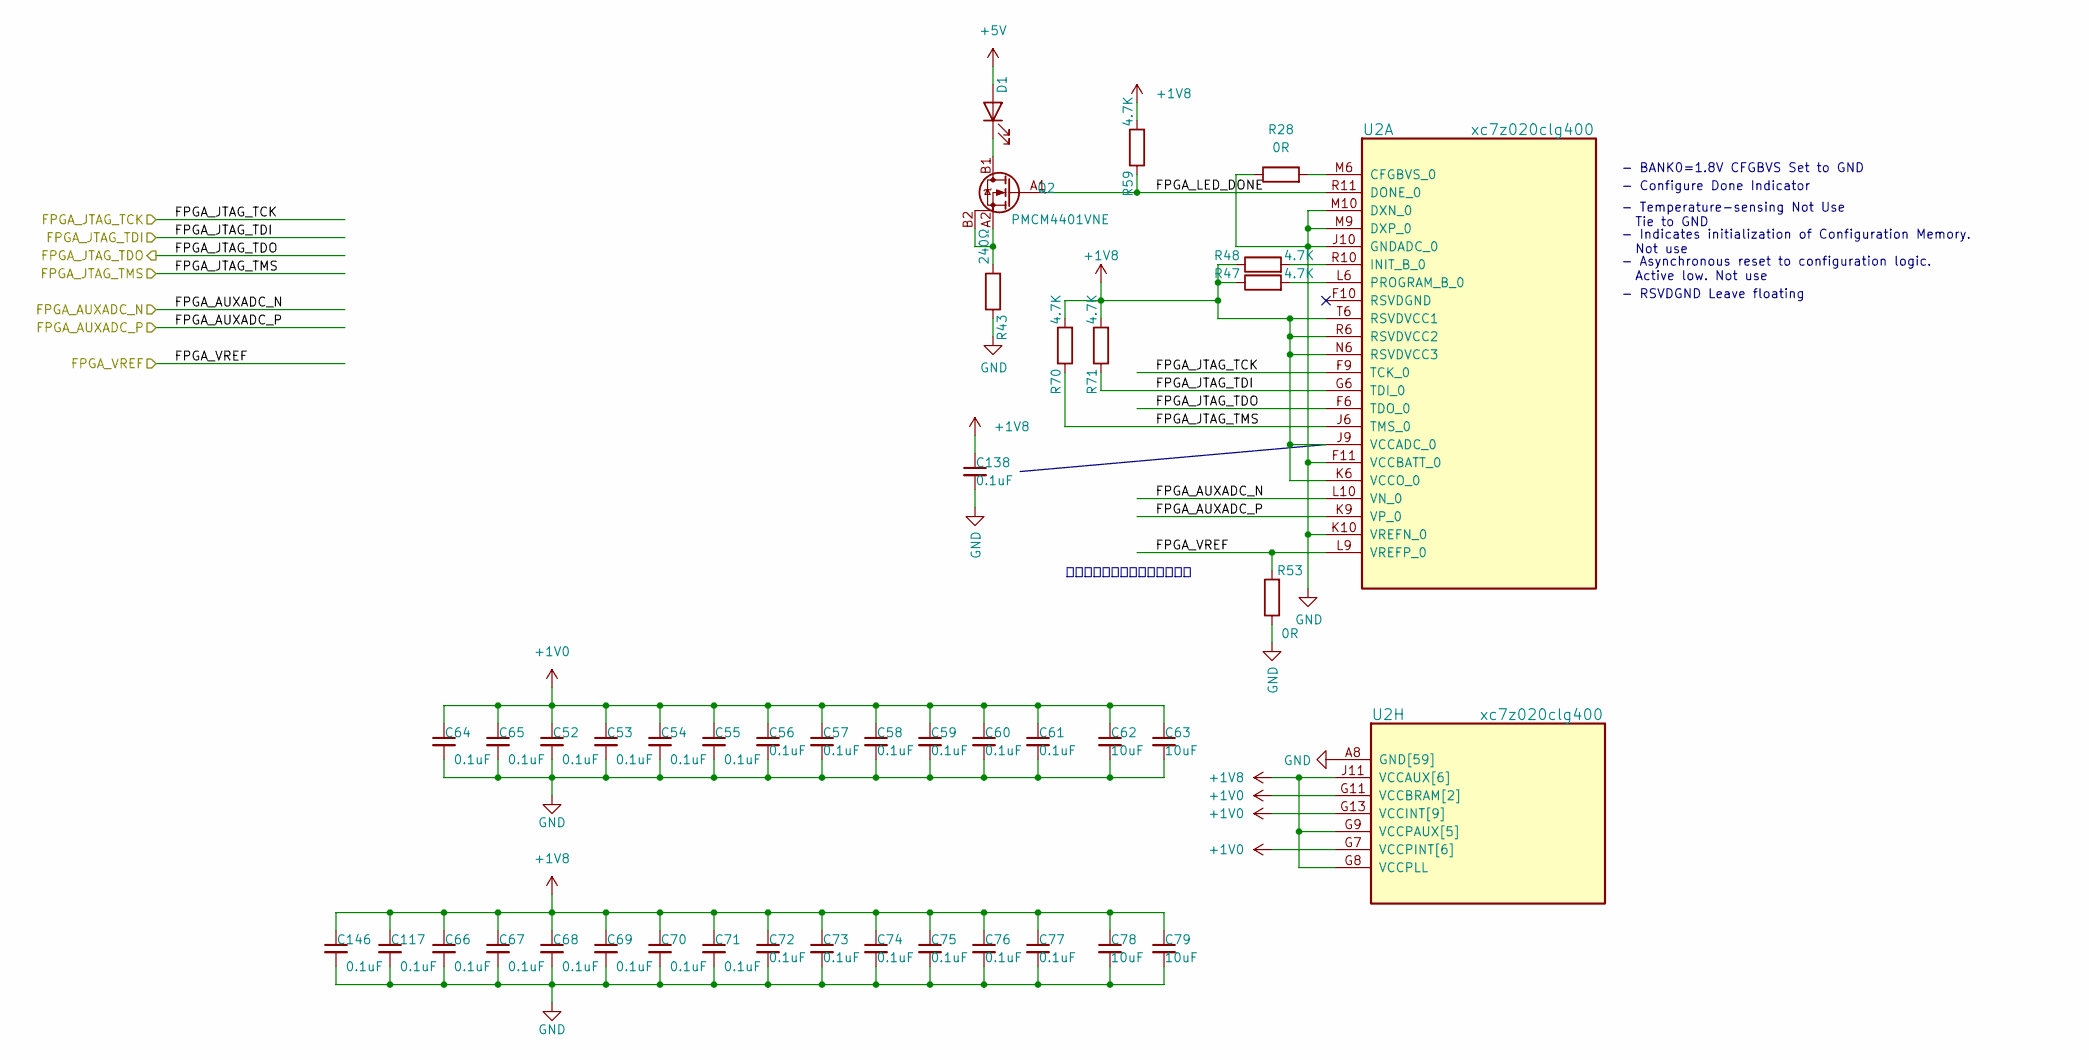
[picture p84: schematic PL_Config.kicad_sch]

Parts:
C52, C53, C54, C55, C56, C57, C58, C59, C60, C61, C64, C65, C66, C67, C68, C69, C70, C71, C72, C73, C74, C75, C76, C77, C117, C138, C146: 0.1uF; C_0201_0603Metric
C62, C63, C78, C79: 10uF; C_0402_1005Metric
D1: LED; LED_0201_0603Metric
Q2: PMCM4401VNE; WLCSP-4-X1-WLB0909-4_0.89x0.89mm_P0.5mm
R28, R53: 0R; R_0201_0603Metric
R43: 240Ω; R_0201_0603Metric
R47, R48, R59, R70, R71: 4.7K; R_0201_0603Metric
U2: xc7z020clg400; Xilinx_CLG400_020_Delay

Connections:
+1V0: C52.1, C53.1, C54.1, C55.1, C56.1, C57.1, C58.1, C59.1, C60.1, C61.1, C62.1, C63.1, C64.1, C65.1, U2.G7 (VCCPINT[6]), U2.G11 (VCCBRAM[2]), U2.G13 (VCCINT[9]), U2.H10 (VCCBRAM[2]), U2.H12 (VCCINT[9]), U2.J7 (VCCPINT[6]), U2.J13 (VCCINT[9]), U2.K12 (VCCINT[9]), U2.L7 (VCCPINT[6]), U2.L13 (VCCINT[9]), U2.M12 (VCCINT[9]), U2.N7 (VCCPINT[6]), U2.N13 (VCCINT[9]), U2.P8 (VCCPINT[6]), U2.P12 (VCCINT[9]), U2.R7 (VCCPINT[6]), U2.R13 (VCCINT[9]); also elsewhere on the board
+1V8: C66.1, C67.1, C68.1, C69.1, C70.1, C71.1, C72.1, C73.1, C74.1, C75.1, C76.1, C77.1, C78.1, C79.1, C117.1, C138.1, C146.1, R47.1, R48.1, R59.2, R70.2, R71.2, U2.F8 (VCCPAUX[5]), U2.G8 (VCCPLL), U2.G9 (VCCPAUX[5]), U2.H8 (VCCPAUX[5]), U2.J9 (VCCADC_0), U2.J11 (VCCAUX[6]), U2.K6 (VCCO_0), U2.K8 (VCCPAUX[5]), U2.L11 (VCCAUX[6]), U2.M8 (VCCPAUX[5]), U2.N6 (RSVDVCC3), U2.N9 (VCCAUX[6]), U2.N11 (VCCAUX[6]), U2.P10 (VCCAUX[6]), U2.R6 (RSVDVCC2), U2.R9 (VCCAUX[6]), U2.T6 (RSVDVCC1); also elsewhere on the board
+5V: D1.2 (A); also elsewhere on the board
/BTB Connector/FPGA_AUXADC_N: U2.L10 (VN_0); also elsewhere on the board
/BTB Connector/FPGA_AUXADC_P: U2.K9 (VP_0); also elsewhere on the board
/BTB Connector/FPGA_JTAG_TCK: U2.F9 (TCK_0); also elsewhere on the board
/BTB Connector/FPGA_JTAG_TDI: R71.1, U2.G6 (TDI_0); also elsewhere on the board
/BTB Connector/FPGA_JTAG_TDO: U2.F6 (TDO_0); also elsewhere on the board
/BTB Connector/FPGA_JTAG_TMS: R70.1, U2.J6 (TMS_0); also elsewhere on the board
/FPGA_VREF: R53.2, U2.L9 (VREFP_0); also elsewhere on the board
/ZYNQ PL Part/PL Config/FPGA_LED_DONE: Q2.A1 (G), R59.1, U2.R11 (DONE_0)
GND: C52.2, C53.2, C54.2, C55.2, C56.2, C57.2, C58.2, C59.2, C60.2, C61.2, C62.2, C63.2, C64.2, C65.2, C66.2, C67.2, C68.2, C69.2, C70.2, C71.2, C72.2, C73.2, C74.2, C75.2, C76.2, C77.2, C78.2, C79.2, C117.2, C138.2, C146.2, R28.1, R43.1, R53.1, U2.A8 (GND[59]), U2.A18 (GND[59]), U2.B1 (GND[59]), U2.B11 (GND[59]), U2.C4 (GND[59]), U2.C9 (GND[59]), U2.C14 (GND[59]), U2.D17 (GND[59]), U2.E10 (GND[59]), U2.E20 (GND[59]), U2.F3 (GND[59]), U2.F7 (GND[59]), U2.F11 (VCCBATT_0), U2.G10 (GND[59]), U2.G12 (GND[59]), U2.G16 (GND[59]), U2.H7 (GND[59]), U2.H9 (GND[59]), U2.H11 (GND[59]), U2.H13 (GND[59]), U2.H19 (GND[59]), U2.J2 (GND[59]), U2.J8 (GND[59]), U2.J10 (GNDADC_0), U2.J12 (GND[59]), U2.K5 (GND[59]), U2.K7 (GND[59]), U2.K10 (VREFN_0), U2.K11 (GND[59]), U2.K13 (GND[59]), U2.K15 (GND[59]), U2.L8 (GND[59]), U2.L12 (GND[59]), U2.L18 (GND[59]), U2.M1 (GND[59]), U2.M7 (GND[59]), U2.M9 (DXP_0), U2.M10 (DXN_0), U2.M11 (GND[59]), U2.M13 (GND[59]), U2.N4 (GND[59]), U2.N8 (GND[59]), U2.N10 (GND[59]), U2.N12 (GND[59]), U2.N14 (GND[59]), U2.P7 (GND[59]), U2.P9 (GND[59]), U2.P11 (GND[59]), U2.P13 (GND[59]), U2.P17 (GND[59]), U2.R8 (GND[59]), U2.R12 (GND[59]), U2.R20 (GND[59]), U2.T3 (GND[59]), U2.T7 (GND[59]), U2.T13 (GND[59]), U2.U6 (GND[59]), U2.U16 (GND[59]), U2.V9 (GND[59]), U2.V19 (GND[59]), U2.W2 (GND[59]), U2.W12 (GND[59]), U2.Y5 (GND[59]), U2.Y15 (GND[59]); also elsewhere on the board
unnamed: D1.1 (K), Q2.B1 (D)
unnamed: Q2.A2 (S), Q2.B2 (D), R43.2
unnamed: R28.2, U2.M6 (CFGBVS_0)
unnamed: R48.2, U2.R10 (INIT_B_0)
unnamed: R47.2, U2.L6 (PROGRAM_B_0)

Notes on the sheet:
- RSVDGND Leave floating
- Configure Done Indicator
不用外部参考的时候怎么处理？
- Temperature-sensing Not Use Tie to GND
- Indicates initialization of Configuration Memory. Not use
- Asynchronous reset to configuration logic. Active low. Not use
- BANK0=1.8V CFGBVS Set to GND

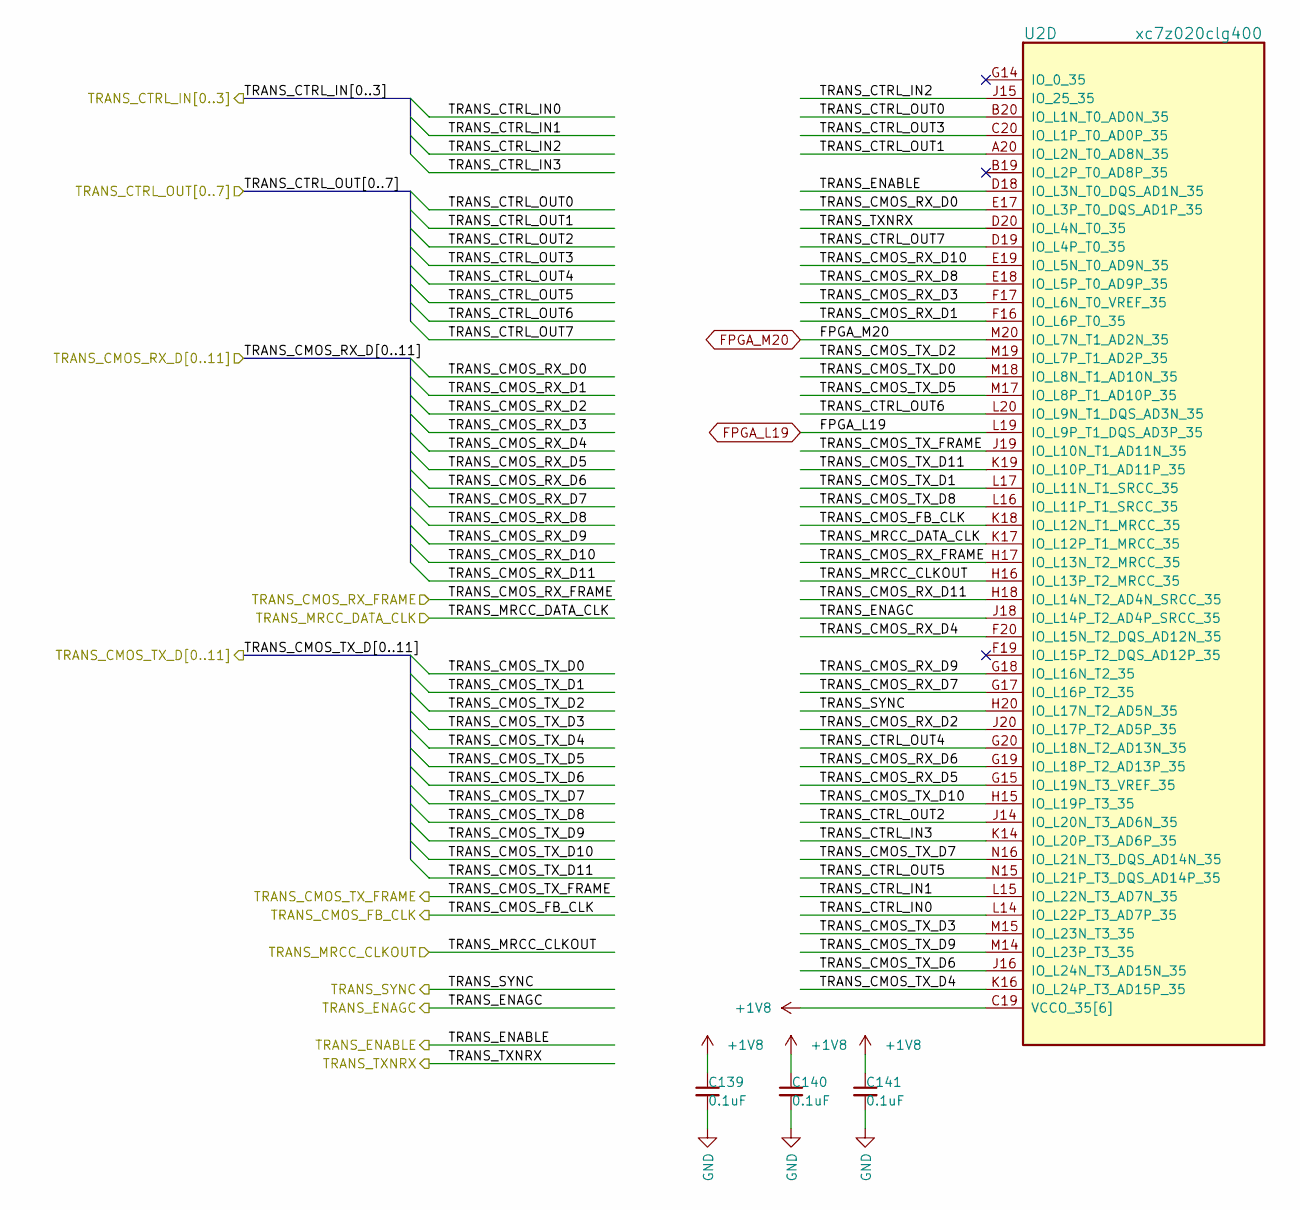
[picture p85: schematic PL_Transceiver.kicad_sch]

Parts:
C139, C140, C141: 0.1uF; C_0201_0603Metric
U2: xc7z020clg400; Xilinx_CLG400_020_Delay

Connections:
+1V8: C139.1, C140.1, C141.1, U2.C19 (VCCO_35[6]), U2.F18 (VCCO_35[6]), U2.H14 (VCCO_35[6]), U2.J17 (VCCO_35[6]), U2.K20 (VCCO_35[6]), U2.M16 (VCCO_35[6]); also elsewhere on the board
/Transceiver RF/TRANS_CMOS_FB_CLK: U2.K18 (IO_L12N_T1_MRCC_35); also elsewhere on the board
/Transceiver RF/TRANS_CMOS_RX_D0: U2.E17 (IO_L3P_T0_DQS_AD1P_35); also elsewhere on the board
/Transceiver RF/TRANS_CMOS_RX_D1: U2.F16 (IO_L6P_T0_35); also elsewhere on the board
/Transceiver RF/TRANS_CMOS_RX_D2: U2.J20 (IO_L17P_T2_AD5P_35); also elsewhere on the board
/Transceiver RF/TRANS_CMOS_RX_D3: U2.F17 (IO_L6N_T0_VREF_35); also elsewhere on the board
/Transceiver RF/TRANS_CMOS_RX_D4: U2.F20 (IO_L15N_T2_DQS_AD12N_35); also elsewhere on the board
/Transceiver RF/TRANS_CMOS_RX_D5: U2.G15 (IO_L19N_T3_VREF_35); also elsewhere on the board
/Transceiver RF/TRANS_CMOS_RX_D6: U2.G19 (IO_L18P_T2_AD13P_35); also elsewhere on the board
/Transceiver RF/TRANS_CMOS_RX_D7: U2.G17 (IO_L16P_T2_35); also elsewhere on the board
/Transceiver RF/TRANS_CMOS_RX_D8: U2.E18 (IO_L5P_T0_AD9P_35); also elsewhere on the board
/Transceiver RF/TRANS_CMOS_RX_D9: U2.G18 (IO_L16N_T2_35); also elsewhere on the board
/Transceiver RF/TRANS_CMOS_RX_D10: U2.E19 (IO_L5N_T0_AD9N_35); also elsewhere on the board
/Transceiver RF/TRANS_CMOS_RX_D11: U2.H18 (IO_L14N_T2_AD4N_SRCC_35); also elsewhere on the board
/Transceiver RF/TRANS_CMOS_RX_FRAME: U2.H17 (IO_L13N_T2_MRCC_35); also elsewhere on the board
/Transceiver RF/TRANS_CMOS_TX_D0: U2.M18 (IO_L8N_T1_AD10N_35); also elsewhere on the board
/Transceiver RF/TRANS_CMOS_TX_D1: U2.L17 (IO_L11N_T1_SRCC_35); also elsewhere on the board
/Transceiver RF/TRANS_CMOS_TX_D2: U2.M19 (IO_L7P_T1_AD2P_35); also elsewhere on the board
/Transceiver RF/TRANS_CMOS_TX_D3: U2.M15 (IO_L23N_T3_35); also elsewhere on the board
/Transceiver RF/TRANS_CMOS_TX_D4: U2.K16 (IO_L24P_T3_AD15P_35); also elsewhere on the board
/Transceiver RF/TRANS_CMOS_TX_D5: U2.M17 (IO_L8P_T1_AD10P_35); also elsewhere on the board
/Transceiver RF/TRANS_CMOS_TX_D6: U2.J16 (IO_L24N_T3_AD15N_35); also elsewhere on the board
/Transceiver RF/TRANS_CMOS_TX_D7: U2.N16 (IO_L21N_T3_DQS_AD14N_35); also elsewhere on the board
/Transceiver RF/TRANS_CMOS_TX_D8: U2.L16 (IO_L11P_T1_SRCC_35); also elsewhere on the board
/Transceiver RF/TRANS_CMOS_TX_D9: U2.M14 (IO_L23P_T3_35); also elsewhere on the board
/Transceiver RF/TRANS_CMOS_TX_D10: U2.H15 (IO_L19P_T3_35); also elsewhere on the board
/Transceiver RF/TRANS_CMOS_TX_D11: U2.K19 (IO_L10P_T1_AD11P_35); also elsewhere on the board
/Transceiver RF/TRANS_CMOS_TX_FRAME: U2.J19 (IO_L10N_T1_AD11N_35); also elsewhere on the board
/Transceiver RF/TRANS_CTRL_IN0: U2.L14 (IO_L22P_T3_AD7P_35); also elsewhere on the board
/Transceiver RF/TRANS_CTRL_IN1: U2.L15 (IO_L22N_T3_AD7N_35); also elsewhere on the board
/Transceiver RF/TRANS_CTRL_IN2: U2.J15 (IO_25_35); also elsewhere on the board
/Transceiver RF/TRANS_CTRL_IN3: U2.K14 (IO_L20P_T3_AD6P_35); also elsewhere on the board
/Transceiver RF/TRANS_CTRL_OUT0: U2.B20 (IO_L1N_T0_AD0N_35); also elsewhere on the board
/Transceiver RF/TRANS_CTRL_OUT1: U2.A20 (IO_L2N_T0_AD8N_35); also elsewhere on the board
/Transceiver RF/TRANS_CTRL_OUT2: U2.J14 (IO_L20N_T3_AD6N_35); also elsewhere on the board
/Transceiver RF/TRANS_CTRL_OUT3: U2.C20 (IO_L1P_T0_AD0P_35); also elsewhere on the board
/Transceiver RF/TRANS_CTRL_OUT4: U2.G20 (IO_L18N_T2_AD13N_35); also elsewhere on the board
/Transceiver RF/TRANS_CTRL_OUT5: U2.N15 (IO_L21P_T3_DQS_AD14P_35); also elsewhere on the board
/Transceiver RF/TRANS_CTRL_OUT6: U2.L20 (IO_L9N_T1_DQS_AD3N_35); also elsewhere on the board
/Transceiver RF/TRANS_CTRL_OUT7: U2.D19 (IO_L4P_T0_35); also elsewhere on the board
/Transceiver RF/TRANS_ENABLE: U2.D18 (IO_L3N_T0_DQS_AD1N_35); also elsewhere on the board
/Transceiver RF/TRANS_ENAGC: U2.J18 (IO_L14P_T2_AD4P_SRCC_35); also elsewhere on the board
/Transceiver RF/TRANS_MRCC_CLKOUT: U2.H16 (IO_L13P_T2_MRCC_35); also elsewhere on the board
/Transceiver RF/TRANS_MRCC_DATA_CLK: U2.K17 (IO_L12P_T1_MRCC_35); also elsewhere on the board
/Transceiver RF/TRANS_SYNC: U2.H20 (IO_L17N_T2_AD5N_35); also elsewhere on the board
/Transceiver RF/TRANS_TXNRX: U2.D20 (IO_L4N_T0_35); also elsewhere on the board
FPGA_L19: U2.L19 (IO_L9P_T1_DQS_AD3P_35); also elsewhere on the board
FPGA_M20: U2.M20 (IO_L7N_T1_AD2N_35); also elsewhere on the board
GND: C139.2, C140.2, C141.2; also elsewhere on the board

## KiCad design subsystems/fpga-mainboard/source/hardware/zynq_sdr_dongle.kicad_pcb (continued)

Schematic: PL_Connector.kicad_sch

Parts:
R40: 1K; R_0201_0603Metric
U2: xc7z020clg400; Xilinx_CLG400_020_Delay

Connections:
/ARD_ANALOG0: U2.Y7 (IO_L13P_T2_MRCC_13); also elsewhere on the board
/ARD_ANALOG1: U2.Y6 (IO_L13N_T2_MRCC_13); also elsewhere on the board
/ARD_ANALOG2: U2.W6 (IO_L22N_T3_13); also elsewhere on the board
/ARD_ANALOG3: U2.Y9 (IO_L14P_T2_SRCC_13); also elsewhere on the board
/ARD_ANALOG4: U2.Y11 (IO_L18N_T2_13); also elsewhere on the board
/ARD_ANALOG5: U2.Y12 (IO_L20P_T3_13); also elsewhere on the board
/ARD_PWM2: U2.Y19 (IO_L17N_T2_34); also elsewhere on the board
/ARD_PWM3: U2.Y18 (IO_L17P_T2_34); also elsewhere on the board
/ARD_PWM4: U2.Y17 (IO_L7N_T1_34); also elsewhere on the board
/ARD_PWM5: U2.Y16 (IO_L7P_T1_34); also elsewhere on the board
/ARD_PWM6: U2.Y14 (IO_L8N_T1_34); also elsewhere on the board
/ARD_PWM7: U2.Y13 (IO_L20N_T3_13); also elsewhere on the board
/ZYNQ PL Part/FPGA_SRCCN_Y8: U2.Y8 (IO_L14N_T2_SRCC_13); also elsewhere on the board
FPGA_N20: U2.N20 (IO_L14P_T2_SRCC_34); also elsewhere on the board
FPGA_P14: U2.P14 (IO_L6P_T0_34); also elsewhere on the board
FPGA_P15: U2.P15 (IO_L24P_T3_34); also elsewhere on the board
FPGA_P19: U2.P19 (IO_L13N_T2_MRCC_34); also elsewhere on the board
FPGA_P20: U2.P20 (IO_L14N_T2_SRCC_34); also elsewhere on the board
FPGA_R14: U2.R14 (IO_L6N_T0_VREF_34); also elsewhere on the board
FPGA_R19: U2.R19 (IO_0_34); also elsewhere on the board
FPGA_T10: U2.T10 (IO_L1N_T0_34); also elsewhere on the board
FPGA_T11: U2.T11 (IO_L1P_T0_34); also elsewhere on the board
FPGA_T12: U2.T12 (IO_L2P_T0_34); also elsewhere on the board
FPGA_T14: U2.T14 (IO_L5P_T0_34); also elsewhere on the board
FPGA_T15: U2.T15 (IO_L5N_T0_34); also elsewhere on the board
FPGA_T16: U2.T16 (IO_L9P_T1_DQS_34); also elsewhere on the board
FPGA_T17: U2.T17 (IO_L20P_T3_34); also elsewhere on the board
FPGA_T19: U2.T19 (IO_25_34); also elsewhere on the board
FPGA_T20: U2.T20 (IO_L15P_T2_DQS_34); also elsewhere on the board
FPGA_U7: U2.U7 (IO_L11P_T1_SRCC_13); also elsewhere on the board
FPGA_U10: U2.U10 (IO_L12N_T1_MRCC_13); also elsewhere on the board
FPGA_U12: U2.U12 (IO_L2N_T0_34); also elsewhere on the board
FPGA_U13: R40.2, U2.U13 (IO_L3P_T0_DQS_PUDC_B_34); also elsewhere on the board
FPGA_U14: U2.U14 (IO_L11P_T1_SRCC_34); also elsewhere on the board
FPGA_U15: U2.U15 (IO_L11N_T1_SRCC_34); also elsewhere on the board
FPGA_U17: U2.U17 (IO_L9N_T1_DQS_34); also elsewhere on the board
FPGA_U18: U2.U18 (IO_L12P_T1_MRCC_34); also elsewhere on the board
FPGA_U19: U2.U19 (IO_L12N_T1_MRCC_34); also elsewhere on the board
FPGA_U20: U2.U20 (IO_L15N_T2_DQS_34); also elsewhere on the board
FPGA_V5: U2.V5 (IO_L6N_T0_VREF_13); also elsewhere on the board
FPGA_V10: U2.V10 (IO_L21N_T3_DQS_13); also elsewhere on the board
FPGA_V11: U2.V11 (IO_L21P_T3_DQS_13); also elsewhere on the board
FPGA_V12: U2.V12 (IO_L4P_T0_34); also elsewhere on the board
FPGA_V13: U2.V13 (IO_L3N_T0_DQS_34); also elsewhere on the board
FPGA_V15: U2.V15 (IO_L10P_T1_34); also elsewhere on the board
FPGA_V16: U2.V16 (IO_L18P_T2_34); also elsewhere on the board
FPGA_V17: U2.V17 (IO_L21P_T3_DQS_34); also elsewhere on the board
FPGA_V18: U2.V18 (IO_L21N_T3_DQS_34); also elsewhere on the board
FPGA_V20: U2.V20 (IO_L16P_T2_34); also elsewhere on the board
FPGA_W8: U2.W8 (IO_L15N_T2_DQS_13); also elsewhere on the board
FPGA_W9: U2.W9 (IO_L16N_T2_13); also elsewhere on the board
FPGA_W10: U2.W10 (IO_L16P_T2_13); also elsewhere on the board
FPGA_W11: U2.W11 (IO_L18P_T2_13); also elsewhere on the board
FPGA_W13: U2.W13 (IO_L4N_T0_34); also elsewhere on the board
FPGA_W14: U2.W14 (IO_L8P_T1_34); also elsewhere on the board
FPGA_W15: U2.W15 (IO_L10N_T1_34); also elsewhere on the board
FPGA_W16: U2.W16 (IO_L18N_T2_34); also elsewhere on the board
FPGA_W18: U2.W18 (IO_L22P_T3_34); also elsewhere on the board
FPGA_W19: U2.W19 (IO_L22N_T3_34); also elsewhere on the board
FPGA_W20: U2.W20 (IO_L16N_T2_34); also elsewhere on the board
GND: R40.1; also elsewhere on the board
VCC_BANK34: U2.N19 (VCCO_34[6]), U2.R15 (VCCO_34[6]), U2.T8 (VCCO_13[4]), U2.T18 (VCCO_34[6]), U2.U11 (VCCO_13[4]), U2.V14 (VCCO_34[6]), U2.W7 (VCCO_13[4]), U2.W17 (VCCO_34[6]), U2.Y10 (VCCO_13[4]), U2.Y20 (VCCO_34[6]); also elsewhere on the board

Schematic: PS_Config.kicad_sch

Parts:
C38, C131, C142, C143, C144, C145, C147, C148: 0.1uF; C_0201_0603Metric
J3: Micro_SD_Card; microSD_HC_Molex_104031-0811
R22, R49, R50, R52, R62, R65, R66, R69: 10K; R_0201_0603Metric
R51: N/A; R_0201_0603Metric
SW2: SW_DIP_x01; EVQ9P701P
U2: xc7z020clg400; Xilinx_CLG400_020_Delay
U13: TXS0206A; WLCSP-20_1.609x1.994mm_Layout4x5_P0.4mm
X2: SiT1602B; Oscillator_SMD_ECS_2520MV-xxx-xx-4Pin_2.5x2.0mm

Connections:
+1V8: C131.1, C142.1, C143.1, C144.1, C145.1, C148.1, R22.1, R49.1, R50.2, R62.1, R65.1, R66.1, R69.1, U2.A6 (PS_MIO5_500), U2.A13 (VCCO_MIO1_501[4]), U2.B6 (VCCO_MIO0_500[2]), U2.B16 (VCCO_MIO1_501[4]), U2.D5 (PS_MIO8_500), U2.D7 (VCCO_MIO0_500[2]), U2.D8 (PS_MIO7_500), U2.D12 (VCCO_MIO1_501[4]), U2.E15 (VCCO_MIO1_501[4]), U13.A2 (VCCA), X2.4 (VDD); also elsewhere on the board
+3V3: C147.1, J3.4 (VDD), U13.B3 (VCCB); also elsewhere on the board
/LDO_EN: U2.B13 (PS_MIO50_501); also elsewhere on the board
/PS-SRST#: R62.2, U2.B10 (PS_SRST_B_501); also elsewhere on the board
/PS_MIO10_SCL: R66.2, U2.E9 (PS_MIO10_500); also elsewhere on the board
/PS_MIO11_SDA: R65.2, U2.C6 (PS_MIO11_500); also elsewhere on the board
/PS_MIO16_SPI_CLK: U2.A19 (PS_MIO16_501); also elsewhere on the board
/PS_MIO17_SPI_MISO: U2.E14 (PS_MIO17_501); also elsewhere on the board
/PS_MIO18_SPI_SS: U2.B18 (PS_MIO18_501); also elsewhere on the board
/PS_MIO19_SPI_MOSI: U2.D10 (PS_MIO19_501); also elsewhere on the board
/PS_MIO20_SPI_SS1: U2.A17 (PS_MIO20_501); also elsewhere on the board
/PS_MIO21_SPI_SS2: U2.F14 (PS_MIO21_501); also elsewhere on the board
/Power Manage/DCDC_PG_1V35: C38.1, R22.2, SW2.2, U2.C7 (PS_POR_B_500); also elsewhere on the board
/Transceiver RF/TRANS_RST: U2.B14 (PS_MIO47_501); also elsewhere on the board
/Transceiver RF/TRANS_SPI_CLK: U2.A16 (PS_MIO24_501); also elsewhere on the board
/Transceiver RF/TRANS_SPI_MISO: U2.D11 (PS_MIO23_501); also elsewhere on the board
/Transceiver RF/TRANS_SPI_MOSI: U2.B17 (PS_MIO22_501); also elsewhere on the board
/Transceiver RF/TRANS_SPI_SS: U2.F15 (PS_MIO25_501); also elsewhere on the board
/UART_RX: U2.E8 (PS_MIO13_500); also elsewhere on the board
/UART_TX: U2.D9 (PS_MIO12_500); also elsewhere on the board
/USB Connector/PS_MIO27_500_USB_RESETB: U2.D13 (PS_MIO27_501); also elsewhere on the board
/USB Connector/PS_MIO29_501_USB0_DIR: U2.C13 (PS_MIO29_501); also elsewhere on the board
/USB Connector/PS_MIO30_501_USB0_STP: U2.C15 (PS_MIO30_501); also elsewhere on the board
/USB Connector/PS_MIO31_501_USB0_NXT: U2.E16 (PS_MIO31_501); also elsewhere on the board
/USB Connector/PS_MIO36_501_USB0_CLK: U2.A11 (PS_MIO36_501); also elsewhere on the board
/USB Connector/PS_MIO_501_USB0_D0: U2.A14 (PS_MIO32_501); also elsewhere on the board
/USB Connector/PS_MIO_501_USB0_D1: U2.D15 (PS_MIO33_501); also elsewhere on the board
/USB Connector/PS_MIO_501_USB0_D2: U2.A12 (PS_MIO34_501); also elsewhere on the board
/USB Connector/PS_MIO_501_USB0_D3: U2.F12 (PS_MIO35_501); also elsewhere on the board
/USB Connector/PS_MIO_501_USB0_D4: U2.C16 (PS_MIO28_501); also elsewhere on the board
/USB Connector/PS_MIO_501_USB0_D5: U2.A10 (PS_MIO37_501); also elsewhere on the board
/USB Connector/PS_MIO_501_USB0_D6: U2.E13 (PS_MIO38_501); also elsewhere on the board
/USB Connector/PS_MIO_501_USB0_D7: U2.C18 (PS_MIO39_501); also elsewhere on the board
/ZYNQ PS Part/PS Config/PS_CLK: U2.E7 (PS_CLK_500), X2.3 (OUT)
/ZYNQ PS Part/PS Config/PS_MIO4_BOOT1: R50.1, R51.2, U2.B7 (PS_MIO4_500)
/ZYNQ PS Part/PS Config/PS_MIO6_BOOT_MODE: R52.2, U2.A5 (PS_MIO6_500)
/ZYNQ PS Part/PS Config/PS_MIO40_501_SD_CLK: U2.D14 (PS_MIO40_501), U13.D2 (CLKA)
/ZYNQ PS Part/PS Config/PS_MIO41_501_SD_CMD: U2.C17 (PS_MIO41_501), U13.C1 (CMDA)
/ZYNQ PS Part/PS Config/PS_MIO42_501_SD_D0: U2.E12 (PS_MIO42_501), U13.D1 (DAT0A)
/ZYNQ PS Part/PS Config/PS_MIO43_501_SD_D1: U2.A9 (PS_MIO43_501), U13.E1 (DAT1A)
/ZYNQ PS Part/PS Config/PS_MIO44_501_SD_D2: U2.F13 (PS_MIO44_501), U13.A1 (DAT2A)
/ZYNQ PS Part/PS Config/PS_MIO45_501_SD_D3: U2.B15 (PS_MIO45_501), U13.B1 (DAT3A)
/ZYNQ PS Part/PS Config/SDIO_CLK: J3.5 (CLK), U13.D3 (CLKB)
/ZYNQ PS Part/PS Config/SDIO_CMD: J3.3 (CMD), U13.C4 (CMDB)
/ZYNQ PS Part/PS Config/SDIO_D0: J3.7 (DAT0), U13.D4 (DAT0B)
/ZYNQ PS Part/PS Config/SDIO_D1: J3.8 (DAT1), U13.E4 (DAT1B)
/ZYNQ PS Part/PS Config/SDIO_D2: J3.1 (DAT2), U13.A4 (DAT2B)
/ZYNQ PS Part/PS Config/SDIO_D3: J3.2 (DAT3/CD), U13.B4 (DAT3B)
GND: C38.2, C131.2, C142.2, C143.2, C144.2, C145.2, C147.2, C148.2, J3.6 (VSS), J3.9 (SHIELD), R51.1, R52.1, SW2.1, U2.B8 (PS_MIO2_500), U2.D6 (PS_MIO3_500), U13.C2 (GND), U13.C3 (GND), X2.2 (GND); also elsewhere on the board
unnamed: R69.2, U13.E3 (EN)
unnamed: R49.2, X2.1 (Tri-State)

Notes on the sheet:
MIO[6] set to 0, Hardware waits for PLL to lock user resistor pulldown, provide hard fix possibilities
MIO[7-8] set to 1.8V bank0,1 IO voltage 1.8V -> set to high
LVCMOS
MIO[2] set to GND jtag in cascade mode

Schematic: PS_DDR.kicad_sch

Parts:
C2, C10, C13, C22, C28, C29, C36: 10uF; C_0402_1005Metric
C3, C4, C5, C7, C8, C11, C14, C15, C16, C18, C19, C21, C24, C25, C26, C31, C33, C34: 0.1uF; C_0201_0603Metric
R1, R4, R5: 80Ω; R_0201_0603Metric
R2: 4.7K; R_0201_0603Metric
R3: 240Ω; R_0201_0603Metric
R31, R32, R33, R34, R35, R36: 1K; R_0201_0603Metric
U1: DDR3; BGA-96_9.0x13.0mm_Layout2x3x16_P0.8mm_NoPaste
U2: xc7z020clg400; Xilinx_CLG400_020_Delay

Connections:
/ZYNQ PS Part/PS DDR/DDR_A0: U1.N3 (A0), U2.N2 (PS_DDR_A0_502)
/ZYNQ PS Part/PS DDR/DDR_A1: U1.P7 (A1), U2.K2 (PS_DDR_A1_502)
/ZYNQ PS Part/PS DDR/DDR_A2: U1.P3 (A2), U2.M3 (PS_DDR_A2_502)
/ZYNQ PS Part/PS DDR/DDR_A3: U1.N2 (A3), U2.K3 (PS_DDR_A3_502)
/ZYNQ PS Part/PS DDR/DDR_A4: U1.P8 (A4), U2.M4 (PS_DDR_A4_502)
/ZYNQ PS Part/PS DDR/DDR_A5: U1.P2 (A5), U2.L1 (PS_DDR_A5_502)
/ZYNQ PS Part/PS DDR/DDR_A6: U1.R8 (A6), U2.L4 (PS_DDR_A6_502)
/ZYNQ PS Part/PS DDR/DDR_A7: U1.R2 (A7), U2.K4 (PS_DDR_A7_502)
/ZYNQ PS Part/PS DDR/DDR_A8: U1.T8 (A8), U2.K1 (PS_DDR_A8_502)
/ZYNQ PS Part/PS DDR/DDR_A9: U1.R3 (A9), U2.J4 (PS_DDR_A9_502)
/ZYNQ PS Part/PS DDR/DDR_A10: U1.L7 (A10/AP), U2.F5 (PS_DDR_A10_502)
/ZYNQ PS Part/PS DDR/DDR_A11: U1.R7 (A11), U2.G4 (PS_DDR_A11_502)
/ZYNQ PS Part/PS DDR/DDR_A12: U1.N7 (A12/~BC), U2.E4 (PS_DDR_A12_502)
/ZYNQ PS Part/PS DDR/DDR_A13: U1.T3 (A13), U2.D4 (PS_DDR_A13_502)
/ZYNQ PS Part/PS DDR/DDR_A14: U1.T7 (A14), U2.F4 (PS_DDR_A14_502)
/ZYNQ PS Part/PS DDR/DDR_BA0: U1.M2 (BA0), U2.L5 (PS_DDR_BA0_502)
/ZYNQ PS Part/PS DDR/DDR_BA1: U1.N8 (BA1), U2.R4 (PS_DDR_BA1_502)
/ZYNQ PS Part/PS DDR/DDR_BA2: U1.M3 (BA2), U2.J5 (PS_DDR_BA2_502)
/ZYNQ PS Part/PS DDR/DDR_CKE: U1.K9 (CKE), U2.N3 (PS_DDR_CKE_502)
/ZYNQ PS Part/PS DDR/DDR_DQ0: U1.E3 (DQ0), U2.E2 (PS_DDR_DQ8_502)
/ZYNQ PS Part/PS DDR/DDR_DQ1: U1.F7 (DQ1), U2.E3 (PS_DDR_DQ9_502)
/ZYNQ PS Part/PS DDR/DDR_DQ2: U1.F2 (DQ2), U2.H2 (PS_DDR_DQ13_502)
/ZYNQ PS Part/PS DDR/DDR_DQ3: U1.F8 (DQ3), U2.G3 (PS_DDR_DQ10_502)
/ZYNQ PS Part/PS DDR/DDR_DQ4: U1.H3 (DQ4), U2.J1 (PS_DDR_DQ15_502)
/ZYNQ PS Part/PS DDR/DDR_DQ5: U1.H8 (DQ5), U2.J3 (PS_DDR_DQ12_502)
/ZYNQ PS Part/PS DDR/DDR_DQ6: U1.G2 (DQ6), U2.H1 (PS_DDR_DQ14_502)
/ZYNQ PS Part/PS DDR/DDR_DQ7: U1.H7 (DQ7), U2.H3 (PS_DDR_DQ11_502)
/ZYNQ PS Part/PS DDR/DDR_DQ8: U1.D7 (DQ8), U2.C3 (PS_DDR_DQ0_502)
/ZYNQ PS Part/PS DDR/DDR_DQ9: U1.C3 (DQ9), U2.B3 (PS_DDR_DQ1_502)
/ZYNQ PS Part/PS DDR/DDR_DQ10: U1.C8 (DQ10), U2.E1 (PS_DDR_DQ7_502)
/ZYNQ PS Part/PS DDR/DDR_DQ11: U1.C2 (DQ11), U2.C1 (PS_DDR_DQ6_502)
/ZYNQ PS Part/PS DDR/DDR_DQ12: U1.A7 (DQ12), U2.D1 (PS_DDR_DQ5_502)
/ZYNQ PS Part/PS DDR/DDR_DQ13: U1.A2 (DQ13), U2.A4 (PS_DDR_DQ3_502)
/ZYNQ PS Part/PS DDR/DDR_DQ14: U1.B8 (DQ14), U2.D3 (PS_DDR_DQ4_502)
/ZYNQ PS Part/PS DDR/DDR_DQ15: U1.A3 (DQ15), U2.A2 (PS_DDR_DQ2_502)
/ZYNQ PS Part/PS DDR/DDR_DQM0: U1.E7 (LDM), U2.F1 (PS_DDR_DM1_502)
/ZYNQ PS Part/PS DDR/DDR_DQM1: U1.D3 (UDM), U2.A1 (PS_DDR_DM0_502)
/ZYNQ PS Part/PS DDR/DDR_DQS0+: U1.F3 (LDQS), U2.G2 (PS_DDR_DQS_P1_502)
/ZYNQ PS Part/PS DDR/DDR_DQS0-: U1.G3 (~LDQS), U2.F2 (PS_DDR_DQS_N1_502)
/ZYNQ PS Part/PS DDR/DDR_DQS1+: U1.C7 (UDQS), U2.C2 (PS_DDR_DQS_P0_502)
/ZYNQ PS Part/PS DDR/DDR_DQS1-: U1.B7 (~UDQS), U2.B2 (PS_DDR_DQS_N0_502)
/ZYNQ PS Part/PS DDR/DDR_ODT: U1.K1 (ODT), U2.N5 (PS_DDR_ODT_502)
/ZYNQ PS Part/PS DDR/DDR_VRN: R4.1, U2.G5 (PS_DDR_VRN_502)
/ZYNQ PS Part/PS DDR/DDR_VRP: R5.1, U2.H5 (PS_DDR_VRP_502)
/ZYNQ PS Part/PS DDR/DDR_nCAS: U1.K3 (~CAS), U2.P5 (PS_DDR_CAS_B_502)
/ZYNQ PS Part/PS DDR/DDR_nCS: U1.L2 (~CS), U2.N1 (PS_DDR_CS_B_502)
/ZYNQ PS Part/PS DDR/DDR_nRAS: U1.J3 (~RAS), U2.P4 (PS_DDR_RAS_B_502)
/ZYNQ PS Part/PS DDR/DDR_nWE: U1.L3 (~WE), U2.M5 (PS_DDR_WE_B_502)
/ZYNQ PS Part/PS DDR/VREF_DDR1: C33.1, C34.1, C36.1, R31.2, R32.1, U2.H6 (PS_DDR_VREF0_502), U2.P6 (PS_DDR_VREF1_502)
/ZYNQ PS Part/PS DDR/VREF_DDR2: C25.1, R33.2, R34.1, U1.M8 (VREFCA)
/ZYNQ PS Part/PS DDR/VREF_DDR3: C28.1, R35.2, R36.1, U1.H1 (VREFDQ)
DDR_CK+: R1.1, U1.J7 (CK), U2.L2 (PS_DDR_CKP_502)
DDR_CK-: R1.2, U1.K7 (~CK), U2.M2 (PS_DDR_CKN_502)
DDR_nRST: R2.1, U1.T2 (~RESET), U2.B4 (PS_DDR_DRST_B_502)
GND: C2.2, C3.2, C4.2, C5.2, C7.2, C8.2, C10.2, C11.2, C13.2, C14.2, C15.2, C16.2, C18.2, C19.2, C21.2, C22.2, C24.2, C25.2, C26.2, C28.2, C29.2, C31.2, C33.2, C34.2, C36.2, R2.2, R3.1, R5.2, R32.2, R34.2, R36.2, U1.A9 (VSS), U1.B1 (VSSQ), U1.B3 (VSS), U1.B9 (VSSQ), U1.D1 (VSSQ), U1.D8 (VSSQ), U1.E1 (VSS), U1.E2 (VSSQ), U1.E8 (VSSQ), U1.F9 (VSSQ), U1.G1 (VSSQ), U1.G8 (VSS), U1.G9 (VSSQ), U1.J2 (VSS), U1.J8 (VSS), U1.M1 (VSS), U1.M9 (VSS), U1.P1 (VSS), U1.P9 (VSS), U1.T1 (VSS), U1.T9 (VSS); also elsewhere on the board
unnamed: R3.2, U1.L8 (ZQ)
VCC_DDR: C2.1, C3.1, C4.1, C5.1, C7.1, C8.1, C10.1, C11.1, C13.1, C14.1, C15.1, C16.1, C18.1, C19.1, C21.1, C22.1, C24.1, C26.1, C29.1, C31.1, R4.2, R31.1, R33.1, R35.1, U1.A1 (VDDQ), U1.A8 (VDDQ), U1.B2 (VDD), U1.C1 (VDDQ), U1.C9 (VDDQ), U1.D2 (VDDQ), U1.D9 (VDD), U1.E9 (VDDQ), U1.F1 (VDDQ), U1.G7 (VDD), U1.H2 (VDDQ), U1.H9 (VDDQ), U1.K2 (VDD), U1.K8 (VDD), U1.N1 (VDD), U1.N9 (VDD), U1.R1 (VDD), U1.R9 (VDD), U2.A3 (VCCO_DDR_502[10]), U2.D2 (VCCO_DDR_502[10]), U2.E5 (VCCO_DDR_502[10]), U2.G1 (VCCO_DDR_502[10]), U2.H4 (VCCO_DDR_502[10]), U2.L3 (VCCO_DDR_502[10]), U2.P2 (VCCO_DDR_502[10]), U2.R5 (VCCO_DDR_502[10]), U2.U1 (VCCO_DDR_502[10]), U2.V4 (VCCO_DDR_502[10]); also elsewhere on the board

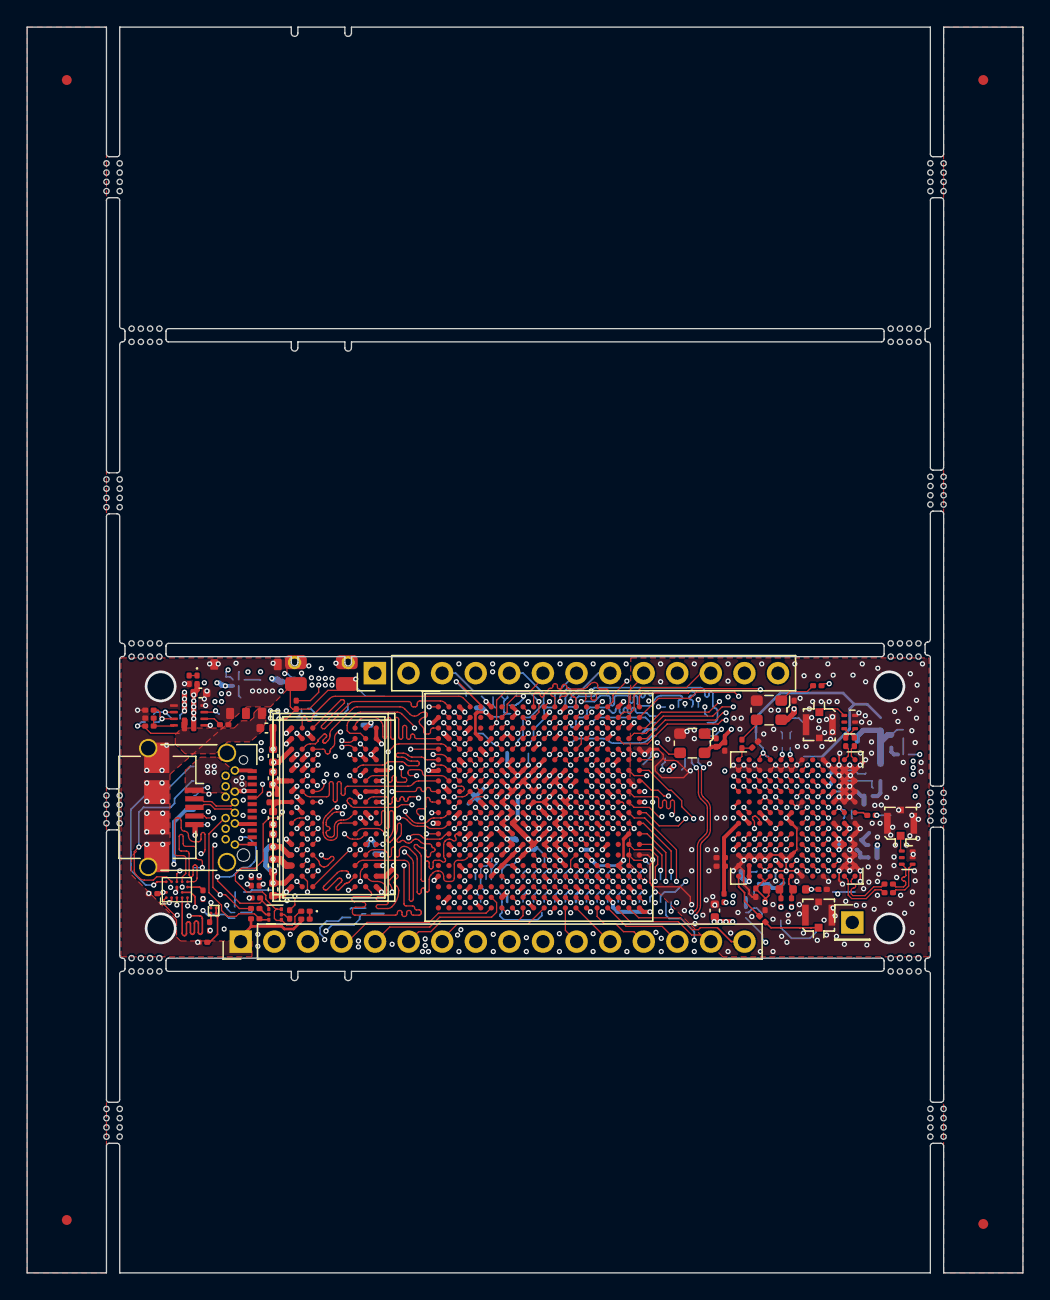
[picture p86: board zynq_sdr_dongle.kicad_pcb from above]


Board: 6 copper layers, 75.3 x 94.2 mm, 285 parts (208 on the bottom side), 328 nets.

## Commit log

2026-09-18 peripheral board
    [5024268012.stp, 5024308012.stp, 5051102491.stp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]
2026-09-23 Consolidate SIDEKICK smartphone project subsystems
    [5024268012.stp, 5024308012.stp, 5051102491.stp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]
2026-09-23 Archive project documentation and curriculum
    [Budget and Financials .xlsx]
2026-09-23 Add mainboard prototype photo and project gallery
